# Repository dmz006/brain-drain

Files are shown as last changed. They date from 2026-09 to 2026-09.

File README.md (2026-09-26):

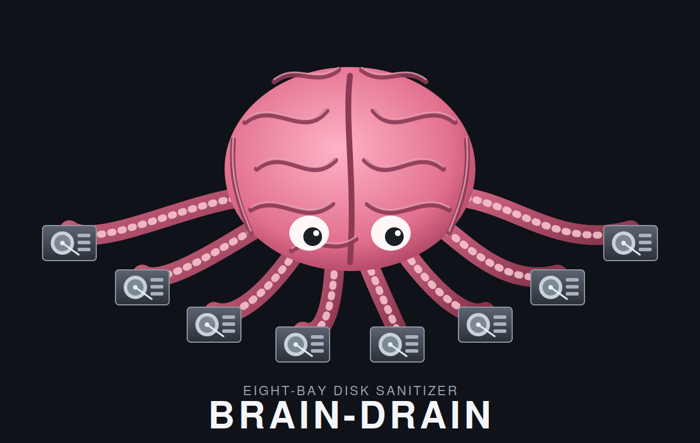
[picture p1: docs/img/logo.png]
brain-drain


# brain-drain

A standalone disk sanitizer: plug a drive in, it gets wiped to NIST SP 800-88 Rev. 2 and you get a certificate. No buttons, no
screen to poke at, no PC. A Raspberry Pi Compute Module 5 on a custom carrier board, plug-in bay cards (one per drive, up to eight, four
in version 1), an M.2 NVMe bay, a Python service and a 3D-printed enclosure that fits a backpack.

> **Status: design complete enough for layout review, nothing fabricated yet.** Both boards are routed with 0 DRC errors in KiCad, the
> software has 74 passing tests and the enclosure exports clean STLs. The boards have not been reviewed by a board designer and nothing has
> been simulated; the first bench test with a real drive is scheduled for 2026-09-26. See [docs/STATUS.md](docs/STATUS.md).
> **Handing this to an engineer? Start with [docs/LAYOUT-REVIEW.md](docs/LAYOUT-REVIEW.md).**

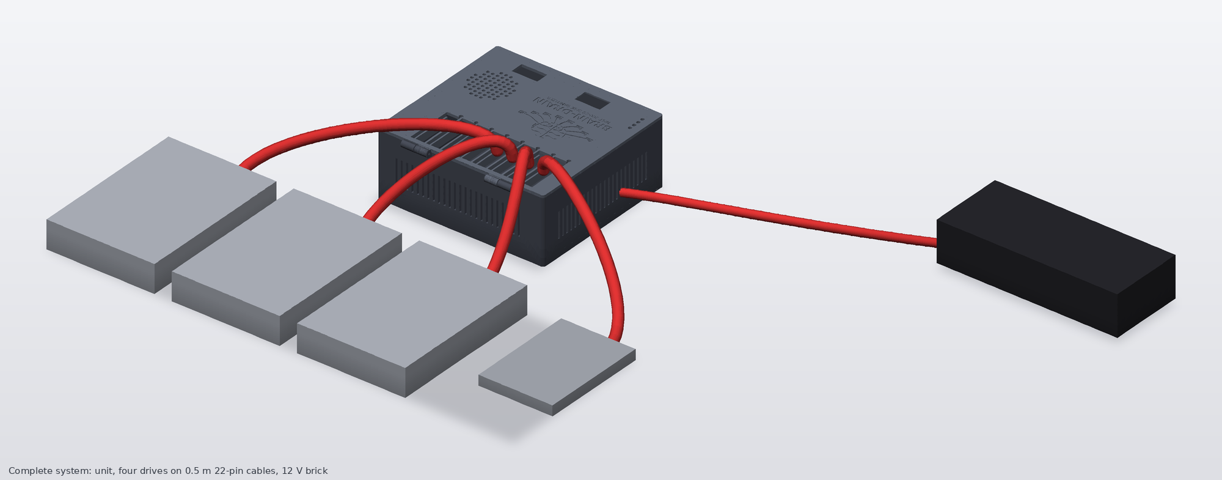
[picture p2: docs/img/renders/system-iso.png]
the complete system: the unit, four drives on 22-pin cables and the 12 V brick

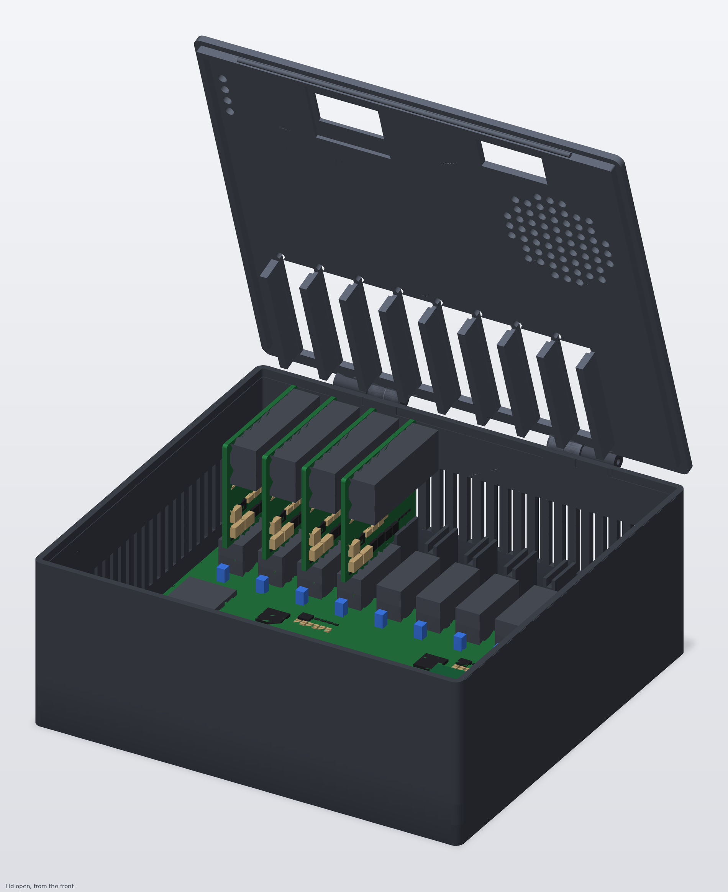
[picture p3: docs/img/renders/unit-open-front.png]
lid open: the brain board with four bay cards standing in their slots
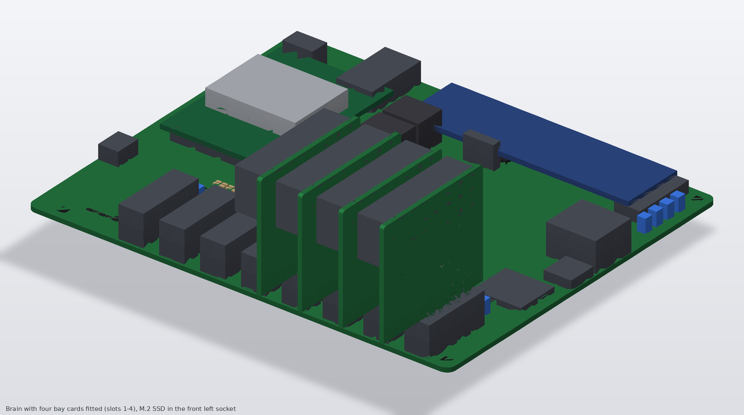
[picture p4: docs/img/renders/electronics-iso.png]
the assembled electronics


## What it does

* Up to eight SATA bays as plug-in cards (four fitted), each a USB 3 bridge
  with its own switched power. Drives are not docked: each bay is a 0.5 m
  22-pin SATA cable (data + power) that rises through the lid and plugs straight
  onto a bare 3.5" or 2.5" drive lying on the bench. Plus an M.2 NVMe bay under
  the lid (bay 9). Each bay is independent.
* Set the policy on an 8-way DIP switch. Plug a drive in: it is identified,
  wiped, verified and reported. Unplug it: the job aborts. That is the whole UI.
* Methods follow NIST 800-88 Rev. 2: single-pass overwrite with full
  verification for magnetic drives, firmware Sanitize (crypto or block erase)
  for SSDs and NVMe, legacy 3-pass and 7-pass available for those who insist.
* A JSON certificate per drive per job: what was attempted, what worked, how it
  was verified, and which tier (Clear / Purge) is honestly claimed.
* A 128×64 OLED shows per-bay progress and ETA. When idle it shows a QR code:
  scan it with a phone to join the unit's Wi-Fi, open the address, and you get
  the status page, the certificates to download, the log, and the option to
  join the unit to your own network. A key on the screen authorises changes.
  DIP mode 110 resets Wi-Fi (or everything, with DIP 8) without a network.

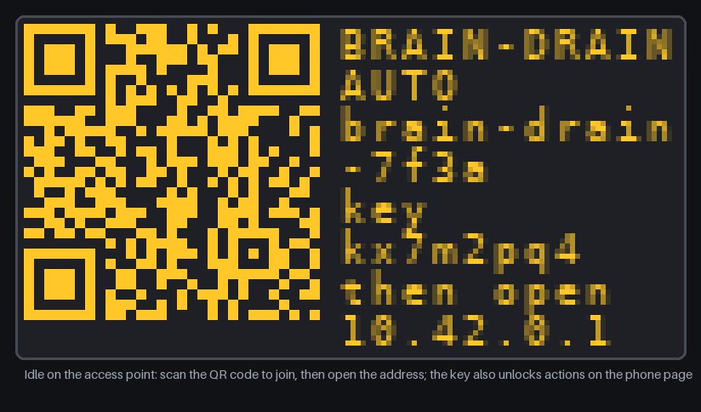
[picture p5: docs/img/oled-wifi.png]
OLED idle: Wi-Fi QR code
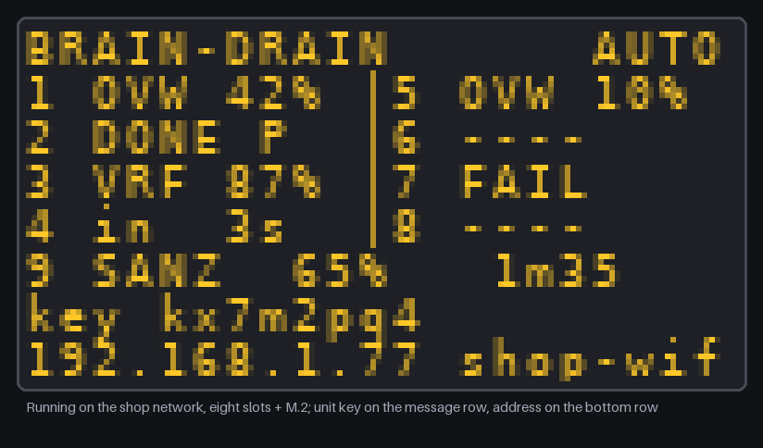
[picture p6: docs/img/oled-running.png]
OLED while running


## Use cases

* IT refresh: wiping a pile of decommissioned laptop and desktop drives
  unattended, four at a time, with paperwork for each.
* Reselling or donating hardware where a Purge-level record is wanted.
* Small MSPs and repair shops that need a repeatable wipe without dedicating a PC.

## The hardware

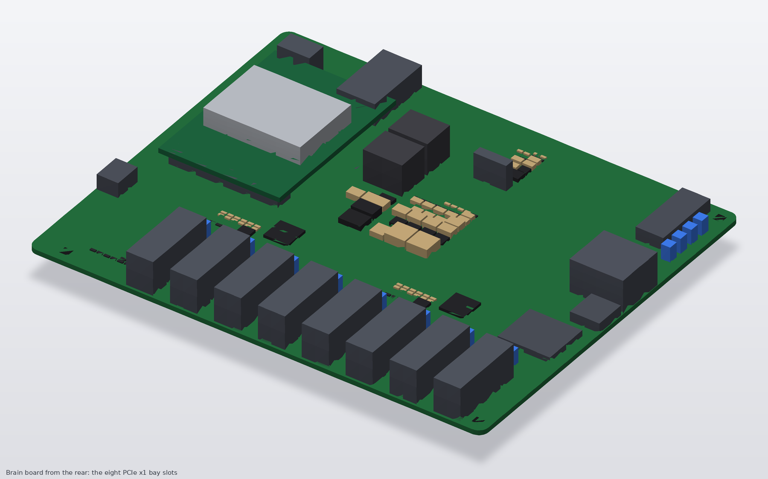
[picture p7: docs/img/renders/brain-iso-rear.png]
brain
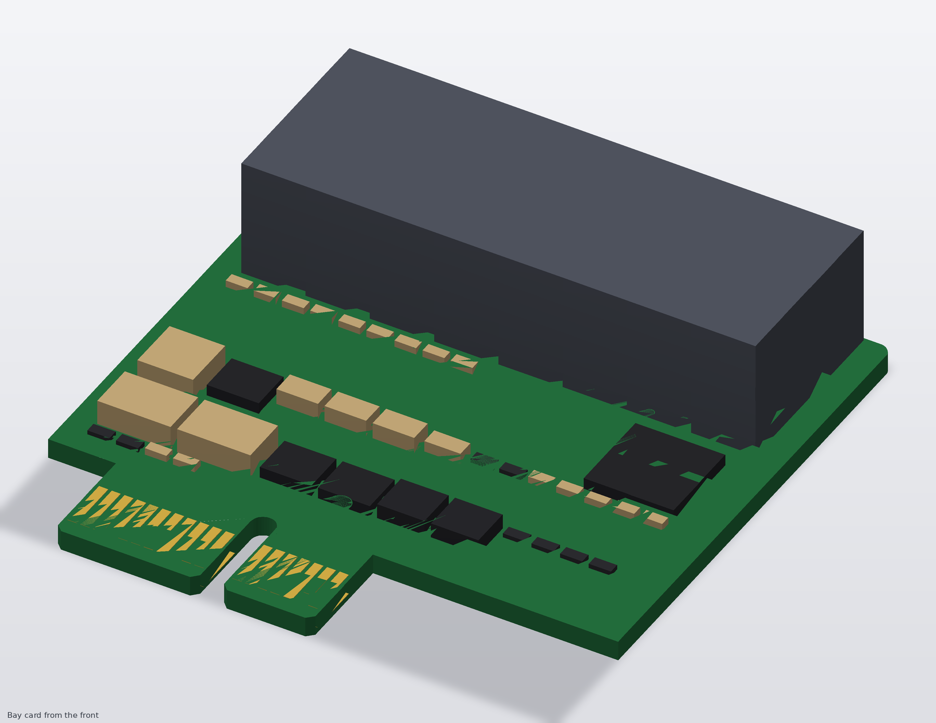
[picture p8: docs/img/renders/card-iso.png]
card
|  |  |
|---|---|
| **Brain board**, 150 x 122 mm, six layers: CM5 wireless, two USB5744 hubs, eight PCIe-x1-style bay slots, M.2 socket, 12 V input and bucks, OLED, DIP switch | **Bay card**, 45 x 46 mm, four layers: ASM1153E USB 3 to SATA bridge, per-bay 12 V / 5 V power switch, SATA receptacle, PCIe x1 fingers |

More views, the case, the assembled unit, an exploded view, a cut-away and the complete system: [docs/RENDERS.md](docs/RENDERS.md).

## Repository layout

| Directory | Workstream | State |
|---|---|---|
| [`hardware/`](hardware/README.md) | KiCad 9 projects for the brain board and the bay card, generated from one netlist source; review pack, per-layer images, BOM | schematic clean; both boards routed, 0 open connections, 0 DRC errors, all differential pairs matched; **unreviewed, unsimulated, not fabricated** |
| [`software/`](software/README.md) | `braindrain` Python service, simulator, bench tool, Wi-Fi access point + phone page, Pi deployment | 74 tests, ready for the first bench |
| [`enclosure/`](enclosure/README.md) | OpenSCAD case, about 157 x 145 x 62 mm: tray, hinged lid with eight cable windows and a snap latch, OLED bezel; render gallery script | STLs export, renders done, not printed |
| [`docs/`](docs/README.md) | architecture, review guide, BOM, decisions, status, usage, diagrams, renders | |

## Quick start

```
# simulate the appliance on any Linux box
cd software && python3 -m venv .venv && . .venv/bin/activate && pip install -e ".[dev]"
braindrain simulate --grace 2            # terminal 1
braindrain sim-plug 1 --size 1G --prefill # terminal 2: a drive appears in bay 1 and is wiped

# regenerate a board from its source and route it unattended (BD_PROJECT=brain or card; see docs/USAGE.md)
cd hardware && python3 tools/symgen.py && BD_PROJECT=card python3 tools/gen_sch.py && BD_PROJECT=card sh tools/route_full.sh

# export the enclosure and render every image
cd enclosure && make && make renders
```

More in [docs/USAGE.md](docs/USAGE.md).

## Documentation

* **For the layout engineer: [Layout and design review guide](docs/LAYOUT-REVIEW.md)** · generated review data in [`hardware/review/`](hardware/review/)
* [Architecture](docs/ARCHITECTURE.md) · [System block diagram](docs/img/system-block.png) · [Renders and drawings](docs/RENDERS.md)
* [Bill of materials](docs/BOM.md) · [Fabrication and assembly vendors, cost estimate](docs/FABRICATION.md) · [Decisions](docs/DECISIONS.md)
* [Status and remaining work](docs/STATUS.md) · [Testing tracker](docs/testing-tracker.md)
* [Usage and regeneration](docs/USAGE.md) · [Bench plan for 2026-09-26](docs/saturday-bench-plan.md)
* [BRAIN-DRAIN-CONTEXT.md](BRAIN-DRAIN-CONTEXT.md) project context · [AGENT.md](AGENT.md) rules for agents and contributors · [CONTRIBUTING](CONTRIBUTING.md) · [CHANGELOG](CHANGELOG.md)

## Safety

This device destroys data by design. The software's safety fence only ever
targets whole disks behind an allow-listed USB bridge on a configured bay port,
or the M.2 slot, and never anything mounted or holding the root filesystem.
Treat every drive that touches a bay as gone.

## Licence

[Polyform Noncommercial 1.0.0](LICENSE): you may use, modify and share this
project for noncommercial purposes. Commercial use needs permission from the
author. Applies to the hardware sources, the software and the enclosure alike.

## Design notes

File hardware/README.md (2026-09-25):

# hardware: the brain board and the bay card

Two KiCad 9 projects, both **generated** from `tools/design.py` (see [../docs/LAYOUT-REVIEW.md](../docs/LAYOUT-REVIEW.md) for how, and for what a
layout engineer must check). Design intent: [../docs/ARCHITECTURE.md](../docs/ARCHITECTURE.md) section 3. Parts: [../docs/BOM.md](../docs/BOM.md).
Regenerate and route commands: [../docs/USAGE.md](../docs/USAGE.md).

| | Brain board | Bay card |
|---|---|---|
| Project | `brain-drain.kicad_pro` | `bay-card/bay-card.kicad_pro` |
| Size, layers | 150 x 122 mm, 6 layers (F sig, In1 GND, In2 sig, In3 sig, In4 power, B sig), 1.6 mm, ENIG | 45 x 46 mm, 4 layers (F sig, In1 GND, In2 power, B sig), 1.6 mm, ENIG, finger tab |
| Contents | CM5 wireless, two USB5744 hubs, eight PCIe x1 bay slots, M.2 socket, 12 V input and bucks, OLED and DIP headers, LEDs, microSD, USB-C | ASM1153E bridge, two P-FET power switches with PTC fuses, SATA 22-pin receptacle, PCIe x1 fingers |
| Schematic sheets | `power-input`, `power-bucks`, `cm5`, `usb3-hub-A`, `usb3-hub-B`, `bay-slots`, `m2-nvme` | `bridge`, `bay-switch`, `edge` |
| Status | routed: 0 open connections, 0 DRC errors, 44 pairs matched | routed: 0 open connections, 0 DRC errors, 8 pairs matched |

brain
card

More views and the assembled unit: [../docs/RENDERS.md](../docs/RENDERS.md). KiCad's own 3D views are in `renders/`, one image per layer in
`renders/layers/` (F.Cu, In1 to In4, B.Cu, assembly-top, assembly-bottom, mask), schematic sheets in `renders/schematic/`.

## Layout of this directory

```
hardware/
  brain-drain.kicad_pro / .kicad_sch / .kicad_pcb   the brain (generated; the PCB also carries the routing)
  sheets/*.kicad_sch                                7 brain sheets (generated)
  bay-card/                                         the bay card project, same layout: .kicad_pro/.sch/.pcb, sheets/, routing/, renders/
  CONNECTIONS.md, bay-card/CONNECTIONS.md           net-by-net connection lists (generated)
  lib/brain-drain.kicad_sym, lib/brain-drain.pretty custom symbols and footprints (see lib/brain-drain.pretty/README.md for origins)
  review/                                           generated review pack: design rules, stack-up, planes, keep-outs, routing statistics,
                                                    DRC / ERC summaries, footprint provenance, netlists, placement CSV, schematic PDFs
  routing/, bay-card/routing/                       Specctra DSN/SES for freerouting, drc.json, open.md, pairs.md, chain.log
  renders/, bay-card/renders/                       KiCad 3D views, per-layer PNGs, schematic PNGs and PDFs
  bom/                                              brain-drain-bom.csv, bay-card-bom.csv (generated)
  ref/                                              pin tables (CSV), DOWNLOADS.md; ref/datasheets/ is gitignored
  tools/                                            the generators and the routing pipeline, listed in ../docs/LAYOUT-REVIEW.md section 6
  fab/                                              fab/<date>/ order packs (gitignored)
```

## Board rules

* Design rules follow the Raspberry Pi CM5IO reference: 0.13 mm tracks, 0.125 mm clearance, 0.45/0.2 mm vias, 0.3 mm copper to the board edge,
  0.2 mm hole clearance; power nets 0.3 mm tracks with 0.6/0.3 mm vias; 0.3/0.15 mm vias for the 0.4 mm-pitch QFN supply pins only (D8, confirm
  with the fab). They are written into each project file by `route.py prepare`; the table is in `review/design-rules.md`.
* Differential pairs: 90 ohm (USB 3, SATA, USB 2), 85 ohm (PCIe). The class `DiffPair90` is 0.147 mm / 0.253 mm gap, **carried over from a four-layer
  design and not yet recalculated for the six-layer stack-up**. Pairs are length-matched end to end (across the series capacitors) to 0.15 mm.
* CM5 antenna strip: no copper on any layer and no parts (rule area `keepout_CM5_antenna`); keep-outs around the CM5's four standoff holes.
* CM5 boot-order straps: eMMC/SD only. All bay power switches default **off** (10 k pull-down on `BAY_EN`, on the card).
* Input: 4-pin DIN (Kycon KPJX-4S-S); the pin assignment must match the chosen brick.

## Before fabrication

See [../docs/LAYOUT-REVIEW.md](../docs/LAYOUT-REVIEW.md) (priority items and the sign-off checklist) and [../docs/STATUS.md](../docs/STATUS.md) R2, R3, R10, R25 to R30:
the stack-up and pair geometry, the M.2 footprint against the TE drawing, the Molex face position, the DIN pinout from the chosen brick, test points, fiducials
and ESD, the card panel.

## Bench validation that does not need these boards

Any Linux box plus an ASM1153E-based USB dock answers the risky questions: does `hdparm --sanitize-*` pass through, does the bridge survive a long SECURITY ERASE,
does `--sanitize-status` report progress. A Pi 5 with two docks is the exact software test bed for this topology. Do this first
([../docs/saturday-bench-plan.md](../docs/saturday-bench-plan.md)).

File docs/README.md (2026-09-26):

# brain-drain documentation

| Document | What it is for |
|---|---|
| [../BRAIN-DRAIN-CONTEXT.md](../BRAIN-DRAIN-CONTEXT.md) | Project context: what it is, the design as built, repository map, generator commands, conventions. |
| [LAYOUT-REVIEW.md](LAYOUT-REVIEW.md) | **For the board layout engineer:** what was delivered, how it was made, what is verified, the risks in priority order, a sign-off checklist. |
| [ARCHITECTURE.md](ARCHITECTURE.md) | The design: hardware, software, enclosure, cross-cutting rules. Source of truth for intent. |
| [STATUS.md](STATUS.md) | What is done, what is placeholder, what is blocked, what comes next. |
| [USAGE.md](USAGE.md) | How to run the simulator, the bench tool, the Pi service, and how to regenerate hardware and enclosure files. |
| [BOM.md](BOM.md) | Generated parts list of both boards with vendor part numbers and prices; CSV copies in `hardware/bom/`. |
| [RENDERS.md](RENDERS.md) | Every render: boards one by one, the assembled electronics, the case, the unit open, exploded, cut-away, the complete system. |
| [FABRICATION.md](FABRICATION.md) | Who can fabricate and fully assemble a small run, what it costs, and the gates before ordering. |
| [DECISIONS.md](DECISIONS.md) | Every decision, open (`D<n>`) or closed (`C<n>`), with reasons. |
| [decisions/](decisions/) | The longer briefs behind the bigger decisions. |
| [testing-tracker.md](testing-tracker.md) | Tested vs validated, per interface and part. |
| [saturday-bench-plan.md](saturday-bench-plan.md) | Step-by-step plan for the first real-drive bench, 2026-09-26. |
| [plans/](plans/) | Multi-session work plans (none yet). |
| [HISTORY.md](HISTORY.md) | Session log: how the repository got here. |
| [img/](img/) | Diagrams and mockups; regenerate with `software/.venv/bin/python docs/tools/diagrams.py` and `software/tools/oled_mockup.py`. |

## Diagrams

| | |
|---|---|
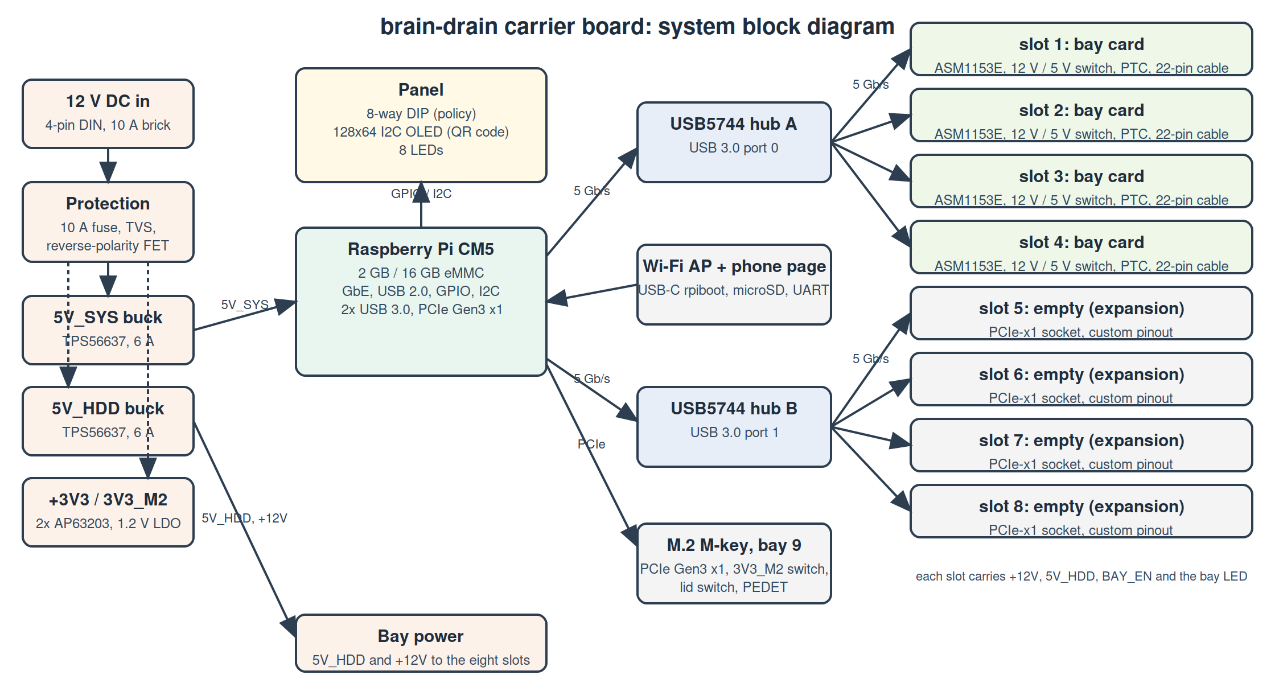
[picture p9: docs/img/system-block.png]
system
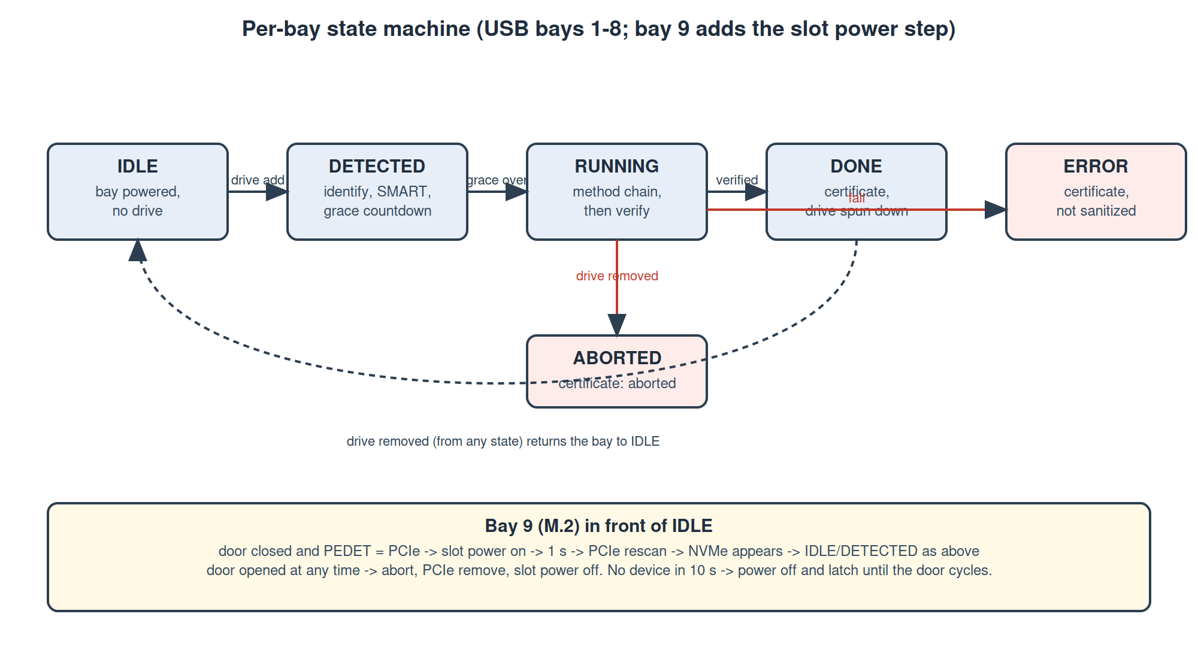
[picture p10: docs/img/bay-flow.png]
bay flow
|  |  |
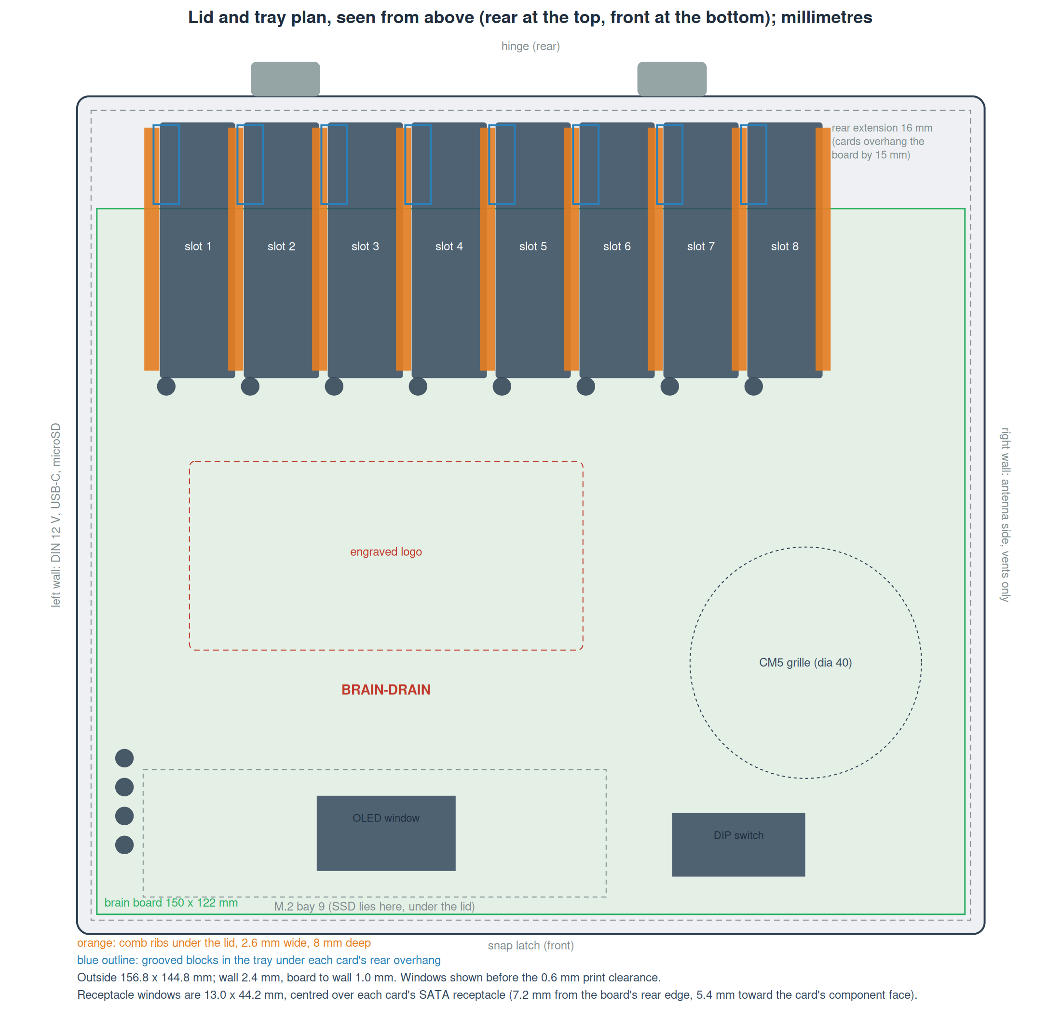
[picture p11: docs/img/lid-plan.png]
lid plan
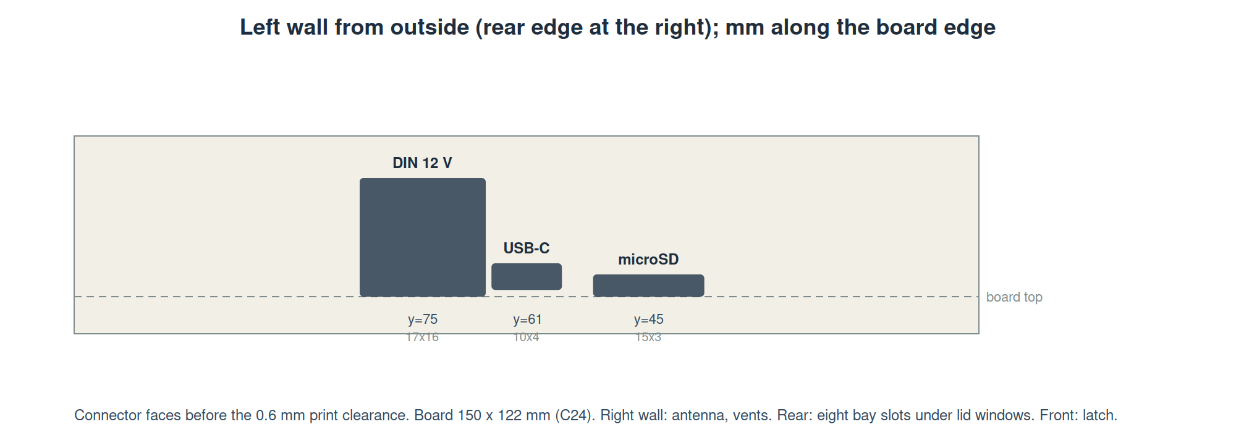
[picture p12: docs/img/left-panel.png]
left panel
|  |  |
| oled wifi | oled |

Renders of the boards, the assembly, the case and the complete system are in [RENDERS.md](RENDERS.md) (files in `img/renders/`); KiCad views and
per-layer images in `../hardware/renders/`; generated review data in `../hardware/review/`.

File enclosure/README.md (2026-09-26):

# enclosure: parametric OpenSCAD "brain box"

The unit is a printed box, about 157 x 145 x 62 mm outside, that goes in a backpack with its 12 V brick and the 22-pin cables; drives lie loose on
the bench while they are wiped (decisions C21 to C27). The 45 x 46 mm bay cards stand 49 mm above the board and overhang its rear edge by 15 mm, so the
tray is 16 mm deeper behind the board than the board itself. The lid is hinged along the rear edge and snaps shut at the front: open it to fit an M.2 SSD or
a card. The printed parts are sized from the real board.

| Lid open, from the front | Complete system |
|---|---|
| lid open | system |

More views (tray, lid, closed unit, exploded, cut-away): [../docs/RENDERS.md](../docs/RENDERS.md). Plan drawing with dimensions: [../docs/img/lid-plan.png](../docs/img/lid-plan.png).

| Face | What is on it |
|---|---|
| rear | vent slots; the lid hinge knuckles |
| left (seen from the front) | DIN 12 V jack, USB-C (rpiboot), microSD |
| right | the CM5 antenna edge: vent slots only, no metal |
| front | the lid latch |
| lid | eight 11.8 x 43 mm windows over the bay cards' SATA receptacles (the drive cables rise through them), OLED window over the SSD, DIP switch slot, 12 LED holes, convection grille over the passive CM5 cooler |
| floor | rubber-feet pockets |

* `board.scad` is **generated** from `hardware/brain-drain.kicad_pcb` by `tools/kicad_to_scad.py`: the board outline, the mounting holes and the centre of every
  connector, switch and LED the shell must cut. **Its x coordinates are mirrored** (measured from the board's right edge): KiCad's top view is left-handed and OpenSCAD is
  right-handed, so a board seen from the front with x to the right sits in the tray with x measured from the tray's x = max wall. The bay windows are placed over the
  cards' receptacles (5.4 mm toward the card's component face, 7.2 mm from the board's rear edge), not over the sockets. Re-run it whenever the board changes.
* `params.scad` holds the printed-part parameters: walls, clearances, heights, `rear_ext` (the 16 mm extension), insert sizes, OLED window position, hinge and latch sizes.
* Bay-card retention and artwork (C30): `comb()` and `card_supports()` in `shell.scad` (parameters `comb_*`, `support_*` in `params.scad`), `logo.scad` (generated by `tools/gen_logo.py` from `docs/img/logo.svg`), `tools/check_fit.py` (clearances against the placed cards).
* `refinements.scad`: OLED bezel, feet pockets. `scene.scad`: the closed unit, four loose drives and cables (the renderers compose the rest in Python).
* `shell.scad`: the tray (board on M2.5 heat-set standoffs, cutouts on the left and right walls, vents, hinge knuckles, latch groove) and the lid (front and side skirt,
  hinge knuckles, latch bump, the windows and holes).
* `tools/gallery.py` renders every image; `tools/render3d.py` is the headless renderer (numpy + Pillow); `hardware/tools/board_model.py` builds the 3D proxy of the boards.

```
make            # board.scad + stl/tray.stl, lid.stl, bezel.stl  (needs openscad)
make renders    # scene STLs, then docs/img/renders/*.png via tools/gallery.py (needs pcbnew, numpy, Pillow; no display)
```

Print PETG or ASA, 0.2 mm layers. The tray prints as modelled; the lid prints
upside down. The hinge pin is a 140 mm length of 1.75 mm filament.

Known simplifications: cutouts are rectangles sized from nominal connector
faces, so check the DIN jack round face and the SATA plug latch clearance on the
first print; the hinge knuckles and the latch bump are first guesses at fit
(0.3 mm pin clearance, 1.6 mm bump); the OLED lead from J41 to the window is
about 40 mm.

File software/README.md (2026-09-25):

# software — `braindrain` sanitizer service

Python 3.11+. Design in `../docs/ARCHITECTURE.md` §4. Status: engine, policy,
safety fence, host overwrite, verification, certificates, the bay 9 M.2 slot
controller and the simulated HAL are implemented and tested. The ATA/NVMe firmware wrappers, real GPIO and OLED
drivers are written but **untested on hardware**.

## Develop on a workstation (simulation)

```
cd software
python3 -m venv .venv && . .venv/bin/activate
pip install -e ".[dev]"
pytest

# terminal 1: the appliance, with a 2 s grace period and the OLED drawn in the terminal
braindrain simulate --grace 2

# terminal 2: plug drives in and out
braindrain sim-plug 1 --size 512M --media hdd --prefill          # host overwrite + full verify
braindrain sim-plug 3 --size 256M --media ssd --fw crypto,block  # simulated firmware sanitize + canaries
braindrain sim-plug 2 --size 2G --throttle 50M                   # slow enough to watch % and ETA
braindrain sim-unplug 2                                          # aborts bay 2
braindrain sim-plug 9 --size 256M --media nvme --fw crypto,block # NVMe in the M.2 slot (bay 9)
braindrain sim-door closed                                       # shut the M.2 door (bay 9): slot powers, rescans, wipe starts
braindrain sim-door open                                         # aborts bay 9 and cuts slot power
braindrain sim-pedet sata                                        # pretend a SATA M.2 module: refused
echo 01100000 > ~/.brain-drain-sim/dip                           # switch to legacy 3-pass (DIP 1-3 = 011)
braindrain dip 01100000                                          # decode a DIP setting
```

Certificates land in `~/.brain-drain-sim/reports/`. The last OLED frame is in
`~/.brain-drain-sim/display.txt`.

Simulated drives are sparse files under `~/.brain-drain-sim/bay<N>/`. The
engine never touches anything else: on a workstation it cannot see real disks
in simulation mode at all.

## Layout

```
braindrain/
  config.py          bay <-> USB port map, bridge allow-list, GPIO numbers, timings
  policy.py          DIP decoding, NIST tier, method chain per media type
  devices.py         Drive model, safety fence (classify), pyudev enumeration, identity
  blockio.py         O_DIRECT + aligned buffers, size/sector ioctls
  verify.py          full / sampled read-back, canaries for firmware wipes
  progress.py        EWMA rate, ETA, formatters
  report.py          certificate JSON, crash state
  engine.py          per-bay state machine and workers
  display.py         21x8 OLED frame renderer (pure)
  methods/           overwrite, ata (hdparm), nvme (nvme-cli), simfw, dryrun
  hal/               sim, gpio (libgpiod v2), oled (luma.oled)
  sim/               simulated bays + udev watcher for real hardware
  cli.py
tests/
```

## Real hardware or a bench dock

Needs `hdparm >= 9.65`, `nvme-cli`, `sg3-utils`, `smartmontools`, `util-linux`,
plus `pip install -e ".[hw]"` on the appliance (`gpiod`, `luma.oled`).

`sudo braindrain list` enumerates every disk and prints the fence verdict for
each, including the USB port path. To use a bench dock, put its port path into
`Config.bay_ports` and its bridge VID:PID into `Config.allowed_bridges`; nothing
outside those is ever a candidate. `sudo braindrain run` starts the service.

## Bench questions still open (need a dock + sacrificial drives)

* Does `hdparm --sanitize-*` pass through the dock's bridge, and does
  `--sanitize-status` report progress in the format `parse_sanitize_status` expects?
* Does the bridge survive a full `SECURITY ERASE UNIT` without resetting?
* What does the bridge do to a hot-plugged SATA drive: clean add event, or reset?

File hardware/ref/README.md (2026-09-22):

# Reference data

* `cm5-pinout.csv` — all 200 CM5 connector pins, extracted from Table 4 of the
  official Raspberry Pi Compute Module 5 datasheet
  (https://datasheets.raspberrypi.com/cm5/cm5-datasheet.pdf, September 2026 copy).
  The schematic symbol for the CM5 is generated from this file; do not hand-edit.
* `usb5744-pinout.csv` — Microchip USB5744 56-VQFN pin assignments, Table 3-1 of
  DS00001855M (public).
* `asm1153e-pinout.csv` — ASMedia ASM1153E QFN-48 pin list, section 6 of the
  Rev 0.4 datasheet. The PDF itself is vendor-confidential and is kept only in
  the gitignored `datasheets/` folder.
* `datasheets/` (gitignored) — local copies of the CM5, CM5IO, USB5744 and
  ASM1153E datasheets used for this design.
* `m2-mkey-pinout.csv` — M.2 Socket 3 / M-key host pin assignment (PCIe x4
  positions; only lane 0 is used). Signal names are from the host's point of
  view: PETp/n = host transmit, PERp/n = host receive. Pins 59–66 are the key
  notch. Source: pinoutguide.com M.2 table, cross-checked against the PCI-SIG
  M.2 naming; verify against the socket vendor's drawing before layout.

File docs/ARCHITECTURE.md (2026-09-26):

# brain-drain: architecture

Standalone, headless disk sanitizer built on a Raspberry Pi Compute Module 5. A brain board carries the compute, two USB 3
hubs, eight bay slots, an M.2 socket and the user interface; a small bay card plugs into a slot for each SATA drive (four cards
in version 1, up to eight). Set the wipe policy on a DIP switch, plug a drive into a bay and it is wiped as soon as it is
ready; the OLED shows per-bay progress; unplugging a drive aborts it; each finished drive gets a sanitization certificate.
A Wi-Fi access point with a QR code on the OLED gives a phone the status page, the certificates and the network setup.
No buttons, no menus. Wipe methods follow NIST SP 800-88 Rev. 2.

Status: **design complete enough for layout review, nothing fabricated.** Both boards are routed with 0 DRC errors in KiCad
(see [STATUS.md](STATUS.md) and [LAYOUT-REVIEW.md](LAYOUT-REVIEW.md) for the caveats). This document is the source of truth
for intent; change it before changing the hardware. The hardware sources are generated (`hardware/tools/`), never hand-edited.

system

---

## 1. Scope

| In scope | Out of scope (for v1) |
|---|---|
| Up to eight SATA HDD/SSD bays (3.5" and 2.5") on plug-in bay cards, four cards fitted | Physical destruction, degaussing |
| One M.2 NVMe bay (bay 9), PCIe Gen3 x1, under the lid | Wiping the CM5's own boot medium (explicitly forbidden) |
| NIST 800-88 Rev. 2 Clear and Purge for ATA and NVMe media | Signed / PKI certificates |
| Overwrite (host-side) and firmware Sanitize / Security Erase | Ethernet, buzzer, fan (header only), touchscreen |
| Per-drive progress and ETA on a 128 x 64 OLED | Hot-swap backplane, drive caddies, a rack |
| Wi-Fi access point, QR code, phone page with certificates and network setup | Cloud services |
| JSON certificate per drive, optional push | Drive power beyond 120 W with four cards (see 3.5) |
| Staggered spin-up, per-bay power control | |

## 2. System overview

```
   12 V brick ──DIN──► fuse, TVS, reverse-polarity FET ──┬─► U20 buck 5V_SYS ──► CM5, hubs, OLED, DIP
                                                           ├─► U21 buck 5V_HDD ──► slots (5 V per bay)
                                                           ├─► U22 buck 3V3    ──► hubs, IO, U3 (1.2 V LDO for the hubs)
                                                           ├─► U51 buck 3V3_M2 ─► U50 switch ─► M.2 socket
                                                           └─► +12V ────────────► slots (12 V per bay)

   Raspberry Pi CM5 (wireless, 2 GB / 16 GB eMMC)
      ├── USB 3.0 port 0 ──► U1 USB5744 hub A ── 4 downstream ports ──► slots 1-4 ┐
      ├── USB 3.0 port 1 ──► U2 USB5744 hub B ── 4 downstream ports ──► slots 5-8 ┤  per slot (PCIe x1-style socket,
      ├── PCIe Gen3 x1 ───► J50 M.2 M-key socket (bay 9, SSD lies under the lid)   │   custom pinout): USB 3 + USB 2 pairs,
      ├── GPIO BAY_EN 1-8 ─► slot pin B5 ─► bay-card power switch                  │   12 V, 5 V, GND, BAY_EN, LED_K
      ├── GPIO DIP x8, status LED, M2_DOOR, M2_PWR_EN                              ┘
      ├── I2C1 ──► OLED (SSD1306 / SH1106), Wi-Fi AP + phone page (nmcli, QR on the OLED)
      └── USB 2.0 ──► USB-C (rpiboot, spare host), microSD (CM5 Lite boot)

   Bay card (one per drive):  slot fingers ─► ASM1153E USB 3 to SATA bridge ─► SATA 22-pin receptacle ─► 0.5 m cable ─► drive
                              slot 12 V / 5 V ─► two P-FET switches + PTC fuses, enabled by BAY_EN ─► receptacle power pins
```

The brain board (six layers, 150 x 122 mm) and the bay cards (four layers, 45 x 46 mm) sit in a printed box about
157 x 145 x 62 mm. The box, its 12 V brick and the 22-pin cables travel in a backpack; the drives lie loose on the bench and
connect with off-the-shelf 0.5 m SATA extension cables that rise through windows in the lid. There is no rack, dock or chassis.

electronics

## 3. Workstream 1: the boards (KiCad)

### 3.1 Compute: Raspberry Pi Compute Module 5

* **Variant:** CM5 with wireless, 2 GB RAM, 16 GB eMMC (SKU CM5102016; the schematic's value field still reads CM5002016 and is
  corrected at the next regeneration, confirm the SKU when ordering). The service needs well under 1 GB.
* **Lite works on the same board.** A microSD socket is wired to the CM5's SD pins; Lite variants boot from it, eMMC variants
  ignore it. The boot order is pinned to eMMC / SD only, never USB or NVMe, so a drive in a bay can never become the boot medium.
* **Connectors:** 2 x Hirose DF40C-100DS-0.4V(51), 0.4 mm pitch, on the brain's right edge. The wireless module's PCB antenna is
  on the short edge that carries mounting hole MH1; that edge sits on the board's right edge with an 8 mm copper-free strip on
  every layer and no metal within 10 mm (CM5 datasheet 4.1.2). The rule area `keepout_CM5_antenna` enforces it.
* **Interfaces used:** two native USB 3.0 ports (from RP1) for the hubs, USB 2.0 to the USB-C port, PCIe Gen3 x1 to the M.2 socket,
  I2C1, UART0 (debug header), 20 GPIO, SD, the on-module RTC (CR2032 holder on the battery pin). Ethernet and HDMI are not used.
* **Thermal:** a passive CM5 cooler under a convection grille in the lid; a 4-pin fan header is kept for a summer bench (C23).
* **nRPIBOOT** jumper (J6) and a UART header (J7) sit on the bottom side under the CM5.

### 3.2 USB topology (decision D1, closed; C11, C24)

One Microchip **USB5744** hub per native USB 3.0 port. Each hub has four downstream ports and all four are used:
hub A (U1) feeds slots 1-4, hub B (U2) slots 5-8. Each USB5744 has its own 25 MHz crystal and needs 3.3 V plus an external 1.2 V
core rail (one AP2112K-1.2 LDO, U3, serves both). Port power enables and overcurrent pins are unused: bay power is switched on the
drive rails, on the card. Configuration is by strap pins, no SPI ROM.

| Link | Practical rate | Shared by |
|---|---|---|
| CM5 USB 3.0 port to hub | about 400 MB/s | up to four bays |
| Hub port to bridge (ASM1153E on the card) | about 400 MB/s | one bay |
| ASM1153E to drive (SATA III) | about 550 MB/s | one bay |
| A 3.5" HDD | 100-200 MB/s, about 150 average | |

Four drives on **one** hub share about 400 MB/s, roughly 100 MB/s each, below a modern HDD's speed. **Populate slots 1, 2, 5 and 6**
instead of 1-4 to give each pair of drives its own 5 Gb/s link; the software identifies a bay by its USB port path (`config.py`),
so nothing else changes. With eight bays busy every drive sees about 100 MB/s.

### 3.3 The bay card (C24, C27)

One 45 x 46 mm four-layer board per bay, one design for every slot:

* **ASM1153E** (ASMedia, QFN-48) USB 3.0 to SATA 6G bridge with SAT passthrough, which makes SANITIZE / SECURITY ERASE possible over USB.
  30 MHz crystal (default strap, no strap resistors), 4.7 uH core inductor, SATA AC-coupling caps. ASM1153E runs from 5 V alone.
* **Power switch:** two AON7403 P-MOSFETs (12 V and 5 V, -30 V, DFN 3x3) driven through 2N7002s from `BAY_EN`, with a gate RC for
  about 1 ms of soft start and 100 k pull-ups that keep the bay off; a 10 k pull-down on `BAY_EN` keeps an empty or half-inserted
  slot off. PTC fuses: 3 A hold on 12 V, 2 A hold on 5 V.
* **Receptacle:** Molex 47018-4001, SATA 22-pin (7 data + 15 power) host receptacle, top-mount PCB-edge type, centred on the
  card's top edge; the cable leaves upward. It is 40.46 mm wide, which sets the card width. P3 (PWDIS) and P11 (staggered spin-up)
  are not connected.
* **Fingers:** KiCad's stock `BUS_PCIexpress_x1` pattern with its own tab outline and key notch, ENIG. The contacts are not PCIe:
  the pinout below is our own.
* **Bay LED** stays on the brain (in front of the slot); the bridge's LED pin sinks it through finger B6 (`LED_K`).

| Finger | Signal | Finger | Signal |
|---|---|---|---|
| A1, A2 | +12V | B1, B2, B3 | +12V |
| A3, A4, A7, A10-A13, A16-A18 | GND | B4, B7, B11, B14, B17, B18 | GND |
| A5, A6 | not connected | B5 | BAY_EN (in, from the brain) |
| A8, A9 | 5V (5V_HDD) | B6 | LED_K (bridge LED output, sunk on the brain) |
| A14, A15 | USB3_TX_N, USB3_TX_P (hub to bridge) | B8, B9, B10 | 5V (5V_HDD) |
| | | B12, B13 | USB2_DM, USB2_DP |
| | | B15, B16 | USB3_RX_N, USB3_RX_P (bridge to hub) |

The pinout lives in `hardware/tools/symgen.py` (`SLOT_PINS`) and feeds both the card and the slot symbols. The connector is rated
1.1 A per contact (TE/Amphenol PCI Express specification); five contacts per rail carry 5.5 A per bay.

### 3.4 Slots, drive cables and the M.2 bay

* **Slots:** eight Amphenol FCI 10018783-10100TLF PCI Express x1 vertical through-hole sockets (36 contacts, 1.0 mm pitch, board
  locks/pegs) at 14.5 mm pitch along the brain's rear edge. The footprint follows the Amphenol customer drawing 10018784: four rows
  of 0.70 mm holes at 2.0 mm pitch, pegs at 11.65 and 20.80 mm. The cards stand vertically, plane front to back, with the receptacle
  facing the next slot; the 45 mm card overhangs the board's rear edge by 15 mm (C27), which keeps the bay LEDs in front of the slots visible.
* **Drive cables:** off-the-shelf 22-pin male-to-female SATA extensions, 0.5 m; the drive end plugs straight onto a bare drive.
  The cable rises through a window in the lid over each receptacle.
* **M.2 (bay 9, C15):** TE 2199230-4 M-key socket at the front left, PCIe Gen3 x1 from the CM5 (REFCLK pair, PERST#, CLKREQ#),
  3V3_M2 from a dedicated AP63203 buck (U51) through a TPS22965 load switch (U50) enabled by GPIO. The module lies under the lid
  along the front; the lid hinge with a microswitch (SW3) is the "door": closing it powers the slot and rescans the PCIe bus.
  M.2 SATA (B+M key) modules are refused. USB-NVMe bridges present as SCSI and fall back to SCSI SANITIZE or overwrite.

### 3.5 Power tree and budget

Input: **12 V DC**, one rail; everything else is derived on the brain. Input connector J21: Kycon KPJX-4S-S 4-pin DIN, 7.5 A per
pin with two pins per polarity (barrel jacks were dropped at 5 A). The brick is chosen before layout is frozen because DIN pin
assignments differ between vendors (STATUS R3).

| Rail | Source | Loads | Notes |
|---|---|---|---|
| +12V | input after F1 (15 A slow, C31), D20 (SMBJ15A), Q20 (AO4407A reverse-polarity FET), 2 x 680 uF bulk | the slots' 12 V pins | per-bay switch on the card |
| 5V_SYS | U20 TPS56637 (6 A) | CM5 (up to 3 A), 2 hubs, OLED, DIP, U22 | keeps drive spin-up ripple off the CM5 rail |
| 5V_HDD | U21 TPS56637 (6 A) | the slots' 5 V pins | per-bay switch on the card |
| 3V3 | U22 AP63203 (2 A) | hubs, IO, U3 | |
| 1V2 | U3 AP2112K-1.2 | both hubs' core | |
| 3V3_M2 | U51 AP63203, switched by U50 | M.2 socket | slot power is off while idle |

Budget, four drives: 12 V about 3.2 A typical, 4.4 A staggered peak; 5 V drives about 2.4 A typical, 2.8 A peak; the 12 V input
is about 5.3 A typical and 7.4 A staggered peak (11.5 A if all four spun up together, which the software never does). The 120 W brick,
the DIN rating covers four bays (the input fuse is 15 A since C31, sized for eight). **Eight simultaneous drives need about 9.5 A typical and 11.7 A at a staggered peak:
a 150-180 W brick, two parallel DIN pins for 12 V and heavier bulk capacitors, and 5V_HDD at 6 A is at its limit
for eight drives.** Do not fit eight cards before those are revisited (STATUS R23).

Staggered spin-up is mandatory: the software never enables two bays within 4 s of each other.

### 3.6 Per-bay power switching

On each card, `BAY_EN` (from a CM5 GPIO, active high) turns on both P-FETs through the 2N7002 gate drivers. The gate RC gives about 1 ms
of ramp so a drive's bulk capacitors do not trip the upstream fuse; the pull-down keeps everything off during boot. Per-bay
resettable fuses catch a shorted drive. Power control also lets the software un-freeze a drive (cycle its bay) or reset a hung
bridge without disturbing the others.

### 3.7 GPIO map (BCM numbering)

| GPIO | Function | Direction | Notes |
|---|---|---|---|
| 2, 3 | I2C1 SDA / SCL | | OLED (0x3C) |
| 4 | M2_DOOR | in, pull-up | lid microswitch, closed = low |
| 5, 6, 12, 13 | BAY_EN 1-4 | out | active high, 10 k pull-down on each card |
| 7, 8, 9, 10 | BAY_EN 5-8 | out | same |
| 14, 15 | UART0 TX / RX | | debug header J7 |
| 16, 17, 20, 21, 22, 23, 24, 25 | DIP 1-8 | in, pull-up | ON = low |
| 26 | STATUS_LED | out | red status LED |
| 27 | M2_PWR_EN | out | 3V3_M2 load switch enable, 10 k pull-down |
| 18 | free | | buzzer removed (C23) |
| 0, 1 | reserved | | ID EEPROM per Pi convention, not populated |

Bay activity LEDs are driven by each bridge's LED pin through the slot, not by GPIO.

### 3.8 User interface

* **OLED:** 128 x 64 I2C (SSD1306 0.96" or SH1106 1.3") on a 4-pin header (J41), in a recess in the lid. Idle it shows the Wi-Fi QR
  code, the key and the address; running, one row per bay in two columns when more than five bays are configured.
* **DIP switch:** 8-way, through-hole, reachable through a lid slot. Semantics in 4.5. The only control on the unit.
* **LEDs:** power (green), activity (green), status (red), eight bay LEDs (blue), M.2 (blue), all 3 mm through-hole standing in 3.2 mm lid holes.

### 3.9 Other on-board

* **RTC:** the CM5's on-module RTC with a CR2032 holder (BT1) on the CM5 battery pin, so certificates carry trustworthy times off-network.
* **Fan header** (J40): 4-pin 5 V PWM, optional.
* **microSD** (J3), **USB-C** (J5, USB 2.0 only: rpiboot and a spare host port).
* **Test points:** none placed yet; the layout engineer should add them on the rails and each `BAY_EN` (see LAYOUT-REVIEW.md).

### 3.10 PCBs

Both boards come from `hardware/tools/` (netlist in `design.py`, placement in `gen_pcb.py`, routing pipeline in `route.py`), one
KiCad project each: `hardware/brain-drain.*` and `hardware/bay-card/bay-card.*`.

* **Brain, 150 x 122 mm, six layers:** F.Cu signal, In1 GND plane, In2 and In3 signal, In4 power islands (5V_SYS, 5V_HDD, +12V, +3V3),
  B.Cu signal with a GND pour; 1.6 mm, ENIG. Eight slots along the rear edge with their bay LEDs in front; the two hubs behind their
  slots; the CM5 in landscape on the right edge with its antenna out; DIN, USB-C and microSD on the left wall; bucks and input block in
  the middle; the M.2 socket front left; DIP and fan header front right; CR2032 holder and service headers on the bottom under the CM5.
  Each hub's ten bypass capacitors sit on the **bottom** side around the chip so the top layer keeps its space for pin escapes;
  the coupling caps of each differential pair are placed side by side.
* **Bay card, 45 x 46 mm, four layers:** F.Cu / GND / power / B.Cu, 1.6 mm, ENIG, receptacle on the top edge, bridge below it, the
  switch block above the finger tab.
* **Rules:** the Raspberry Pi CM5IO reference's 0.13 mm tracks, 0.125 mm clearance, 0.45/0.2 mm vias, because nothing coarser escapes
  the 0.4 mm-pitch CM5 connector; 0.3/0.15 mm vias only for the 0.4 mm QFN supply pins (D8, confirm with the fab); power nets 0.3 mm tracks
  with 0.6/0.3 vias. 90 ohm differential pairs (0.147 mm track, 0.253 mm gap, set for the four-layer stack-up) for USB 3, SATA and USB 2;
  85 ohm for the PCIe pair to the M.2. **The pair geometry must be recalculated for the fab's six-layer stack-up before ordering.**
  Pairs are length-matched end to end (across the series capacitors) to 0.15 mm.
* **Fab:** JLCPCB or PCBWay with assembly; see [FABRICATION.md](FABRICATION.md). USB5744, ASM1153E and the DF40 connectors need the
  assembler's SMT line.

brain
card

## 4. Workstream 2 — Sanitizer service (Python)

### 4.1 Stack

* Raspberry Pi OS Lite 64-bit (Bookworm or newer), Python 3.11+.
* Package `braindrain`, run by a `systemd` unit as root (raw block access).
* Python deps: `pyudev` (device events and sysfs), `gpiod` (libgpiod v2),
  `luma.oled` (SSD1306/SH1106), `smbus2`.
* System tools driven via subprocess: `hdparm` ≥ 9.65 (ATA SANITIZE/SECURITY),
  `nvme-cli`, `sg3-utils` (`sg_sanitize`, `sg_inq`, `sg_readcap`),
  `smartmontools` (`smartctl` for identity, SMART pre-check, and post-check),
  `util-linux` (`lsblk -J`, `blockdev`).

### 4.2 Package layout

```
software/braindrain/
  __init__.py
  config.py        # paths, timings, DIP semantics table
  hal/
    gpio.py        # BAY_EN, DIP, LEDs (real + simulated)
  wifi.py          # access point / station via nmcli, ephemeral key, resets
  webui.py         # the phone page (stdlib HTTP)
  qr.py            # Wi-Fi QR matrix for the OLED
    display.py     # OLED rendering (real + terminal simulator)
    bays.py        # bay ↔ USB port-path table, power sequencing
  devices.py       # enumerate candidate drives, identity, safety filter
  policy.py        # DIP bits + media type → ordered list of methods to try
  methods/
    base.py        # Method interface: supported(), run(), progress()
    overwrite.py   # host-side passes (zeros / pattern / seeded random) + verify
    ata.py         # hdparm: SANITIZE {crypto,block,overwrite}, SECURITY ERASE
    nvme.py        # nvme-cli: sanitize, format --ses
    scsi.py        # sg_sanitize for USB-NVMe / SAS oddities
  verify.py        # full read-back, sampled read-back, canary check
  report.py        # certificate JSON, write to /var/lib/brain-drain and USB stick
  progress.py      # per-bay % and ETA (EWMA throughput)
  engine.py        # state machine: IDLE → ARMED → RUNNING → DONE/ERROR
  cli.py           # `braindrain run|status|list|simulate`
software/tests/
```

### 4.3 Device enumeration and the safety fence

The single most important property of this software: **it must never touch the
boot medium or any drive that is not in a bay.** Defence in depth:

1. A drive is a candidate only if its sysfs path passes through the USB port path
   assigned to a bay in `config.py` (e.g. `usb2/2-1/2-1.3` → bay 7) **and** the
   USB bridge VID:PID is on the allow-list (ASM1153E `174c:55aa` / `174c:1153`).
2. The device's `major:minor` must not be, or be a parent of, anything mounted or
   holding the root/boot filesystem (checked via `findmnt` and `/proc/swaps`).
3. Removable-media and zero-capacity devices are ignored.
4. Every method opens the target with `O_EXCL`.
5. A dry-run DIP setting (§4.5) exercises the whole pipeline without writes.

Bays are powered at boot, staggered 4 s apart, and stay powered. A drive plugged
into a live pigtail is detected by the bridge (SATA connectors are hot-plug by
design), a block device with capacity > 0 appears behind the bay's port path,
and udev delivers an add event. Removal delivers a remove event, which aborts
any running job in that bay. There is no confirmation step beyond a short
grace countdown (default 5 s, shown on the OLED) during which pulling the drive
back out cancels cleanly.

### 4.4 Wipe methods and NIST SP 800-88 Rev. 2 mapping

Rev. 2 keeps the Clear / Purge / Destroy tiers, drops the idea that multi-pass
overwrites add anything on modern media, and pushes toward drive-native sanitize
commands (Sanitize, Crypto Erase) for Purge. Verification, full or sampled, is
part of every Clear/Purge. The table below is the intended mapping; it must be
checked line by line against the published Rev. 2 text before the first release.

| Media | Clear | Purge |
|---|---|---|
| Magnetic HDD (ATA) | 1 pass host overwrite, fixed pattern, **full verify** | ATA `SANITIZE OVERWRITE EXT` → fallback `SECURITY ERASE UNIT` (enhanced) → fallback host overwrite |
| SATA SSD (ATA) | 1 pass host overwrite (may miss over-provisioned blocks; flagged in report) | ATA `SANITIZE CRYPTO SCRAMBLE` (if supported) then `SANITIZE BLOCK ERASE` → fallback `SECURITY ERASE UNIT` enhanced |
| NVMe (native only) | `nvme format --ses=1` | `nvme sanitize --sanact=crypto-erase` or `block-erase` |
| Unknown / USB-NVMe / SAS | host overwrite | SCSI `SANITIZE` via `sg_sanitize` → fallback overwrite |

Method implementations:

* **Overwrite:** `O_DIRECT`, 8 MiB blocks, aligned to physical sector size; pattern
  zeros by default, seeded ChaCha20 keystream for "random" so verification can
  regenerate the stream instead of storing it. Throughput and ETA from an EWMA of
  the last 30 s. Bad sectors are logged and the pass continues; any unwritable LBA
  fails the certificate.
* **Firmware (ATA):** `hdparm --sanitize-*` then poll `--sanitize-status` for
  percentage. Frozen state → power-cycle the bay via `BAY_EN` and retry once.
  Known risk: a USB bridge may drop the device mid-Security-Erase because the
  drive stays busy longer than the SCSI timeout; the drive keeps erasing, so the
  service waits, re-enumerates, and checks security status rather than failing.
  Sanitize is preferred over Security Erase precisely because it is asynchronous
  with a status query.
* **Verify:** full read-back compare for host overwrite (default) or sampled
  (first/last 1 GiB plus 64 random 16 MiB windows) when DIP 5 is on. For firmware
  methods the "canary" check applies: before the command, write a known marker at
  eight LBAs; after, read them back and confirm the marker is gone (crypto erase
  yields noise, block erase yields zeros/FFs; both pass).
* **Legacy multi-pass:** 3-pass (0x00, 0xFF, random + verify) and 7-pass
  (DoD 5220.22-M ECE-style) kept for customers who insist. The certificate labels
  these as *exceeding* Clear, not as Purge.

### 4.5 DIP switch semantics

| DIP | ON | OFF (default) |
|---|---|---|
| 1–3 | mode index, see below | 000 = `auto` |
| 4 | overwrite pattern = seeded random | zeros |
| 5 | sampled verify | full verify |
| 6 | reserved | |
| 7 | reserved | |
| 8 | **maintenance**: SSH + serial shell, never wipe | normal |

Mode index (DIP 1–3, ON = 1): `000 auto` (HDD → Clear+verify, SSD → Purge),
`001 purge`, `010 clear`, `011 legacy-3pass`, `100 legacy-7pass`,
`101 crypto-erase-only`, `110 service (never wipes; Wi-Fi reset at boot, factory reset with DIP 8)`, `111 dry-run`.

DIP is read at boot and again each time a drive is detected, and the decoded
mode is shown on the OLED footer.

### 4.6 State machine and UX

Per bay, independently:

```
IDLE ─(drive add)─► DETECTED (identity, SMART pre-check, grace countdown)
     ─► RUNNING (one worker thread: method chain, then verify)
     ─► DONE | ERROR (LED, certificate written; drive spun down)
     ─(drive remove, from any state)─► IDLE
```

Bay 9 (the M.2 slot) adds a slot state in front of this: the slot is unpowered
until its door switch reads closed and PEDET reads PCIe; the service then
powers the slot, waits one second, rescans the PCIe bus, and the NVMe device
that appears enters the same IDLE → DETECTED → RUNNING flow as a USB bay. If
nothing enumerates within ten seconds the slot is powered off and latched until
the door is opened again. Opening the door at any point aborts the job,
detaches the PCIe device, and cuts slot power. A SATA M.2 module (PEDET low) is
refused with a message on the OLED.

A remove event while RUNNING cancels the worker and writes an `aborted`
certificate. A drive that re-enumerates in a DONE bay with the same serial
within 30 s (a bridge glitch) stays DONE rather than being wiped again. Power
loss mid-wipe leaves a `state.json` so the next boot writes `interrupted`
certificates for the drives that were running.

### 4.7 Certificate

One JSON file per drive per run, e.g.
`/var/lib/brain-drain/reports/2026-09-21T14-02-11Z_WD-WCC4E1234567.json`:
unit ID, firmware version, bay, drive model/serial/firmware/capacity, media
type detection evidence, method chain attempted and the one that succeeded,
NIST tier claimed (Clear/Purge/none), verification type and result, start/end
timestamps (RTC), throughput, SMART pre/post summary, operator DIP settings.
Also copied to any FAT-formatted USB stick present at completion and, if
configured, POSTed to an HTTP endpoint.

### 4.8 Simulation and tests

`BRAIN_DRAIN_SIM=1` swaps the HAL for fakes: bays backed by loop devices or
sparse files, DIP from a file you edit, OLED rendered to the terminal. This is
how the engine gets developed and tested on a workstation before the board
exists. `pytest` covers policy selection, safety fence, progress math, report
schema, and each method against fake `hdparm`/`nvme` subprocess outputs.

## 5. Workstream 3: enclosure

* **Tool:** OpenSCAD, everything driven from `enclosure/params.scad`. Connector positions are generated from the KiCad PCB by
  `enclosure/tools/kicad_to_scad.py` so the shell tracks the board. **The generated `board.scad` is mirrored in x** (measured from the
  board's right edge): KiCad's top view is left-handed, OpenSCAD is right-handed, so a board that is seen from the front with x to the
  right sits in the tray with x measured from the tray's x = max wall. The renders and the lid-plan diagram undo the mirror.
* **Form (C21-C27):** a box about 157 x 145 x 62 mm: a tray and a lid hinged along the rear top edge (filament pin) with a snap latch at
  the front, so it pops open for the M.2 SSD; the lid microswitch is the M.2 "door". The brain sits on M2.5 heat-set standoffs. The tray is
  16 mm deeper behind the board than the board itself because the 45 mm bay cards overhang its rear edge (C27).
  Left wall (as seen from the front): DIN 12 V, USB-C, microSD. Right wall: the CM5 antenna side, vents only, no metal. Rear and right:
  vent slots. Lid: eight 11.8 x 43 mm windows over the cards' SATA receptacles (the drive cables rise through them), OLED window with a
  recess for the module (on a 4-wire lead, over the SSD), DIP slot, twelve LED holes, convection grille over the CM5 cooler.
  Floor: feet pockets. Nothing carries the drives; they lie on the bench.
* **Height:** the socket is 11.25 mm tall and the card body stands 37.6 mm above it, so the card top edge is 48.9 mm above the board;
  `above_board` is 50 mm and the plugs pass through the lid windows.
* **Print:** PETG or ASA, 0.2 mm layers, no supports by design (lid printed upside down).
* **Card retention (C30):** the lid carries a comb of nine 2.6 mm ribs, 8 mm deep, one in every gap between neighbouring receptacle
  housings (0.4 mm clearance to the card back face and to the next housing; the straight plug path stays free), and the tray has eight
  blocks under the cards' rear overhang, each with a 2.0 mm groove 0.5 mm below the card shoulder. `enclosure/tools/check_fit.py` checks
  the gaps against the placed card models. The lid holds the cards only when closed; with the lid open a card is held by its socket.
* **Artwork (C30):** the octopus logo, `BRAIN-DRAIN` and `NIST 800-88 DISK SANITIZER` are engraved 0.6 mm into the lid's outer face
  (impression, prints on the bed face). The brain board carries the same logo as top silkscreen with the name, a tagline and
  `github.com/dmz006/brain-drain` and the board revision (`REV` in `branding.py`, also written to the KiCad title block), placed in the largest free area left of the middle (`hardware/tools/branding.py`); the card carries its name.
* **Refinements** (`refinements.scad`): an OLED bezel that clamps the module under the lid window, rubber-feet pockets.
* **Images:** `docs/img/renders/` (see [RENDERS.md](RENDERS.md)), generated by `enclosure/tools/gallery.py`.

open

## 6. Cross-cutting

* **Safety fence** (§4.3) is reviewed on every change to `devices.py` or `bays.py`.
* **Thermal:** passive CM5 cooler (C23); the workload is I/O bound. The fan
  header stays for a 5 V PWM fan under the lid grille if a summer bench shows
  throttling. ASM1153E, hubs and bucks are fine.
* **Wireless and the phone page (C22):** the CM5 wireless variant runs an
  access point (`nmcli` hotspot, 10.42.0.1/24) with SSID `brain-drain-<4 hex>`
  and an 8-character key made fresh at every boot. Idle, the OLED shows a Wi-Fi
  QR code (`WIFI:T:WPA;S:…;P:…;;`) plus the key and address; running, the key
  and address take the bottom rows. The page (`webui.py`, standard library
  HTTP on port 80) serves status, certificates (single or zip), the log tail,
  and two actions that need the key: join a network (saved to
  `/var/lib/brain-drain/wifi.json`, joined at every boot, falls back to the
  access point if it fails) and reset (Wi-Fi: forget the network and rotate the
  key; factory: also delete certificates and state). Without a network, DIP
  mode 110 at boot does the Wi-Fi reset, and 110 with DIP 8 the factory reset;
  `braindrain wifi-reset [--factory]` does the same over SSH. The key is the
  only authorisation: reading the screen is the permission.
* **Compliance record:** the certificate schema is versioned; the report states
  which 800-88 tier was achieved, and says so honestly when only overwrite was
  possible on an SSD.
* **Boot order:** the CM5 EEPROM config pins boot to eMMC/SD only. USB and NVMe
  boot are disabled so a drive in a bay can never be booted from or mistaken for
  the root device.

## 7. Open decisions

See `docs/DECISIONS.md`. Closed: CM5, USB topology, hub, bridge, input connector, LEDs, M.2 bay, brain plus bay cards (C24),
six layers (C26), card width (C27). Still open: OLED size (D5), option B with bridges in the cables (D6, parked).

## 8. Throughput expectations and build order

With four bays at native drive speed (§3.2; cards in slots 1, 2, 5 and 6), a 4 TB HDD single-pass overwrite
takes ~7.5 h and a full read-back verify another ~7.5 h, and **four such drives
in parallel take the same ~15 h**, not longer. Firmware Sanitize runs inside the
drive at a similar rate with no bus load. SATA SSDs overwrite at ~400 MB/s per
bay (the USB port limit); crypto scramble takes seconds.

1. **Software in simulation** — the engine, policy, safety fence, and methods can
   be built and tested now on any Linux box with a USB-SATA dock, and are the
   riskiest part to get right. Hardware questions (bridge SAT behaviour under
   Sanitize, USB bridge timeouts) get answered on a bench dock before the board
   is committed. A Pi 5 plus two USB-SATA docks is a near-exact software
   test bed for this topology.
2. **Carrier board schematic** — while the software matures. Layout after the
   §7 decisions.
3. **Enclosure** — last, once the board outline and connector positions are frozen.

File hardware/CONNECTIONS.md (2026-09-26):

# brain-drain brain: CM5, two USB 3 hubs, eight bay slots, M.2 bay, power, UI — connection list

Generated from `hardware/tools/design.py`; do not edit by hand. One table per sheet: every
component with its symbol, value and footprint, then every net on that sheet with the pins
it joins. Nets marked **global** continue on other sheets. Pins listed under *No connect*
get an explicit no-connect flag.

Totals: 163 components, 192 nets.

## Sheet `power-input` — 12 V DIN input, fuse, TVS, reverse-polarity FET, bulk capacitance (sized for 8 bays)

### Components

| Ref | Symbol | Value | Footprint | Note |
|---|---|---|---|---|
| C20 | `Device:C_Polarized` | 680u 25V low-ESR | `Capacitor_SMD:CP_Elec_10x10.5` |  |
| C21 | `Device:C_Polarized` | 680u 25V low-ESR | `Capacitor_SMD:CP_Elec_10x10.5` |  |
| C22 | `Device:C` | 10u 25V | `Capacitor_SMD:C_1210_3225Metric` |  |
| D20 | `Device:D_TVS` | SMBJ15A | `Diode_SMD:D_SMB` |  |
| D21 | `Device:D_Zener` | 12V 0.5W | `Diode_SMD:D_SOD-123` | clamps Vgs of Q20 |
| F1 | `Device:Fuse` | 15A slow 0453015.MR | `Fuse:Fuse_Littelfuse-NANO2-451_453` |  |
| J21 | `brain-drain:DIN4_KPJX` | KPJX-4S-S | `brain-drain:Kycon_KPJX-4S-S` |  |
| Q20 | `brain-drain:PMOS_SSSGDDDD` | AO4407A | `Package_SO:SOIC-8_3.9x4.9mm_P1.27mm` | reverse-polarity protection, body diode toward load; SO-8 power pin-out S 1-3, G 4, D 5-8 |
| R20 | `Device:R` | 100k | `Resistor_SMD:R_0603_1608Metric` |  |

### Nets

| Net | Scope | Pins on this sheet | Also on |
|---|---|---|---|
| `GND` | **global** | J21.3, J21.4, J21.5 (SHIELD), D20.1 (A1), R20.2, C20.2, C21.2, C22.2 | bay-slots, cm5, m2-nvme, power-bucks, usb3-hub-A, usb3-hub-B |
| `Q20_GATE` | local | Q20.4 (G), R20.1, D21.2 (A) |  |
| `VIN_12V_FUSED` | local | F1.2, D20.2 (A2), Q20.5 (D), Q20.6 (D), Q20.7 (D), Q20.8 (D) |  |
| `VIN_12V_RAW` | **global** | J21.1, J21.2, F1.1 |  |
| `+12V` | **global** | Q20.1 (S), Q20.2 (S), Q20.3 (S), C20.1, C21.1, C22.1, D21.1 (K) | bay-slots, m2-nvme, power-bucks |

### Notes

* J21 pins 1/2 = +12 V and 3/4 = GND is a PLACEHOLDER: wire to match the chosen 12 V/10 A brick's DIN pinout (C13).
* Q20 is a P-MOSFET used as an ideal-diode-style reverse-polarity switch: drain to the fused input, source to +12V, gate pulled to GND through R20 and clamped by D21.

## Sheet `power-bucks` — 5V_SYS and 5V_HDD (TPS56637), +3V3 and 3V3_M2 (AP63203), +1V2 LDO

### Components

| Ref | Symbol | Value | Footprint | Note |
|---|---|---|---|---|
| C30 | `Device:C` | 1u 10V | `Capacitor_SMD:C_0402_1005Metric` |  |
| C31 | `Device:C` | 10u 10V | `Capacitor_SMD:C_0805_2012Metric` |  |
| C2000 | `Device:C` | 10u 25V | `Capacitor_SMD:C_1210_3225Metric` | VIN bypass |
| C2001 | `Device:C` | 10u 25V | `Capacitor_SMD:C_1210_3225Metric` |  |
| C2002 | `Device:C` | 100n 25V | `Capacitor_SMD:C_0402_1005Metric` | BOOT |
| C2003 | `Device:C` | 22u 10V | `Capacitor_SMD:C_0805_2012Metric` |  |
| C2004 | `Device:C` | 22u 10V | `Capacitor_SMD:C_0805_2012Metric` |  |
| C2005 | `Device:C` | 22u 10V | `Capacitor_SMD:C_0805_2012Metric` |  |
| C2100 | `Device:C` | 10u 25V | `Capacitor_SMD:C_1210_3225Metric` | VIN bypass |
| C2101 | `Device:C` | 10u 25V | `Capacitor_SMD:C_1210_3225Metric` |  |
| C2102 | `Device:C` | 100n 25V | `Capacitor_SMD:C_0402_1005Metric` | BOOT |
| C2103 | `Device:C` | 22u 10V | `Capacitor_SMD:C_0805_2012Metric` |  |
| C2104 | `Device:C` | 22u 10V | `Capacitor_SMD:C_0805_2012Metric` |  |
| C2105 | `Device:C` | 22u 10V | `Capacitor_SMD:C_0805_2012Metric` |  |
| C2200 | `Device:C` | 10u 25V | `Capacitor_SMD:C_1210_3225Metric` |  |
| C2201 | `Device:C` | 100n 10V | `Capacitor_SMD:C_0402_1005Metric` | BST |
| C2202 | `Device:C` | 22u 10V | `Capacitor_SMD:C_0805_2012Metric` |  |
| C2203 | `Device:C` | 22u 10V | `Capacitor_SMD:C_0805_2012Metric` |  |
| L20 | `Device:L` | 2.2u 8A | `Inductor_SMD:L_Taiyo-Yuden_NR-60xx` |  |
| L21 | `Device:L` | 2.2u 8A | `Inductor_SMD:L_Taiyo-Yuden_NR-60xx` |  |
| L22 | `Device:L` | 4.7u 3A | `Inductor_SMD:L_Taiyo-Yuden_NR-40xx` |  |
| R2000 | `Device:R` | 73.2k | `Resistor_SMD:R_0402_1005Metric` | FB top, 1% |
| R2001 | `Device:R` | 10k | `Resistor_SMD:R_0402_1005Metric` | FB bottom, 1% |
| R2002 | `Device:R` | 100k | `Resistor_SMD:R_0402_1005Metric` | EN pull-up |
| R2003 | `Device:R` | 10k | `Resistor_SMD:R_0402_1005Metric` | PG pull-up |
| R2100 | `Device:R` | 73.2k | `Resistor_SMD:R_0402_1005Metric` | FB top, 1% |
| R2101 | `Device:R` | 10k | `Resistor_SMD:R_0402_1005Metric` | FB bottom, 1% |
| R2102 | `Device:R` | 100k | `Resistor_SMD:R_0402_1005Metric` | EN pull-up |
| R2103 | `Device:R` | 10k | `Resistor_SMD:R_0402_1005Metric` | PG pull-up |
| U3 | `Regulator_Linear:AP2112K-1.2` | AP2112K-1.2 | `Package_TO_SOT_SMD:SOT-23-5` |  |
| U20 | `brain-drain:TPS56637` | TPS56637RPAR | `brain-drain:Texas_RPA0010A_VQFN-HR-10_3x3mm` |  |
| U21 | `brain-drain:TPS56637` | TPS56637RPAR | `brain-drain:Texas_RPA0010A_VQFN-HR-10_3x3mm` |  |
| U22 | `Regulator_Switching:AP63203WU` | AP63203WU-7 | `Package_TO_SOT_SMD:TSOT-23-6` |  |

### Nets

| Net | Scope | Pins on this sheet | Also on |
|---|---|---|---|
| `GND` | **global** | C2000.2, C2001.2, U20.3 (AGND), U20.9 (PGND), R2001.2, C2003.2, C2004.2, C2005.2, C2100.2, C2101.2, U21.3 (AGND), U21.9 (PGND), R2101.2, C2103.2, C2104.2, C2105.2, U22.4 (GND), C2200.2, C2202.2, C2203.2, U3.2 (GND), C30.2, C31.2 | bay-slots, cm5, m2-nvme, power-input, usb3-hub-A, usb3-hub-B |
| `PG_5V_HDD` | local | U21.4 (PG), R2103.2 |  |
| `PG_5V_SYS` | local | U20.4 (PG), R2003.2 |  |
| `U20_BOOT` | local | U20.7 (BOOT), C2002.1 |  |
| `U20_EN` | local | U20.1 (EN), R2002.2 |  |
| `U20_FB` | local | U20.2 (FB), R2000.2, R2001.1 |  |
| `U20_SW` | local | U20.6 (SW), L20.1, C2002.2 |  |
| `U21_BOOT` | local | U21.7 (BOOT), C2102.1 |  |
| `U21_EN` | local | U21.1 (EN), R2102.2 |  |
| `U21_FB` | local | U21.2 (FB), R2100.2, R2101.1 |  |
| `U21_SW` | local | U21.6 (SW), L21.1, C2102.2 |  |
| `U22_BST` | local | U22.6 (BST), C2201.1 |  |
| `U22_SW` | local | U22.5 (SW), L22.1, C2201.2 |  |
| `+12V` | **global** | U20.8 (VIN), C2000.1, C2001.1, R2002.1, U21.8 (VIN), C2100.1, C2101.1, R2102.1, U22.3 (IN), C2200.1, U22.2 (EN) | bay-slots, m2-nvme, power-input |
| `+1V2` | **global** | U3.5 (VOUT), C31.1 | usb3-hub-A, usb3-hub-B |
| `+3V3` | **global** | L22.2, C2202.1, C2203.1, U22.1 (FB), U3.1 (VIN), U3.3 (EN), C30.1 | bay-slots, cm5, usb3-hub-A, usb3-hub-B |
| `5V_HDD` | **global** | L21.2, C2103.1, C2104.1, C2105.1, R2100.1, R2103.1 | bay-slots |
| `5V_SYS` | **global** | L20.2, C2003.1, C2004.1, C2005.1, R2000.1, R2003.1 | cm5 |

### No connect

* U20: 10 (MODE), 5 (NC)
* U21: 10 (MODE), 5 (NC)
* U3: 4 (NC)

### Notes

* TPS56637 FB: Vref 0.6 V; 73.2k/10k gives 4.99 V. MODE floating = forced CCM (quietest for the CM5 rail).
* AP63203WU is the fixed 3.3 V variant: FB ties straight to the output. EN tied to VIN (always on).

## Sheet `cm5` — Compute Module 5 (wireless): power, control, GPIO, microSD, USB-C, UART, RTC cell, fan, DIP, LEDs, OLED

### Components

| Ref | Symbol | Value | Footprint | Note |
|---|---|---|---|---|
| BT1 | `Device:Battery_Cell` | CR2032 | `Battery:BatteryHolder_Keystone_1060_1x2032` |  |
| C1 | `Device:C` | 22u 10V | `Capacitor_SMD:C_0805_2012Metric` |  |
| C2 | `Device:C` | 22u 10V | `Capacitor_SMD:C_0805_2012Metric` |  |
| C3 | `Device:C` | 10u 10V | `Capacitor_SMD:C_0805_2012Metric` |  |
| C4 | `Device:C` | 1u 10V | `Capacitor_SMD:C_0402_1005Metric` |  |
| D1 | `Device:LED` | green PWR | `LED_THT:LED_D3.0mm` |  |
| D2 | `Device:LED` | green ACT | `LED_THT:LED_D3.0mm` |  |
| D3 | `Device:LED` | red STATUS | `LED_THT:LED_D3.0mm` |  |
| J3 | `Connector:Micro_SD_Card` | microSD | `Connector_Card:microSD_HC_Hirose_DM3AT-SF-PEJM5` |  |
| J5 | `Connector:USB_C_Receptacle_USB2.0_16P` | USB-C rpiboot | `Connector_USB:USB_C_Receptacle_GCT_USB4085` |  |
| J6 | `Connector_Generic:Conn_01x02` | nRPIBOOT | `Connector_PinHeader_2.54mm:PinHeader_1x02_P2.54mm_Vertical` |  |
| J7 | `Connector_Generic:Conn_01x03` | UART0 GND/TX/RX | `Connector_PinHeader_2.54mm:PinHeader_1x03_P2.54mm_Vertical` |  |
| J40 | `Connector_Generic:Conn_01x04` | Fan GND/5V/TACH/PWM | `Connector:FanPinHeader_1x04_P2.54mm_Vertical` |  |
| J41 | `Connector_Generic:Conn_01x04` | OLED GND/VCC/SCL/SDA | `Connector_PinHeader_2.54mm:PinHeader_1x04_P2.54mm_Vertical` |  |
| M1 (unit 1,2,3,5) | `brain-drain:CM5` | CM5002016 | `brain-drain:Raspberry-Pi-5-Compute-Module` |  |
| R1 | `Device:R` | 1k | `Resistor_SMD:R_0603_1608Metric` |  |
| R2 | `Device:R` | 1k | `Resistor_SMD:R_0603_1608Metric` |  |
| R3 | `Device:R` | 1k | `Resistor_SMD:R_0603_1608Metric` |  |
| R10 | `Device:R` | 10k | `Resistor_SMD:R_0402_1005Metric` | FAN_PWM pull-up (open-drain output), as on CM5IO |
| R11 | `Device:R` | 10k | `Resistor_SMD:R_0402_1005Metric` | SD_PWR_ON pull-up |
| SW1 | `Switch:SW_DIP_x08` | DIP x8 | `Button_Switch_THT:SW_DIP_SPSTx08_Piano_10.8x21.88mm_W7.62mm_P2.54mm` |  |
| U52 | `brain-drain:TPS22965` | TPS22965DSGR | `Package_SON:Texas_DSG0008A_WSON-8-1EP_2x2mm_P0.5mm_EP0.9x1.6mm` | microSD power switch, driven by SD_PWR_ON (as CM5IO does with an RT9742) |

### Nets

| Net | Scope | Pins on this sheet | Also on |
|---|---|---|---|
| `BAY_EN1` | **global** | M1.34 (GPIO5) | bay-slots |
| `BAY_EN2` | **global** | M1.30 (GPIO6) | bay-slots |
| `BAY_EN3` | **global** | M1.31 (GPIO12) | bay-slots |
| `BAY_EN4` | **global** | M1.28 (GPIO13) | bay-slots |
| `BAY_EN5` | **global** | M1.37 (GPIO7) | bay-slots |
| `BAY_EN6` | **global** | M1.39 (GPIO8) | bay-slots |
| `BAY_EN7` | **global** | M1.40 (GPIO9) | bay-slots |
| `BAY_EN8` | **global** | M1.44 (GPIO10) | bay-slots |
| `CM5_3V3` | local | M1.84 (CM5_3.3V), M1.86 (CM5_3.3V), M1.78 (GPIO_VREF) |  |
| `D1_A` | local | R1.2, D1.2 (A) |  |
| `D2_A` | local | R2.2, D2.2 (A) |  |
| `D3_A` | local | R3.2, D3.2 (A) |  |
| `DIP1` | local | M1.29 (GPIO16), SW1.1 |  |
| `DIP2` | local | M1.50 (GPIO17), SW1.2 |  |
| `DIP3` | local | M1.27 (GPIO20), SW1.3 |  |
| `DIP4` | local | M1.25 (GPIO21), SW1.4 |  |
| `DIP5` | local | M1.46 (GPIO22), SW1.5 |  |
| `DIP6` | local | M1.47 (GPIO23), SW1.6 |  |
| `DIP7` | local | M1.45 (GPIO24), SW1.7 |  |
| `DIP8` | local | M1.41 (GPIO25), SW1.8 |  |
| `FAN_PWM` | local | M1.19 (Fan_PWM), J40.4 (Pin_4), R10.2 |  |
| `FAN_TACHO` | local | M1.16 (Fan_Tacho), J40.3 (Pin_3) |  |
| `GND` | **global** | M1.1 (GND), M1.2 (GND), M1.7 (GND), M1.8 (GND), M1.13 (GND), M1.14 (GND), M1.22 (GND), M1.23 (GND), M1.32 (GND), M1.33 (GND), M1.42 (GND), M1.43 (GND), M1.52 (GND), M1.53 (GND), M1.59 (GND), M1.60 (GND), M1.65 (GND), M1.66 (GND), M1.71 (GND), M1.74 (GND), M1.98 (GND), M1.107 (GND), M1.108 (GND), M1.113 (GND), M1.114 (GND), M1.119 (GND), M1.120 (GND), M1.125 (GND), M1.126 (GND), M1.131 (GND), M1.132 (GND), M1.137 (GND), M1.138 (GND), M1.144 (GND), M1.150 (GND), M1.155 (GND), M1.156 (GND), M1.161 (GND), M1.162 (GND), M1.167 (GND), M1.168 (GND), M1.173 (GND), M1.174 (GND), M1.179 (GND), M1.180 (GND), M1.185 (GND), M1.186 (GND), M1.191 (GND), M1.192 (GND), M1.197 (GND), M1.198 (GND), C1.2, C2.2, BT1.2 (-), J6.2 (Pin_2), J7.1 (Pin_1), J40.1 (Pin_1), D1.1 (K), SW1.16, SW1.15, SW1.14, SW1.13, SW1.12, SW1.11, SW1.10, SW1.9, J41.1 (Pin_1), J3.6 (VSS), J3.9 (SHIELD), U52.5 (GND), U52.9 (EP), C3.2, C4.2, J5.A1 (GND), J5.A12 (GND), J5.B1 (GND), J5.B12 (GND), J5.S1 (SHIELD) | bay-slots, m2-nvme, power-bucks, power-input, usb3-hub-A, usb3-hub-B |
| `I2C1_SCL` | local | M1.56 (GPIO3), J41.3 (Pin_3) |  |
| `I2C1_SDA` | local | M1.58 (GPIO2), J41.4 (Pin_4) |  |
| `LED_nACT` | local | D2.1 (K), M1.21 (LED_nACT) |  |
| `M2_DOOR` | **global** | M1.54 (GPIO4) | m2-nvme |
| `M2_PEDET` | **global** | M1.26 (GPIO19) | m2-nvme |
| `M2_PWR_EN` | **global** | M1.48 (GPIO27) | m2-nvme |
| `SD_CLK` | local | M1.57 (SD_CLK), J3.5 (CLK) |  |
| `SD_CMD` | local | M1.62 (SD_CMD), J3.3 (CMD) |  |
| `SD_DAT0` | local | M1.63 (SD_DAT0), J3.7 (DAT0) |  |
| `SD_DAT1` | local | M1.67 (SD_DAT1), J3.8 (DAT1) |  |
| `SD_DAT2` | local | M1.69 (SD_DAT2), J3.1 (DAT2) |  |
| `SD_DAT3` | local | M1.61 (SD_DAT3), J3.2 (DAT3/CD) |  |
| `SD_PWR_ON` | local | M1.75 (SD_PWR_ON), U52.3 (ON), R11.2 |  |
| `SD_VDD` | **global** | U52.8 (VOUT), U52.7 (VOUT), J3.4 (VDD), C3.1 |  |
| `STATUS_LED` | local | D3.1 (K), M1.24 (GPIO26) |  |
| `UART0_RXD` | local | M1.51 (GPIO15), J7.3 (Pin_3) |  |
| `UART0_TXD` | local | M1.55 (GPIO14), J7.2 (Pin_2) |  |
| `USB2_DM` | **global** | J5.A7 (D-), J5.B7 (D-) | m2-nvme |
| `USB2_DP` | **global** | J5.A6 (D+), J5.B6 (D+) | m2-nvme |
| `USBC_CC1` | local | J5.A5 (CC1), M1.94 (CC1) |  |
| `USBC_CC2` | local | J5.B5 (CC2), M1.96 (CC2) |  |
| `VBAT` | local | M1.76 (VBAT), BT1.1 (+) |  |
| `+3V3` | **global** | R10.1, R1.1, R2.1, R3.1, J41.2 (Pin_2), U52.1 (VIN), U52.2 (VIN), U52.4 (VBIAS), C4.1, R11.1 | bay-slots, power-bucks, usb3-hub-A, usb3-hub-B |
| `5V_SYS` | **global** | M1.77 (5V), M1.79 (5V), M1.81 (5V), M1.83 (5V), M1.85 (5V), M1.87 (5V), C1.1, C2.1, J40.2 (Pin_2) | power-bucks |
| `nRPIBOOT` | local | M1.93 (nRPIBOOT), J6.1 (Pin_1) |  |

### No connect

* J5: A4 (VBUS), A8 (SBU1), A9 (VBUS), B4 (VBUS), B8 (SBU2), B9 (VBUS)
* M1: 10 (Ethernet_Pair0_N), 100 (CAM_GPIO1), 11 (Ethernet_Pair2_P), 115 (MIPI0_D0_N), 117 (MIPI0_D0_P), 12 (Ethernet_Pair0_P), 121 (MIPI0_D1_N), 123 (MIPI0_D1_P), 127 (MIPI0_C_N), 129 (MIPI0_C_P), 133 (MIPI0_D2_N), 135 (MIPI0_D2_P), 139 (MIPI0_D3_N), 141 (MIPI0_D3_P), 143 (HDMI1_HOTPLUG), 145 (HDMI1_SDA), 146 (HDMI1_TX2_P), 147 (HDMI1_SCL), 148 (HDMI1_TX2_N), 149 (HDMI1_CEC), 15 (Ethernet_nLED3), 151 (HDMI0_CEC), 152 (HDMI1_TX1_P), 153 (HDMI0_HOTPLUG), 154 (HDMI1_TX1_N), 158 (HDMI1_TX0_P), 160 (HDMI1_TX0_N), 164 (HDMI1_CLK_P), 166 (HDMI1_CLK_N), 17 (Ethernet_nLED2), 170 (HDMI0_TX2_P), 172 (HDMI0_TX2_N), 175 (MIPI1_D0_N), 176 (HDMI0_TX1_P), 177 (MIPI1_D0_P), 178 (HDMI0_TX1_N), 18 (Ethernet_SYNC_OUT), 181 (MIPI1_D1_N), 182 (HDMI0_TX0_P), 183 (MIPI1_D1_P), 184 (HDMI0_TX0_N), 187 (MIPI1_C_N), 188 (HDMI0_CLK_P), 189 (MIPI1_C_P), 190 (HDMI0_CLK_N), 193 (MIPI1_D2_N), 194 (MIPI1_D3_N), 195 (MIPI1_D2_P), 196 (MIPI1_D3_P), 199 (HDMI0_SDA), 20 (EEPROM_nWP), 200 (HDMI0_SCL), 3 (Ethernet_Pair3_P), 35 (ID_SC), 36 (ID_SD), 38 (GPIO11), 4 (Ethernet_Pair1_P), 49 (GPIO18), 5 (Ethernet_Pair3_N), 6 (Ethernet_Pair1_N), 64 (SD_DAT5), 68 (SD_DAT4), 70 (SD_DAT7), 72 (SD_DAT6), 73 (SD_VDD_OVERRIDE), 80 (SCL0), 82 (SDA0), 88 (CM5_1.8V), 89 (WL_nDisable), 9 (Ethernet_Pair2_N), 90 (CM5_1.8V), 91 (BT_nDisable), 92 (PWR_Button), 95 (LED_nPWR), 97 (CAM_GPIO0), 99 (PMIC_Enable)
* U52: 6 (CT)

### Notes

* GPIO_VREF is tied to the CM5's own 3.3 V output (pins 84/86) for 3.3 V GPIO signalling, per datasheet §4.2.
* PMIC_Enable and PWR_Button are left floating (internal pull-ups). nRPIBOOT goes to jumper J6.
* LED_nACT is an open-drain 20 mA output on the CM5: it sinks D2 directly. GPIO26 sinks D3 (software drives it low to light).
* microSD power goes through U52 so the CM5 can power-cycle the card on reboot via SD_PWR_ON, matching the CM5IO reference (which uses an RT9742).
* Ethernet dropped (C22). The CM5 wireless variant's PCB antenna is on the short module edge that carries MH1; that edge sits on the board's left edge with an 8 mm copper-free strip under it and no metal within 10 mm (CM5 datasheet 4.1.2).
* USB-C is a device port (rpiboot / gadget). As on the CM5IO, CC1/CC2 go straight to the CM5, which presents the sink pull-downs itself; VBUS is not connected (the board is powered from 12 V). USB_OTG_ID floats = device.

## Sheet `usb3-hub-A` — USB5744 hub A on CM5 USB3-0, bay slots 1-4

### Components

| Ref | Symbol | Value | Footprint | Note |
|---|---|---|---|---|
| C100 | `Device:C` | 33p | `Capacitor_SMD:C_0402_1005Metric` |  |
| C101 | `Device:C` | 33p | `Capacitor_SMD:C_0402_1005Metric` |  |
| C110 | `Device:C` | 100n | `Capacitor_SMD:C_0402_1005Metric` | VDD33 decoupling |
| C111 | `Device:C` | 100n | `Capacitor_SMD:C_0402_1005Metric` | VDD33 decoupling |
| C112 | `Device:C` | 100n | `Capacitor_SMD:C_0402_1005Metric` | VDD33 decoupling |
| C113 | `Device:C` | 100n | `Capacitor_SMD:C_0402_1005Metric` | VDD33 decoupling |
| C120 | `Device:C` | 100n | `Capacitor_SMD:C_0402_1005Metric` | VDD12 decoupling |
| C121 | `Device:C` | 100n | `Capacitor_SMD:C_0402_1005Metric` | VDD12 decoupling |
| C122 | `Device:C` | 100n | `Capacitor_SMD:C_0402_1005Metric` | VDD12 decoupling |
| C123 | `Device:C` | 100n | `Capacitor_SMD:C_0402_1005Metric` | VDD12 decoupling |
| C130 | `Device:C` | 4.7u 10V | `Capacitor_SMD:C_0603_1608Metric` |  |
| C131 | `Device:C` | 4.7u 10V | `Capacitor_SMD:C_0603_1608Metric` |  |
| C140 | `Device:C` | 100n | `Capacitor_SMD:C_0402_1005Metric` | USB3 upstream TX AC coupling |
| C141 | `Device:C` | 100n | `Capacitor_SMD:C_0402_1005Metric` | USB3 upstream TX AC coupling |
| C151 | `Device:C` | 100n | `Capacitor_SMD:C_0402_1005Metric` | USB3 DN1 TX AC coupling |
| C152 | `Device:C` | 100n | `Capacitor_SMD:C_0402_1005Metric` | USB3 DN2 TX AC coupling |
| C153 | `Device:C` | 100n | `Capacitor_SMD:C_0402_1005Metric` | USB3 DN3 TX AC coupling |
| C154 | `Device:C` | 100n | `Capacitor_SMD:C_0402_1005Metric` | USB3 DN4 TX AC coupling |
| C161 | `Device:C` | 100n | `Capacitor_SMD:C_0402_1005Metric` | USB3 DN1 TX AC coupling |
| C162 | `Device:C` | 100n | `Capacitor_SMD:C_0402_1005Metric` | USB3 DN2 TX AC coupling |
| C163 | `Device:C` | 100n | `Capacitor_SMD:C_0402_1005Metric` | USB3 DN3 TX AC coupling |
| C164 | `Device:C` | 100n | `Capacitor_SMD:C_0402_1005Metric` | USB3 DN4 TX AC coupling |
| R100 | `Device:R` | 12.0k 1% | `Resistor_SMD:R_0402_1005Metric` | RBIAS |
| R101 | `Device:R` | 10k | `Resistor_SMD:R_0402_1005Metric` | VBUS_DET to 3.3 V |
| R102 | `Device:R` | 10k | `Resistor_SMD:R_0402_1005Metric` | RESET_N pull-up |
| R103 | `Device:R` | 200k | `Resistor_SMD:R_0402_1005Metric` | CFG_NON_REM: all ports removable |
| U1 | `brain-drain:USB5744` | USB5744/2G | `Package_DFN_QFN:QFN-56-1EP_7x7mm_P0.4mm_EP3.2x3.2mm` |  |
| Y1 | `Device:Crystal_GND24` | 25MHz CL=20pF | `Crystal:Crystal_SMD_3225-4Pin_3.2x2.5mm` |  |

### Nets

| Net | Scope | Pins on this sheet | Also on |
|---|---|---|---|
| `BAY1_USB2_DM` | **global** | U1.2 (USB2DN_DM1/PRT_DIS_M1) | bay-slots |
| `BAY1_USB2_DP` | **global** | U1.1 (USB2DN_DP1/PRT_DIS_P1) | bay-slots |
| `BAY1_USB3_RX_N` | **global** | C161.2 | bay-slots |
| `BAY1_USB3_RX_P` | **global** | C151.2 | bay-slots |
| `BAY1_USB3_TX_N` | **global** | U1.7 (USB3DN_RXDM1) | bay-slots |
| `BAY1_USB3_TX_P` | **global** | U1.6 (USB3DN_RXDP1) | bay-slots |
| `BAY2_USB2_DM` | **global** | U1.9 (USB2DN_DM2/PRT_DIS_M2) | bay-slots |
| `BAY2_USB2_DP` | **global** | U1.8 (USB2DN_DP2/PRT_DIS_P2) | bay-slots |
| `BAY2_USB3_RX_N` | **global** | C162.2 | bay-slots |
| `BAY2_USB3_RX_P` | **global** | C152.2 | bay-slots |
| `BAY2_USB3_TX_N` | **global** | U1.14 (USB3DN_RXDM2) | bay-slots |
| `BAY2_USB3_TX_P` | **global** | U1.13 (USB3DN_RXDP2) | bay-slots |
| `BAY3_USB2_DM` | **global** | U1.18 (USB2DN_DM3/PRT_DIS_M3) | bay-slots |
| `BAY3_USB2_DP` | **global** | U1.17 (USB2DN_DP3/PRT_DIS_P3) | bay-slots |
| `BAY3_USB3_RX_N` | **global** | C163.2 | bay-slots |
| `BAY3_USB3_RX_P` | **global** | C153.2 | bay-slots |
| `BAY3_USB3_TX_N` | **global** | U1.23 (USB3DN_RXDM3) | bay-slots |
| `BAY3_USB3_TX_P` | **global** | U1.22 (USB3DN_RXDP3) | bay-slots |
| `BAY4_USB2_DM` | **global** | U1.25 (USB2DN_DM4/PRT_DIS_M4) | bay-slots |
| `BAY4_USB2_DP` | **global** | U1.24 (USB2DN_DP4/PRT_DIS_P4) | bay-slots |
| `BAY4_USB3_RX_N` | **global** | C164.2 | bay-slots |
| `BAY4_USB3_RX_P` | **global** | C154.2 | bay-slots |
| `BAY4_USB3_TX_N` | **global** | U1.30 (USB3DN_RXDM4) | bay-slots |
| `BAY4_USB3_TX_P` | **global** | U1.29 (USB3DN_RXDP4) | bay-slots |
| `GND` | **global** | U1.EP (VSS), U1.52 (ATEST), R100.2, R103.2, Y1.2 (G), Y1.4 (G), C110.2, C111.2, C112.2, C113.2, C120.2, C121.2, C122.2, C123.2, C130.2, C131.2, C100.2, C101.2 | bay-slots, cm5, m2-nvme, power-bucks, power-input, usb3-hub-B |
| `U1_CFG_NON_REM` | local | U1.41 (SPI_CE_N/CFG_NON_REM), R103.1 |  |
| `U1_DN1_TXDM` | local | U1.4 (USB3DN_TXDM1), C161.1 |  |
| `U1_DN1_TXDP` | local | U1.3 (USB3DN_TXDP1), C151.1 |  |
| `U1_DN2_TXDM` | local | U1.11 (USB3DN_TXDM2), C162.1 |  |
| `U1_DN2_TXDP` | local | U1.10 (USB3DN_TXDP2), C152.1 |  |
| `U1_DN3_TXDM` | local | U1.20 (USB3DN_TXDM3), C163.1 |  |
| `U1_DN3_TXDP` | local | U1.19 (USB3DN_TXDP3), C153.1 |  |
| `U1_DN4_TXDM` | local | U1.27 (USB3DN_TXDM4), C164.1 |  |
| `U1_DN4_TXDP` | local | U1.26 (USB3DN_TXDP4), C154.1 |  |
| `U1_RBIAS` | local | U1.56 (RBIAS), R100.1 |  |
| `U1_RESET_N` | local | U1.42 (RESET_N), R102.2 |  |
| `U1_UP_TXDM` | local | U1.48 (USB3UP_TXDM), C141.1 |  |
| `U1_UP_TXDP` | local | U1.47 (USB3UP_TXDP), C140.1 |  |
| `U1_VBUS_DET` | local | U1.37 (VBUS_DET), R101.2 |  |
| `U1_XTALI` | local | U1.54 (XTALI/CLK_IN), Y1.1, C100.1 |  |
| `U1_XTALO` | local | U1.53 (XTALO), Y1.3, C101.1 |  |
| `USB3_0_DM` | **global** | U1.46 (USB2UP_DM) | m2-nvme |
| `USB3_0_DP` | **global** | U1.45 (USB2UP_DP) | m2-nvme |
| `USB3_0_RX_N` | **global** | C141.2 | m2-nvme |
| `USB3_0_RX_P` | **global** | C140.2 | m2-nvme |
| `USB3_0_TX_N` | **global** | U1.51 (USB3UP_RXDM) | m2-nvme |
| `USB3_0_TX_P` | **global** | U1.50 (USB3UP_RXDP) | m2-nvme |
| `+1V2` | **global** | U1.5 (VDD12), U1.12 (VDD12), U1.15 (VDD12), U1.21 (VDD12), U1.28 (VDD12), U1.33 (VDD12), U1.43 (VDD12), U1.49 (VDD12), C120.1, C121.1, C122.1, C123.1, C131.1 | power-bucks, usb3-hub-B |
| `+3V3` | **global** | U1.16 (VDD33), U1.31 (VDD33), U1.44 (VDD33), U1.55 (VDD33), C110.1, C111.1, C112.1, C113.1, C130.1, R101.1, R102.1 | bay-slots, cm5, power-bucks, usb3-hub-B |

### No connect

* U1: 32 (PRT_CTL4/GANG_PWR), 34 (PRT_CTL3), 35 (PRT_CTL2), 36 (PRT_CTL1), 38 (SPI_CLK/SMCLK), 39 (SPI_DO/SMDAT), 40 (SPI_DI/CFG_BC_EN)

### Notes

* Hub A: upstream on CM5 USB3-0. Downstream ports 1-4 -> bay slots 1-4 (C24: eight slots, four cards populated in v1).
* No SPI ROM and no SMBus pull-ups: the hub runs its internal ROM defaults. RESET_N has a pull-up only; add an RC if strap timing (1 ms hold) is a concern.
* Crystal: 25 MHz, CL 20 pF per datasheet table 10-10; 33 pF load caps assume ~3 pF stray, adjust to the chosen crystal.

## Sheet `usb3-hub-B` — USB5744 hub B on CM5 USB3-1, bay slots 5-8

### Components

| Ref | Symbol | Value | Footprint | Note |
|---|---|---|---|---|
| C200 | `Device:C` | 33p | `Capacitor_SMD:C_0402_1005Metric` |  |
| C201 | `Device:C` | 33p | `Capacitor_SMD:C_0402_1005Metric` |  |
| C210 | `Device:C` | 100n | `Capacitor_SMD:C_0402_1005Metric` | VDD33 decoupling |
| C211 | `Device:C` | 100n | `Capacitor_SMD:C_0402_1005Metric` | VDD33 decoupling |
| C212 | `Device:C` | 100n | `Capacitor_SMD:C_0402_1005Metric` | VDD33 decoupling |
| C213 | `Device:C` | 100n | `Capacitor_SMD:C_0402_1005Metric` | VDD33 decoupling |
| C220 | `Device:C` | 100n | `Capacitor_SMD:C_0402_1005Metric` | VDD12 decoupling |
| C221 | `Device:C` | 100n | `Capacitor_SMD:C_0402_1005Metric` | VDD12 decoupling |
| C222 | `Device:C` | 100n | `Capacitor_SMD:C_0402_1005Metric` | VDD12 decoupling |
| C223 | `Device:C` | 100n | `Capacitor_SMD:C_0402_1005Metric` | VDD12 decoupling |
| C230 | `Device:C` | 4.7u 10V | `Capacitor_SMD:C_0603_1608Metric` |  |
| C231 | `Device:C` | 4.7u 10V | `Capacitor_SMD:C_0603_1608Metric` |  |
| C240 | `Device:C` | 100n | `Capacitor_SMD:C_0402_1005Metric` | USB3 upstream TX AC coupling |
| C241 | `Device:C` | 100n | `Capacitor_SMD:C_0402_1005Metric` | USB3 upstream TX AC coupling |
| C251 | `Device:C` | 100n | `Capacitor_SMD:C_0402_1005Metric` | USB3 DN1 TX AC coupling |
| C252 | `Device:C` | 100n | `Capacitor_SMD:C_0402_1005Metric` | USB3 DN2 TX AC coupling |
| C253 | `Device:C` | 100n | `Capacitor_SMD:C_0402_1005Metric` | USB3 DN3 TX AC coupling |
| C254 | `Device:C` | 100n | `Capacitor_SMD:C_0402_1005Metric` | USB3 DN4 TX AC coupling |
| C261 | `Device:C` | 100n | `Capacitor_SMD:C_0402_1005Metric` | USB3 DN1 TX AC coupling |
| C262 | `Device:C` | 100n | `Capacitor_SMD:C_0402_1005Metric` | USB3 DN2 TX AC coupling |
| C263 | `Device:C` | 100n | `Capacitor_SMD:C_0402_1005Metric` | USB3 DN3 TX AC coupling |
| C264 | `Device:C` | 100n | `Capacitor_SMD:C_0402_1005Metric` | USB3 DN4 TX AC coupling |
| R200 | `Device:R` | 12.0k 1% | `Resistor_SMD:R_0402_1005Metric` | RBIAS |
| R201 | `Device:R` | 10k | `Resistor_SMD:R_0402_1005Metric` | VBUS_DET to 3.3 V |
| R202 | `Device:R` | 10k | `Resistor_SMD:R_0402_1005Metric` | RESET_N pull-up |
| R203 | `Device:R` | 200k | `Resistor_SMD:R_0402_1005Metric` | CFG_NON_REM: all ports removable |
| U2 | `brain-drain:USB5744` | USB5744/2G | `Package_DFN_QFN:QFN-56-1EP_7x7mm_P0.4mm_EP3.2x3.2mm` |  |
| Y2 | `Device:Crystal_GND24` | 25MHz CL=20pF | `Crystal:Crystal_SMD_3225-4Pin_3.2x2.5mm` |  |

### Nets

| Net | Scope | Pins on this sheet | Also on |
|---|---|---|---|
| `BAY5_USB2_DM` | **global** | U2.2 (USB2DN_DM1/PRT_DIS_M1) | bay-slots |
| `BAY5_USB2_DP` | **global** | U2.1 (USB2DN_DP1/PRT_DIS_P1) | bay-slots |
| `BAY5_USB3_RX_N` | **global** | C261.2 | bay-slots |
| `BAY5_USB3_RX_P` | **global** | C251.2 | bay-slots |
| `BAY5_USB3_TX_N` | **global** | U2.7 (USB3DN_RXDM1) | bay-slots |
| `BAY5_USB3_TX_P` | **global** | U2.6 (USB3DN_RXDP1) | bay-slots |
| `BAY6_USB2_DM` | **global** | U2.9 (USB2DN_DM2/PRT_DIS_M2) | bay-slots |
| `BAY6_USB2_DP` | **global** | U2.8 (USB2DN_DP2/PRT_DIS_P2) | bay-slots |
| `BAY6_USB3_RX_N` | **global** | C262.2 | bay-slots |
| `BAY6_USB3_RX_P` | **global** | C252.2 | bay-slots |
| `BAY6_USB3_TX_N` | **global** | U2.14 (USB3DN_RXDM2) | bay-slots |
| `BAY6_USB3_TX_P` | **global** | U2.13 (USB3DN_RXDP2) | bay-slots |
| `BAY7_USB2_DM` | **global** | U2.18 (USB2DN_DM3/PRT_DIS_M3) | bay-slots |
| `BAY7_USB2_DP` | **global** | U2.17 (USB2DN_DP3/PRT_DIS_P3) | bay-slots |
| `BAY7_USB3_RX_N` | **global** | C263.2 | bay-slots |
| `BAY7_USB3_RX_P` | **global** | C253.2 | bay-slots |
| `BAY7_USB3_TX_N` | **global** | U2.23 (USB3DN_RXDM3) | bay-slots |
| `BAY7_USB3_TX_P` | **global** | U2.22 (USB3DN_RXDP3) | bay-slots |
| `BAY8_USB2_DM` | **global** | U2.25 (USB2DN_DM4/PRT_DIS_M4) | bay-slots |
| `BAY8_USB2_DP` | **global** | U2.24 (USB2DN_DP4/PRT_DIS_P4) | bay-slots |
| `BAY8_USB3_RX_N` | **global** | C264.2 | bay-slots |
| `BAY8_USB3_RX_P` | **global** | C254.2 | bay-slots |
| `BAY8_USB3_TX_N` | **global** | U2.30 (USB3DN_RXDM4) | bay-slots |
| `BAY8_USB3_TX_P` | **global** | U2.29 (USB3DN_RXDP4) | bay-slots |
| `GND` | **global** | U2.EP (VSS), U2.52 (ATEST), R200.2, R203.2, Y2.2 (G), Y2.4 (G), C210.2, C211.2, C212.2, C213.2, C220.2, C221.2, C222.2, C223.2, C230.2, C231.2, C200.2, C201.2 | bay-slots, cm5, m2-nvme, power-bucks, power-input, usb3-hub-A |
| `U2_CFG_NON_REM` | local | U2.41 (SPI_CE_N/CFG_NON_REM), R203.1 |  |
| `U2_DN1_TXDM` | local | U2.4 (USB3DN_TXDM1), C261.1 |  |
| `U2_DN1_TXDP` | local | U2.3 (USB3DN_TXDP1), C251.1 |  |
| `U2_DN2_TXDM` | local | U2.11 (USB3DN_TXDM2), C262.1 |  |
| `U2_DN2_TXDP` | local | U2.10 (USB3DN_TXDP2), C252.1 |  |
| `U2_DN3_TXDM` | local | U2.20 (USB3DN_TXDM3), C263.1 |  |
| `U2_DN3_TXDP` | local | U2.19 (USB3DN_TXDP3), C253.1 |  |
| `U2_DN4_TXDM` | local | U2.27 (USB3DN_TXDM4), C264.1 |  |
| `U2_DN4_TXDP` | local | U2.26 (USB3DN_TXDP4), C254.1 |  |
| `U2_RBIAS` | local | U2.56 (RBIAS), R200.1 |  |
| `U2_RESET_N` | local | U2.42 (RESET_N), R202.2 |  |
| `U2_UP_TXDM` | local | U2.48 (USB3UP_TXDM), C241.1 |  |
| `U2_UP_TXDP` | local | U2.47 (USB3UP_TXDP), C240.1 |  |
| `U2_VBUS_DET` | local | U2.37 (VBUS_DET), R201.2 |  |
| `U2_XTALI` | local | U2.54 (XTALI/CLK_IN), Y2.1, C200.1 |  |
| `U2_XTALO` | local | U2.53 (XTALO), Y2.3, C201.1 |  |
| `USB3_1_DM` | **global** | U2.46 (USB2UP_DM) | m2-nvme |
| `USB3_1_DP` | **global** | U2.45 (USB2UP_DP) | m2-nvme |
| `USB3_1_RX_N` | **global** | C241.2 | m2-nvme |
| `USB3_1_RX_P` | **global** | C240.2 | m2-nvme |
| `USB3_1_TX_N` | **global** | U2.51 (USB3UP_RXDM) | m2-nvme |
| `USB3_1_TX_P` | **global** | U2.50 (USB3UP_RXDP) | m2-nvme |
| `+1V2` | **global** | U2.5 (VDD12), U2.12 (VDD12), U2.15 (VDD12), U2.21 (VDD12), U2.28 (VDD12), U2.33 (VDD12), U2.43 (VDD12), U2.49 (VDD12), C220.1, C221.1, C222.1, C223.1, C231.1 | power-bucks, usb3-hub-A |
| `+3V3` | **global** | U2.16 (VDD33), U2.31 (VDD33), U2.44 (VDD33), U2.55 (VDD33), C210.1, C211.1, C212.1, C213.1, C230.1, R201.1, R202.1 | bay-slots, cm5, power-bucks, usb3-hub-A |

### No connect

* U2: 32 (PRT_CTL4/GANG_PWR), 34 (PRT_CTL3), 35 (PRT_CTL2), 36 (PRT_CTL1), 38 (SPI_CLK/SMCLK), 39 (SPI_DO/SMDAT), 40 (SPI_DI/CFG_BC_EN)

### Notes

* Hub B: upstream on CM5 USB3-1. Downstream ports 1-4 -> bay slots 5-8 (C24: eight slots, four cards populated in v1).
* No SPI ROM and no SMBus pull-ups: the hub runs its internal ROM defaults. RESET_N has a pull-up only; add an RC if strap timing (1 ms hold) is a concern.
* Crystal: 25 MHz, CL 20 pF per datasheet table 10-10; 33 pF load caps assume ~3 pF stray, adjust to the chosen crystal.

## Sheet `bay-slots` — Eight bay slots (PCIe x1 sockets, bay-card pinout): USB 3, USB 2, 12 V, 5 V, BAY_EN, bay LEDs

### Components

| Ref | Symbol | Value | Footprint | Note |
|---|---|---|---|---|
| D10 | `Device:LED` | blue bay 1 activity | `LED_THT:LED_D3.0mm` |  |
| D11 | `Device:LED` | blue bay 2 activity | `LED_THT:LED_D3.0mm` |  |
| D12 | `Device:LED` | blue bay 3 activity | `LED_THT:LED_D3.0mm` |  |
| D13 | `Device:LED` | blue bay 4 activity | `LED_THT:LED_D3.0mm` |  |
| D14 | `Device:LED` | blue bay 5 activity | `LED_THT:LED_D3.0mm` |  |
| D15 | `Device:LED` | blue bay 6 activity | `LED_THT:LED_D3.0mm` |  |
| D16 | `Device:LED` | blue bay 7 activity | `LED_THT:LED_D3.0mm` |  |
| D17 | `Device:LED` | blue bay 8 activity | `LED_THT:LED_D3.0mm` |  |
| J10 | `brain-drain:BAY_SLOT` | bay slot 1 | `brain-drain:PCIe_x1_Socket_THT` |  |
| J11 | `brain-drain:BAY_SLOT` | bay slot 2 | `brain-drain:PCIe_x1_Socket_THT` |  |
| J12 | `brain-drain:BAY_SLOT` | bay slot 3 | `brain-drain:PCIe_x1_Socket_THT` |  |
| J13 | `brain-drain:BAY_SLOT` | bay slot 4 | `brain-drain:PCIe_x1_Socket_THT` |  |
| J14 | `brain-drain:BAY_SLOT` | bay slot 5 | `brain-drain:PCIe_x1_Socket_THT` |  |
| J15 | `brain-drain:BAY_SLOT` | bay slot 6 | `brain-drain:PCIe_x1_Socket_THT` |  |
| J16 | `brain-drain:BAY_SLOT` | bay slot 7 | `brain-drain:PCIe_x1_Socket_THT` |  |
| J17 | `brain-drain:BAY_SLOT` | bay slot 8 | `brain-drain:PCIe_x1_Socket_THT` |  |
| R60 | `Device:R` | 470 | `Resistor_SMD:R_0402_1005Metric` |  |
| R61 | `Device:R` | 470 | `Resistor_SMD:R_0402_1005Metric` |  |
| R62 | `Device:R` | 470 | `Resistor_SMD:R_0402_1005Metric` |  |
| R63 | `Device:R` | 470 | `Resistor_SMD:R_0402_1005Metric` |  |
| R64 | `Device:R` | 470 | `Resistor_SMD:R_0402_1005Metric` |  |
| R65 | `Device:R` | 470 | `Resistor_SMD:R_0402_1005Metric` |  |
| R66 | `Device:R` | 470 | `Resistor_SMD:R_0402_1005Metric` |  |
| R67 | `Device:R` | 470 | `Resistor_SMD:R_0402_1005Metric` |  |

### Nets

| Net | Scope | Pins on this sheet | Also on |
|---|---|---|---|
| `BAY1_LED_A` | local | R60.2, D10.2 (A) |  |
| `BAY1_LED_K` | local | J10.B6 (LED_K), D10.1 (K) |  |
| `BAY1_USB2_DM` | **global** | J10.B12 (USB2_DM) | usb3-hub-A |
| `BAY1_USB2_DP` | **global** | J10.B13 (USB2_DP) | usb3-hub-A |
| `BAY1_USB3_RX_N` | **global** | J10.B15 (USB3_RX_N) | usb3-hub-A |
| `BAY1_USB3_RX_P` | **global** | J10.B16 (USB3_RX_P) | usb3-hub-A |
| `BAY1_USB3_TX_N` | **global** | J10.A14 (USB3_TX_N) | usb3-hub-A |
| `BAY1_USB3_TX_P` | **global** | J10.A15 (USB3_TX_P) | usb3-hub-A |
| `BAY2_LED_A` | local | R61.2, D11.2 (A) |  |
| `BAY2_LED_K` | local | J11.B6 (LED_K), D11.1 (K) |  |
| `BAY2_USB2_DM` | **global** | J11.B12 (USB2_DM) | usb3-hub-A |
| `BAY2_USB2_DP` | **global** | J11.B13 (USB2_DP) | usb3-hub-A |
| `BAY2_USB3_RX_N` | **global** | J11.B15 (USB3_RX_N) | usb3-hub-A |
| `BAY2_USB3_RX_P` | **global** | J11.B16 (USB3_RX_P) | usb3-hub-A |
| `BAY2_USB3_TX_N` | **global** | J11.A14 (USB3_TX_N) | usb3-hub-A |
| `BAY2_USB3_TX_P` | **global** | J11.A15 (USB3_TX_P) | usb3-hub-A |
| `BAY3_LED_A` | local | R62.2, D12.2 (A) |  |
| `BAY3_LED_K` | local | J12.B6 (LED_K), D12.1 (K) |  |
| `BAY3_USB2_DM` | **global** | J12.B12 (USB2_DM) | usb3-hub-A |
| `BAY3_USB2_DP` | **global** | J12.B13 (USB2_DP) | usb3-hub-A |
| `BAY3_USB3_RX_N` | **global** | J12.B15 (USB3_RX_N) | usb3-hub-A |
| `BAY3_USB3_RX_P` | **global** | J12.B16 (USB3_RX_P) | usb3-hub-A |
| `BAY3_USB3_TX_N` | **global** | J12.A14 (USB3_TX_N) | usb3-hub-A |
| `BAY3_USB3_TX_P` | **global** | J12.A15 (USB3_TX_P) | usb3-hub-A |
| `BAY4_LED_A` | local | R63.2, D13.2 (A) |  |
| `BAY4_LED_K` | local | J13.B6 (LED_K), D13.1 (K) |  |
| `BAY4_USB2_DM` | **global** | J13.B12 (USB2_DM) | usb3-hub-A |
| `BAY4_USB2_DP` | **global** | J13.B13 (USB2_DP) | usb3-hub-A |
| `BAY4_USB3_RX_N` | **global** | J13.B15 (USB3_RX_N) | usb3-hub-A |
| `BAY4_USB3_RX_P` | **global** | J13.B16 (USB3_RX_P) | usb3-hub-A |
| `BAY4_USB3_TX_N` | **global** | J13.A14 (USB3_TX_N) | usb3-hub-A |
| `BAY4_USB3_TX_P` | **global** | J13.A15 (USB3_TX_P) | usb3-hub-A |
| `BAY5_LED_A` | local | R64.2, D14.2 (A) |  |
| `BAY5_LED_K` | local | J14.B6 (LED_K), D14.1 (K) |  |
| `BAY5_USB2_DM` | **global** | J14.B12 (USB2_DM) | usb3-hub-B |
| `BAY5_USB2_DP` | **global** | J14.B13 (USB2_DP) | usb3-hub-B |
| `BAY5_USB3_RX_N` | **global** | J14.B15 (USB3_RX_N) | usb3-hub-B |
| `BAY5_USB3_RX_P` | **global** | J14.B16 (USB3_RX_P) | usb3-hub-B |
| `BAY5_USB3_TX_N` | **global** | J14.A14 (USB3_TX_N) | usb3-hub-B |
| `BAY5_USB3_TX_P` | **global** | J14.A15 (USB3_TX_P) | usb3-hub-B |
| `BAY6_LED_A` | local | R65.2, D15.2 (A) |  |
| `BAY6_LED_K` | local | J15.B6 (LED_K), D15.1 (K) |  |
| `BAY6_USB2_DM` | **global** | J15.B12 (USB2_DM) | usb3-hub-B |
| `BAY6_USB2_DP` | **global** | J15.B13 (USB2_DP) | usb3-hub-B |
| `BAY6_USB3_RX_N` | **global** | J15.B15 (USB3_RX_N) | usb3-hub-B |
| `BAY6_USB3_RX_P` | **global** | J15.B16 (USB3_RX_P) | usb3-hub-B |
| `BAY6_USB3_TX_N` | **global** | J15.A14 (USB3_TX_N) | usb3-hub-B |
| `BAY6_USB3_TX_P` | **global** | J15.A15 (USB3_TX_P) | usb3-hub-B |
| `BAY7_LED_A` | local | R66.2, D16.2 (A) |  |
| `BAY7_LED_K` | local | J16.B6 (LED_K), D16.1 (K) |  |
| `BAY7_USB2_DM` | **global** | J16.B12 (USB2_DM) | usb3-hub-B |
| `BAY7_USB2_DP` | **global** | J16.B13 (USB2_DP) | usb3-hub-B |
| `BAY7_USB3_RX_N` | **global** | J16.B15 (USB3_RX_N) | usb3-hub-B |
| `BAY7_USB3_RX_P` | **global** | J16.B16 (USB3_RX_P) | usb3-hub-B |
| `BAY7_USB3_TX_N` | **global** | J16.A14 (USB3_TX_N) | usb3-hub-B |
| `BAY7_USB3_TX_P` | **global** | J16.A15 (USB3_TX_P) | usb3-hub-B |
| `BAY8_LED_A` | local | R67.2, D17.2 (A) |  |
| `BAY8_LED_K` | local | J17.B6 (LED_K), D17.1 (K) |  |
| `BAY8_USB2_DM` | **global** | J17.B12 (USB2_DM) | usb3-hub-B |
| `BAY8_USB2_DP` | **global** | J17.B13 (USB2_DP) | usb3-hub-B |
| `BAY8_USB3_RX_N` | **global** | J17.B15 (USB3_RX_N) | usb3-hub-B |
| `BAY8_USB3_RX_P` | **global** | J17.B16 (USB3_RX_P) | usb3-hub-B |
| `BAY8_USB3_TX_N` | **global** | J17.A14 (USB3_TX_N) | usb3-hub-B |
| `BAY8_USB3_TX_P` | **global** | J17.A15 (USB3_TX_P) | usb3-hub-B |
| `BAY_EN1` | **global** | J10.B5 (BAY_EN) | cm5 |
| `BAY_EN2` | **global** | J11.B5 (BAY_EN) | cm5 |
| `BAY_EN3` | **global** | J12.B5 (BAY_EN) | cm5 |
| `BAY_EN4` | **global** | J13.B5 (BAY_EN) | cm5 |
| `BAY_EN5` | **global** | J14.B5 (BAY_EN) | cm5 |
| `BAY_EN6` | **global** | J15.B5 (BAY_EN) | cm5 |
| `BAY_EN7` | **global** | J16.B5 (BAY_EN) | cm5 |
| `BAY_EN8` | **global** | J17.B5 (BAY_EN) | cm5 |
| `GND` | **global** | J10.A3 (GND), J10.A4 (GND), J10.A7 (GND), J10.A10 (GND), J10.A11 (GND), J10.A12 (GND), J10.A13 (GND), J10.A16 (GND), J10.A17 (GND), J10.A18 (GND), J10.B4 (GND), J10.B7 (GND), J10.B11 (GND), J10.B14 (GND), J10.B17 (GND), J10.B18 (GND), J11.A3 (GND), J11.A4 (GND), J11.A7 (GND), J11.A10 (GND), J11.A11 (GND), J11.A12 (GND), J11.A13 (GND), J11.A16 (GND), J11.A17 (GND), J11.A18 (GND), J11.B4 (GND), J11.B7 (GND), J11.B11 (GND), J11.B14 (GND), J11.B17 (GND), J11.B18 (GND), J12.A3 (GND), J12.A4 (GND), J12.A7 (GND), J12.A10 (GND), J12.A11 (GND), J12.A12 (GND), J12.A13 (GND), J12.A16 (GND), J12.A17 (GND), J12.A18 (GND), J12.B4 (GND), J12.B7 (GND), J12.B11 (GND), J12.B14 (GND), J12.B17 (GND), J12.B18 (GND), J13.A3 (GND), J13.A4 (GND), J13.A7 (GND), J13.A10 (GND), J13.A11 (GND), J13.A12 (GND), J13.A13 (GND), J13.A16 (GND), J13.A17 (GND), J13.A18 (GND), J13.B4 (GND), J13.B7 (GND), J13.B11 (GND), J13.B14 (GND), J13.B17 (GND), J13.B18 (GND), J14.A3 (GND), J14.A4 (GND), J14.A7 (GND), J14.A10 (GND), J14.A11 (GND), J14.A12 (GND), J14.A13 (GND), J14.A16 (GND), J14.A17 (GND), J14.A18 (GND), J14.B4 (GND), J14.B7 (GND), J14.B11 (GND), J14.B14 (GND), J14.B17 (GND), J14.B18 (GND), J15.A3 (GND), J15.A4 (GND), J15.A7 (GND), J15.A10 (GND), J15.A11 (GND), J15.A12 (GND), J15.A13 (GND), J15.A16 (GND), J15.A17 (GND), J15.A18 (GND), J15.B4 (GND), J15.B7 (GND), J15.B11 (GND), J15.B14 (GND), J15.B17 (GND), J15.B18 (GND), J16.A3 (GND), J16.A4 (GND), J16.A7 (GND), J16.A10 (GND), J16.A11 (GND), J16.A12 (GND), J16.A13 (GND), J16.A16 (GND), J16.A17 (GND), J16.A18 (GND), J16.B4 (GND), J16.B7 (GND), J16.B11 (GND), J16.B14 (GND), J16.B17 (GND), J16.B18 (GND), J17.A3 (GND), J17.A4 (GND), J17.A7 (GND), J17.A10 (GND), J17.A11 (GND), J17.A12 (GND), J17.A13 (GND), J17.A16 (GND), J17.A17 (GND), J17.A18 (GND), J17.B4 (GND), J17.B7 (GND), J17.B11 (GND), J17.B14 (GND), J17.B17 (GND), J17.B18 (GND) | cm5, m2-nvme, power-bucks, power-input, usb3-hub-A, usb3-hub-B |
| `+12V` | **global** | J10.A1 (12V), J10.A2 (12V), J10.B1 (12V), J10.B2 (12V), J10.B3 (12V), J11.A1 (12V), J11.A2 (12V), J11.B1 (12V), J11.B2 (12V), J11.B3 (12V), J12.A1 (12V), J12.A2 (12V), J12.B1 (12V), J12.B2 (12V), J12.B3 (12V), J13.A1 (12V), J13.A2 (12V), J13.B1 (12V), J13.B2 (12V), J13.B3 (12V), J14.A1 (12V), J14.A2 (12V), J14.B1 (12V), J14.B2 (12V), J14.B3 (12V), J15.A1 (12V), J15.A2 (12V), J15.B1 (12V), J15.B2 (12V), J15.B3 (12V), J16.A1 (12V), J16.A2 (12V), J16.B1 (12V), J16.B2 (12V), J16.B3 (12V), J17.A1 (12V), J17.A2 (12V), J17.B1 (12V), J17.B2 (12V), J17.B3 (12V) | m2-nvme, power-bucks, power-input |
| `+3V3` | **global** | R60.1, R61.1, R62.1, R63.1, R64.1, R65.1, R66.1, R67.1 | cm5, power-bucks, usb3-hub-A, usb3-hub-B |
| `5V_HDD` | **global** | J10.A8 (5V), J10.A9 (5V), J10.B8 (5V), J10.B9 (5V), J10.B10 (5V), J11.A8 (5V), J11.A9 (5V), J11.B8 (5V), J11.B9 (5V), J11.B10 (5V), J12.A8 (5V), J12.A9 (5V), J12.B8 (5V), J12.B9 (5V), J12.B10 (5V), J13.A8 (5V), J13.A9 (5V), J13.B8 (5V), J13.B9 (5V), J13.B10 (5V), J14.A8 (5V), J14.A9 (5V), J14.B8 (5V), J14.B9 (5V), J14.B10 (5V), J15.A8 (5V), J15.A9 (5V), J15.B8 (5V), J15.B9 (5V), J15.B10 (5V), J16.A8 (5V), J16.A9 (5V), J16.B8 (5V), J16.B9 (5V), J16.B10 (5V), J17.A8 (5V), J17.A9 (5V), J17.B8 (5V), J17.B9 (5V), J17.B10 (5V) | power-bucks |

### No connect

* J10: A5 (NC), A6 (NC)
* J11: A5 (NC), A6 (NC)
* J12: A5 (NC), A6 (NC)
* J13: A5 (NC), A6 (NC)
* J14: A5 (NC), A6 (NC)
* J15: A5 (NC), A6 (NC)
* J16: A5 (NC), A6 (NC)
* J17: A5 (NC), A6 (NC)

### Notes

* Bay slots are PCI Express x1 sockets used with the bay-card pinout (symgen SLOT_PINS), not PCIe signalling. Five contacts each for 12 V and 5 V (about 1 A per contact), grounds beside every pair. v1 populates cards in slots 1-4; slots 5-8 take cards later (bigger brick, D9).
* The bay LED sits on the brain (lid) and is sunk by the card's bridge LED pin through B6.

## Sheet `m2-nvme` — Bay 9: M.2 M-key on PCIe Gen3 x1, 3V3_M2 buck + load switch, lid switch

### Components

| Ref | Symbol | Value | Footprint | Note |
|---|---|---|---|---|
| C500 | `Device:C` | 10u 10V | `Capacitor_SMD:C_0805_2012Metric` |  |
| C501 | `Device:C` | 22u 10V | `Capacitor_SMD:C_0805_2012Metric` |  |
| C502 | `Device:C` | 1n | `Capacitor_SMD:C_0402_1005Metric` | CT slew |
| C5100 | `Device:C` | 10u 25V | `Capacitor_SMD:C_1210_3225Metric` |  |
| C5101 | `Device:C` | 100n 10V | `Capacitor_SMD:C_0402_1005Metric` | BST |
| C5102 | `Device:C` | 22u 10V | `Capacitor_SMD:C_0805_2012Metric` |  |
| C5103 | `Device:C` | 22u 10V | `Capacitor_SMD:C_0805_2012Metric` |  |
| D50 | `Device:LED` | blue M.2 activity | `LED_THT:LED_D3.0mm` |  |
| J50 | `brain-drain:M2_MKEY` | M.2 M-key | `brain-drain:M2_Socket3_MKey_CM5IO` |  |
| L51 | `Device:L` | 4.7u 3A | `Inductor_SMD:L_Taiyo-Yuden_NR-40xx` |  |
| M1 (unit 4) | `brain-drain:CM5` | CM5002016 | `brain-drain:Raspberry-Pi-5-Compute-Module` |  |
| R500 | `Device:R` | 10k | `Resistor_SMD:R_0402_1005Metric` | M2_PWR_EN pull-down |
| R501 | `Device:R` | 10k | `Resistor_SMD:R_0402_1005Metric` | PEDET pull-up |
| R502 | `Device:R` | 0R (cap DNP alt) | `Capacitor_SMD:C_0402_1005Metric` | PERp0 series: 0R populated, 100n alternative |
| R503 | `Device:R` | 0R (cap DNP alt) | `Capacitor_SMD:C_0402_1005Metric` | PERn0 series: 0R populated, 100n alternative |
| R504 | `Device:R` | 10k | `Resistor_SMD:R_0402_1005Metric` | CLKREQ# pull-up |
| R505 | `Device:R` | 470 | `Resistor_SMD:R_0402_1005Metric` |  |
| SW3 | `Switch:SW_Push` | lid microswitch | `Button_Switch_THT:SW_PUSH_6mm` |  |
| U50 | `brain-drain:TPS22965` | TPS22965DSGR | `Package_SON:Texas_DSG0008A_WSON-8-1EP_2x2mm_P0.5mm_EP0.9x1.6mm` |  |
| U51 | `Regulator_Switching:AP63203WU` | AP63203WU-7 | `Package_TO_SOT_SMD:TSOT-23-6` |  |

### Nets

| Net | Scope | Pins on this sheet | Also on |
|---|---|---|---|
| `GND` | **global** | U51.4 (GND), C5100.2, C5102.2, C5103.2, U50.5 (GND), U50.9 (EP), C500.2, C501.2, C502.2, R500.2, J50.3 (GND), J50.9 (GND), J50.15 (GND), J50.27 (GND), J50.33 (GND), J50.39 (GND), J50.45 (GND), J50.51 (GND), J50.57 (GND), J50.71 (GND), J50.73 (GND), SW3.2, J50.S1 (SHIELD1), J50.S2 (SHIELD2), J50.M3 (GND2260), J50.M4 (GND2280) | bay-slots, cm5, power-bucks, power-input, usb3-hub-A, usb3-hub-B |
| `M2_DAS` | local | D50.1 (K), J50.10 (DAS/DSS#) |  |
| `M2_DOOR` | **global** | SW3.1 | cm5 |
| `M2_LED_A` | local | R505.2, D50.2 (A) |  |
| `M2_PEDET` | **global** | J50.69 (CONFIG_1/PEDET), R501.2 | cm5 |
| `M2_PERn0` | local | J50.41 (PERn0), R503.1 |  |
| `M2_PERp0` | local | J50.43 (PERp0), R502.1 |  |
| `M2_PWR_EN` | **global** | U50.3 (ON), R500.1 | cm5 |
| `PCIE_CLKREQ` | local | M1.102 (PCIe_CLK_nREQ), J50.52 (CLKREQ#), R504.2 |  |
| `PCIE_CLK_N` | local | M1.112 (PCIe_CLK_N), J50.53 (REFCLKn) |  |
| `PCIE_CLK_P` | local | M1.110 (PCIe_CLK_P), J50.55 (REFCLKp) |  |
| `PCIE_RX_N` | local | R503.2, M1.118 (PCIe_RX_N) |  |
| `PCIE_RX_P` | local | R502.2, M1.116 (PCIe_RX_P) |  |
| `PCIE_TX_N` | local | M1.124 (PCIe_TX_N), J50.47 (PETn0) |  |
| `PCIE_TX_P` | local | M1.122 (PCIe_TX_P), J50.49 (PETp0) |  |
| `PCIE_nRST` | local | M1.109 (PCIe_nRST), J50.50 (PERST#) |  |
| `PCIE_nWAKE` | local | M1.104 (PCIE_nWAKE), J50.54 (PEWAKE#) |  |
| `U50_CT` | local | U50.6 (CT), C502.1 |  |
| `U51_BST` | local | U51.6 (BST), C5101.1 |  |
| `U51_SW` | local | U51.5 (SW), L51.1, C5101.2 |  |
| `USB2_DM` | **global** | M1.103 (USB_N) | cm5 |
| `USB2_DP` | **global** | M1.105 (USB_P) | cm5 |
| `USB3_0_DM` | **global** | M1.136 (USB3-0-DM) | usb3-hub-A |
| `USB3_0_DP` | **global** | M1.134 (USB3-0-DP) | usb3-hub-A |
| `USB3_0_RX_N` | **global** | M1.128 (USB3-0-RX_N) | usb3-hub-A |
| `USB3_0_RX_P` | **global** | M1.130 (USB3-0-RX_P) | usb3-hub-A |
| `USB3_0_TX_N` | **global** | M1.140 (USB3-0-TX_N) | usb3-hub-A |
| `USB3_0_TX_P` | **global** | M1.142 (USB3-0-TX_P) | usb3-hub-A |
| `USB3_1_DM` | **global** | M1.165 (USB3-1-DM) | usb3-hub-B |
| `USB3_1_DP` | **global** | M1.163 (USB3-1-DP) | usb3-hub-B |
| `USB3_1_RX_N` | **global** | M1.157 (USB3-1-RX_N) | usb3-hub-B |
| `USB3_1_RX_P` | **global** | M1.159 (USB3-1-RX_P) | usb3-hub-B |
| `USB3_1_TX_N` | **global** | M1.169 (USB3-1-TX_N) | usb3-hub-B |
| `USB3_1_TX_P` | **global** | M1.171 (USB3-1-TX_P) | usb3-hub-B |
| `+12V` | **global** | U51.3 (IN), C5100.1, U51.2 (EN) | bay-slots, power-bucks, power-input |
| `3V3_M2` | **global** | L51.2, C5102.1, C5103.1, U51.1 (FB), U50.1 (VIN), U50.2 (VIN), U50.4 (VBIAS), C500.1 |  |
| `3V3_M2_SW` | **global** | U50.8 (VOUT), U50.7 (VOUT), C501.1, J50.2 (3V3), J50.4 (3V3), J50.12 (3V3), J50.14 (3V3), J50.16 (3V3), J50.18 (3V3), J50.70 (3V3), J50.72 (3V3), J50.74 (3V3), R501.1, R504.1, R505.1 |  |

### No connect

* J50: 1 (CONFIG_3), 11 (PETn3), 13 (PETp3), 17 (PERn2), 19 (PERp2), 20 (NC), 21 (CONFIG_0), 22 (NC), 23 (PETn2), 24 (NC), 25 (PETp2), 26 (NC), 28 (NC), 29 (PERn1), 30 (NC), 31 (PERp1), 32 (NC), 34 (NC), 35 (PETn1), 36 (NC), 37 (PETp1), 38 (DEVSLP), 40 (NC), 42 (NC), 44 (NC), 46 (NC), 48 (NC), 5 (PERn3), 50 (PERST#), 56 (MFG1), 58 (MFG2), 6 (NC), 67 (NC), 68 (SUSCLK), 7 (PERp3), 75 (CONFIG_2), 8 (NC)
* M1: 101 (USB_OTG_ID), 106 (PCIE_PWR_EN), 111 (VBUS_EN)

### Notes

* Polarity: CM5 TX_P -> PETp0 (49), TX_N -> PETn0 (47), PERp0 (43) -> RX_P, PERn0 (41) -> RX_N. The CM5IO reference wires both pairs inverted (TX_P to 47, RX_P to 41), which PCIe link training tolerates; either works.
* Only PCIe lane 0 is wired (x1). PET = host transmit (CM5 TX, AC caps on the module). PER = host receive: per the M.2 spec the SSD carries its own TX caps, so R502/R503 are 0R; the same 0402 pads take 100n if a module without caps turns up.
* PEDET (pin 69) is pulled up and read by GPIO19: an M.2 SATA module grounds it, and the software refuses the bay instead of trying PCIe.
* Door switch SW3 to GPIO4 (software pull-up): closed = low = door shut. Software powers the slot (M2_PWR_EN, GPIO27 -> U50) and rescans PCIe.

## Power flags

Add a PWR_FLAG to each of these nets (they are driven by connectors or passive parts): `+12V`, `+1V2`, `+3V3`, `3V3_M2`, `3V3_M2_SW`, `5V_HDD`, `5V_SYS`, `GND`, `SD_VDD`, `VIN_12V_RAW`

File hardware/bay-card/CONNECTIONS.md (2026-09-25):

# brain-drain bay card: ASM1153E USB-SATA bridge, switched 12 V / 5 V, 22-pin SATA receptacle — connection list

Generated from `hardware/tools/design.py`; do not edit by hand. One table per sheet: every
component with its symbol, value and footprint, then every net on that sheet with the pins
it joins. Nets marked **global** continue on other sheets. Pins listed under *No connect*
get an explicit no-connect flag.

Totals: 39 components, 37 nets.

## Sheet `bridge` — ASM1153E USB 3 to SATA bridge, 30 MHz crystal, core switcher, AC coupling

### Components

| Ref | Symbol | Value | Footprint | Note |
|---|---|---|---|---|
| C1 | `Device:C` | 22p | `Capacitor_SMD:C_0402_1005Metric` |  |
| C2 | `Device:C` | 22p | `Capacitor_SMD:C_0402_1005Metric` |  |
| C3 | `Device:C` | 2.2u | `Capacitor_SMD:C_0603_1608Metric` | RST# delay |
| C4 | `Device:C` | 10u 10V | `Capacitor_SMD:C_0805_2012Metric` | core rail |
| C5 | `Device:C` | 10u 10V | `Capacitor_SMD:C_0805_2012Metric` | VCCIN bypass |
| C6 | `Device:C` | 10u 10V | `Capacitor_SMD:C_0805_2012Metric` | VCCO 3.3 V out |
| C7 | `Device:C` | 100n | `Capacitor_SMD:C_0402_1005Metric` |  |
| C8 | `Device:C` | 100n | `Capacitor_SMD:C_0402_1005Metric` |  |
| C9 | `Device:C` | 100n | `Capacitor_SMD:C_0402_1005Metric` |  |
| C10 | `Device:C` | 100n | `Capacitor_SMD:C_0402_1005Metric` |  |
| C11 | `Device:C` | 100n | `Capacitor_SMD:C_0402_1005Metric` |  |
| C12 | `Device:C` | 100n | `Capacitor_SMD:C_0402_1005Metric` |  |
| C13 | `Device:C` | 100n | `Capacitor_SMD:C_0402_1005Metric` | USB3 TX AC coupling |
| C14 | `Device:C` | 100n | `Capacitor_SMD:C_0402_1005Metric` | USB3 TX AC coupling |
| C15 | `Device:C` | 10n | `Capacitor_SMD:C_0402_1005Metric` | SATA TX+ AC coupling |
| C16 | `Device:C` | 10n | `Capacitor_SMD:C_0402_1005Metric` | SATA TX- AC coupling |
| C17 | `Device:C` | 10n | `Capacitor_SMD:C_0402_1005Metric` | SATA RX+ AC coupling |
| C18 | `Device:C` | 10n | `Capacitor_SMD:C_0402_1005Metric` | SATA RX- AC coupling |
| L1 | `Device:L` | 4.7u 1A | `Inductor_SMD:L_Taiyo-Yuden_NR-40xx` | core switcher inductor (value per ASMedia reference design, verify) |
| R1 | `Device:R` | 12.1k 1% | `Resistor_SMD:R_0402_1005Metric` | REXT |
| R2 | `Device:R` | 10k | `Resistor_SMD:R_0402_1005Metric` | RST# pull-up |
| U1 | `brain-drain:ASM1153E` | ASM1153E | `Package_DFN_QFN:QFN-48-1EP_6x6mm_P0.4mm_EP4.6x4.6mm` |  |
| Y1 | `Device:Crystal_GND24` | 30MHz CL=16pF | `Crystal:Crystal_SMD_3225-4Pin_3.2x2.5mm` |  |

### Nets

| Net | Scope | Pins on this sheet | Also on |
|---|---|---|---|
| `GND` | **global** | U1.47 (PGND), U1.21 (GNDA), U1.31 (GNDA), U1.49 (GND), U1.42 (TEST_EN), R1.2, C3.2, Y1.2 (G), Y1.4 (G), C1.2, C2.2, C4.2, C5.2, C6.2, C7.2, C8.2, C9.2, C10.2, C11.2, C12.2 | bay-switch, edge |
| `LED_K` | **global** | U1.43 (GPIO0) | edge |
| `SATA_A_N` | **global** | C16.2 | edge |
| `SATA_A_P` | **global** | C15.2 | edge |
| `SATA_B_N` | **global** | C18.1 | edge |
| `SATA_B_P` | **global** | C17.1 | edge |
| `U1_LXI` | local | U1.48 (LXI), L1.1 |  |
| `U1_REXT` | local | U1.17 (REXT), R1.1 |  |
| `U1_RST` | local | U1.38 (RST#), R2.2, C3.1 |  |
| `U1_SRXN` | local | C18.2, U1.30 (SRXN) |  |
| `U1_SRXP` | local | C17.2, U1.29 (SRXP) |  |
| `U1_STXN` | local | U1.32 (STXN), C16.1 |  |
| `U1_STXP` | local | U1.33 (STXP), C15.1 |  |
| `U1_UTXN` | local | U1.19 (UTXN), C14.1 |  |
| `U1_UTXP` | local | U1.20 (UTXP), C13.1 |  |
| `U1_VCCO` | local | U1.12 (VCCO), C6.1, U1.4 (VCC), U1.39 (VCC), U1.14 (VCCU), U1.18 (VCCU), U1.34 (VCCS), U1.27 (VCCTXL), C9.1, C10.1, C11.1, C12.1, R2.1 |  |
| `U1_VDD_CORE` | **global** | L1.2, C4.1, U1.7 (VDD), U1.36 (VDD), U1.46 (VDD), U1.13 (VDDU), U1.24 (VDDU), U1.28 (VDDS), C7.1, C8.1 |  |
| `U1_XI` | local | U1.25 (XI), Y1.1, C1.1 |  |
| `U1_XO` | local | U1.26 (XO), Y1.3, C2.1 |  |
| `USB2_DM` | **global** | U1.16 (UDM) | edge |
| `USB2_DP` | **global** | U1.15 (UDP) | edge |
| `USB3_RX_N` | **global** | U1.22 (URXN) | edge |
| `USB3_RX_P` | **global** | U1.23 (URXP) | edge |
| `USB3_TX_N` | **global** | C14.2 | edge |
| `USB3_TX_P` | **global** | C13.2 | edge |
| `5V_HDD` | **global** | U1.10 (VBUS), U1.11 (VBUS_LDO), U1.1 (VCCIN), C5.1 | bay-switch, edge |

### No connect

* U1: 2 (I2C_DATA), 3 (I2C_CLK), 35 (GPIO7), 37 (GPIO6), 40 (UART_RX), 41 (UART_TX), 44 (GPIO1), 45 (HDDPC), 5 (GPIO5), 6 (GPIO4), 8 (GPIO3), 9 (GPIO2)

### Notes

* ASM1153E runs from 5 V only (the brain's always-on 5V_HDD rail through the edge): VBUS_LDO -> VCCO (3.3 V) and VCCIN -> LXI switcher -> 1.05 V core.
* Clock straps GPIO3/GPIO7 at their internal pull-up default (11) = 30 MHz crystal. GPIO6 default = I2C mode, no SPI ROM. Bay activity LED assumed on GPIO0 (verify on the bench); it sinks the brain's LED through the edge.

## Sheet `bay-switch` — Switched 12 V and 5 V for the drive: P-FET high-side switches with soft-start, PTC fuses

### Components

| Ref | Symbol | Value | Footprint | Note |
|---|---|---|---|---|
| C19 | `Device:C` | 100n | `Capacitor_SMD:C_0402_1005Metric` | soft-start G-S |
| C20 | `Device:C` | 100n | `Capacitor_SMD:C_0402_1005Metric` | soft-start G-S |
| F1 | `Device:Polyfuse` | 3A hold 1812 | `Fuse:Fuse_1812_4532Metric` |  |
| F2 | `Device:Polyfuse` | 2A hold 1812 | `Fuse:Fuse_1812_4532Metric` |  |
| Q1 | `brain-drain:PMOS_SSSGDDDD_EP` | AON7403 | `Package_DFN_QFN:DFN-8-1EP_3x3mm_P0.65mm_EP1.5x2.25mm` | 12 V switch (AOS AON7403, -30 V, DFN 3x3-8); DFN 3x3-8 power pin-out S 1-3, G 4, D 5-8 + EP |
| Q2 | `brain-drain:PMOS_SSSGDDDD_EP` | AON7403 | `Package_DFN_QFN:DFN-8-1EP_3x3mm_P0.65mm_EP1.5x2.25mm` | 5 V switch (AOS AON7403); same pin-out |
| Q3 | `Transistor_FET:2N7002` | 2N7002 | `Package_TO_SOT_SMD:SOT-23` | 12 V gate driver |
| Q4 | `Transistor_FET:2N7002` | 2N7002 | `Package_TO_SOT_SMD:SOT-23` | 5 V gate driver |
| R3 | `Device:R` | 100k | `Resistor_SMD:R_0402_1005Metric` | Q1 gate pull-up (off) |
| R4 | `Device:R` | 10k | `Resistor_SMD:R_0402_1005Metric` | soft-start series |
| R5 | `Device:R` | 100k | `Resistor_SMD:R_0402_1005Metric` | Q2 gate pull-up (off) |
| R6 | `Device:R` | 10k | `Resistor_SMD:R_0402_1005Metric` | soft-start series |
| R7 | `Device:R` | 10k | `Resistor_SMD:R_0402_1005Metric` | BAY_EN pull-down: off at boot and with the slot empty |
| R8 | `Device:R` | 1k | `Resistor_SMD:R_0402_1005Metric` |  |

### Nets

| Net | Scope | Pins on this sheet | Also on |
|---|---|---|---|
| `BAY_EN` | **global** | R8.1, R7.1 | edge |
| `EN_G` | local | R8.2, Q3.1 (G), Q4.1 (G) |  |
| `GND` | **global** | R7.2, Q3.2 (S), Q4.2 (S) | bridge, edge |
| `Q1_G` | local | Q1.4 (G), R3.2, C19.2, R4.1 |  |
| `Q2_G` | local | Q2.4 (G), R5.2, C20.2, R6.1 |  |
| `Q3_D` | local | R4.2, Q3.3 (D) |  |
| `Q4_D` | local | R6.2, Q4.3 (D) |  |
| `+12V` | **global** | Q1.1 (S), Q1.2 (S), Q1.3 (S), R3.1, C19.1 | edge |
| `12V_BAY` | **global** | F1.2 | edge |
| `12V_BAY_SW` | local | Q1.5 (D), Q1.6 (D), Q1.7 (D), Q1.8 (D), Q1.9 (D), F1.1 |  |
| `5V_BAY` | **global** | F2.2 | edge |
| `5V_BAY_SW` | local | Q2.5 (D), Q2.6 (D), Q2.7 (D), Q2.8 (D), Q2.9 (D), F2.1 |  |
| `5V_HDD` | **global** | Q2.1 (S), Q2.2 (S), Q2.3 (S), R5.1, C20.1 | bridge, edge |

### Notes

* P-FET high-side switch: 100k gate pull-up holds it off; the 2N7002 pulls the gate down through 10k with 100n gate-source, ~1 ms ramp so the drive's bulk caps do not trip the fuse. BAY_EN pull-down keeps the bay off through boot.

## Sheet `edge` — Card edge to the brain (PCIe x1 fingers, bay-card pinout) and the SATA 22-pin receptacle

### Components

| Ref | Symbol | Value | Footprint | Note |
|---|---|---|---|---|
| J1 | `brain-drain:BAY_EDGE` | bay card edge | `Connector_PCBEdge:BUS_PCIexpress_x1` |  |
| J2 | `brain-drain:SATA22` | SATA 22-pin | `brain-drain:SATA_22pin_Receptacle_RA` |  |
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

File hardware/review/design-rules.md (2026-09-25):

# Design rules, stack-up, planes and keep-outs

Generated by `hardware/tools/make_review_pack.py` from the boards as they are now.

## brain: net classes

| class | track mm | clearance mm | via / drill mm | diff pair width / gap mm |
|---|---|---|---|---|
| Default | 0.13 | 0.125 | 0.45 / 0.2 |  /  |
| Bay | 0.2 | 0.125 | 0.45 / 0.2 |  /  |
| DiffPair90 | 0.147 | 0.125 | 0.45 / 0.2 | 0.147 / 0.253 |
| Power | 0.3 | 0.125 | 0.6 / 0.3 |  /  |

Board limits (`.kicad_pro`, written by `route.py prepare`):

* `min_clearance` = 0.125
* `min_copper_edge_clearance` = 0.3
* `min_hole_clearance` = 0.2
* `min_hole_to_hole` = 0.25
* `min_microvia_diameter` = 0.2
* `min_microvia_drill` = 0.1
* `min_resolved_spokes` = 2
* `min_text_height` = 0.8
* `min_text_thickness` = 0.08
* `min_through_hole_diameter` = 0.15
* `min_track_width` = 0.1
* `min_via_annular_width` = 0.075
* `min_via_diameter` = 0.3
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

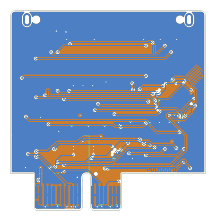
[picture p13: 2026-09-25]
hardware/bay-card/renders/board-inner.png

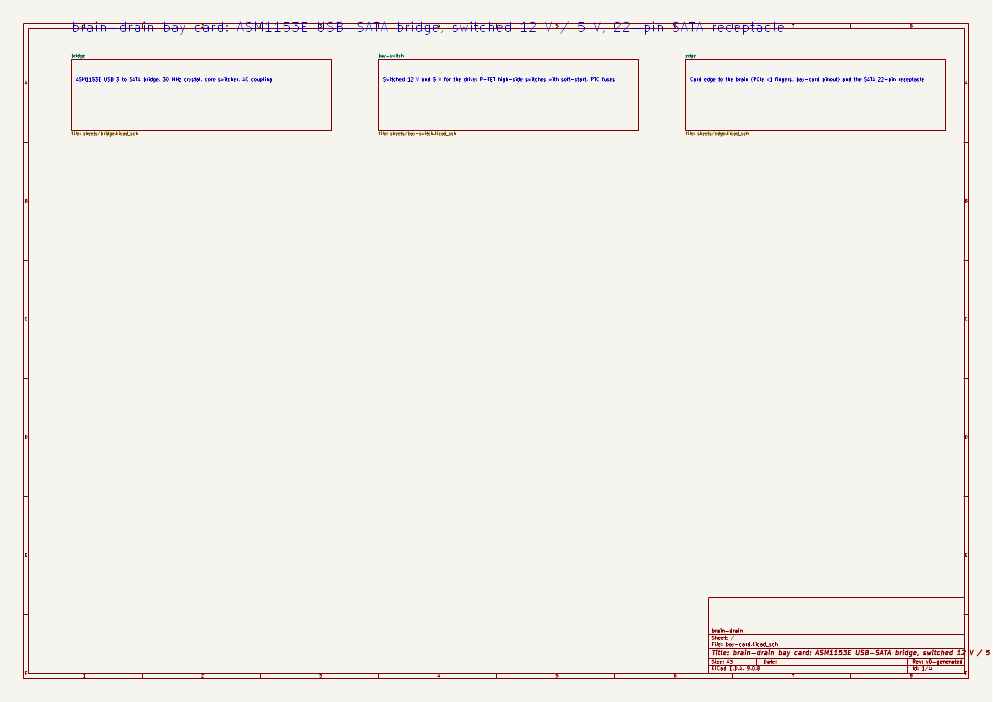
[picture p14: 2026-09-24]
hardware/bay-card/renders/schematic/sheet-1.png

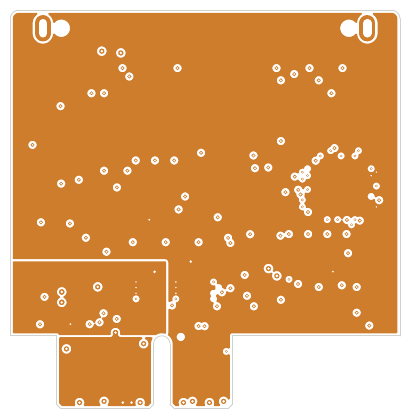
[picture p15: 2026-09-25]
hardware/bay-card/renders/layers/In2.Cu.png

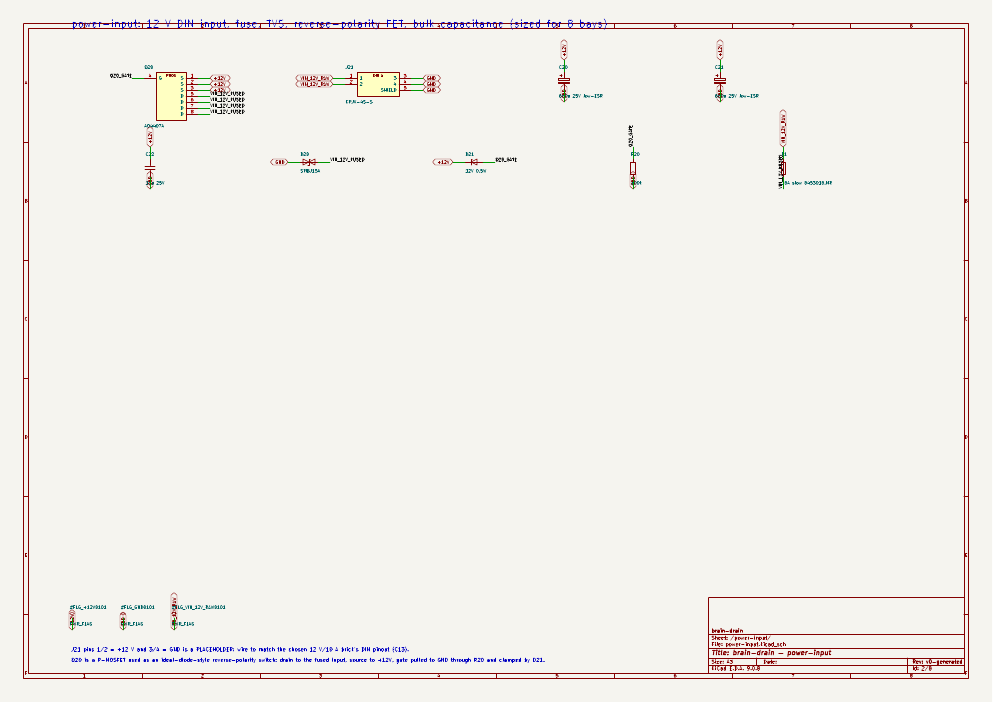
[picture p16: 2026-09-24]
hardware/renders/schematic/sheet-2.png

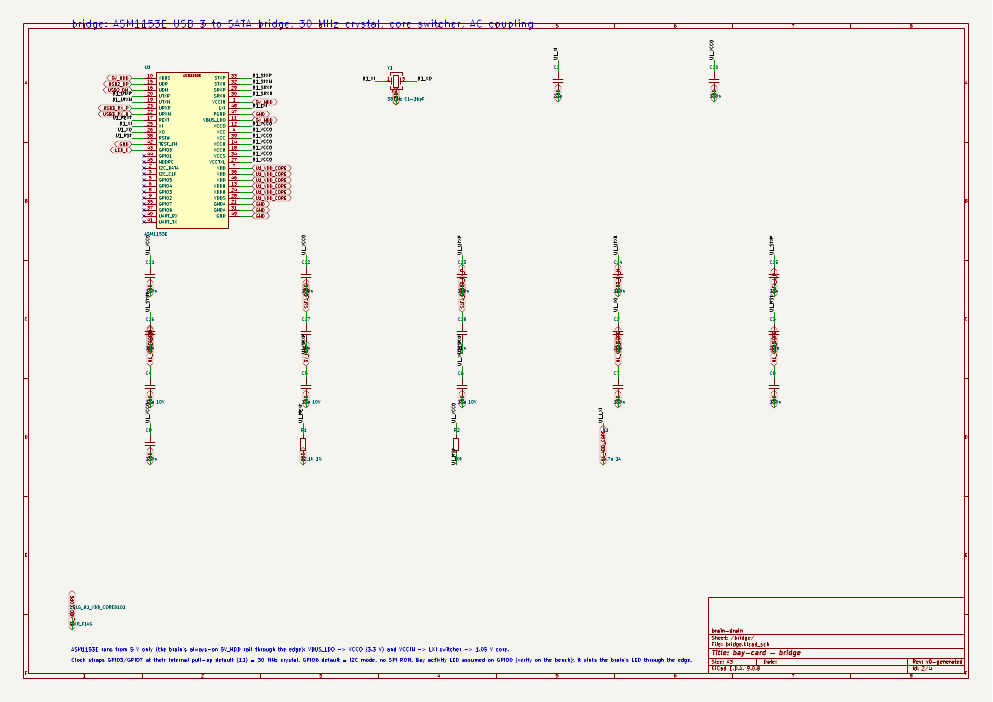
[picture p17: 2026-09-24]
hardware/bay-card/renders/schematic/sheet-2.png

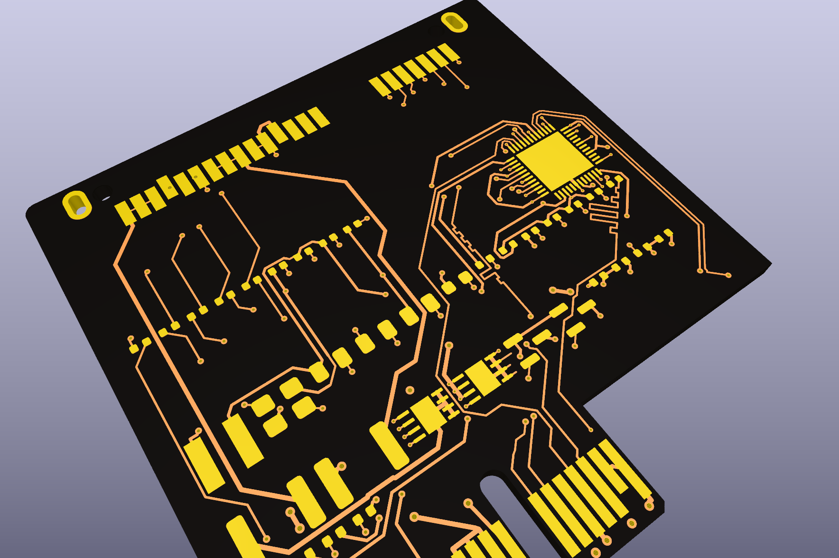
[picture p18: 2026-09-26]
hardware/bay-card/renders/board-3d-iso.png

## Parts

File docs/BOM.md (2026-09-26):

# brain-drain: bill of materials

Quantities are per board; the unit has one brain board and four to eight bay cards. Machine-readable copies: `hardware/bom/brain-drain-bom.csv` and `hardware/bom/bay-card-bom.csv` (both regenerated by `python3 hardware/tools/gen_bom.py`).
Vendors and prices are budgeting figures from 2026 (LCSC, Digi-Key, Mouser), not quotes.

<!-- GENERATED by hardware/tools/gen_bom.py from hardware/tools/design.py: do not edit between the markers -->

## Brain board (163 parts, about $134 of parts without the board itself)

| Refs | Qty | Value | Footprint | Part | Description | ~USD | Check |
|---|---|---|---|---|---|---|---|
| BT1 | 1 | CR2032 | BatteryHolder_Keystone_1060_1x2032 | Keystone 1060 | CR2032 SMD holder (cell bought separately, about 0.5) | 0.90 | verify |
| C1,C2,C501,C2003,C2004,C2005,C2103,C2104,C2105,C2202,C220... | 13 | 22u 10V | C_0805_2012Metric | generic | 22 uF X5R 10 V 0805 | 1.04 |  |
| C3,C31,C500 | 3 | 10u 10V | C_0805_2012Metric | generic | 10 uF X5R 10 V 0805 | 0.15 |  |
| C4,C30 | 2 | 1u 10V | C_0402_1005Metric | generic | 1 uF X5R 10 V 0402 | 0.04 |  |
| C20,C21 | 2 | 680u 25V low-ESR | CP_Elec_10x10.5 | generic | 680 uF 25 V low-ESR aluminium polymer or electrolytic, 10 x 10.5 mm SMD (spin-up bulk) | 1.80 | verify |
| C22,C2000,C2001,C2100,C2101,C2200,C5100 | 7 | 10u 25V | C_1210_3225Metric | generic | 10 uF X5R 25 V 1210 (input and 5 V bulk) | 0.84 |  |
| C100,C101,C200,C201 | 4 | 33p | C_0402_1005Metric | generic | 33 pF C0G 50 V 0402 (crystal load) | 0.04 |  |
| C110,C111,C112,C113,C120,C121,C122,C123,C140,C141,C151,C1... | 36 | 100n | C_0402_1005Metric | generic | 100 nF X7R 16 V or better, 0402 | 0.36 |  |
| C130,C131,C230,C231 | 4 | 4.7u 10V | C_0603_1608Metric | generic | 4.7 uF X5R 10 V 0603 | 0.16 |  |
| C502 | 1 | 1n | C_0402_1005Metric | generic | 1 nF C0G 50 V 0402 | 0.01 |  |
| C2002,C2102 | 2 | 100n 25V | C_0402_1005Metric | generic | 100 nF X7R 16 V or better, 0402 | 0.02 |  |
| C2201,C5101 | 2 | 100n 10V | C_0402_1005Metric | generic | 100 nF X7R 16 V or better, 0402 | 0.02 |  |
| D1 | 1 | green PWR | LED_D3.0mm | generic | 3 mm through-hole LED, colour as listed, 2 V forward, about 5 mA | 0.10 |  |
| D2 | 1 | green ACT | LED_D3.0mm | generic | 3 mm through-hole LED, colour as listed, 2 V forward, about 5 mA | 0.10 |  |
| D3 | 1 | red STATUS | LED_D3.0mm | generic | 3 mm through-hole LED, colour as listed, 2 V forward, about 5 mA | 0.10 |  |
| D10 | 1 | blue bay 1 activity | LED_D3.0mm | generic | 3 mm through-hole LED, colour as listed, 2 V forward, about 5 mA | 0.10 |  |
| D11 | 1 | blue bay 2 activity | LED_D3.0mm | generic | 3 mm through-hole LED, colour as listed, 2 V forward, about 5 mA | 0.10 |  |
| D12 | 1 | blue bay 3 activity | LED_D3.0mm | generic | 3 mm through-hole LED, colour as listed, 2 V forward, about 5 mA | 0.10 |  |
| D13 | 1 | blue bay 4 activity | LED_D3.0mm | generic | 3 mm through-hole LED, colour as listed, 2 V forward, about 5 mA | 0.10 |  |
| D14 | 1 | blue bay 5 activity | LED_D3.0mm | generic | 3 mm through-hole LED, colour as listed, 2 V forward, about 5 mA | 0.10 |  |
| D15 | 1 | blue bay 6 activity | LED_D3.0mm | generic | 3 mm through-hole LED, colour as listed, 2 V forward, about 5 mA | 0.10 |  |
| D16 | 1 | blue bay 7 activity | LED_D3.0mm | generic | 3 mm through-hole LED, colour as listed, 2 V forward, about 5 mA | 0.10 |  |
| D17 | 1 | blue bay 8 activity | LED_D3.0mm | generic | 3 mm through-hole LED, colour as listed, 2 V forward, about 5 mA | 0.10 |  |
| D20 | 1 | SMBJ15A | D_SMB | Littelfuse SMBJ15A | TVS diode 15 V standoff, SMB | 0.35 |  |
| D21 | 1 | 12V 0.5W | D_SOD-123 | generic | 12 V 0.5 W zener, SOD-123 (BZT52C12 class) | 0.05 |  |
| D50 | 1 | blue M.2 activity | LED_D3.0mm | generic | 3 mm through-hole LED, colour as listed, 2 V forward, about 5 mA | 0.10 |  |
| F1 | 1 | 15A slow 0453015.MR | Fuse_Littelfuse-NANO2-451_453 | Littelfuse 0453015.MR | NANO2 15 A slow-blow fuse (C31; check the 15 A rating in stock) | 0.80 | verify |
| J3 | 1 | microSD | microSD_HC_Hirose_DM3AT-SF-PEJM5 | Hirose DM3AT-SF-PEJM5 | microSD push-push socket | 1.00 | verify |
| J5 | 1 | USB-C rpiboot | USB_C_Receptacle_GCT_USB4085 | GCT USB4085-GF-A | USB-C 16-pin receptacle, USB 2.0 only | 1.00 |  |
| J6 | 1 | nRPIBOOT | PinHeader_1x02_P2.54mm_Vertical | generic | 2.54 mm pin header, vertical, count as listed | 0.10 |  |
| J7 | 1 | UART0 GND/TX/RX | PinHeader_1x03_P2.54mm_Vertical | generic | 2.54 mm pin header, vertical, count as listed | 0.10 |  |
| J10 | 1 | bay slot 1 | PCIe_x1_Socket_THT | Amphenol FCI 10018783-10100TLF | PCI Express x1 vertical through-hole socket, 36 contacts (custom bay pinout, no PCIe signalling) | 1.00 | verify |
| J11 | 1 | bay slot 2 | PCIe_x1_Socket_THT | Amphenol FCI 10018783-10100TLF | PCI Express x1 vertical through-hole socket, 36 contacts (custom bay pinout, no PCIe signalling) | 1.00 | verify |
| J12 | 1 | bay slot 3 | PCIe_x1_Socket_THT | Amphenol FCI 10018783-10100TLF | PCI Express x1 vertical through-hole socket, 36 contacts (custom bay pinout, no PCIe signalling) | 1.00 | verify |
| J13 | 1 | bay slot 4 | PCIe_x1_Socket_THT | Amphenol FCI 10018783-10100TLF | PCI Express x1 vertical through-hole socket, 36 contacts (custom bay pinout, no PCIe signalling) | 1.00 | verify |
| J14 | 1 | bay slot 5 | PCIe_x1_Socket_THT | Amphenol FCI 10018783-10100TLF | PCI Express x1 vertical through-hole socket, 36 contacts (custom bay pinout, no PCIe signalling) | 1.00 | verify |
| J15 | 1 | bay slot 6 | PCIe_x1_Socket_THT | Amphenol FCI 10018783-10100TLF | PCI Express x1 vertical through-hole socket, 36 contacts (custom bay pinout, no PCIe signalling) | 1.00 | verify |
| J16 | 1 | bay slot 7 | PCIe_x1_Socket_THT | Amphenol FCI 10018783-10100TLF | PCI Express x1 vertical through-hole socket, 36 contacts (custom bay pinout, no PCIe signalling) | 1.00 | verify |
| J17 | 1 | bay slot 8 | PCIe_x1_Socket_THT | Amphenol FCI 10018783-10100TLF | PCI Express x1 vertical through-hole socket, 36 contacts (custom bay pinout, no PCIe signalling) | 1.00 | verify |
| J21 | 1 | KPJX-4S-S | Kycon_KPJX-4S-S | Kycon KPJX-4S-S | 4-pin mini-DIN power jack, shielded, 7.5 A per pin | 1.50 |  |
| J40 | 1 | Fan GND/5V/TACH/PWM | FanPinHeader_1x04_P2.54mm_Vertical | generic | 2.54 mm pin header, vertical, count as listed | 0.10 |  |
| J41 | 1 | OLED GND/VCC/SCL/SDA | PinHeader_1x04_P2.54mm_Vertical | generic | 2.54 mm pin header, vertical, count as listed | 0.10 |  |
| J50 | 1 | M.2 M-key | M2_Socket3_MKey_CM5IO | TE Connectivity 2199230-4 | M.2 M-key socket, 4.2 mm, for a 2280 module | 1.20 |  |
| L20,L21 | 2 | 2.2u 8A | L_Taiyo-Yuden_NR-60xx | generic | 2.2 uH, 8 A saturation, shielded, 6 x 6 mm (TPS56637 reference design class) | 1.20 | verify |
| L22,L51 | 2 | 4.7u 3A | L_Taiyo-Yuden_NR-40xx | generic | 4.7 uH, 3 A, shielded, 4 x 4 mm (AP63203 class) | 0.70 | verify |
| M1 | 1 | CM5002016 | Raspberry-Pi-5-Compute-Module | Raspberry Pi CM5102016 | Compute Module 5, wireless, 2 GB RAM, 16 GB eMMC (the schematic value field still reads CM5002016) | 97.00 | verify |
| Q20 | 1 | AO4407A | SOIC-8_3.9x4.9mm_P1.27mm | Alpha & Omega AO4407A | P-MOSFET -30 V, SO-8: S 1-3, G 4, D 5-8 (reverse-polarity protection) | 0.80 |  |
| R1,R2,R3 | 3 | 1k | R_0603_1608Metric | generic | resistor 1 %, thick film (value as listed) | 0.01 |  |
| R10,R11,R101,R102,R201,R202,R500,R501,R504,R2001,R2003,R2... | 13 | 10k | R_0402_1005Metric | generic | resistor 1 %, thick film (value as listed) | 0.07 |  |
| R20 | 1 | 100k | R_0603_1608Metric | generic | resistor 1 %, thick film (value as listed) | 0.01 |  |
| R60,R61,R62,R63,R64,R65,R66,R67,R505 | 9 | 470 | R_0402_1005Metric | generic | resistor 1 %, thick film (value as listed) | 0.04 |  |
| R100,R200 | 2 | 12.0k 1% | R_0402_1005Metric | generic | resistor 1 %, thick film (value as listed) | 0.01 |  |
| R103,R203 | 2 | 200k | R_0402_1005Metric | generic | resistor 1 %, thick film (value as listed) | 0.01 |  |
| R502,R503 | 2 | 0R (cap DNP alt) | C_0402_1005Metric | generic | 0 ohm 0402 (option link, cap DNP alternative) | 0.01 |  |
| R2000,R2100 | 2 | 73.2k | R_0402_1005Metric | generic | resistor 1 %, thick film (value as listed) | 0.01 |  |
| R2002,R2102 | 2 | 100k | R_0402_1005Metric | generic | resistor 1 %, thick film (value as listed) | 0.01 |  |
| SW1 | 1 | DIP x8 | SW_DIP_SPSTx08_Piano_10.8x21.88mm_W7.62mm_P2.54mm | generic | 8-position piano DIP switch, 2.54 mm pitch, 7.62 mm row | 1.00 | verify |
| SW3 | 1 | lid microswitch | SW_PUSH_6mm | generic | 6 mm tactile switch used as the lid switch | 0.20 |  |
| U1,U2 | 2 | USB5744/2G | QFN-56-1EP_7x7mm_P0.4mm_EP3.2x3.2mm | Microchip USB5744/2G | USB 3.2 Gen 1 four-port hub, VQFN-56 7 x 7 | 4.88 |  |
| U3 | 1 | AP2112K-1.2 | SOT-23-5 | Diodes Inc. AP2112K-1.2TRG1 | 600 mA LDO, 1.2 V, SOT-25 (hub core) | 0.30 |  |
| U20,U21 | 2 | TPS56637RPAR | Texas_RPA0010A_VQFN-HR-10_3x3mm | Texas Instruments TPS56637RPAR | 6 A step-down converter, VQFN-HR 3 x 3 | 3.80 |  |
| U22,U51 | 2 | AP63203WU-7 | TSOT-23-6 | Diodes Inc. AP63203WU-7 | 2 A step-down converter, TSOT-26, 3.3 V | 1.00 |  |
| U50,U52 | 2 | TPS22965DSGR | Texas_DSG0008A_WSON-8-1EP_2x2mm_P0.5mm_EP0.9x1.6mm | Texas Instruments TPS22965DSGR | load switch, 4 A, WSON-8 2 x 2 | 1.00 |  |
| Y1,Y2 | 2 | 25MHz CL=20pF | Crystal_SMD_3225-4Pin_3.2x2.5mm | generic | 25 MHz crystal, 3.2 x 2.5 mm, CL 20 pF (hub clock) | 0.60 |  |

## Bay card (39 parts, about $7.78 of parts per card without the board)

| Refs | Qty | Value | Footprint | Part | Description | ~USD | Check |
|---|---|---|---|---|---|---|---|
| C1,C2 | 2 | 22p | C_0402_1005Metric | generic | 22 pF C0G 50 V 0402 (crystal load) | 0.02 |  |
| C3 | 1 | 2.2u | C_0603_1608Metric | generic | 2.2 uF X5R 10 V 0603 | 0.03 |  |
| C4,C5,C6 | 3 | 10u 10V | C_0805_2012Metric | generic | 10 uF X5R 10 V 0805 | 0.15 |  |
| C7,C8,C9,C10,C11,C12,C13,C14,C19,C20 | 10 | 100n | C_0402_1005Metric | generic | 100 nF X7R 16 V or better, 0402 | 0.10 |  |
| C15,C16,C17,C18 | 4 | 10n | C_0402_1005Metric | generic | 10 nF X7R 25 V 0402 (SATA AC coupling) | 0.04 |  |
| F1 | 1 | 3A hold 1812 | Fuse_1812_4532Metric | generic | PTC resettable fuse 1812, 3 A hold (bay 12 V), 15 V or better | 0.30 | verify |
| F2 | 1 | 2A hold 1812 | Fuse_1812_4532Metric | generic | PTC resettable fuse 1812, 2 A hold (bay 5 V), 6 V or better | 0.30 | verify |
| J1 | 1 | bay card edge | BUS_PCIexpress_x1 | (board) | PCI Express x1 card-edge fingers on the card itself, ENIG, chamfered tab | 0.00 |  |
| J2 | 1 | SATA 22-pin | SATA_22pin_Receptacle_RA | Molex 47018-4001 | SATA 22-pin (7+15) host receptacle, top mount, PCB-edge type, tape and reel with cap | 1.50 | verify |
| L1 | 1 | 4.7u 1A | L_Taiyo-Yuden_NR-40xx | generic | 4.7 uH, 1 A, 4 x 4 mm (ASM1153E internal core switcher) | 0.30 | verify |
| Q1,Q2 | 2 | AON7403 | DFN-8-1EP_3x3mm_P0.65mm_EP1.5x2.25mm | Alpha & Omega AON7403 | P-MOSFET -30 V, DFN 3x3-8: S 1-3, G 4, D 5-8 + EP (bay 12 V and 5 V switches) | 1.60 |  |
| Q3,Q4 | 2 | 2N7002 | SOT-23 | generic | N-MOSFET 60 V 2N7002, SOT-23 (gate driver) | 0.10 |  |
| R1 | 1 | 12.1k 1% | R_0402_1005Metric | generic | resistor 1 %, thick film (value as listed) | 0.01 |  |
| R2,R4,R6,R7 | 4 | 10k | R_0402_1005Metric | generic | resistor 1 %, thick film (value as listed) | 0.02 |  |
| R3,R5 | 2 | 100k | R_0402_1005Metric | generic | resistor 1 %, thick film (value as listed) | 0.01 |  |
| R8 | 1 | 1k | R_0402_1005Metric | generic | resistor 1 %, thick film (value as listed) | 0.01 |  |
| U1 | 1 | ASM1153E | QFN-48-1EP_6x6mm_P0.4mm_EP4.6x4.6mm | ASMedia ASM1153E | USB 3.0 to SATA 6G bridge, QFN-48 6 x 6, SAT passthrough | 3.00 | verify |
| Y1 | 1 | 30MHz CL=16pF | Crystal_SMD_3225-4Pin_3.2x2.5mm | generic | 30 MHz crystal, 3.2 x 2.5 mm, CL 16 pF (bridge default clock strap) | 0.30 |  |

## Off-board items per unit

| Item | Qty | ~USD each | Note |
|---|---|---|---|
| Raspberry Pi CM5 cooler (passive) | 1 | 6.00 | presses on the CM5; lid grille above it |
| OLED module 0.96 in 128x64 I2C (SSD1306) | 1 | 3.00 | 4-wire lead to J41, clamped by the printed bezel |
| SATA 22-pin male-to-female extension cable, 0.5 m | 4 | 3.50 | one per populated bay; eight if all slots are used |
| 12 V brick with matching 4-pin DIN, 120 W (four bays) | 1 | 30.00 | 150-180 W with eight bays; DIN pin table decides the J21 wiring (STATUS R3) |
| Heat-set inserts M2.5, feet, screws, hinge pin | 1 | 4.00 | enclosure hardware |
| Enclosure print, PETG or ASA, about 350 g | 1 | 9.00 | home printer; 35-60 from a print service |
| M.2 NVMe SSD 2280 (user's own, not part of the unit) | 0 | 0.00 | the M.2 bay is optional |

## Roll-up per unit (four bay cards fitted)

| | ~USD |
|---|---|
| Brain board parts (without PCB) | 134 |
| Four bay cards, parts (without PCB) | 31 |
| Off-board items | 66 |
| **Parts and accessories** | **231** |

Boards and assembly are priced in [FABRICATION.md](FABRICATION.md). `Check = verify` marks a part whose family is chosen but whose
orderable number, footprint or rating must be confirmed against the datasheet and stock before the order.
<!-- END GENERATED -->

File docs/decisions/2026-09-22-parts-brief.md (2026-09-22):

# Decision brief — hub, bridge, input connector, LEDs, M.2 bay

Prepared 2026-09-22 for dmz. Every fact marked *(ds)* was read from the part's
datasheet this session; prices are LCSC/JLCPCB list from the same day.
Standing rule for this project: dmz makes the decisions; this brief gives the
options, the facts, and a recommendation with its reasoning.

Rule applied throughout, per dmz: **if the spec is the same, prefer the part with
a fully public datasheet.**

---

## 1. USB 3.0 hub (two needed, one per CM5 native USB 3.0 port)

All three candidates are 4-port USB 3.x Gen 1 (5 Gbit/s) hubs with a USB 2.0
hub inside, so the electrical spec that matters to us is the same. Each hub
serves two bays; the other two downstream ports go unused.

| | VIA VL817-Q7 | **Microchip USB5744** | TI TUSB8041 | TI TUSB8044A |
|---|---|---|---|---|
| Datasheet | On request from VIA; LCSC "datasheet" link returns a web page | **Public** (DS00001855M, 51 pp) *(ds)* | **Public** (49 pp) *(ds)* | **Public** (69 pp) *(ds)* |
| Package | QFN-76, 9×9 mm | **56-VQFN, 7×7 mm** *(ds)* | 64-VQFN, 9×9 mm *(ds)* | 64-VQFN, 9×9 mm *(ds)* |
| Supplies | 5 V or 3.3 V in, regulators integrated | 3.3 V + **1.2 V core, external** *(ds Fig. 4-1)* | 3.3 V + 1.1 V core, external *(ds)* | 3.3 V + 1.1 V core, external *(ds)* |
| Config | strap pins | strap pins; optional SPI ROM or OTP; SMBus *(ds)* | strap pins; OTP/EEPROM/SMBus *(ds)* | same |
| KiCad stock symbol | no | no (I generate from the public pinout table) | **yes** | no |
| LCSC price / assembly | ~$2–4, C209756 | **$2.44 (/2G), $3.64 (-I/2G industrial), JLCPCB SMT** | $3.26, C486066 | ~$12 at JLCPCB |
| Track record | ubiquitous in cheap hubs, fine on Linux | common on SBC carriers and industrial boards, fine on Linux | older TI part, fine | newer TI part |

**Recommendation: USB5744.** It meets the public-datasheet rule, is the smallest
and cheapest of the documented parts, and is stocked for JLCPCB assembly. The
cost of choosing it over the VL817 is one extra regulator: a 1.2 V rail at a few
hundred mA, which one AP2112K-1.2 LDO (or a shared 1.2 V LDO for both hubs)
covers for about $0.30. TUSB8041 would be my second choice; it needs the same
kind of extra rail (1.1 V), is a larger package, and its only advantage is the
stock KiCad symbol, which is not worth much when I am generating symbols from
pin tables anyway. TUSB8044A is the same as TUSB8041 for our purposes at four
times the price.

*What changes in the design if you agree:* BOM section B becomes 2× USB5744 +
2× 25 MHz crystal + 1.2 V LDO. Nothing else moves.

## 2. USB→SATA bridge (four needed)

No USB-SATA bridge vendor publishes a datasheet openly; every one of them
(ASMedia, JMicron, VIA, Realtek) treats it as confidential. The difference is
in what is *available*:

| | ASMedia ASM1153E | JMicron JMS578 |
|---|---|---|
| Datasheet | Rev 0.4 copies marked "ASMedia Confidential" on mirror sites (y-ic.com, aliyun). Not fetchable by script, downloadable in a browser | **Rev 1.01, 23 pp, hosted on files.pine64.org**, complete: pin-out, application example, crystal, regulators *(ds)* |
| Package | QFN-48 6×6 | QFN-48 6×6 *(ds)* |
| Supplies | 3.3 V + 1.2 V (per reference designs; unverified) | **single 5 V**: embedded 5 V→1.2 V switcher (needs a 4.7 µH inductor) and 5 V→3.3 V LDO *(ds §2.7)* |
| Crystal | 25 MHz | 30 MHz *(ds)* |
| USB IDs | 174c:55aa / 174c:1153 | 152d:0578 |
| LCSC / JLCPCB | ~$3, C2762919, SMT available | C17700079, SMT available (price listing unclear, expect $2–3) |
| Linux reputation | preferred: UASP + TRIM work with no kernel quirks; many Pi-forum threads recommend it | mixed: early firmware had UASP/TRIM conflicts and spin-down "power cut" issues; fixed in later firmware (173.x) but chips from distributors ship with whatever firmware they have, and JMicron's updater is a Windows tool |
| Sanitize / Security Erase passthrough | unknown for both until measured. Both do ATA PASS-THROUGH (SAT); whether the bridge tolerates a long-running erase is the open question. |

**Recommendation: decide this on Saturday's bench, not on paper.** The two
chips are the same on the spec sheet; the difference is firmware behaviour, and
the one thing that matters for this product, whether `hdparm --sanitize-*`
and `SECURITY ERASE` pass through and survive, is not in either datasheet.
Concretely:

1. Buy two cheap docks or adapter cables, one with each chip. `lsusb` tells you
   which is which (`174c:55aa` ASMedia, `152d:0578` JMicron). Typical: UGREEN
   and StarTech adapters are ASMedia; many "JMicron" ones say so in the listing.
2. I extend `braindrain` with a `bench` command that runs the passthrough tests
   against a sacrificial drive and prints a pass/fail table per chip.
3. The chip that passes is the chip on the board. If both pass, the public
   datasheet rule says JMS578; if only ASMedia passes, we use a mirror copy of
   its datasheet and accept that.

If you would rather decide now: JMS578 satisfies your rule and has the nicer
power story (single 5 V rail), and I would pick it only if you are comfortable
that the firmware on distributor-supplied chips is recent, which we cannot check
until we have one. That is why I prefer the measurement.

## 3. D2 — 12 V input connector

Verified ratings *(ds / distributor pages)*:

| Connector | Rating | Fits our 7.4 A staggered peak? | Notes |
|---|---|---|---|
| Kycon KLDX-0202 barrel, 5.5×2.1/2.5 | 3.5–5 A | **no** | The standard barrel jack. Earlier I guessed the "high-current" KLDHCX was ~11 A; the catalog says **5 A**. Barrels top out around 5 A whatever the listing claims. |
| Kycon KLDHCX-0202-A locking barrel | 5 A | **no** | Same limit, adds a locking collar. |
| **Kycon KPJX-4S-S 4-pin DIN** | **7.5 A per pin, 48 V DC**; two pins each for +12 and GND gives large margin | **yes** | The connector on most 12 V/8–10 A desktop bricks (NAS boxes, LCD monitors). **Pinout differs between brick vendors**, so the brick is chosen first and the footprint wired to match it. |
| Molex Mini-Fit Jr 2×2 (5566/5569) | 9–13 A per pin | yes | Less common on bricks; usually needs a pigtail. |
| XT60 | 30 A | yes | Hobby-grade; no brick ships with it; would need a pigtail. |

**Recommendation: 4-pin DIN only; drop the barrel footprint.** Reasons: the
barrel cannot carry the current the power budget needs, and keeping an
under-rated footprint on the board invites someone to populate it. The DIN is
what 12 V/10 A bricks come with, is rated with margin, and locks. The one job it
creates is choosing the brick before layout so the +12/GND pin assignment
matches; I will put that as a checklist item in the hardware README.

*If you want the barrel anyway* (for example a 12 V/5 A brick and a 2-bay
build), the design would need a hard current limit: either populate only two
bays or add an eFuse on the input set to 5 A. I do not recommend this.

## 4. D7 — front-panel LEDs (power, status, 4× bay activity)

| Option | Parts | Assembly | Enclosure coupling | Look |
|---|---|---|---|---|
| **A. 3 mm through-hole LEDs on the board, through 3.2 mm holes in the lid** | 6× 3 mm LED (~$0.05), optional 3 mm LED clips ($0.05) | hand-soldered after the lid height is known, or JLC THT | loose: hole positions only; lead length sets height | classic, bright, slightly "maker" |
| B. 0603 SMD LEDs + vertical light pipes | 6× 0603 LED + 6× light pipe (Bivar/Dialight, $0.30–0.60 each) | LEDs by SMT line; pipes are press-fit through-hole | tight: pipe length is fixed, so board-to-lid distance must match the pipe | clean flush dots |
| C. Right-angle SMD LEDs at the rear edge, shining through side holes | 6× right-angle 0805 | SMT line, no hand work | medium: board edge must sit at the wall | side-visible only |
| D. No bay LEDs; OLED only, one power LED | 1 LED | — | minimal | sparse |

**Recommendation: A, 3 mm through-hole.** It costs nothing, tolerates a
millimetre or two of enclosure error, and the bay LEDs are driven directly by
the bridge chips' LED pins so they blink with real disk activity, which the
1 Hz OLED cannot show. Option D is tempting for simplicity but loses that
signal. Option B looks best but ties the enclosure and board together more
tightly than a first-run 3D print deserves; it is the right upgrade for a later
revision once the mechanicals are proven.

## 5. D10 — optional M.2 NVMe bay on the free PCIe Gen3 x1 lane

Facts: the CM5's PCIe lane is otherwise unused. An M.2 M-key socket (~$1),
2280/2260/2242 standoff positions, a switched 3.3 V at 3 A (TPS22965 load
switch, ~$0.80), PERST#, CLKREQ# and the REFCLK pair from the CM5. PCIe is not
hot-plug, so the software power-cycles the slot and rescans the bus per job.
Native NVMe is the **only** way to Purge an NVMe drive (`nvme sanitize`);
USB-NVMe adapters cannot pass those commands.

| Option | BOM cost | Layout cost | What it buys |
|---|---|---|---|
| **A. Footprint on the board, unpopulated (DNP)** | $0 | ~22×80 mm of board area, one short 85 Ω pair from the DF40, a handful of traces | populate later with a soldering iron and a firmware flag; no board respin |
| B. Populate in v1 | ~$2 | same, plus an enclosure access door and a slot cutout | NVMe wipes from day one |
| C. Omit | $0 | none; board can shrink ~15 % | nothing |

**Recommendation: A, footprint only.** It is nearly free to keep the option
open, and NVMe is the media type most likely to show up in a wipe pile in
2026. Populating in v1 (B) I would hold until the SATA bays are proven, because
the M.2 door complicates the enclosure and the PCIe rescan path is untested
software. Omitting (C) closes the door on the one feature that needs the CM5's
strongest interface. Two things to accept with A: the board stays around
160 × 100 mm, and the enclosure gets a blanked-off door position now so a
later door does not need a reprint.

## Summary of recommendations

| # | Decision | Recommendation |
|---|---|---|
| 1 | Hub | USB5744 (public datasheet, cheapest, JLC-assembled; +1 LDO) |
| 2 | Bridge (D3) | Measure on Saturday with one dock of each chip; the one that passes wins; tie → JMS578 |
| 3 | Input (D2) | 4-pin DIN only; choose the brick before layout |
| 4 | LEDs (D7) | 3 mm through-hole |
| 5 | M.2 (D10) | footprint, unpopulated |

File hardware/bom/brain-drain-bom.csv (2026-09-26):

refs | qty | value | footprint | manufacturer | mpn | description | usd_each | usd_total | status
BT1 | 1 | CR2032 | BatteryHolder_Keystone_1060_1x2032 | Keystone | 1060 | CR2032 SMD holder (cell bought separately, about 0.5) | 0.9 | 0.9 | verify
C1,C2,C501,C2003,C2004,C2005,C2103,C2104,C2105,C2202,C2203,C5102,C5103 | 13 | 22u 10V | C_0805_2012Metric | generic |  | 22 uF X5R 10 V 0805 | 0.08 | 1.04
C3,C31,C500 | 3 | 10u 10V | C_0805_2012Metric | generic |  | 10 uF X5R 10 V 0805 | 0.05 | 0.15
C4,C30 | 2 | 1u 10V | C_0402_1005Metric | generic |  | 1 uF X5R 10 V 0402 | 0.02 | 0.04
C20,C21 | 2 | 680u 25V low-ESR | CP_Elec_10x10.5 | generic |  | 680 uF 25 V low-ESR aluminium polymer or electrolytic, 10 x 10.5 mm SMD (spin-up bulk) | 0.9 | 1.8 | verify
C22,C2000,C2001,C2100,C2101,C2200,C5100 | 7 | 10u 25V | C_1210_3225Metric | generic |  | 10 uF X5R 25 V 1210 (input and 5 V bulk) | 0.12 | 0.84
C100,C101,C200,C201 | 4 | 33p | C_0402_1005Metric | generic |  | 33 pF C0G 50 V 0402 (crystal load) | 0.01 | 0.04
C110,C111,C112,C113,C120,C121,C122,C123,C140,C141,C151,C152,C153,C154,C161,C162,C163,C164,C210,C211,C212,C213,C220,C221,C222,C223,C240,C241,C251,C252,C253,C254,C261,C262,C263,C264 | 36 | 100n | C_0402_1005Metric | generic |  | 100 nF X7R 16 V or better, 0402 | 0.01 | 0.36
C130,C131,C230,C231 | 4 | 4.7u 10V | C_0603_1608Metric | generic |  | 4.7 uF X5R 10 V 0603 | 0.04 | 0.16
C502 | 1 | 1n | C_0402_1005Metric | generic |  | 1 nF C0G 50 V 0402 | 0.01 | 0.01
C2002,C2102 | 2 | 100n 25V | C_0402_1005Metric | generic |  | 100 nF X7R 16 V or better, 0402 | 0.01 | 0.02
C2201,C5101 | 2 | 100n 10V | C_0402_1005Metric | generic |  | 100 nF X7R 16 V or better, 0402 | 0.01 | 0.02
D1 | 1 | green PWR | LED_D3.0mm | generic |  | 3 mm through-hole LED, colour as listed, 2 V forward, about 5 mA | 0.1 | 0.1
D2 | 1 | green ACT | LED_D3.0mm | generic |  | 3 mm through-hole LED, colour as listed, 2 V forward, about 5 mA | 0.1 | 0.1
D3 | 1 | red STATUS | LED_D3.0mm | generic |  | 3 mm through-hole LED, colour as listed, 2 V forward, about 5 mA | 0.1 | 0.1
D10 | 1 | blue bay 1 activity | LED_D3.0mm | generic |  | 3 mm through-hole LED, colour as listed, 2 V forward, about 5 mA | 0.1 | 0.1
D11 | 1 | blue bay 2 activity | LED_D3.0mm | generic |  | 3 mm through-hole LED, colour as listed, 2 V forward, about 5 mA | 0.1 | 0.1
D12 | 1 | blue bay 3 activity | LED_D3.0mm | generic |  | 3 mm through-hole LED, colour as listed, 2 V forward, about 5 mA | 0.1 | 0.1
D13 | 1 | blue bay 4 activity | LED_D3.0mm | generic |  | 3 mm through-hole LED, colour as listed, 2 V forward, about 5 mA | 0.1 | 0.1
D14 | 1 | blue bay 5 activity | LED_D3.0mm | generic |  | 3 mm through-hole LED, colour as listed, 2 V forward, about 5 mA | 0.1 | 0.1
D15 | 1 | blue bay 6 activity | LED_D3.0mm | generic |  | 3 mm through-hole LED, colour as listed, 2 V forward, about 5 mA | 0.1 | 0.1
D16 | 1 | blue bay 7 activity | LED_D3.0mm | generic |  | 3 mm through-hole LED, colour as listed, 2 V forward, about 5 mA | 0.1 | 0.1
D17 | 1 | blue bay 8 activity | LED_D3.0mm | generic |  | 3 mm through-hole LED, colour as listed, 2 V forward, about 5 mA | 0.1 | 0.1
D20 | 1 | SMBJ15A | D_SMB | Littelfuse | SMBJ15A | TVS diode 15 V standoff, SMB | 0.35 | 0.35
D21 | 1 | 12V 0.5W | D_SOD-123 | generic |  | 12 V 0.5 W zener, SOD-123 (BZT52C12 class) | 0.05 | 0.05
D50 | 1 | blue M.2 activity | LED_D3.0mm | generic |  | 3 mm through-hole LED, colour as listed, 2 V forward, about 5 mA | 0.1 | 0.1
F1 | 1 | 15A slow 0453015.MR | Fuse_Littelfuse-NANO2-451_453 | Littelfuse | 0453015.MR | NANO2 15 A slow-blow fuse (C31; check the 15 A rating in stock) | 0.8 | 0.8 | verify
J3 | 1 | microSD | microSD_HC_Hirose_DM3AT-SF-PEJM5 | Hirose | DM3AT-SF-PEJM5 | microSD push-push socket | 1.0 | 1.0 | verify
J5 | 1 | USB-C rpiboot | USB_C_Receptacle_GCT_USB4085 | GCT | USB4085-GF-A | USB-C 16-pin receptacle, USB 2.0 only | 1.0 | 1.0
J6 | 1 | nRPIBOOT | PinHeader_1x02_P2.54mm_Vertical | generic |  | 2.54 mm pin header, vertical, count as listed | 0.1 | 0.1
J7 | 1 | UART0 GND/TX/RX | PinHeader_1x03_P2.54mm_Vertical | generic |  | 2.54 mm pin header, vertical, count as listed | 0.1 | 0.1
J10 | 1 | bay slot 1 | PCIe_x1_Socket_THT | Amphenol FCI | 10018783-10100TLF | PCI Express x1 vertical through-hole socket, 36 contacts (custom bay pinout, no PCIe signalling) | 1.0 | 1.0 | verify
J11 | 1 | bay slot 2 | PCIe_x1_Socket_THT | Amphenol FCI | 10018783-10100TLF | PCI Express x1 vertical through-hole socket, 36 contacts (custom bay pinout, no PCIe signalling) | 1.0 | 1.0 | verify
J12 | 1 | bay slot 3 | PCIe_x1_Socket_THT | Amphenol FCI | 10018783-10100TLF | PCI Express x1 vertical through-hole socket, 36 contacts (custom bay pinout, no PCIe signalling) | 1.0 | 1.0 | verify
J13 | 1 | bay slot 4 | PCIe_x1_Socket_THT | Amphenol FCI | 10018783-10100TLF | PCI Express x1 vertical through-hole socket, 36 contacts (custom bay pinout, no PCIe signalling) | 1.0 | 1.0 | verify
J14 | 1 | bay slot 5 | PCIe_x1_Socket_THT | Amphenol FCI | 10018783-10100TLF | PCI Express x1 vertical through-hole socket, 36 contacts (custom bay pinout, no PCIe signalling) | 1.0 | 1.0 | verify
J15 | 1 | bay slot 6 | PCIe_x1_Socket_THT | Amphenol FCI | 10018783-10100TLF | PCI Express x1 vertical through-hole socket, 36 contacts (custom bay pinout, no PCIe signalling) | 1.0 | 1.0 | verify
J16 | 1 | bay slot 7 | PCIe_x1_Socket_THT | Amphenol FCI | 10018783-10100TLF | PCI Express x1 vertical through-hole socket, 36 contacts (custom bay pinout, no PCIe signalling) | 1.0 | 1.0 | verify
J17 | 1 | bay slot 8 | PCIe_x1_Socket_THT | Amphenol FCI | 10018783-10100TLF | PCI Express x1 vertical through-hole socket, 36 contacts (custom bay pinout, no PCIe signalling) | 1.0 | 1.0 | verify
J21 | 1 | KPJX-4S-S | Kycon_KPJX-4S-S | Kycon | KPJX-4S-S | 4-pin mini-DIN power jack, shielded, 7.5 A per pin | 1.5 | 1.5
J40 | 1 | Fan GND/5V/TACH/PWM | FanPinHeader_1x04_P2.54mm_Vertical | generic |  | 2.54 mm pin header, vertical, count as listed | 0.1 | 0.1
J41 | 1 | OLED GND/VCC/SCL/SDA | PinHeader_1x04_P2.54mm_Vertical | generic |  | 2.54 mm pin header, vertical, count as listed | 0.1 | 0.1
J50 | 1 | M.2 M-key | M2_Socket3_MKey_CM5IO | TE Connectivity | 2199230-4 | M.2 M-key socket, 4.2 mm, for a 2280 module | 1.2 | 1.2
L20,L21 | 2 | 2.2u 8A | L_Taiyo-Yuden_NR-60xx | generic |  | 2.2 uH, 8 A saturation, shielded, 6 x 6 mm (TPS56637 reference design class) | 0.6 | 1.2 | verify
L22,L51 | 2 | 4.7u 3A | L_Taiyo-Yuden_NR-40xx | generic |  | 4.7 uH, 3 A, shielded, 4 x 4 mm (AP63203 class) | 0.35 | 0.7 | verify
M1 | 1 | CM5002016 | Raspberry-Pi-5-Compute-Module | Raspberry Pi | CM5102016 | Compute Module 5, wireless, 2 GB RAM, 16 GB eMMC (the schematic value field still reads CM5002016) | 97.0 | 97.0 | verify
Q20 | 1 | AO4407A | SOIC-8_3.9x4.9mm_P1.27mm | Alpha & Omega | AO4407A | P-MOSFET -30 V, SO-8: S 1-3, G 4, D 5-8 (reverse-polarity protection) | 0.8 | 0.8
R1,R2,R3 | 3 | 1k | R_0603_1608Metric | generic |  | resistor 1 %, thick film (value as listed) | 0.005 | 0.015
R10,R11,R101,R102,R201,R202,R500,R501,R504,R2001,R2003,R2101,R2103 | 13 | 10k | R_0402_1005Metric | generic |  | resistor 1 %, thick film (value as listed) | 0.005 | 0.065
R20 | 1 | 100k | R_0603_1608Metric | generic |  | resistor 1 %, thick film (value as listed) | 0.005 | 0.005
R60,R61,R62,R63,R64,R65,R66,R67,R505 | 9 | 470 | R_0402_1005Metric | generic |  | resistor 1 %, thick film (value as listed) | 0.005 | 0.045
R100,R200 | 2 | 12.0k 1% | R_0402_1005Metric | generic |  | resistor 1 %, thick film (value as listed) | 0.005 | 0.01
R103,R203 | 2 | 200k | R_0402_1005Metric | generic |  | resistor 1 %, thick film (value as listed) | 0.005 | 0.01
R502,R503 | 2 | 0R (cap DNP alt) | C_0402_1005Metric | generic |  | 0 ohm 0402 (option link, cap DNP alternative) | 0.005 | 0.01
R2000,R2100 | 2 | 73.2k | R_0402_1005Metric | generic |  | resistor 1 %, thick film (value as listed) | 0.005 | 0.01
R2002,R2102 | 2 | 100k | R_0402_1005Metric | generic |  | resistor 1 %, thick film (value as listed) | 0.005 | 0.01
SW1 | 1 | DIP x8 | SW_DIP_SPSTx08_Piano_10.8x21.88mm_W7.62mm_P2.54mm | generic |  | 8-position piano DIP switch, 2.54 mm pitch, 7.62 mm row | 1.0 | 1.0 | verify
SW3 | 1 | lid microswitch | SW_PUSH_6mm | generic |  | 6 mm tactile switch used as the lid switch | 0.2 | 0.2
U1,U2 | 2 | USB5744/2G | QFN-56-1EP_7x7mm_P0.4mm_EP3.2x3.2mm | Microchip | USB5744/2G | USB 3.2 Gen 1 four-port hub, VQFN-56 7 x 7 | 2.44 | 4.88
U3 | 1 | AP2112K-1.2 | SOT-23-5 | Diodes Inc. | AP2112K-1.2TRG1 | 600 mA LDO, 1.2 V, SOT-25 (hub core) | 0.3 | 0.3
U20,U21 | 2 | TPS56637RPAR | Texas_RPA0010A_VQFN-HR-10_3x3mm | Texas Instruments | TPS56637RPAR | 6 A step-down converter, VQFN-HR 3 x 3 | 1.9 | 3.8
U22,U51 | 2 | AP63203WU-7 | TSOT-23-6 | Diodes Inc. | AP63203WU-7 | 2 A step-down converter, TSOT-26, 3.3 V | 0.5 | 1.0
U50,U52 | 2 | TPS22965DSGR | Texas_DSG0008A_WSON-8-1EP_2x2mm_P0.5mm_EP0.9x1.6mm | Texas Instruments | TPS22965DSGR | load switch, 4 A, WSON-8 2 x 2 | 0.5 | 1.0
Y1,Y2 | 2 | 25MHz CL=20pF | Crystal_SMD_3225-4Pin_3.2x2.5mm | generic |  | 25 MHz crystal, 3.2 x 2.5 mm, CL 20 pF (hub clock) | 0.3 | 0.6

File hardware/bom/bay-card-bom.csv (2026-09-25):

refs | qty | value | footprint | manufacturer | mpn | description | usd_each | usd_total | status
C1,C2 | 2 | 22p | C_0402_1005Metric | generic |  | 22 pF C0G 50 V 0402 (crystal load) | 0.01 | 0.02
C3 | 1 | 2.2u | C_0603_1608Metric | generic |  | 2.2 uF X5R 10 V 0603 | 0.03 | 0.03
C4,C5,C6 | 3 | 10u 10V | C_0805_2012Metric | generic |  | 10 uF X5R 10 V 0805 | 0.05 | 0.15
C7,C8,C9,C10,C11,C12,C13,C14,C19,C20 | 10 | 100n | C_0402_1005Metric | generic |  | 100 nF X7R 16 V or better, 0402 | 0.01 | 0.1
C15,C16,C17,C18 | 4 | 10n | C_0402_1005Metric | generic |  | 10 nF X7R 25 V 0402 (SATA AC coupling) | 0.01 | 0.04
F1 | 1 | 3A hold 1812 | Fuse_1812_4532Metric | generic |  | PTC resettable fuse 1812, 3 A hold (bay 12 V), 15 V or better | 0.3 | 0.3 | verify
F2 | 1 | 2A hold 1812 | Fuse_1812_4532Metric | generic |  | PTC resettable fuse 1812, 2 A hold (bay 5 V), 6 V or better | 0.3 | 0.3 | verify
J1 | 1 | bay card edge | BUS_PCIexpress_x1 | (board) |  | PCI Express x1 card-edge fingers on the card itself, ENIG, chamfered tab | 0.0 | 0.0
J2 | 1 | SATA 22-pin | SATA_22pin_Receptacle_RA | Molex | 47018-4001 | SATA 22-pin (7+15) host receptacle, top mount, PCB-edge type, tape and reel with cap | 1.5 | 1.5 | verify
L1 | 1 | 4.7u 1A | L_Taiyo-Yuden_NR-40xx | generic |  | 4.7 uH, 1 A, 4 x 4 mm (ASM1153E internal core switcher) | 0.3 | 0.3 | verify
Q1,Q2 | 2 | AON7403 | DFN-8-1EP_3x3mm_P0.65mm_EP1.5x2.25mm | Alpha & Omega | AON7403 | P-MOSFET -30 V, DFN 3x3-8: S 1-3, G 4, D 5-8 + EP (bay 12 V and 5 V switches) | 0.8 | 1.6
Q3,Q4 | 2 | 2N7002 | SOT-23 | generic |  | N-MOSFET 60 V 2N7002, SOT-23 (gate driver) | 0.05 | 0.1
R1 | 1 | 12.1k 1% | R_0402_1005Metric | generic |  | resistor 1 %, thick film (value as listed) | 0.005 | 0.005
R2,R4,R6,R7 | 4 | 10k | R_0402_1005Metric | generic |  | resistor 1 %, thick film (value as listed) | 0.005 | 0.02
R3,R5 | 2 | 100k | R_0402_1005Metric | generic |  | resistor 1 %, thick film (value as listed) | 0.005 | 0.01
R8 | 1 | 1k | R_0402_1005Metric | generic |  | resistor 1 %, thick film (value as listed) | 0.005 | 0.005
U1 | 1 | ASM1153E | QFN-48-1EP_6x6mm_P0.4mm_EP4.6x4.6mm | ASMedia | ASM1153E | USB 3.0 to SATA 6G bridge, QFN-48 6 x 6, SAT passthrough | 3.0 | 3.0 | verify
Y1 | 1 | 30MHz CL=16pF | Crystal_SMD_3225-4Pin_3.2x2.5mm | generic |  | 30 MHz crystal, 3.2 x 2.5 mm, CL 16 pF (bridge default clock strap) | 0.3 | 0.3

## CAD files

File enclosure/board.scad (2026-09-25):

// GENERATED by enclosure/tools/kicad_to_scad.py from hardware/brain-drain.kicad_pcb — do not edit
board_w = 150.00;
board_h = 122.00;
// mounting holes [x, y]
board_holes = [[10.00, 118.00], [10.00, 4.00], [146.00, 4.00], [146.00, 118.00]];
// x is MIRRORED (measured from the board's right edge as seen from the front): the tray is right-handed with the rear wall at y = 0
// features: [ref, kind, x, y, rot, w, h, z]  (x, y = part centre; kinds: left slot top led cm5 m2 lid; left/right walls are as seen from the tray frame)
board_features = [
  ["D2", "led", 145.23, 105.00, 0, 3.20, 0.00, 0.00],  // activity LED
  ["D3", "led", 145.23, 110.00, 0, 3.20, 0.00, 0.00],  // status LED
  ["J41", "top", 86.19, 96.50, 90, 30.00, 30.00, 0.00],  // OLED header (module is lid-mounted on a 4-wire lead; window position in params.scad)
  ["J40", "top", 14.20, 108.30, 0, 10.00, 5.00, 0.00],  // fan header (optional fan)
  ["D13", "led", 94.50, 30.73, 90, 3.20, 0.00, 0.00],  // bay 4 LED
  ["J5", "right", 144.82, 60.98, -90, 9.50, 3.60, 0.90],  // USB-C receptacle
  ["D1", "led", 145.23, 100.00, 0, 3.20, 0.00, 0.00],  // power LED
  ["J16", "slot", 45.60, 7.20, 90, 11.80, 43.00, 0.00],  // bay slot 7: lid window for the card's 22-pin receptacle and plug
  ["J11", "slot", 118.10, 7.20, 90, 11.80, 43.00, 0.00],  // bay slot 2: lid window for the card's 22-pin receptacle and plug
  ["SW1", "top", 39.09, 109.98, 0, 23.00, 11.00, 0.00],  // 8-way DIP switch slot
  ["D50", "led", 145.23, 95.00, 0, 3.20, 0.00, 0.00],  // M.2 LED
  ["J10", "slot", 132.60, 7.20, 90, 11.80, 43.00, 0.00],  // bay slot 1: lid window for the card's 22-pin receptacle and plug
  ["D12", "led", 109.00, 30.73, 90, 3.20, 0.00, 0.00],  // bay 3 LED
  ["D16", "led", 51.00, 30.73, 90, 3.20, 0.00, 0.00],  // bay 7 LED
  ["J3", "right", 140.45, 44.53, -90, 15.00, 3.00, 0.00],  // microSD card slot
  ["D17", "led", 36.50, 30.73, 90, 3.20, 0.00, 0.00],  // bay 8 LED
  ["D15", "led", 65.50, 30.73, 90, 3.20, 0.00, 0.00],  // bay 6 LED
  ["J13", "slot", 89.10, 7.20, 90, 11.80, 43.00, 0.00],  // bay slot 4: lid window for the card's 22-pin receptacle and plug
  ["J50", "m2", 98.57, 108.00, 90, 22.00, 80.00, 0.00],  // M.2 socket; the SSD lies along the front under the lid, no wall slot
  ["M1", "cm5", 27.50, 78.50, 90, 55.00, 40.00, 0.00],  // CM5 module centre (landscape, antenna edge at x = board_w)
  ["J14", "slot", 74.60, 7.20, 90, 11.80, 43.00, 0.00],  // bay slot 5: lid window for the card's 22-pin receptacle and plug
  ["J21", "right", 141.00, 75.00, 90, 17.00, 16.00, 0.00],  // DIN power jack face (Kycon: 16 wide, ~15 tall)
  ["SW3", "lid", 3.85, 36.75, 90, 0.00, 0.00, 0.00],  // lid microswitch (pressed by the closed lid)
  ["D10", "led", 138.00, 30.73, 90, 3.20, 0.00, 0.00],  // bay 1 LED
  ["J15", "slot", 60.10, 7.20, 90, 11.80, 43.00, 0.00],  // bay slot 6: lid window for the card's 22-pin receptacle and plug
  ["J12", "slot", 103.60, 7.20, 90, 11.80, 43.00, 0.00],  // bay slot 3: lid window for the card's 22-pin receptacle and plug
  ["D11", "led", 123.50, 30.73, 90, 3.20, 0.00, 0.00],  // bay 2 LED
  ["J17", "slot", 31.10, 7.20, 90, 11.80, 43.00, 0.00],  // bay slot 8: lid window for the card's 22-pin receptacle and plug
  ["D14", "led", 80.00, 30.73, 90, 3.20, 0.00, 0.00],  // bay 5 LED
];

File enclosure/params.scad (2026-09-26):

// brain-drain enclosure parameters. All mm. Board geometry comes from board.scad
// (generated from the KiCad file); everything here is the printed part.
include <board.scad>

// walls and clearances
wall       = 2.4;     // outer wall thickness
floor_t    = 2.4;     // tray floor
lid_t      = 2.4;     // lid plate
clear      = 1.0;     // board edge to inner wall
rear_ext   = 16.0;    // extra depth behind the board: the 45 mm bay cards overhang its rear edge by 15.3 mm (option A, 2026-09-24)
cut_clear  = 0.6;     // added around each connector cutout
fit        = 0.25;    // lid-to-tray sliding fit per side

// heights (z = 0 at the board top surface)
below_board = 6.0;    // standoff height: THT leads, the CR2032 holder and buzzer on the bottom side
board_t     = 1.6;
above_board = 50.0;   // bay cards (C24): socket 11.25 + card body 37.6 = 48.9 above the board; the plugs pass through the lid windows
lid_lip     = 3.0;    // skirt on the front and side edges only (the rear edge is the hinge)

// mounting
insert_d    = 3.5;    // M2.5 heat-set insert hole in the standoffs
insert_h    = 5.0;
standoff_d  = 7.0;
screw_d     = 2.8;    // clearance in the lid corners
corner_r    = 3.0;

// features on the lid
oled_win    = [24.0, 13.0];   // visible area of a 0.96" 128x64 module
oled_pcb    = [27.5, 27.5];   // module PCB, sits in a recess under the window
oled_hole_pitch = [23.0, 23.5];
oled_pos    = [board_w - 50, 108];      // window centre in board coordinates: over the M.2 module (6 mm tall) at the
                              // front, on a 4-wire lead to J41; [] = above J41
fan_grille_d = 40;
vent_w      = 2.0;
vent_pitch  = 5.0;

// hinged lid (C22): knuckles along the rear top edge, snap latch at the front
hinge_pin_d = 2.0;    // filament pin
hinge_knuckle_d = 6.0;
hinge_knuckle_l = 12.0;
latch_bump_d = 1.6;

// bay-card retention (C30): a comb of ribs under the lid between the cards' receptacles, and blocks with a groove under each
// card's rear overhang in the tray. Card geometry from the placed 3D model: the card slab is centred 5.4 mm behind the window
// centre (window x from board.scad), the receptacle housing runs 9.5 mm from the slab toward the next slot.
card_off     = 5.4;    // window centre to card centre, along x (mirrored frame: toward +x)
card_t       = 1.6;
comb_depth   = 8.0;    // rib height below the lid plate (card top edge is 1.1 mm below the plate)
comb_gap     = 0.4;    // clearance to the card back face and to the next receptacle housing
comb_y       = [-14.0, 28.0];   // rib extent along the board y (window is -14.9 .. 29.3; LEDs start at y 29.1)
card_over    = 15.3;   // how far the 45 mm cards overhang the board's rear edge
card_shoulder_z = 11.25;   // card shoulder (bottom edge outside the 20.3 mm tab) above the board top surface
support_w    = 4.4;    // overhang support block width along x
support_groove = 2.0;  // groove for the card edge
support_groove_d = 3.0;
support_gap  = 0.5;    // card shoulder to groove floor

// lid artwork, engraved into the outer face (impression, prints on the bed face)
engrave_d    = 0.6;
logo_pos     = [100, 60];   // board x (mirrored frame) and y of the artwork centre
logo_mm      = 68;          // width of the octopus
name_text    = "BRAIN-DRAIN";
name_size    = 7;
name_dy      = 24;          // name centre below the logo centre
sub_text     = "NIST 800-88 DISK SANITIZER";
sub_size     = 3;
sub_dy       = 31;

// derived
inner_w = board_w + 2 * clear;
inner_h = board_h + 2 * clear + rear_ext;
outer_w = inner_w + 2 * wall;
outer_h = inner_h + 2 * wall;
tray_height = floor_t + below_board + board_t + above_board;   // to the top of the tray wall

// --- refinements (v0.2)
feet_d      = 8.5;    // rubber bumper pocket diameter (3M SJ5012 style, 8 mm)
feet_depth  = 1.0;
feet_inset  = 8.0;
bezel_t     = 1.6;    // OLED bezel plate thickness
bezel_post_d = 4.5;   // posts for the module's four M2 holes
bezel_post_h = 4.0;

// (the v0 drive rack is gone: drives lie loose on the bench and connect with 22-pin cables, C21)

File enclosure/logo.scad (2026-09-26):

// GENERATED by enclosure/tools/gen_logo.py from docs/img/logo.svg -- do not edit
logo_w = 1054.0;   // artwork size in logo units
logo_h = 506.0;
module stroke(p, w) { for (i = [0 : len(p) - 2]) hull() { translate(p[i]) circle(d = w, $fn = 14); translate(p[i + 1]) circle(d = w, $fn = 14); } }
tentacles = [[[-127.0,27.0],[-136.9,29.5],[-147.6,31.0],[-159.1,31.4],[-171.4,31.0],[-184.2,29.7],[-197.7,27.7],[-211.6,25.0],[-225.9,21.8],[-240.5,18.1],[-255.4,14.0],[-270.5,9.6],[-285.6,5.0],[-300.8,0.3],[-316.0,-4.5],[-331.0,-9.2],[-345.9,-13.8],[-360.4,-18.2],[-374.6,-22.3],[-388.4,-26.0],[-401.7,-29.2],[-414.4,-31.8],[-426.5,-33.8],[-437.8,-35.0],[-448.4,-35.4],[-458.0,-34.9],[-466.7,-33.4],[-474.4,-30.8],[-481.0,-27.0]],
  [[-103.0,-0.0],[-105.1,1.6],[-108.4,1.9],[-112.9,1.1],[-118.5,-0.8],[-125.2,-3.7],[-132.7,-7.4],[-141.1,-11.9],[-150.3,-17.0],[-160.1,-22.7],[-170.5,-28.8],[-181.3,-35.4],[-192.6,-42.1],[-204.2,-49.0],[-216.0,-56.0],[-227.9,-62.9],[-239.9,-69.7],[-251.9,-76.2],[-263.7,-82.4],[-275.4,-88.2],[-286.7,-93.3],[-297.6,-97.9],[-308.1,-101.7],[-318.0,-104.6],[-327.2,-106.6],[-335.8,-107.5],[-343.4,-107.3],[-350.2,-105.8],[-356.0,-103.0]],
  [[-68.0,-20.0],[-67.0,-19.2],[-66.8,-19.7],[-67.5,-21.7],[-69.0,-24.8],[-71.3,-29.0],[-74.2,-34.2],[-77.9,-40.3],[-82.2,-47.1],[-87.0,-54.6],[-92.4,-62.6],[-98.3,-71.0],[-104.7,-79.7],[-111.5,-88.6],[-118.6,-97.6],[-126.1,-106.6],[-133.8,-115.3],[-141.8,-123.8],[-150.0,-132.0],[-158.3,-139.6],[-166.8,-146.6],[-175.3,-152.9],[-183.8,-158.3],[-192.3,-162.8],[-200.8,-166.3],[-209.1,-168.5],[-217.3,-169.4],[-225.3,-169.0],[-233.0,-167.0]],
  [[-23.0,-31.0],[-23.6,-30.5],[-24.0,-31.6],[-24.3,-34.1],[-24.6,-37.8],[-24.8,-42.8],[-25.0,-48.8],[-25.2,-55.7],[-25.4,-63.5],[-25.7,-71.9],[-26.1,-80.9],[-26.6,-90.3],[-27.3,-100.1],[-28.1,-110.1],[-29.1,-120.1],[-30.4,-130.1],[-31.9,-140.0],[-33.8,-149.5],[-35.9,-158.7],[-38.4,-167.3],[-41.3,-175.3],[-44.5,-182.5],[-48.2,-188.8],[-52.4,-194.0],[-57.0,-198.2],[-62.2,-201.1],[-67.9,-202.6],[-74.1,-202.6],[-81.0,-201.0]],
  [[23.0,-31.0],[20.2,-30.5],[18.3,-31.6],[17.4,-34.1],[17.2,-37.8],[17.9,-42.8],[19.2,-48.8],[21.1,-55.7],[23.6,-63.5],[26.5,-71.9],[29.9,-80.9],[33.6,-90.3],[37.5,-100.1],[41.7,-110.1],[46.0,-120.1],[50.4,-130.1],[54.7,-140.0],[59.0,-149.5],[63.1,-158.7],[67.0,-167.3],[70.6,-175.3],[73.9,-182.5],[76.7,-188.8],[79.1,-194.0],[80.9,-198.2],[82.0,-201.1],[82.5,-202.6],[82.2,-202.6],[81.0,-201.0]],
  [[68.0,-20.0],[66.7,-19.2],[66.4,-19.7],[67.0,-21.7],[68.4,-24.8],[70.7,-29.0],[73.8,-34.2],[77.6,-40.3],[82.1,-47.1],[87.1,-54.6],[92.8,-62.6],[99.0,-71.0],[105.6,-79.7],[112.6,-88.6],[120.0,-97.6],[127.7,-106.6],[135.7,-115.3],[143.8,-123.8],[152.1,-132.0],[160.5,-139.6],[169.0,-146.6],[177.4,-152.9],[185.8,-158.3],[194.1,-162.8],[202.2,-166.3],[210.1,-168.5],[217.7,-169.4],[225.0,-169.0],[232.0,-167.0]],
  [[103.0,-0.0],[108.2,1.6],[113.6,1.9],[119.3,1.1],[125.3,-0.8],[131.6,-3.7],[138.1,-7.4],[144.9,-11.9],[152.0,-17.0],[159.4,-22.7],[167.1,-28.8],[175.0,-35.4],[183.3,-42.1],[191.8,-49.0],[200.6,-56.0],[209.7,-62.9],[219.2,-69.7],[228.9,-76.2],[238.9,-82.4],[249.2,-88.2],[259.8,-93.3],[270.8,-97.9],[282.0,-101.7],[293.5,-104.6],[305.4,-106.6],[317.6,-107.5],[330.1,-107.3],[342.9,-105.8],[356.0,-103.0]],
  [[127.0,27.0],[140.5,29.5],[153.8,31.0],[166.7,31.4],[179.4,31.0],[191.8,29.7],[204.0,27.7],[216.1,25.0],[228.0,21.8],[239.8,18.1],[251.5,14.0],[263.1,9.6],[274.7,5.0],[286.3,0.3],[298.0,-4.5],[309.7,-9.2],[321.5,-13.8],[333.4,-18.2],[345.5,-22.3],[357.8,-26.0],[370.2,-29.2],[382.9,-31.8],[395.9,-33.8],[409.2,-35.0],[422.8,-35.4],[436.7,-34.9],[451.1,-33.4],[465.8,-30.8],[481.0,-27.0]]];
folds = [[[0.0,238.0],[-1.0,229.4],[-1.7,220.5],[-2.3,211.6],[-2.6,202.4],[-2.8,193.1],[-2.9,183.6],[-2.8,173.9],[-2.6,164.1],[-2.3,154.0],[-2.0,143.7],[-1.5,133.2],[-1.0,122.5],[-0.5,111.6],[0.0,100.5],[0.5,89.1],[1.0,77.5],[1.5,65.7],[2.0,53.6],[2.3,41.3],[2.6,28.7],[2.8,15.8],[2.9,2.7],[2.8,-10.7],[2.6,-24.4],[2.3,-38.4],[1.7,-52.6],[1.0,-67.2],[0.0,-82.0]],
  [[-180.0,158.0],[-174.6,161.9],[-169.3,165.0],[-163.9,167.4],[-158.6,169.1],[-153.3,170.2],[-148.0,170.8],[-142.7,171.0],[-137.4,170.7],[-132.1,170.1],[-126.9,169.2],[-121.7,168.2],[-116.5,166.9],[-111.4,165.6],[-106.2,164.2],[-101.2,162.9],[-96.2,161.7],[-91.2,160.7],[-86.2,159.9],[-81.3,159.3],[-76.5,159.2],[-71.7,159.4],[-67.0,160.1],[-62.3,161.4],[-57.7,163.2],[-53.2,165.8],[-48.7,169.0],[-44.3,173.1],[-40.0,178.0]],
  [[-160.0,78.0],[-154.7,81.9],[-149.4,85.0],[-144.3,87.3],[-139.1,89.1],[-134.1,90.2],[-129.1,90.8],[-124.1,90.9],[-119.2,90.6],[-114.4,89.9],[-109.6,89.0],[-104.8,87.9],[-100.0,86.5],[-95.3,85.1],[-90.6,83.6],[-85.9,82.2],[-81.3,80.8],[-76.6,79.6],[-72.0,78.5],[-67.3,77.8],[-62.7,77.3],[-58.0,77.3],[-53.4,77.7],[-48.7,78.6],[-44.0,80.1],[-39.3,82.2],[-34.6,85.0],[-29.8,88.6],[-25.0,93.0]],
  [[-170.0,8.0],[-164.7,10.9],[-159.4,13.1],[-154.2,14.8],[-149.1,15.9],[-144.1,16.5],[-139.0,16.8],[-134.1,16.6],[-129.1,16.1],[-124.2,15.3],[-119.3,14.4],[-114.5,13.2],[-109.7,11.9],[-104.8,10.6],[-100.0,9.2],[-95.2,7.9],[-90.3,6.7],[-85.5,5.6],[-80.7,4.8],[-75.8,4.1],[-70.9,3.8],[-65.9,3.8],[-61.0,4.2],[-55.9,5.1],[-50.9,6.4],[-45.8,8.4],[-40.6,10.9],[-35.3,14.1],[-30.0,18.0]],
  [[40.0,178.0],[44.3,173.1],[48.7,169.0],[53.2,165.8],[57.7,163.2],[62.3,161.4],[67.0,160.1],[71.7,159.4],[76.5,159.2],[81.3,159.3],[86.2,159.9],[91.2,160.7],[96.2,161.7],[101.2,162.9],[106.2,164.2],[111.4,165.6],[116.5,166.9],[121.7,168.2],[126.9,169.2],[132.1,170.1],[137.4,170.7],[142.7,171.0],[148.0,170.8],[153.3,170.2],[158.6,169.1],[163.9,167.4],[169.3,165.0],[174.6,161.9],[180.0,158.0]],
  [[25.0,93.0],[29.8,88.6],[34.6,85.0],[39.3,82.2],[44.0,80.1],[48.7,78.6],[53.4,77.7],[58.0,77.3],[62.7,77.3],[67.3,77.8],[72.0,78.5],[76.6,79.6],[81.3,80.8],[85.9,82.2],[90.6,83.6],[95.3,85.1],[100.0,86.5],[104.8,87.9],[109.6,89.0],[114.4,89.9],[119.2,90.6],[124.1,90.9],[129.1,90.8],[134.1,90.2],[139.1,89.1],[144.3,87.3],[149.4,85.0],[154.7,81.9],[160.0,78.0]],
  [[30.0,18.0],[35.3,14.1],[40.6,10.9],[45.8,8.4],[50.9,6.4],[55.9,5.1],[61.0,4.2],[65.9,3.8],[70.9,3.8],[75.8,4.1],[80.7,4.8],[85.5,5.6],[90.3,6.7],[95.2,7.9],[100.0,9.2],[104.8,10.6],[109.7,11.9],[114.5,13.2],[119.3,14.4],[124.2,15.3],[129.1,16.1],[134.1,16.6],[139.0,16.8],[144.1,16.5],[149.1,15.9],[154.2,14.8],[159.4,13.1],[164.7,10.9],[170.0,8.0]],
  [[-130.0,228.0],[-125.8,231.0],[-121.6,233.4],[-117.5,235.4],[-113.4,237.0],[-109.4,238.2],[-105.5,239.0],[-101.6,239.6],[-97.7,239.8],[-93.9,239.9],[-90.1,239.7],[-86.3,239.4],[-82.5,239.0],[-78.8,238.5],[-75.0,238.0],[-71.2,237.5],[-67.5,237.0],[-63.7,236.6],[-59.9,236.3],[-56.1,236.1],[-52.3,236.2],[-48.4,236.4],[-44.5,237.0],[-40.6,237.8],[-36.6,239.0],[-32.5,240.6],[-28.4,242.6],[-24.2,245.0],[-20.0,248.0]],
  [[20.0,248.0],[24.2,245.0],[28.4,242.6],[32.5,240.6],[36.6,239.0],[40.6,237.8],[44.5,237.0],[48.4,236.4],[52.3,236.2],[56.1,236.1],[59.9,236.3],[63.7,236.6],[67.5,237.0],[71.2,237.5],[75.0,238.0],[78.8,238.5],[82.5,239.0],[86.3,239.4],[90.1,239.7],[93.9,239.9],[97.7,239.8],[101.6,239.6],[105.5,239.0],[109.4,238.2],[113.4,237.0],[117.5,235.4],[121.6,233.4],[125.8,231.0],[130.0,228.0]],
  [[-100.0,-62.0],[-95.8,-59.0],[-91.6,-56.6],[-87.5,-54.6],[-83.4,-53.0],[-79.4,-51.8],[-75.5,-51.0],[-71.6,-50.4],[-67.7,-50.2],[-63.9,-50.1],[-60.1,-50.3],[-56.3,-50.6],[-52.5,-51.0],[-48.8,-51.5],[-45.0,-52.0],[-41.2,-52.5],[-37.5,-53.0],[-33.7,-53.4],[-29.9,-53.7],[-26.1,-53.9],[-22.3,-53.8],[-18.4,-53.6],[-14.5,-53.0],[-10.6,-52.2],[-6.6,-51.0],[-2.5,-49.4],[1.6,-47.4],[5.8,-45.0],[10.0,-42.0]],
  [[-200.0,128.0],[-200.5,121.6],[-200.8,115.4],[-201.1,109.4],[-201.2,103.4],[-201.2,97.5],[-201.1,91.8],[-200.9,86.1],[-200.6,80.5],[-200.2,75.0],[-199.6,69.5],[-198.9,64.1],[-198.2,58.7],[-197.3,53.4],[-196.2,48.0],[-195.1,42.6],[-193.9,37.3],[-192.5,31.9],[-191.0,26.5],[-189.5,21.0],[-187.8,15.5],[-185.9,9.9],[-184.0,4.2],[-182.0,-1.5],[-179.8,-7.4],[-177.5,-13.4],[-175.1,-19.4],[-172.6,-25.6],[-170.0,-32.0]],
  [[200.0,128.0],[200.5,121.6],[200.8,115.4],[201.1,109.4],[201.2,103.4],[201.2,97.5],[201.1,91.8],[200.9,86.1],[200.6,80.5],[200.2,75.0],[199.6,69.5],[198.9,64.1],[198.2,58.7],[197.3,53.4],[196.2,48.0],[195.1,42.6],[193.9,37.3],[192.5,31.9],[191.0,26.5],[189.5,21.0],[187.8,15.5],[185.9,9.9],[184.0,4.2],[182.0,-1.5],[179.8,-7.4],[177.5,-13.4],[175.1,-19.4],[172.6,-25.6],[170.0,-32.0]]];
brain = [0.0, 78.0, 215, 175];
eyes = [[-70.0,-32.0,34.0,30.0,-64.0,-38.0,16.0], [70.0,-32.0,34.0,30.0,76.0,-38.0,16.0]];
drives = [[-527.0,-79.0], [-402.0,-155.0], [-279.0,-219.0], [-127.0,-253.0], [35.0,-253.0], [186.0,-219.0], [310.0,-155.0], [435.0,-79.0]];   // lower-left corner of each 92 x 60 icon
module drive_icon() {
    difference() {
        translate([0, 0]) offset(r = 6) offset(delta = -6) square([92, 60]);
        // raised: the platter ring, the three bars and the spindle arm
        translate([34, 30]) difference() { circle(r = 20, $fn = 32); circle(r = 14, $fn = 32); }
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

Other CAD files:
enclosure/refinements.scad
enclosure/scene.scad
enclosure/shell.scad

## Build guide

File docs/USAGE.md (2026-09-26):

# Usage

## Software: simulate on a workstation

```
cd software
python3 -m venv .venv && . .venv/bin/activate
pip install -e ".[dev]"
pytest                                    # 61 tests
braindrain simulate --grace 2             # terminal 1: the appliance, OLED drawn in the terminal
```

In a second terminal:

```
braindrain sim-plug 1 --size 1G --media hdd --prefill --throttle 50M   # host overwrite + full verify, slow enough to watch
braindrain sim-plug 3 --size 256M --media ssd --fw crypto,block         # simulated firmware sanitize + canary check
braindrain sim-plug 5 --size 256M --media nvme --fw crypto,block        # NVMe in the M.2 slot
braindrain sim-door closed                                              # slot powers, rescans, wipe starts
braindrain sim-unplug 1                                                 # aborts bay 1
echo 01100000 > ~/.brain-drain-sim/dip                                  # legacy 3-pass (DIP 1-3 = 011)
braindrain dip 01100000                                                 # decode a setting
```

Certificates: `~/.brain-drain-sim/reports/`. Last OLED frame: `~/.brain-drain-sim/display.txt`.

DIP switch (ON = 1): 1–3 mode (000 auto, 001 purge, 010 clear, 011 3-pass,
100 7-pass, 101 crypto-only, 111 dry-run), 4 random pattern, 5 sampled verify,
8 maintenance (never wipe).

## Software: bench a USB-SATA dock

```
sudo .venv/bin/braindrain bench /dev/sdX                       # non-destructive: bridge id, IDENTIFY, SMART, sanitize-status, read speed
sudo .venv/bin/braindrain bench /dev/sdX --destructive         # + write test and SECURITY ERASE, asks for the serial
sudo .venv/bin/braindrain bench /dev/sdX --destructive --sanitize   # + full SANITIZE (hours on an HDD)
```

## Software: deploy on a Raspberry Pi

```
sudo software/deploy/install.sh --headless   # Pi + docks, no carrier board
sudo /opt/brain-drain/venv/bin/braindrain list
sudo /opt/brain-drain/venv/bin/braindrain setup-bay 1 /dev/sdX
sudo systemctl start brain-drain && journalctl -fu brain-drain
```

Without `--headless` the real HAL is used (DIP, OLED, bay power, M.2 slot);
that needs the carrier board. Config lives in `/etc/brain-drain/config.json`.

## Hardware: regenerate everything from the netlist

Needs KiCad 9 (`kicad-cli` and the `pcbnew` Python module of the system Python 3), Python packages `numpy` and `Pillow`, poppler-utils (`pdftoppm`),
and, for routing only, Java 21 and Java 25 plus the two freerouting jars downloaded from https://github.com/freerouting/freerouting/releases
(v2.1.0 and v2.4.1) into `hardware/tools/freerouting/` (they are not in the repository). Two boards share one pipeline:
`BD_PROJECT=brain` (default, files in `hardware/`) and `BD_PROJECT=card` (the bay card, files in `hardware/bay-card/`).

**Everything from the netlist to a routed board, unattended** (card about 10 minutes, brain about 1.5 hours):

```
cd hardware
python3 tools/symgen.py                               # lib/brain-drain.kicad_sym (symbols, incl. the bay slot and the P-FETs)
python3 tools/fpgen.py                                # lib/brain-drain.pretty (PCIe slot, SATA receptacle, DIN, TPS56637)
BD_PROJECT=brain python3 tools/gen_sch.py             # schematic files + ERC     (repeat with BD_PROJECT=card)
BD_PROJECT=brain sh tools/route_full.sh               # gen_pcb, rules and planes, fanout, pairs first (stage 0), signals, planes,
                                                      # gap router, tuner, pair fixer, via clean-up, reports, renders
tail -f routing/chain.log                             # progress (bay-card/routing/chain.log for the card)
```

The log ends with the open-connection and pair counts; the results are in `routing/open.md`, `routing/pairs.md` and `routing/drc.json`.
**Regenerating overwrites the board.** Once a designer edits a board in KiCad, keep that copy and do not run `route_full.sh` on it.

**The individual steps** (each is one `python3 tools/route.py <command>` in `hardware/`):

| Command | Does |
|---|---|
| `python3 tools/gen_pcb.py`, `check_place.py` | placement, courtyard and outline check (`-v` lists positions) |
| `route.py prepare` | net classes into the `.kicad_pro`, pair rules, zones (fresh board only), CM5 hole and antenna keep-outs |
| `route.py fanout`, `fanout-big`, `fanout-conn`, `fanout-qfn`, `fanout-qfn-rip` | plane and supply vias for small parts, exposed pads, connector rows, 0.4 mm QFN pins |
| `route.py stage0` (pairs alone, first), `stage1` (signals), `stage2` (planes, rails, bays) | freerouting stages; each locks what exists (`BD_PAIRS_FIRST=1`, `BD_ROUTER=2.4.1 BD_PASSES=12` for the bounded router) |
| `route.py drc-clean` | removes copper the router left in violation, widens slivers |
| `route.py close-gaps`, `close-gaps-pairs` | our grid router for what is left; `BD_RES=0.05 BD_MARGIN=0.2 BD_ONLY=net,net` for a tight pin |
| `route.py tune` | meanders the shorter side of every pair, end to end across the series caps; `sh tools/fix_pairs.sh` retries stubborn pairs |
| `route.py via-clean` | removes overlapping and dangling vias when connectivity is unchanged |
| `python3 tools/open_report.py`, `route.py pairs` | `routing/open.md`, `routing/pairs.md` |
| `sh tools/render_board.sh` | KiCad 3D views, per-layer PNGs in `renders/layers/`, schematic PDF and PNGs |
| `python3 tools/gen_bom.py` | BOM of both boards: `bom/*.csv` and `docs/BOM.md` |
| `python3 tools/branding.py [brain\|card] [--dry]` | top-silkscreen logo, name and repository URL in the largest free area (idempotent, does not touch copper; `route_full.sh` runs it) |
| `python3 tools/make_review_pack.py` | `hardware/review/`: rules, stack-up, planes, keep-outs, routing statistics, DRC / ERC, footprint provenance, netlists, placement CSV |
| `sh tools/export_fab.sh` | `fab/<date>/`: gerbers and drill zip, placement CSV, BOM, assembly PDFs (order pack, gitignored) |
| `kicad-cli pcb drc --format json --severity-all -o routing/drc.json brain-drain.kicad_pcb` | the DRC report used everywhere |

Open `hardware/brain-drain.kicad_pro` (or `hardware/bay-card/bay-card.kicad_pro`) in KiCad 9 to inspect or edit. Before any routing run, check the
DSN: its `(rule` block must say `clearance 150` and the `(class` list must have the project's classes; a DSN exported without the project's net
classes carries KiCad's 0.2 mm default, which makes every 0.4 mm-pitch pad a violation and the router routes nothing. Freerouting 2.1.0 ignores its
pass limit and stops only when its board history is exhausted; the scripts allow for that. After heavy edits pcbnew's Python proxies break, so the
tools run each edit step in a fresh process. Details of the tool set: [LAYOUT-REVIEW.md](LAYOUT-REVIEW.md) section 6.

## The phone page and Wi-Fi

The unit boots into its own access point. On the OLED, idle, you see a QR code
and the key. Scan the code (or join `brain-drain-xxxx` by hand with the key as
the password) and open `http://10.42.0.1/`. The page shows the bays, the
certificates (download one or all as a zip), the log, and two forms that need
the key from the screen:

* **Join a network**: the unit joins it now and at every boot; the new address
  shows on the OLED. If the join fails it falls back to the access point.
* **Reset**: *Wi-Fi reset* forgets the network and starts the access point
  with a fresh key; *factory reset* also deletes every certificate and the
  crash-recovery state.

Without a network: set the DIP to mode `110` and power-cycle for a Wi-Fi reset,
`110` with DIP 8 ON for a factory reset (the unit never wipes in that mode; set
the policy back afterwards). Over SSH: `braindrain wifi-reset [--factory]`.

In the simulator the page is on `http://127.0.0.1:8080/` (`--web PORT`) and
the wireless backend is a file in the sim directory.

## Enclosure

```
cd enclosure
make            # board.scad from the board file (x mirrored, see ARCHITECTURE 5), then stl/{tray,lid,bezel}.stl
make renders    # scene STLs, then every image of the case, the electronics inside it and the complete system into docs/img/renders/
```

Edit `params.scad` for print parameters; never edit `board.scad`. `python3 enclosure/tools/gallery.py [boards|electronics|case|unit|all]` renders one set;
it needs pcbnew, numpy and Pillow (no display). The 3D proxy model of the boards is `hardware/tools/board_model.py`.

## Documentation images

```
software/.venv/bin/python docs/tools/diagrams.py        # system block, lid plan, wall panel, bay flow (SVG + PNG)
software/.venv/bin/python software/tools/oled_mockup.py docs/img
python3 enclosure/tools/gallery.py all                   # docs/img/renders/*.png
python3 hardware/tools/make_review_pack.py               # hardware/review/
```

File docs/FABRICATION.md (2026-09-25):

# Fabrication: getting boards made and assembled

The owner wants the board fabricated **and fully assembled** (every SMD part and
every connector) by a small-run service, with at most minimal soldering at home
(the OLED lead, heat-set inserts, the CM5 itself which just presses on). This
page lists who can do that for the two boards of C24, a 4-layer 150 × 122 mm
brain and a 45 × 46 mm bay card (four per unit, panelised), in quantities of
2–10, what it costs, and what the design needs before the order can be placed.

Prices are estimates from the vendors' public calculators and 2025–2026 price
lists; they move with copper, exchange rates and the day's promotion, so get a
live quote from the design files before deciding.

## What the board needs from the fab

| Item | Requirement | Why |
|---|---|---|
| Layers, size | brain: 6 layers, 150 × 122 mm, 1.6 mm, ENIG; bay card: 4 layers, 45 × 46 mm, 1.6 mm, ENIG, panel of 8–16 with the finger tab and key notch routed | USB 3 / SATA / PCIe pairs on outer layers over solid ground; ENIG for the 0.4 mm connectors |
| Stack-up | brain: vendor's standard 6-layer with controlled impedance (JLC06161H-series or equal; recalculate the pair widths with their calculator, the design's 0.147 / 0.253 mm were set for four layers); card: standard 4-layer (JLC04161H-7628) | 90 Ω differential pairs without a custom stack-up fee |
| Minimum features | 0.13 mm track / 0.125 mm space, 0.2 mm drill in a 0.45 mm via (the Raspberry Pi CM5IO rules); power vias 0.6/0.3 | set by the CM5's 0.4 mm connectors and the 0.5 mm M.2 socket; every vendor above quotes these as standard 4-layer capability |
| Fine pitch | 0.4 mm pitch (Hirose DF40 for the CM5, QFN-48 / QFN-56 at 0.4–0.5 mm) | needs stencil + reflow, not hand soldering; every vendor below handles it |
| Through-hole | brain: eight PCIe x1 sockets, DIN jack, DIP switch, LEDs, headers, M.2 standoff; card: the SATA receptacle (SMT with pegs) | ask for **through-hole assembly** too, or these come loose in a bag |
| Bottom side | CR2032 holder and two headers | double-sided assembly adds a setup fee; or move them to the top before ordering |
| Parts sourcing | vendor-stocked passives; the CM5, USB5744, ASM1153E, TPS56637, connectors as consigned or "global sourcing" parts | ASM1153E is not in most in-house catalogues; JLCPCB has it (LCSC C2762919) |

The CM5 module and its cooler are bought separately and pressed on at home.

## Vendors that assemble small runs

| Vendor | Where | Small-run assembly | Notes | Link |
|---|---|---|---|---|
| **JLCPCB** | China | yes, from 2 pcs, SMT + through-hole, single or double side | cheapest by far; huge in-house parts catalogue (LCSC) including the ASM1153E and USB5744; 4-layer impedance stack-ups are standard; "Economic" vs "Standard" assembly tiers | https://jlcpcb.com/capabilities/pcb-assembly-capabilities |
| **PCBWay** | China | yes, from 1 pc, full turnkey or consigned parts | more flexible on odd parts and on special requests; quotes by e-mail for anything the calculator does not cover | https://www.pcbway.com/pcb-assembly.html |
| **Seeed Fusion** | China | yes, from 1 pc, turnkey | Open Parts Library for common parts; good documentation for first-time assembly orders | https://www.seeedstudio.com/fusion_pcb.html |
| **Eurocircuits** | Belgium / Germany | yes, "PCB + assembly" from 1 pc | EU pricing (roughly 3–5× China) but EU lead times, no customs, strong DFM checks | https://www.eurocircuits.com/pcb-assembly/ |
| **Aisler** | Germany | yes, small batches | simple upload-and-go, EU; assembly catalogue is narrower, consigned parts possible | https://aisler.net/ |
| **MacroFab** | USA | yes, prototypes from 1 pc | US production, good for a US owner who wants no import paperwork; pricier than Asia | https://macrofab.com/ |
| **Screaming Circuits** | USA | yes, quick-turn prototypes | assembly only (they source boards too); strong on fine pitch and odd connectors | https://www.screamingcircuits.com/ |
| OSH Park | USA | **no assembly** | listed only because it is the usual prototype fab; bare boards only, so not a fit for this project | https://oshpark.com/ |

Recommendation for the first run: **JLCPCB** (5 boards, 2 assembled), because the
ASM1153E and USB5744 are in their catalogue, 4-layer impedance control is
standard, and a 2-piece assembly order is routine. Keep PCBWay as the fallback
for consigned parts if a JLCPCB part goes out of stock.

## Estimated cost for the first run

Two assembled units (each one brain and four bay cards) plus three bare brain boards and spare cards, at JLCPCB-class pricing. Part costs
come from the generated [BOM.md](BOM.md); board and assembly prices are the vendors' public calculators, not quotes.

| Item | Estimate (USD) | Basis |
|---|---|---|
| 5 x bare brain, 6-layer 150 x 122 mm, ENIG, impedance stack-up | 150-230 | calculator: 6-layer, 122 x 150 mm, ENIG, 5 pcs (four layers would be 70-100) |
| Bay-card panel, 4-layer 45 x 46 mm, 16 cards (8 for the two units, 8 spare or expansion) | 40-70 | panel of 16, tab routed, ENIG |
| Assembly setup and stencil, brain, both sides | 50-80 | SMT and through-hole setup, extended-parts fees |
| Assembly setup and stencil, card (a second job) | 40-70 | |
| Assembly labour: 2 brains (about 330 placements each) and 8 cards (about 40 each) | 60-110 | per-joint pricing, 0402 heavy |
| Board-mounted parts: 2 brains without the CM5 (about $37 each) and 8 cards (about $8 each) | 140 | BOM.md |
| Shipping and import (DHL to the US) | 40-70 | 2 assembled brains, 8 cards, 3 bare brains, 1-2 kg |
| **Subtotal, boards, assembly and board parts** | **~520-770** | |
| CM5 wireless, 2 GB / 16 GB eMMC, per unit | 97 | Raspberry Pi list price (also counted in the BOM roll-up) |
| CM5 cooler, OLED module, heat-set inserts, feet, per unit | 13 | |
| 4 x SATA 22-pin extension cables 0.5 m | 14 | off-the-shelf |
| 12 V / 10 A brick with matching 4-pin DIN | 25-35 | choose before the DIN pinout is fixed (B3); 150-180 W for eight bays |
| Enclosure print (PETG/ASA, about 350 g) | 9 | home printer; 35-60 from a print service |
| **Per finished unit, on top of the board run** | **~160-170** | |

So the first two working units land at roughly **$850-1100 all in**, or about **$425-550 each**, with three spare bare brains and eight spare cards.
A second run of five assembled units would be about $450-650 for the boards plus $160-170 per unit on top. Eight fitted bays add four cards
(about $16 each with parts and board) and four cables, plus the 150-180 W brick and heavier input parts (STATUS R23).

## Before the order can go in

| # | Gate | Status |
|---|---|---|
| 1 | Routing finished and DRC-clean | done 2026-09-25: 0 open connections, 0 DRC errors on both boards, pairs matched; **not yet reviewed by a board engineer** (STATUS R25 to R29) |
| 2 | Stack-up chosen with the fab and the pair geometry recalculated for it | open, R26: the pair class was set for a four-layer stack-up |
| 3 | SATA receptacle and PCIe slot footprints from the vendor drawings | done 2026-09-25; the Molex mating face and the socket housing ends to check against the 3D models (R28) |
| 4 | M.2 socket peg check against the TE drawing | open, R2 (drawing received) |
| 5 | DIN pinout matched to the chosen brick | open, R3, B3 |
| 6 | Vendor part numbers on every BOM line, checked against stock the day of ordering | BOM generated; lines marked `verify` remain |
| 7 | Gerbers, drill, pick-and-place and BOM exports from `kicad-cli`, plus the assembly drawings | `BD_PROJECT=brain\|card sh hardware/tools/export_fab.sh` writes `hardware/fab/<date>/<board>/` (gitignored); run it after the engineer's changes |
| 8 | Fab DFM check on the gerbers (0.3/0.15 mm vias, 0.4 mm QFN dog-bones, hole-to-hole, edge clearance) | open |
| 9 | Test points, fiducials, panel drawing for the card, silkscreen cleaned | open, R29 |
| 10 | Bench evidence that the ASM1153E passes Sanitize through | 2026-09-26 |

## Ordering checklist (JLCPCB flow)

1. `BD_PROJECT=brain sh hardware/tools/export_fab.sh` and again with `BD_PROJECT=card`: gerber + drill zip, placement CSV, BOM CSV, assembly PDFs, an errors-only DRC report. Add LCSC numbers to the BOM lines first (gate 6).
2. Upload the zip, pick 6 layers (brain) or 4 layers (card), 1.6 mm, ENIG, the impedance stack-up, 5 pcs.
3. Tick "PCB assembly", 2 pcs, both sides, standard tier; upload BOM + placement.
4. In the parts matcher, confirm every line; for anything out of stock choose an
   equivalent or mark DNP and note it in `docs/BOM.md`.
5. Review the placement preview (rotations of polarised parts and the QFNs).
6. Order; expect 2–3 weeks to the door.

What still gets soldered at home: nothing on the board. Press the CM5 on, screw
the cooler, fit the OLED lead to J41, heat-set the inserts, close the lid.

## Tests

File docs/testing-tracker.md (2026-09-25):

# Testing tracker

Two levels, per AGENT.md: **Tested** = automated checks pass; **Validated** =
confirmed on real hardware or a real drive, with details. Simulation never sets
Validated.

## Software (`software/braindrain`)

| Interface / module | Tested | Validated | Test conditions | Notes |
|---|---|---|---|---|
| Policy / DIP decoding (`policy.py`) | yes, `tests/test_policy.py` | no | pytest | all 8 modes and flags |
| Safety fence (`devices.classify`) | yes, `tests/test_fence.py` | partial | `braindrain list` on the dev workstation refused the root NVMe and loop devices (2026-09-23) | needs a dock on Saturday |
| Host overwrite + verify (`methods/overwrite.py`, `verify.py`) | yes | no | sparse files, O_DIRECT with buffered fallback | random-pattern phase bug fixed 2026-09-22 |
| Canary verify for firmware wipes | yes | no | simulated firmware | |
| ATA firmware wrappers (`methods/ata.py`) | parser only, `tests/test_parsers.py` | **no** | fixtures written from hdparm 9.65 docs | status-output format must be confirmed on the bench |
| NVMe wrappers (`methods/nvme.py`) | parser only | no | nvme-cli JSON | no native NVMe until the board exists |
| Engine state machine, abort on unplug | yes, `tests/test_engine_sim.py` | no | simulated bays | |
| Bay 9 M.2 slot controller (bay 5 before C24) | yes, `tests/test_m2_bay.py` | no | simulated lid switch/PEDET | GPIO paths untested |
| Eight bays, two-column OLED layout, bay-card ports | yes, `tests/test_display.py`, `tests/test_config.py` | no | | slots 5–8 unpopulated in v1 |
| Certificates + crash recovery | yes | no | | schema v1 |
| Bench tool (`bench.py`) | yes, `tests/test_bench.py` | **planned 2026-09-26** | fake hdparm/smartctl | |
| Config file, headless HAL, setup-bay | yes, `tests/test_config.py` | no | | |
| Wi-Fi manager (`wifi.py`): AP, join, fallback, resets, key | yes, `tests/test_wifi.py` | no | simulated backend | nmcli backend written from the NetworkManager docs, untested |
| Phone page (`webui.py`): status, certificates, zip, join, reset, key check | yes, `tests/test_webui.py` | no | real HTTP on a local port | one intermittent failure seen once in a timing-based join test; passed 5/5 afterwards |
| Service mode (DIP 110): no wipe, Wi-Fi reset at boot, factory with DIP 8 | yes, `tests/test_service_mode.py` | no | | |
| Wi-Fi QR frame on the OLED | yes (matrix size, layout) | no | `docs/img/oled-wifi.png` from the real renderer | luma drawing untested |
| Real GPIO HAL (`hal/gpio.py`) | no | no | needs the carrier board | libgpiod v2 API from docs |
| OLED driver (`hal/oled.py`) | no | no | needs the panel | |
| systemd unit + install script | no | **planned 2026-09-26** | Raspberry Pi OS Lite on a Pi 5 | |

## Hardware (`hardware/`)

| Item | Tested | Validated | Conditions | Notes |
|---|---|---|---|---|
| Netlist (`design.py`) pin coverage | yes, `design.py` check | no | every pin assigned or NC | |
| Schematic ERC | yes: brain 0 findings, card 2 harmless library-copy warnings | no | kicad-cli 9.0.8 | `hardware/review/erc-summary.md` |
| Board DRC, brain (six layers) | yes: 0 errors, 0 unconnected, silkscreen and dangling-stub warnings | no | kicad-cli 9.0.8, `check_place.py` 0 problems | `hardware/review/drc-summary.md`; no independent review |
| Board DRC, bay card | yes: 0 errors, 0 unconnected | no | same | |
| Differential-pair matching | yes: 44 + 8 pairs under 0.15 mm end to end | no | `route.py pairs` | no impedance calculation, no simulation; segment-level mismatch up to 6 mm |
| Symbols from datasheet tables | yes | no | CM5 datasheet, USB5744 DS00001855M, ASM1153E Rev 0.4 | |
| FET pin tables (AON7403, AO4407A) | yes, read against the datasheets | no | AOS datasheets | S 1-3, G 4, D 5-8 (+ EP) |
| Footprints: PCIe x1 socket, SATA receptacle, KPJX-4S-S, RPA0010A | generated from vendor drawings | no | Amphenol 10018784, Molex SD-47018-001, Kycon, TI | Molex face position and socket housing ends assumed |
| Footprints: CM5 module, M.2 socket | copied from CM5IO rev 2 | no | Raspberry Pi design files | M.2 pegs vs TE drawing pending (R2) |
| Generated BOM | yes, every part mapped | no | `gen_bom.py` | `verify` lines need a stock and rating check |
| USB-SATA bridge Sanitize passthrough | | **planned 2026-09-26** | ASM1153E dock | closes C12 with evidence |
| Signal integrity, power integrity, thermal | no | no | | nothing simulated |

## Enclosure (`enclosure/`)

| Item | Tested | Validated | Conditions | Notes |
|---|---|---|---|---|
| Tray / hinged lid / bezel STL export (v2 box) | yes, OpenSCAD 2021.01 | no | no warnings | no print yet |
| Hinge, latch, lid-open scene | yes | no | renders in `docs/img/renders/` | hinge pin fit and latch force need a print |
| Cutout fit against real connectors | no | no | | first print |

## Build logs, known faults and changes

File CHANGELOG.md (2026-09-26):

# Changelog

All notable changes to brain-drain. Format follows Keep a Changelog; versions
are software versions (`software/pyproject.toml`), hardware and enclosure
revisions are noted in the entries.

## [Unreleased]

### Added
- Bay-card retention (C30): comb of ribs under the lid between the cards' receptacles and grooved blocks in the tray under each
  card's rear overhang (`shell.scad`, `enclosure/tools/check_fit.py` checks the clearances).
- Branding (C30): the octopus logo and name engraved 0.6 mm into the lid (`enclosure/tools/gen_logo.py`); logo, name, tagline and the
  repository URL as top silkscreen on the brain board and the name on the bay card (`hardware/tools/branding.py`, run by
  `route_full.sh`, adds no DRC warnings).
### Changed
- Input fuse F1 15 A slow-blow (0453015.MR) instead of 10 A (C31); netlist, schematic, BOM and docs updated; the reverse-polarity FET rating is flagged for review.
- `BRAIN-DRAIN-CONTEXT.md` (project context), `AGENT.md` (rules only, updated for the final design: generated-file list, both-board checks, `check_fit.py`, revision in `branding.py`, BOM and render regeneration) and `CLAUDE.md` (local Claude Code details: RTK, environments, commit style).
- Silkscreen logo simplified for fab printing (no drive icons, bold single-line tentacles, 0.2-0.3 mm strokes, 32 mm wide instead of 24) and the tagline now says eight-bay; the product description in the logo, package metadata and docstring says eight-bay too.
### Fixed
- Lid features (receptacle windows, OLED, DIP slot, LED holes, CM5 grille) were mirrored front to back in the lid model; they now sit
  over the parts. All renders regenerated.
- Architecture, BOM, decisions log (C1–C19) and decision briefs.
- `braindrain` sanitizer service: engine, NIST 800-88 Rev. 2 policy, safety
  fence, host overwrite and firmware wrappers, verification, certificates,
  simulation mode, bay 5 M.2 slot controller, bench tool, headless Pi
  deployment (61 tests).
- Generated KiCad 9 schematic (14 sheets, 0 ERC errors) and board (180 × 110 mm,
  307 footprints, net classes, copper zones) from `hardware/tools/design.py`;
  symbol and footprint generators; routing pipeline via freerouting.
- Parametric OpenSCAD enclosure: tray, lid, hinged door, OLED bezel, drive rack.
- Documentation set, diagrams, renders, logo.

### Added
- **Wireless (C22):** Wi-Fi access point with an ephemeral key and a QR code on the OLED, the
  phone page (`webui.py`: status, certificates, log, join a network, Wi-Fi / factory reset with the
  key), `wifi.py` (nmcli backend, simulated backend), DIP service mode 110, `braindrain wifi-reset`.
  13 new tests (74 total). Dependency: `qrcode`.
- `docs/FABRICATION.md`: small-run assembly vendors, cost estimate, order gates and checklist.

### Added
- **Engineer hand-off and full renders (2026-09-25):** `docs/LAYOUT-REVIEW.md` (deliverables, how the boards were made, priority review items with data, assumptions table, tool inventory, sign-off checklist), `hardware/review/` (generated design rules, stack-up, planes, keep-outs, routing statistics, DRC/ERC, footprint provenance, netlists, placement CSVs, schematic PDFs; `make_review_pack.py`), per-layer PCB images, a BOM generated from both designs (`gen_bom.py`, `docs/BOM.md`, CSVs), `docs/RENDERS.md` and 29 new renders (boards one at a time, the assembled electronics, case, unit open, exploded, cut-away, complete system; `enclosure/tools/gallery.py`, `render3d.py`, `hardware/tools/board_model.py`). ARCHITECTURE, STATUS, README, hardware and enclosure READMEs, USAGE, FABRICATION and the testing tracker rewritten for the current design. `via-clean` removes overlapping and dangling vias; `export_fab.sh` handles both boards; `gen_sch.py` removes stale sheet files.
- **Enclosure mirror fix:** `board.scad` stored KiCad coordinates unmirrored, which put every left/right feature (DIN, USB-C, microSD, the antenna side, the slot order) on the wrong side of the tray; x is now mirrored in `kicad_to_scad.py`, the scene and the diagrams undo it.
- **End-to-end pair matching and the plane fix (2026-09-25):** length matching now counts the whole path across the series coupling caps (`cap_links`, `chain_offset`); the pair report has an end-to-end skew column; `tools/fix_pairs.sh` retries stubborn pairs with several strategies and keeps the best. The +12V corner polygon on In4 (which left slot 1's two 5 V contacts on tiny islands) is replaced by a strip across the slot row plus a channel to the power island (distinct priorities). Final: brain 0 open, 0 DRC errors, 44/44 pairs; card 0 open, 0 DRC errors, 8/8 pairs.
- **Rail gaps, pairs, gap-router precision (2026-09-25):** the three rail gaps and all pair mismatches on the brain are closed (0 open signal connections, 44/44 pairs matched, DRC 0 errors). Gap router: grid margins, plain holes count as board edges, fallback 0.3/0.15 via, `BD_RES` (0.05 mm grid) and `BD_MARGIN` for pins with almost no room. Pair coupling caps are placed side by side (`gen_pcb.pair_key`).
- **Real connector footprints (2026-09-25):** the PCIe x1 slot from the Amphenol FCI customer drawing (four rows of 0.70 mm holes at 2.0 mm pitch, pegs at 11.65 / 20.80, housing 25 × 8.8) and the SATA receptacle from the Molex drawing SD-47018-001 (22 pads at 1.27 mm, 40.46 mm wide). The card grew to 45 × 46 mm (C27) with its fingers 6 mm from the front edge, overhanging the board's rear edge by 15 mm; enclosure: 16 mm rear extension, lid windows 11.8 × 43 mm over the receptacles. TE 1-1734774-1 is a 98-position x8 part and was removed as an alternative. Results: card 0 open, 0 DRC errors, 8/8 pairs matched; brain 5 open (three tiny rail gaps, two zone notes), 0 DRC errors, 42/44 pairs matched.
- **Six-layer brain (C26, 2026-09-24):** F sig / In1 GND / In2 sig / In3 sig / In4 power / B sig. Full unattended flow: 2 connections open (was 10 on four layers), 0 DRC errors, all 44 pairs routed, 43 matched; flow time 85 minutes (was 3.5 hours). The gap router routes on every signal layer.
- **Bottom-side bypass caps (2026-09-24):** the ten supply bypass capacitors of each USB hub are generated on the bottom in two rows around the chip. Open supply pins went from 25 to none; the brain now has 10 open (8 pair ends, the fan tach, one inner-plane island), 43 of 44 pairs matched, DRC 0 copper errors. `gapclose.py` also has an experimental rip-up mode (`BD_RIPUP=1`) that crosses other nets at a price and removes what it crosses; it did not converge (open count went 10, 21, 29, 25 over three rounds) and is off by default.
- **Pairs-first routing and gap closer (2026-09-24):** `tools/route_full.sh` regenerates the board and routes the differential pairs first on the empty board (`stage0`, `BD_PAIRS_FIRST=1`) so their escapes from the 0.4 mm-pitch pins are free; single-ended stages route around them. `route.py close-gaps` and `close-gaps-pairs` (`tools/gapclose.py`) is a small grid A* router (0.1 mm cells, both outer layers, vias, adaptive search window, pair sides hug their partner) that closes what the autorouter leaves; every route is DRC-checked and removed whole if flagged. `route.py rip-pairs` and `tools/reroute_pairs.sh` handle pairs the tuner cannot fix. Results: card 1 open, 0 DRC errors, 8/8 pairs matched; brain 9 open (was 43), 0 copper errors, 41/44 pairs matched.
- `tools/pcbfix.py`: generated boards carried duplicate pad UUIDs (363 on the brain), so DRC reported the wrong slot pad; they are now made unique at generation.
- **Length tuner (`route.py tune`, 2026-09-24):** meanders the shorter side of every routed differential pair (rectangular bumps 0.5 mm wide, up to 4 mm tall, layer-aware collision checks, keep-outs respected, last bump cut to the exact remainder). Skew now counts 0.6 mm per via. Bay card: 5 of 8 pairs matched to under 0.01 mm; brain: 26 pairs tuned, 10 left (sides unrouted or more than 40 mm apart). No new DRC errors on either board. Part of `route_chain.sh`.

### Fixed
- **P-FET pin-out (2026-09-23):** Q20 (AO4407A, SO-8) and the bay cards' Q1 / Q2 (DFN 3x3) used the
  generic three-pin `Q_PMOS_GSD` symbol, which put gate, source and drain on pads 1, 2 and 3; on these
  8-pin power packages pads 1–3 are all source, 4 is the gate and 5–8 (plus the exposed pad) the drain.
  New library symbols `PMOS_SSSGDDDD` / `PMOS_SSSGDDDD_EP` carry the real numbering; `route.py
  update-nets` re-syncs the pad nets on the routed boards and the router finishes the moved pins.
- `gen_sch.py` wiped the board design rules (0.3 mm via, 0.15 mm hole) from the project file on every
  run; it now keeps them, and both projects have them again.

### Changed
- **Brain + bay cards (C24, D9 option A, 2026-09-23):** the design is split into a brain board
  (150 × 122 mm: CM5 on the right edge, two hubs with all four downstream ports, eight PCIe-x1
  bay slots along the rear with the bay LEDs, M.2 bay 9, DIN / USB-C / microSD on the left wall)
  and one bay-card design (40 × 46 mm: ASM1153E, switched 12 V / 5 V with PTC fuses, SATA 22-pin
  receptacle on top, PCIe-x1 fingers). Four cards fitted in v1, slots 5–8 for expansion. Second
  KiCad project `hardware/bay-card/` from the same generators (`BD_PROJECT=brain|card`, `project.py`);
  slot pinout in `symgen.SLOT_PINS`; placeholder socket footprint. Software: eight bays (bay ports
  1-1.1..1-1.4 and 2-1.1..2-1.4, BAY_EN GPIOs 5,6,12,13,7,8,9,10), M.2 is bay 9, two-column OLED
  layout above five bays. Enclosure: 50 mm above the board, eight lid windows for the card
  receptacles, left-wall cutouts, vents on the right and rear; about 157 × 129 × 62 mm. Docs, BOM
  (card table), fabrication (two boards, panelised cards) and cost table updated.
- D8 applied: 0.3 / 0.15 mm dog-bone vias on the QFN supply pins (`fanout_qfn`); unattended routing
  chain `tools/route_chain.sh` (stage 2 → stage 3 → DRC clean → fanouts → reports → renders).
- Board v3 (D7 option B): 150 × 112 mm, 2.5 mm around every QFN, hubs under the CM5 USB 3 pins, M.2
  front-right; pipeline rerun: 733 / 884 connections (83 %), 3300 segments, 738 vias, DRC copper-clean,
  21 of 48 pairs routed (unmatched). The connector fanout no longer touches QFNs (its via ring blocked
  the neighbouring pins); D8 proposes 0.3/0.15 mm vias for the QFN supply pins as the next lever.
- Staged autorouting completed as far as the tools go (2026-09-23): 719 / 884 connections (81 %), 3175
  segments, 658 vias, DRC copper-clean. Tooling: staged runs with locked routes (`stage1/2/3`), `-inc`
  class ignoring, `BD_ROUTER=2.4.1` / `BD_PASSES` for the newer bounded router, `drc-clean`, geometry-aware
  fanout collision checks (`Occupancy`), row-fitted connector fanout with orientation-correct pad sizes,
  exposed-pad ties, DRC-driven open-pad detection, `pair_report`, `open_report`. What remains is listed in
  `hardware/routing/open.md` and `pairs.md` and decision D7.
- Routing rerun on the v2 outline: all 75 single-ended signal nets routed (930 segments, 214 vias); the
  fanout now checks the plane polygon, not its bounding box; `route.py prepare` writes the net classes
  into the project file (their only home) and `gen_sch.py` preserves them; session import strips
  anything crossing a keep-out; board renders cropped to the outline; schematic renders regenerated by
  the same script.
- **v2 outline (C22–C23):** 136 × 100 mm, no Ethernet (magjack and CM5 PHY pins dropped), no
  buzzer, passive CM5 cooler (fan header kept), CM5 wireless with its antenna edge on the left
  board edge and a copper-free strip under it; DIN / USB-C / microSD on the right wall; the M.2
  lies along the front under a lid hinged along the rear with a snap latch (lid microswitch is the
  bay-5 door). Enclosure about 143 × 107 × 32 mm; scene render of the lid open. Wall panel
  diagrams now rear and right.
- **Portable "brain box" (C21, 2026-09-23):** the board is re-laid out at 150 × 98 mm with the four
  SATA receptacles on the rear edge, DIN / RJ45 / USB-C on the left wall, microSD and the M.2 SSD
  slot on the front wall, the CM5 in landscape, CR2032 holder and buzzer on the bottom side. The
  enclosure is a closed box of about 157 × 105 × 39 mm with an M.2 slot door on the front; the drive
  rack is removed, drives lie loose on 22-pin cables. Placement is checked by `check_place.py`;
  board renders come from `render_board.sh`. The v0 autoroute was discarded with the outline (R16).
- Enclosure preview renderer: camera matrices fixed (world up is up, viewer above the cable side),
  large triangles subdivided so the painter's sort no longer draws walls over the lid.
- Option B (bridges in the cables, ~90 × 70 mm board) recorded as D6 for a later study.

### Fixed
- Board generator: pad angles now follow footprint rotation (KiCad stores them absolute), which
  removed the overlapping pads on every rotated fine-pitch part; region packer with capacity checks
  and a spill area; DIN jack pads shorter than their pitch; M.2 footprint mask margins removed;
  USB-C moved to the left wall; DRC now reports 0 errors before routing.
- Routing: freerouting 2.1.0 (Java 21) on the single-ended non-bay nets: 71 nets, 630 segments, 68 vias imported; tracks that crossed the CM5 standoff clearance were removed and circular keep-outs added for future runs.

### Dependencies
- Python: pyudev; dev: pytest, ruff, pillow, numpy, cairosvg; hw: gpiod, luma.oled, smbus2.
- Tools (not vendored): KiCad 9.0.8, OpenSCAD 2021.01, freerouting 2.1.0 jar (downloaded into `hardware/tools/freerouting/`, gitignored), Java 21.

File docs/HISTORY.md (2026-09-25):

# Project history

Short session log so a reader (or an agent) knows how the repository got here.
Details are in `DECISIONS.md`, `CHANGELOG.md` and the git log.

| Date | What happened |
|---|---|
| 2026-09-21 | Repo scaffolded: architecture, BOM, decisions. Found that the CM4 has no native USB 3; proposed a PCIe xHCI, then moved the design to the CM5 (C7) after pricing showed a $10 gap. |
| 2026-09-22 | Software first: engine, policy, fence, overwrite/verify, certificates, simulator (45 tests). UX simplified to "plug in = wipe, unplug = abort", no button (C10). Decision brief on hub, bridge, input connector, LEDs, M.2; owner chose USB5744, ASM1153E, 4-pin DIN, 3 mm LEDs, populated M.2 (C11–C15). |
| 2026-09-23 | Schematic generated from a single netlist (0 ERC errors), footprints from vendor drawings, board outline A (C19), placement generator. Bay 5 software, bench tool, Pi deployment for the 2026-09-26 bench. Enclosure v1 and refinements. CM5IO reference design files used to fix the CM5 footprint, M.2 footprint and several control-pin details. Docs, diagrams, renders, logo, AGENT.md; autoroute pass on non-bay nets. Later the same day the owner redirected the product to a portable box with drives on cables (no rack): options A/B/C briefed, A chosen, B parked (C21, D6); board re-laid out at 150 × 98 mm, enclosure v1 box, renders redone. Then, same session: passive cooler, keep the M.2 but open the lid for it, drop Ethernet, drop the buzzer, Wi-Fi access point with a QR code on the OLED and a phone page with join/reset (C22–C23); board v2 at 136 × 100 mm with the antenna edge, hinged-lid enclosure, fabrication vendor page. |

| 2026-09-23 (evening) | Portable "brain box" (C21–C23): cabled drives, no Ethernet, no buzzer, Wi-Fi AP with a QR code and a phone page, hinged lid. Staged autorouting reached 83 % on the monolithic v3 board; D8 small vias applied. Then the split into a brain and plug-in bay cards (C24, eight slots, four fitted) with a second KiCad project, eight-bay software and a taller enclosure; routing chains launched on both boards. |
| 2026-09-24 to 25 | Routing brought to completion: pairs routed first, a grid gap router, a length tuner, bottom-side hub bypass caps, six layers for the brain (C26), real footprints from the Amphenol and Molex drawings and the 45 mm card with a 15 mm rear overhang (C27), end-to-end pair matching. Both boards 0 open connections and 0 DRC errors. Enclosure x-mirror bug found and fixed. Full render gallery, generated BOM and review pack, and the engineer hand-off guide written. |

Rules of engagement that shaped the work: the owner makes every decision
(interview style, one question at a time); every pin comes from a datasheet
table saved in the repo; generated files are never hand-edited.

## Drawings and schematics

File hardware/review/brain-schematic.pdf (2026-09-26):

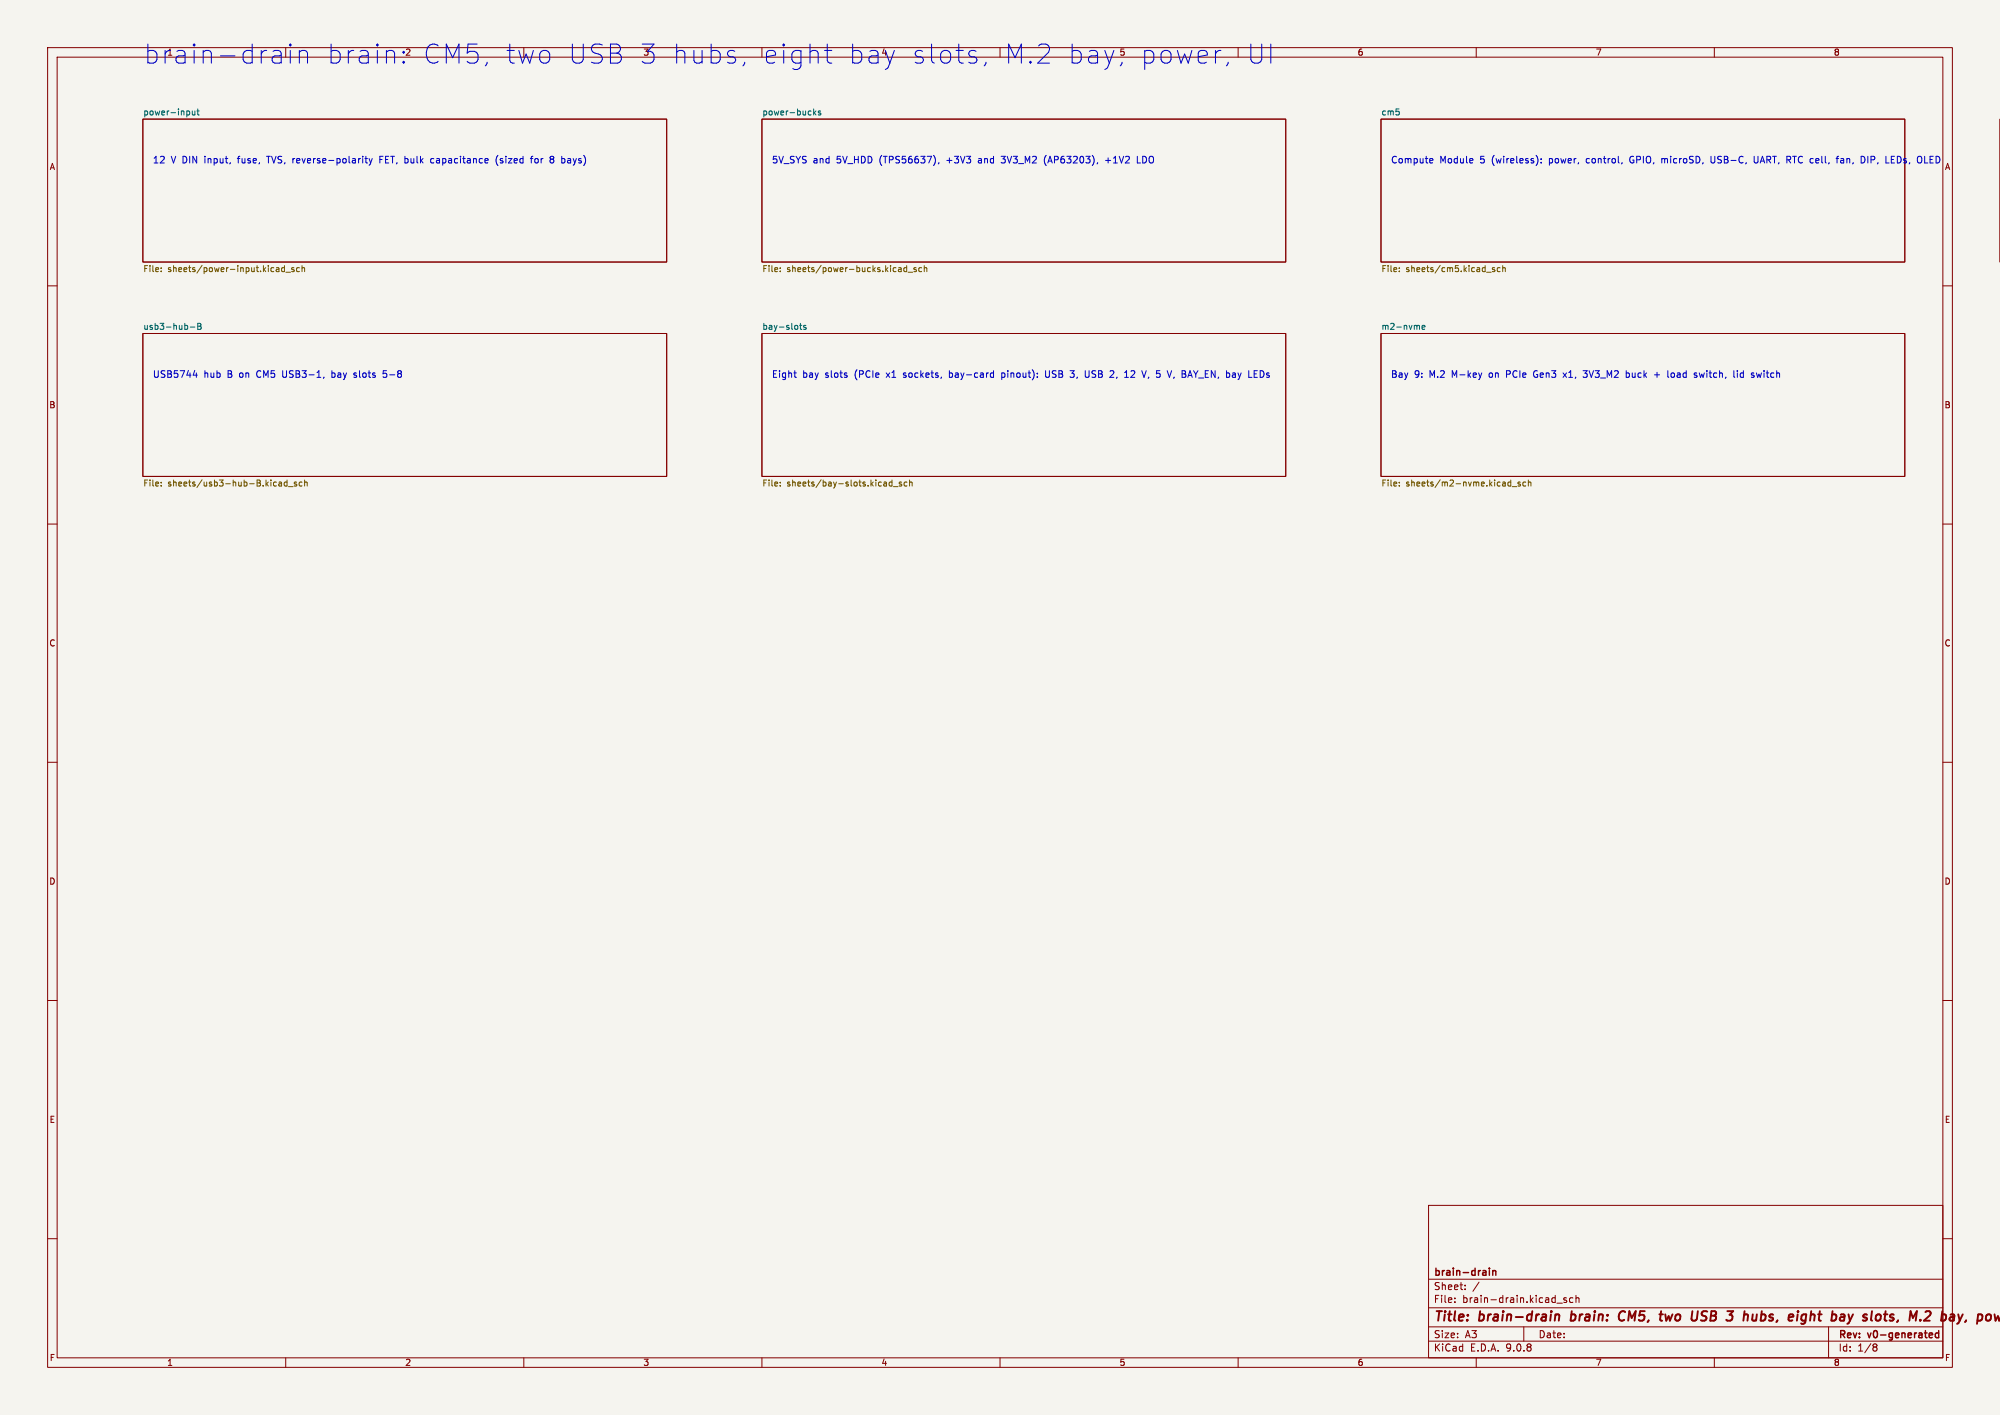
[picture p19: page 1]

power-input File: sheets/power-input.kicad_sch

power-bucks File: sheets/power-bucks.kicad_sch

File: sheets/usb3-hub-A.kicad_sch m2-nvme File: sheets/m2-nvme.kicad_sch

bay-slots File: sheets/bay-slots.kicad_sch

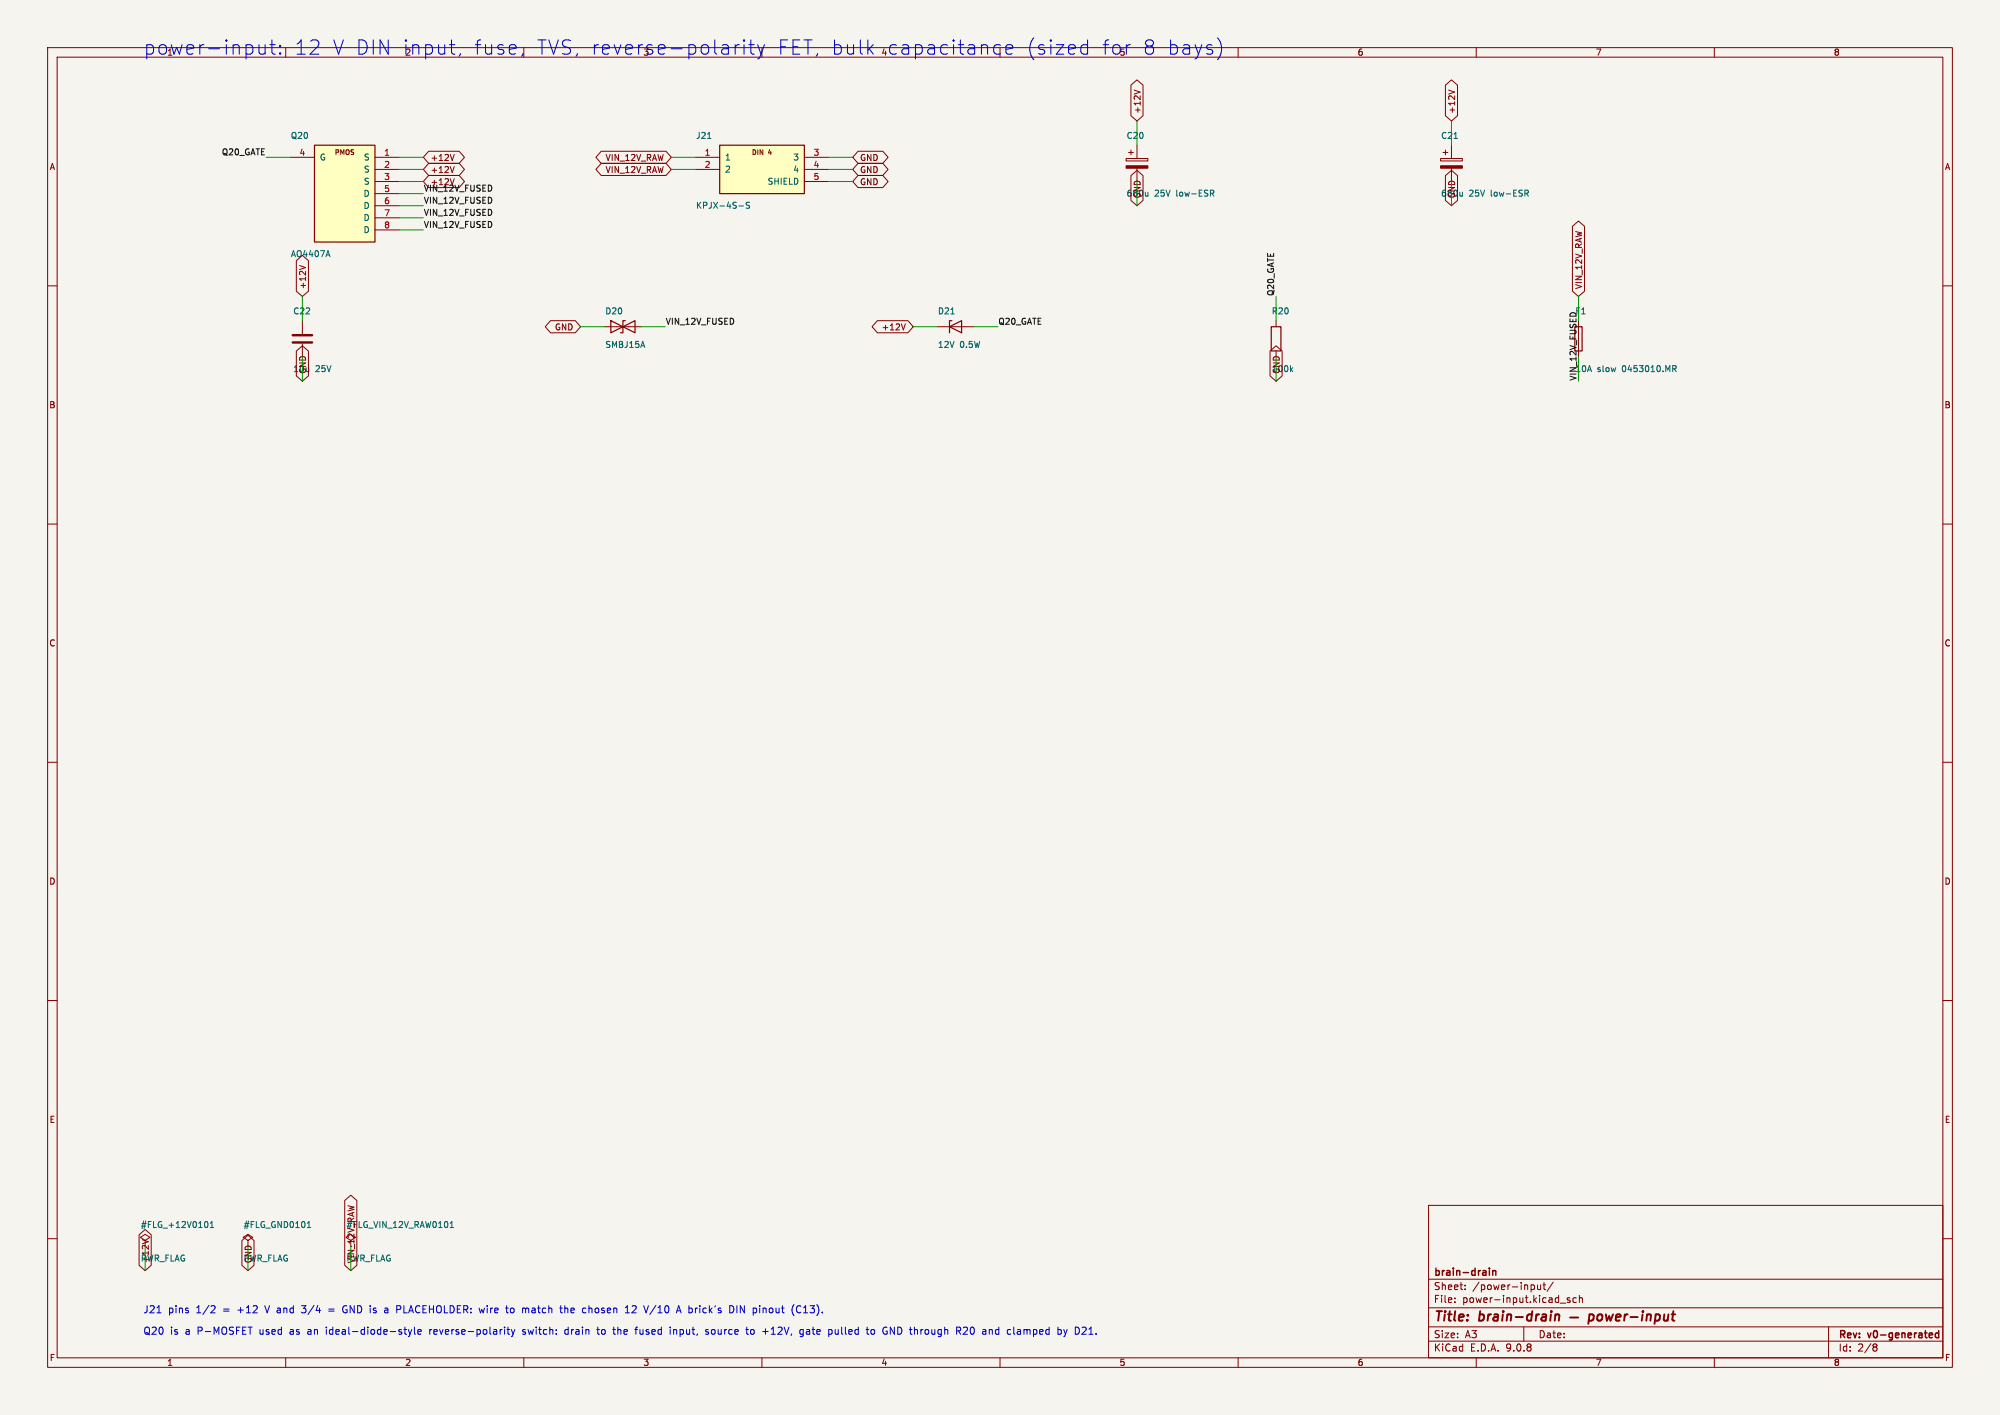
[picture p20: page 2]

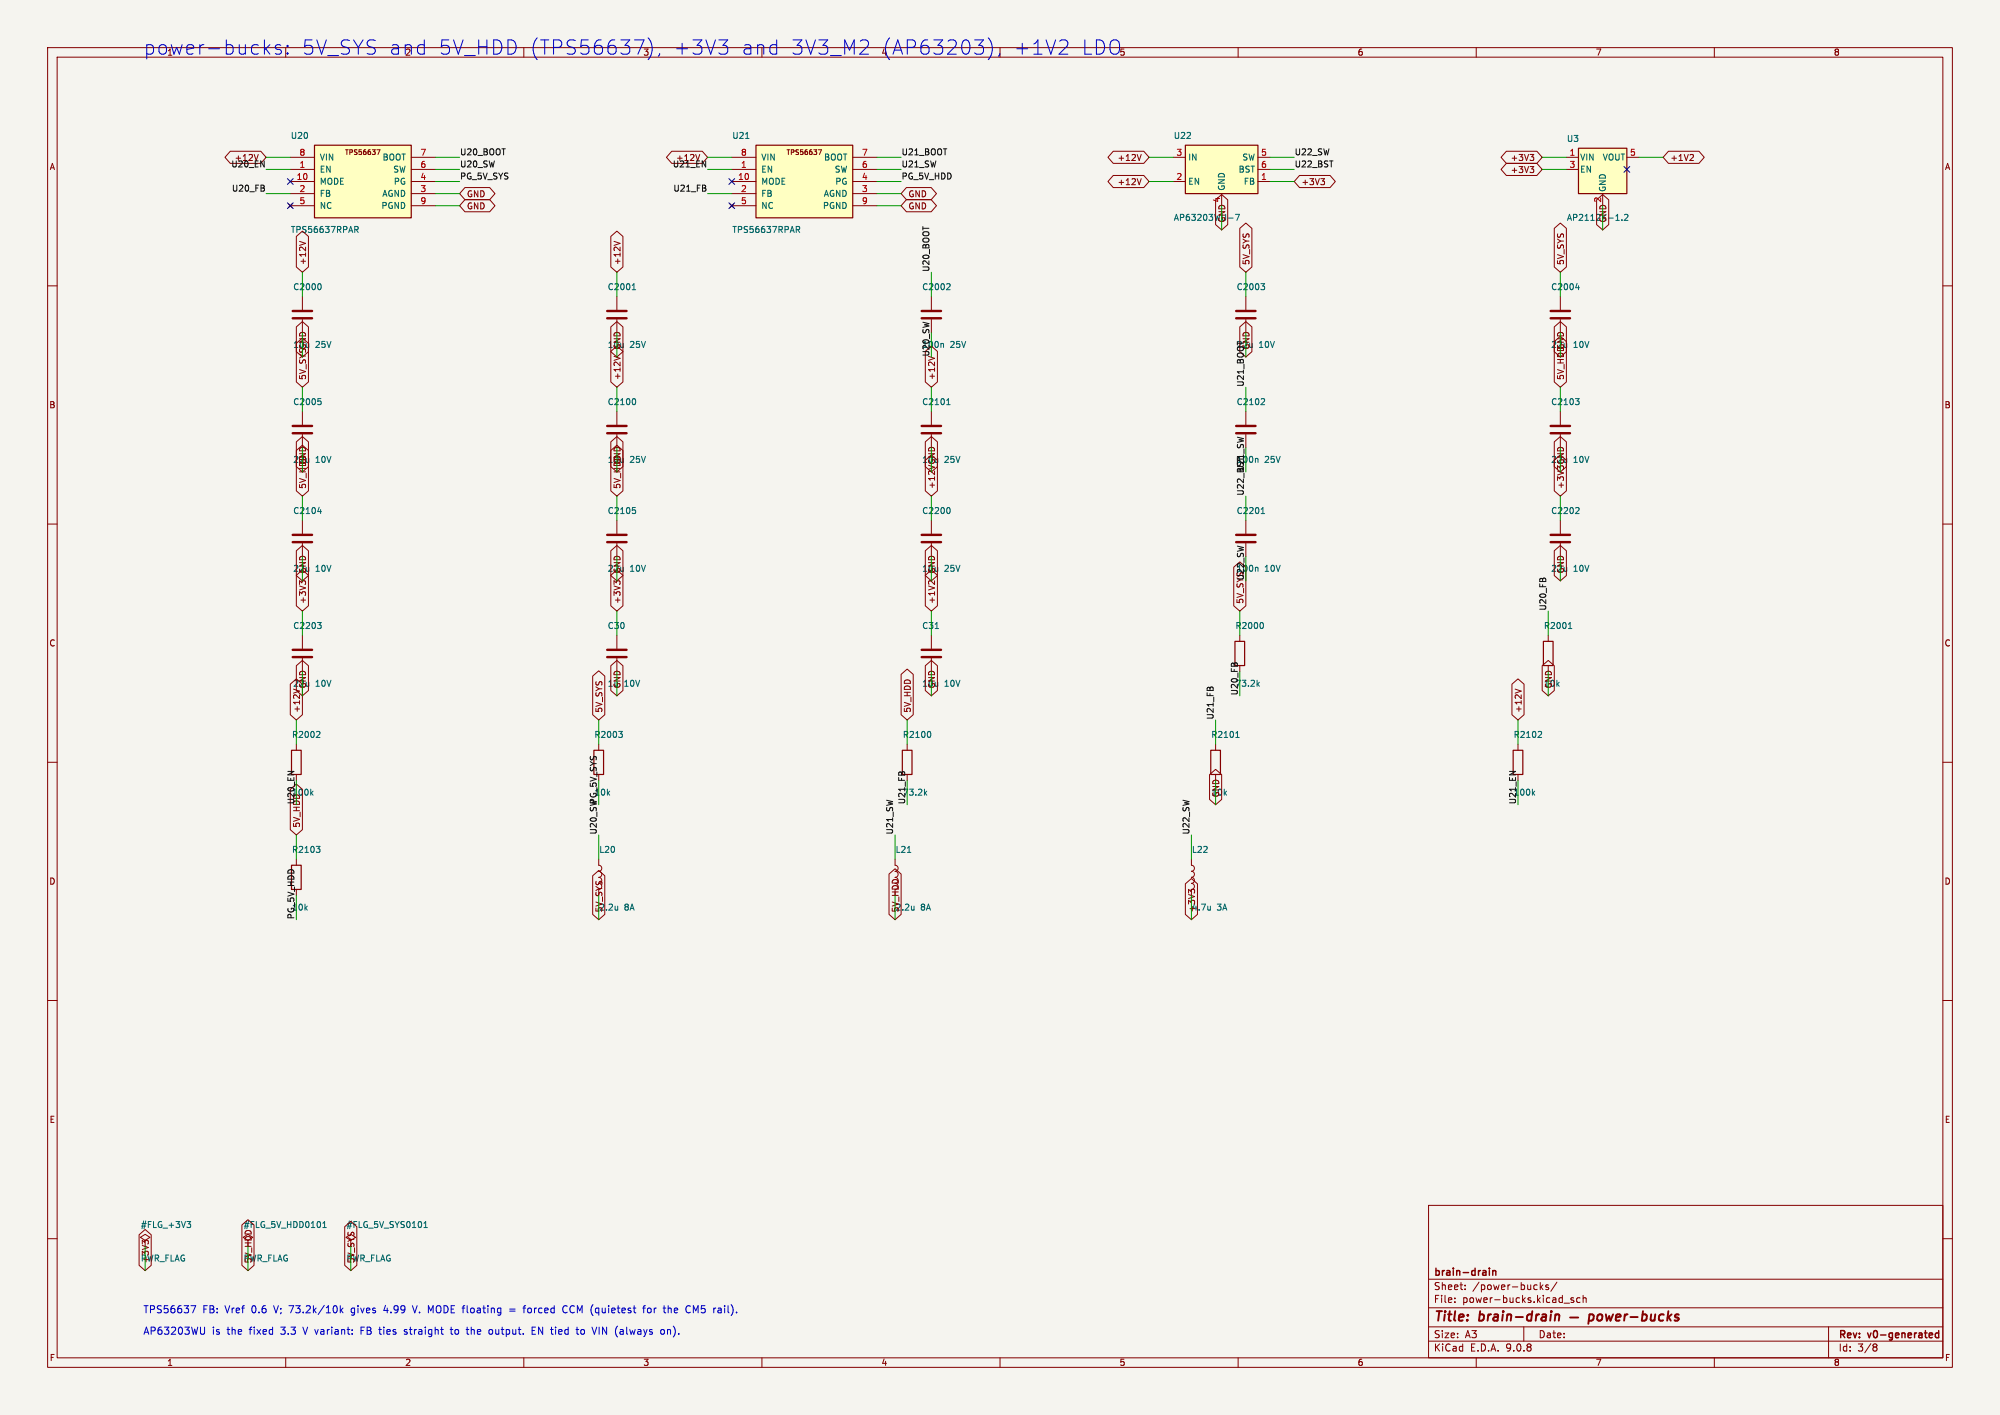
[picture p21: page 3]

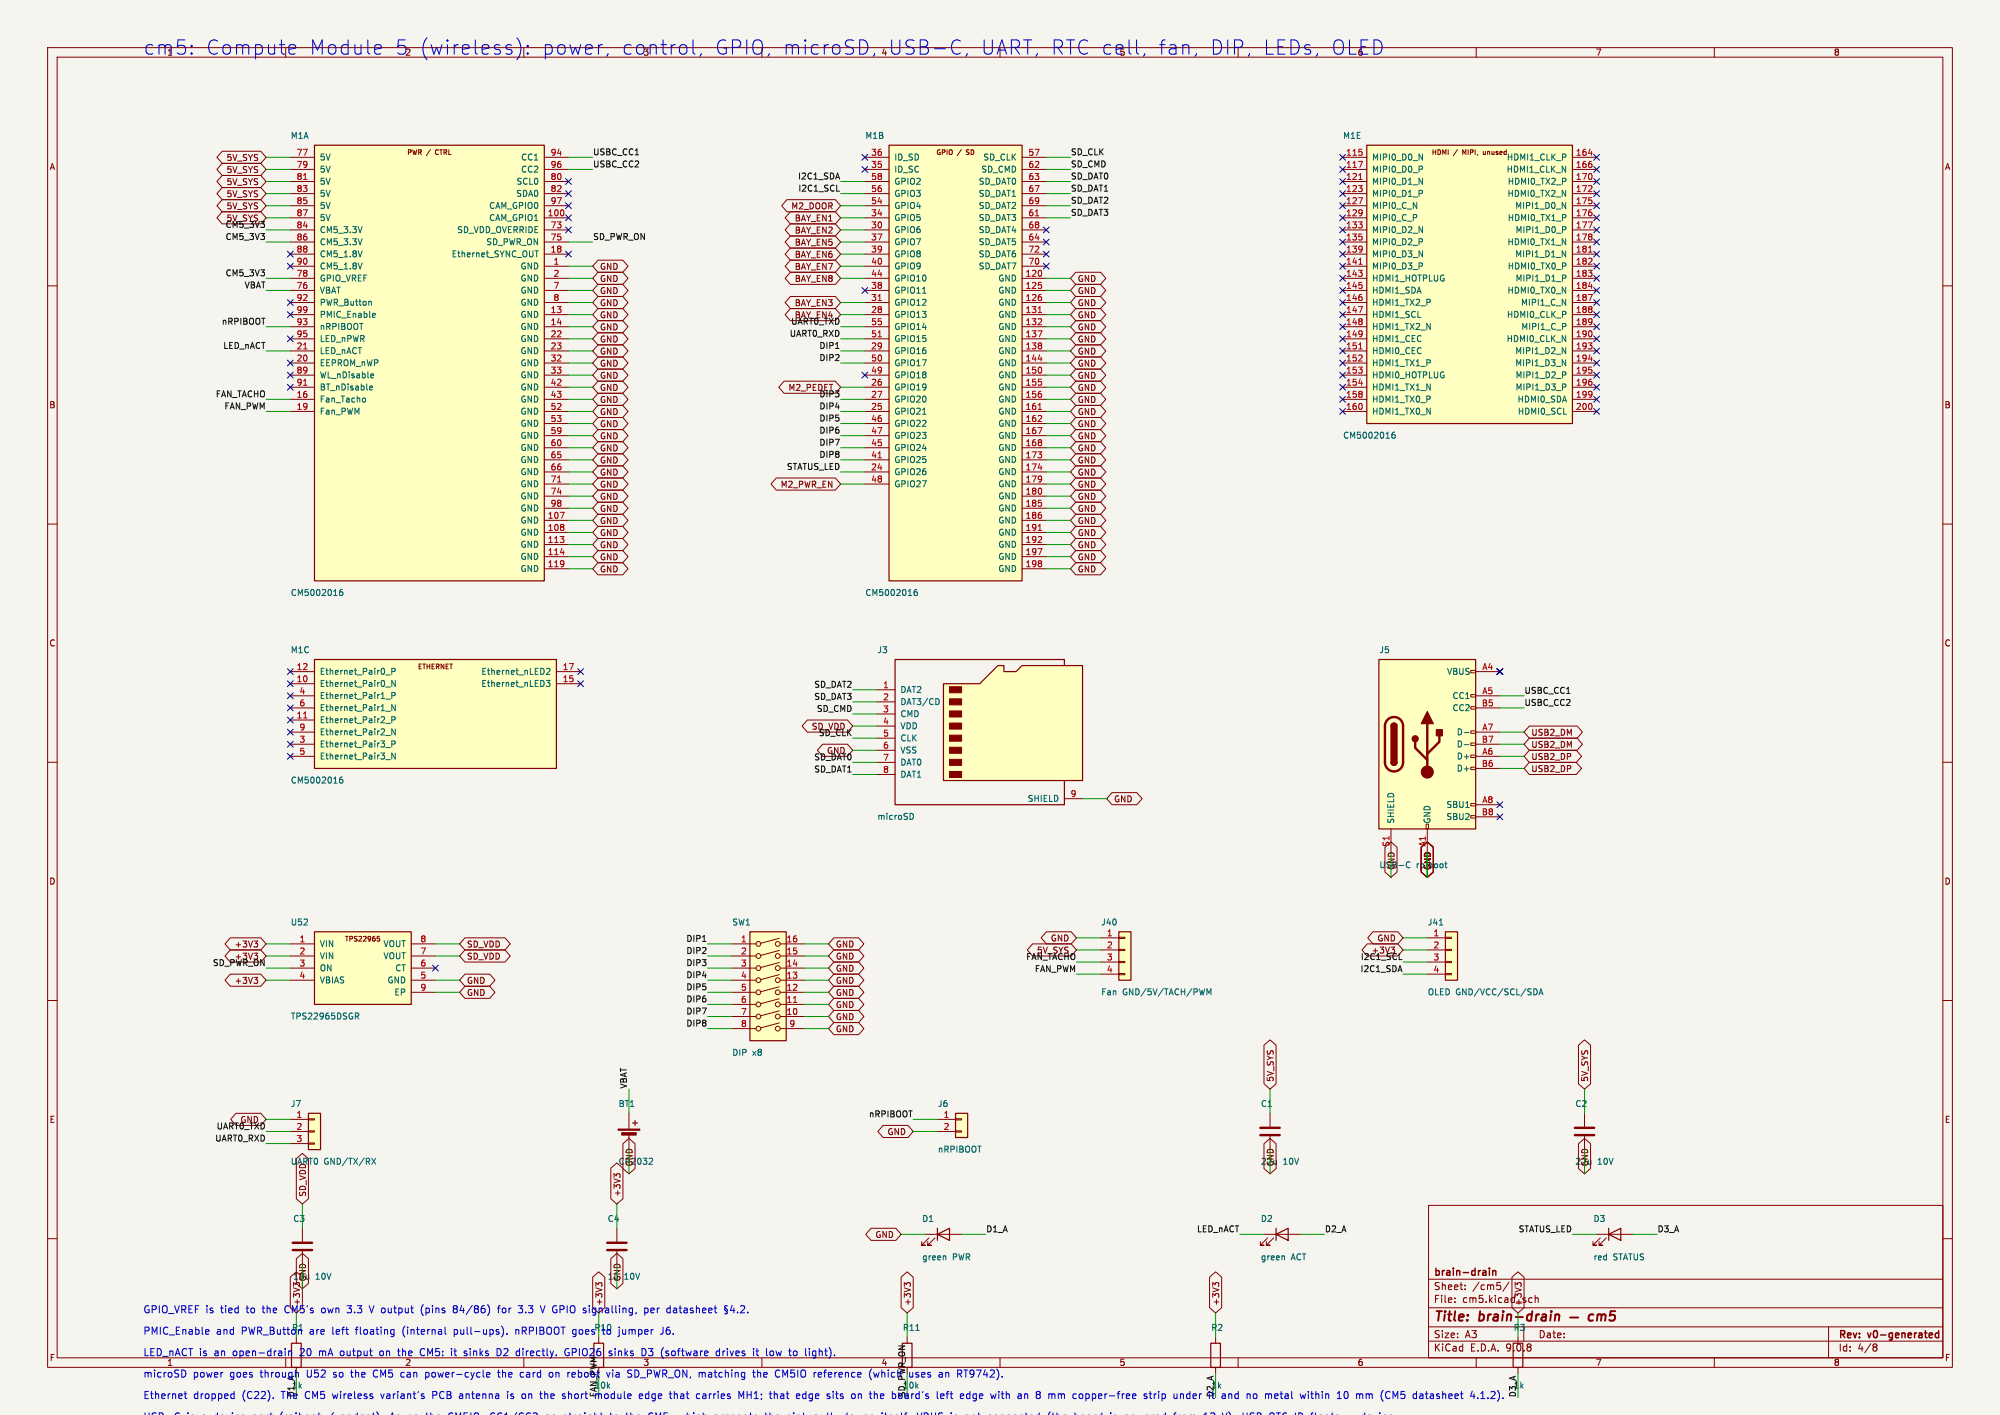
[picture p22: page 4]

J41 OLED GND/VCC/SCL/SDA R1

File: cm5.kicad_sch Sheet: /cm5/ brain-drain

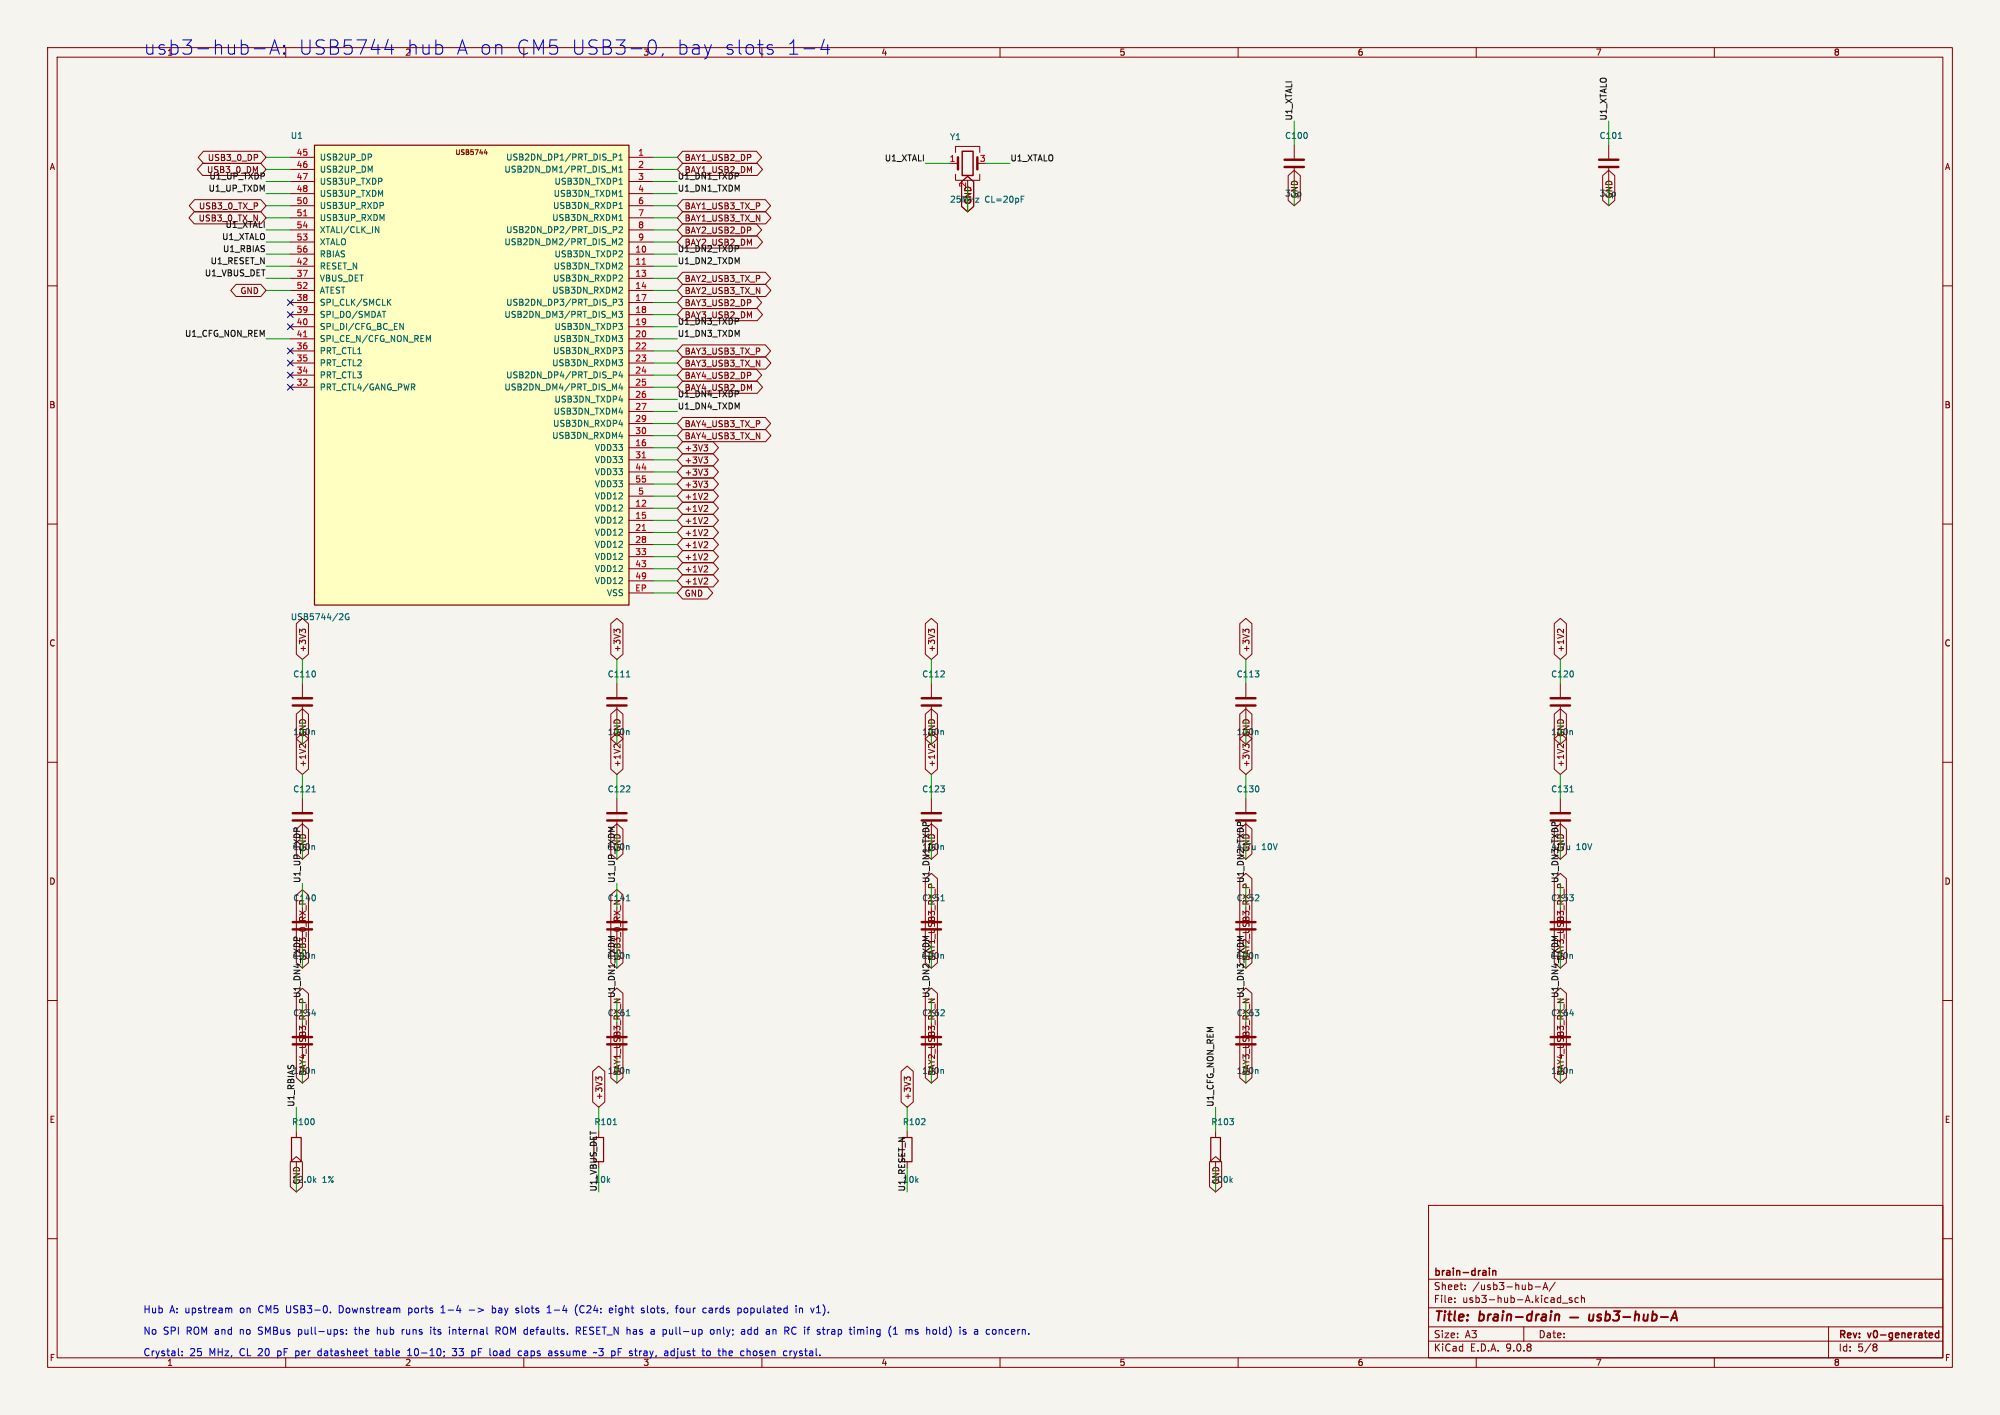
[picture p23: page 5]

File: usb3-hub-A.kicad_sch Sheet: /usb3-hub-A/ brain-drain

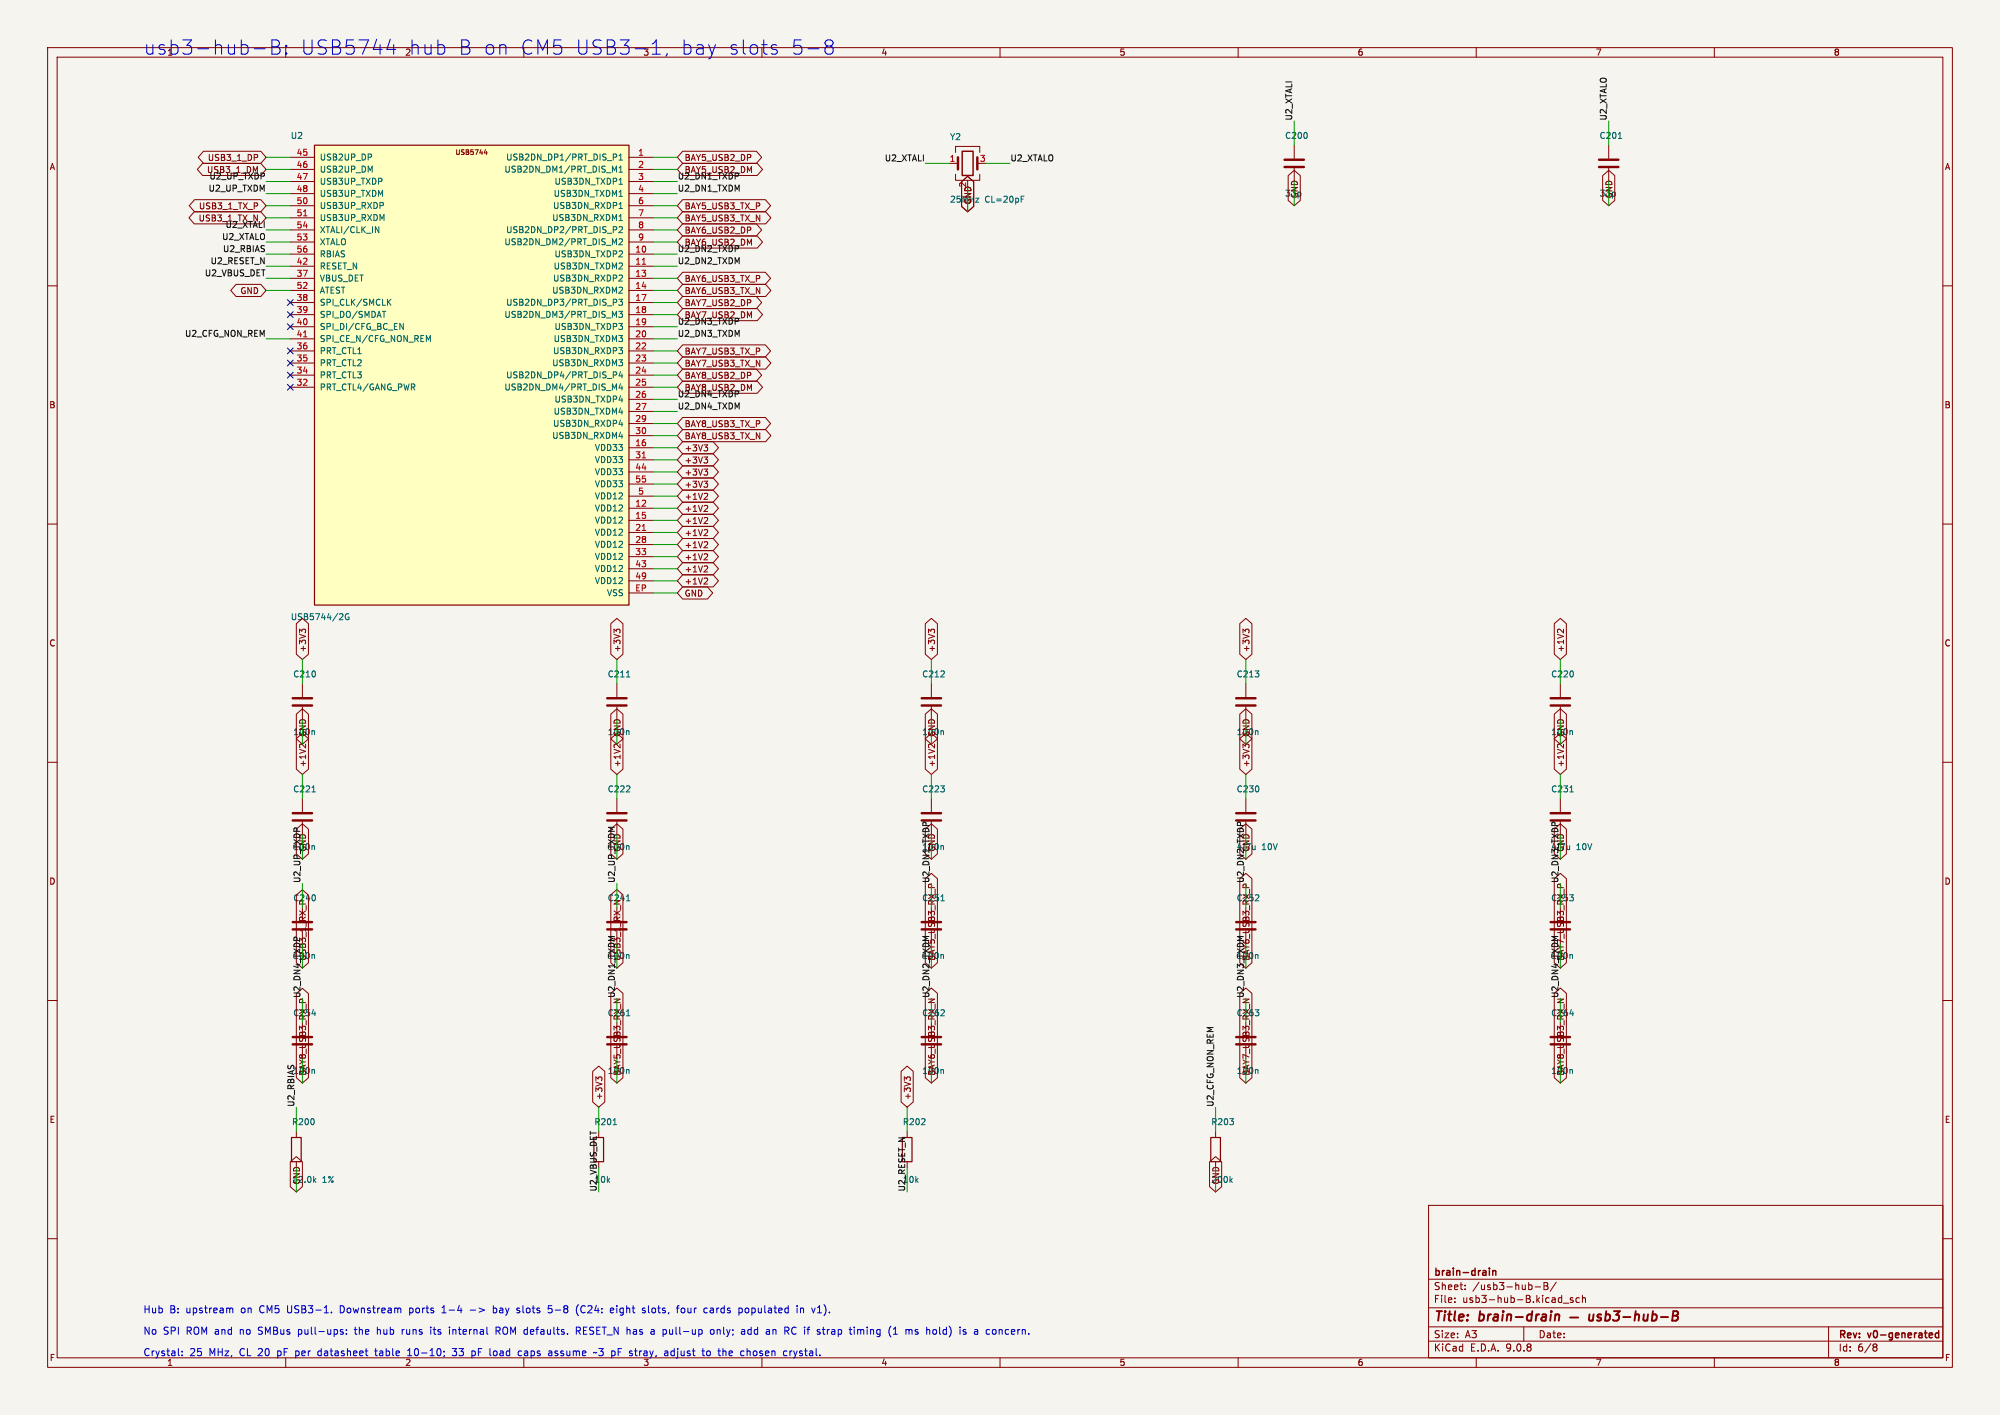
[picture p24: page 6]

File: usb3-hub-B.kicad_sch Sheet: /usb3-hub-B/ brain-drain

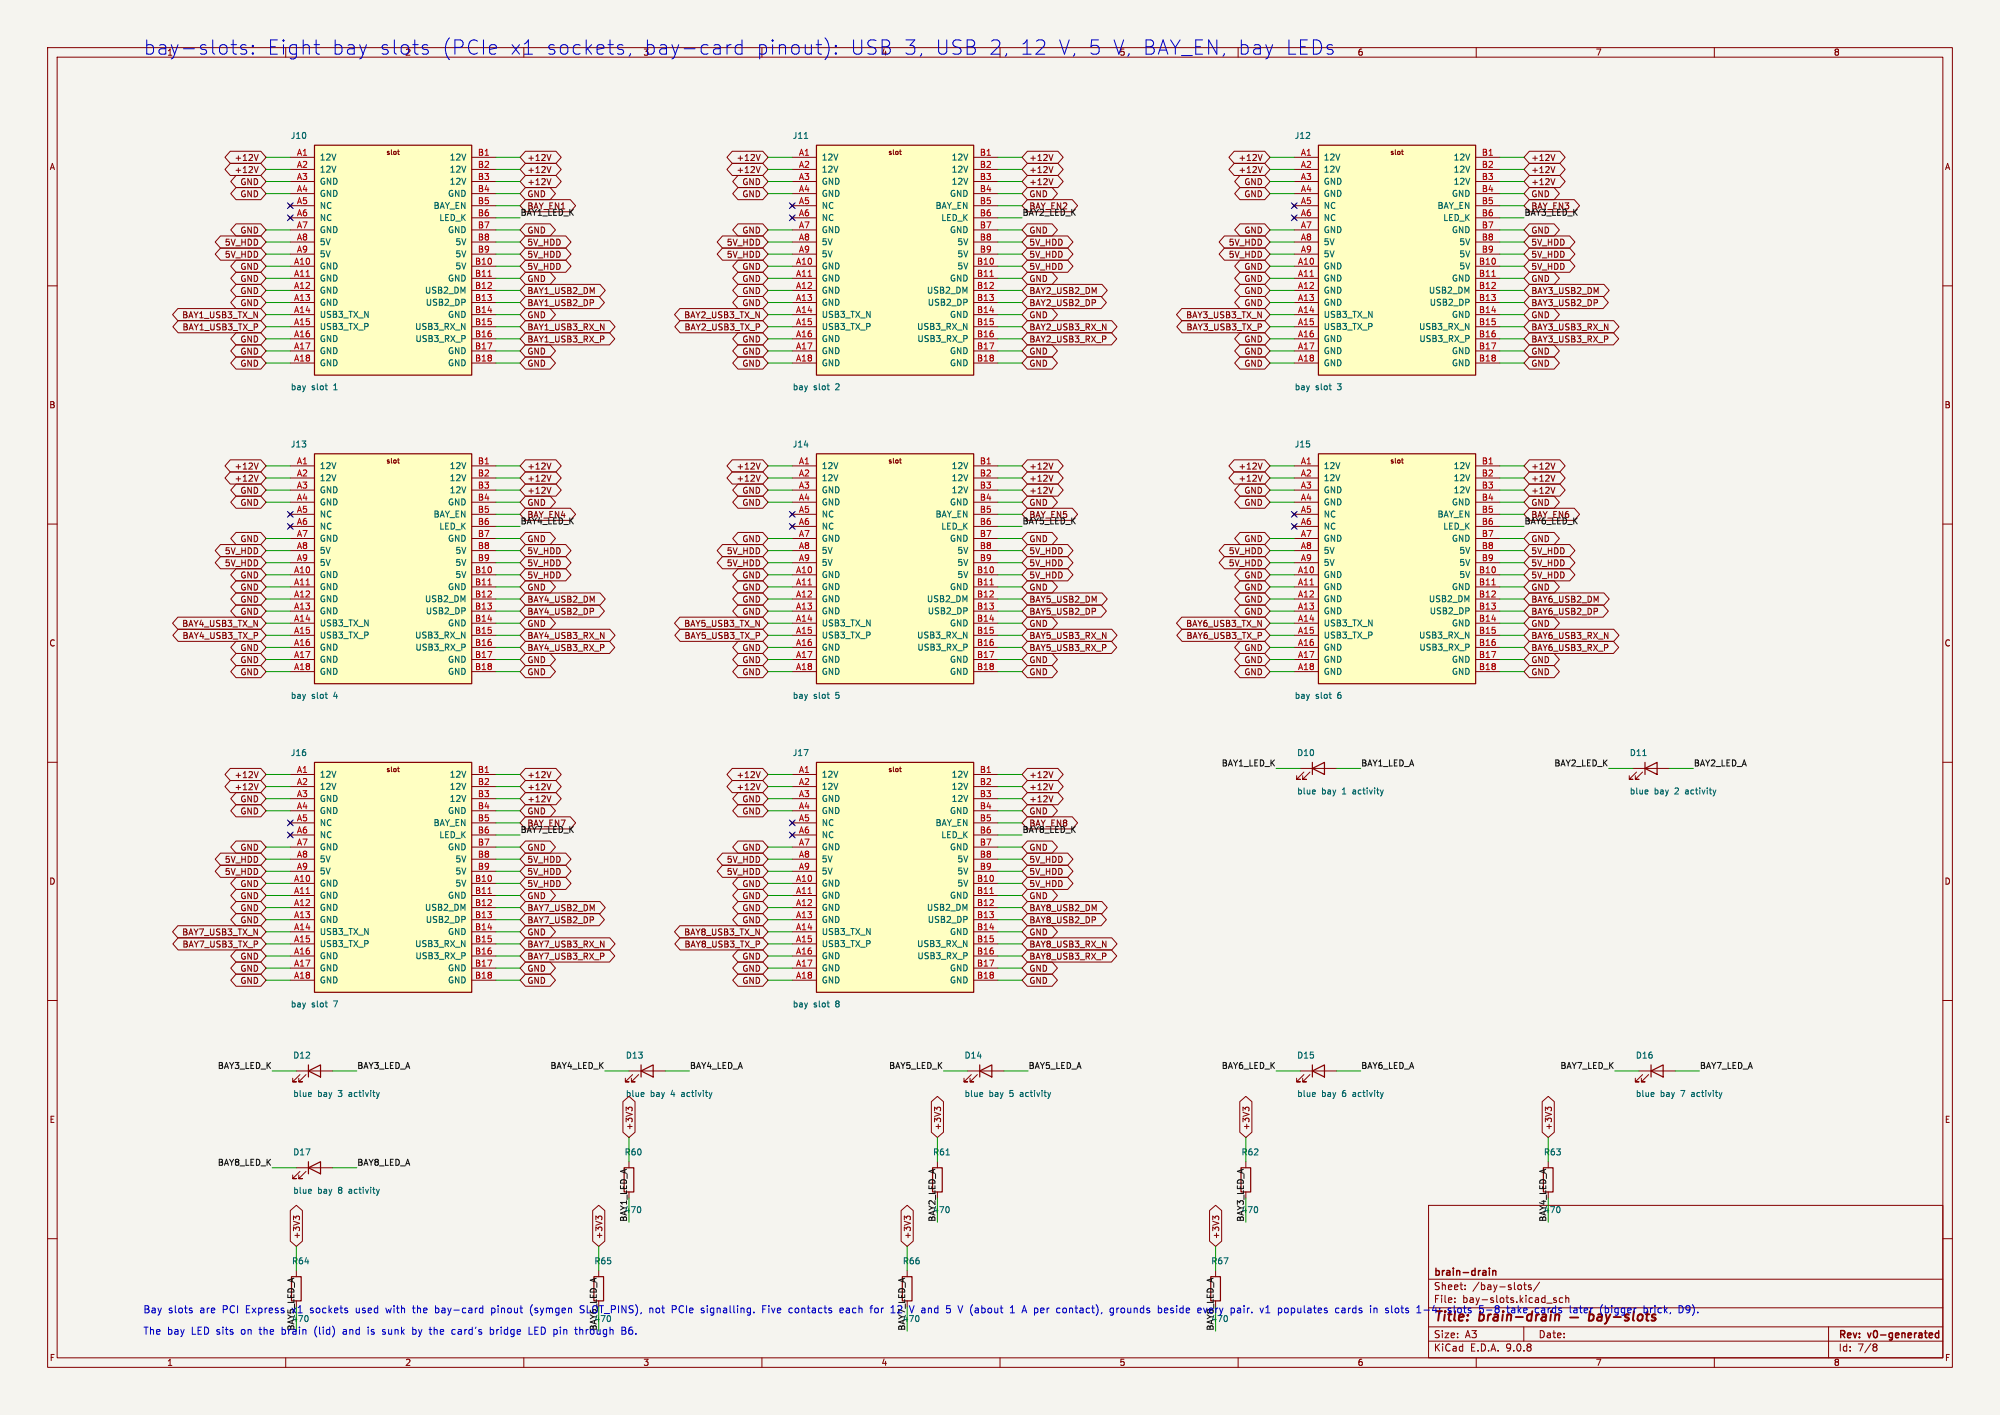
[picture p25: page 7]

BAY5_USB3_RX_P GND GND GND GND GND

5V_HDD
BAY3_USB3_TX_N GND GND GND GND GND

5V B10 GND B11 USB2_DM B12 USB2_DP B13 GND B14 USB3_RX_N B15 USB3_RX_P B16 GND B17 GND B18

BAY1_USB3_TX_N GND GND GND GND

BAY2_USB3_TX_N GND GND GND GND
BAY6_LED_K BAY8_LED_A

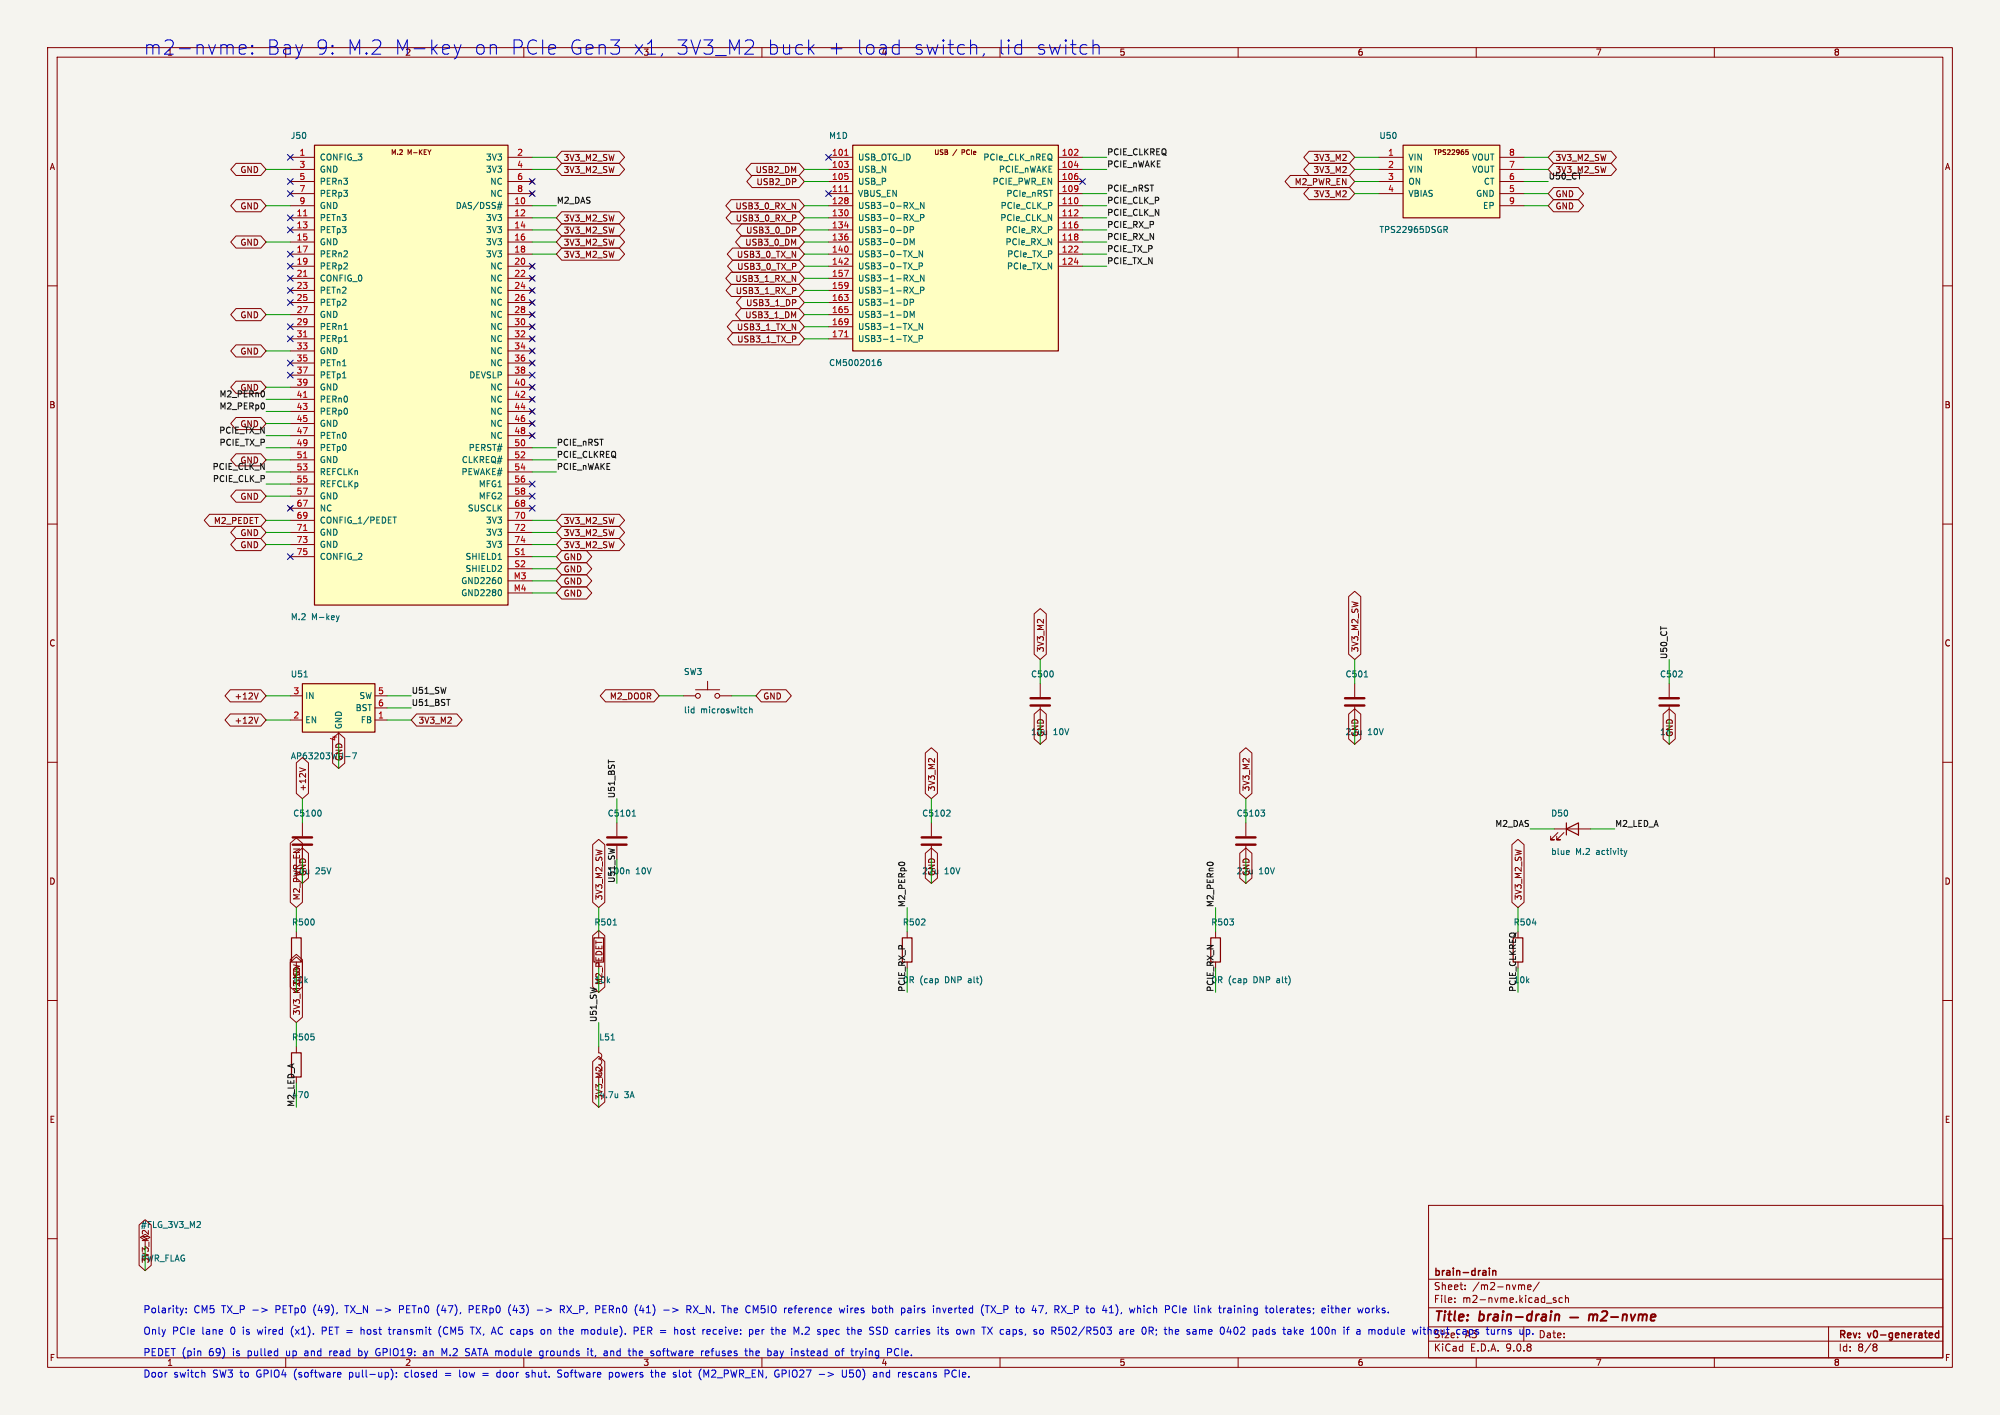
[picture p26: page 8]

File: m2-nvme.kicad_sch Sheet: /m2-nvme/ brain-drain

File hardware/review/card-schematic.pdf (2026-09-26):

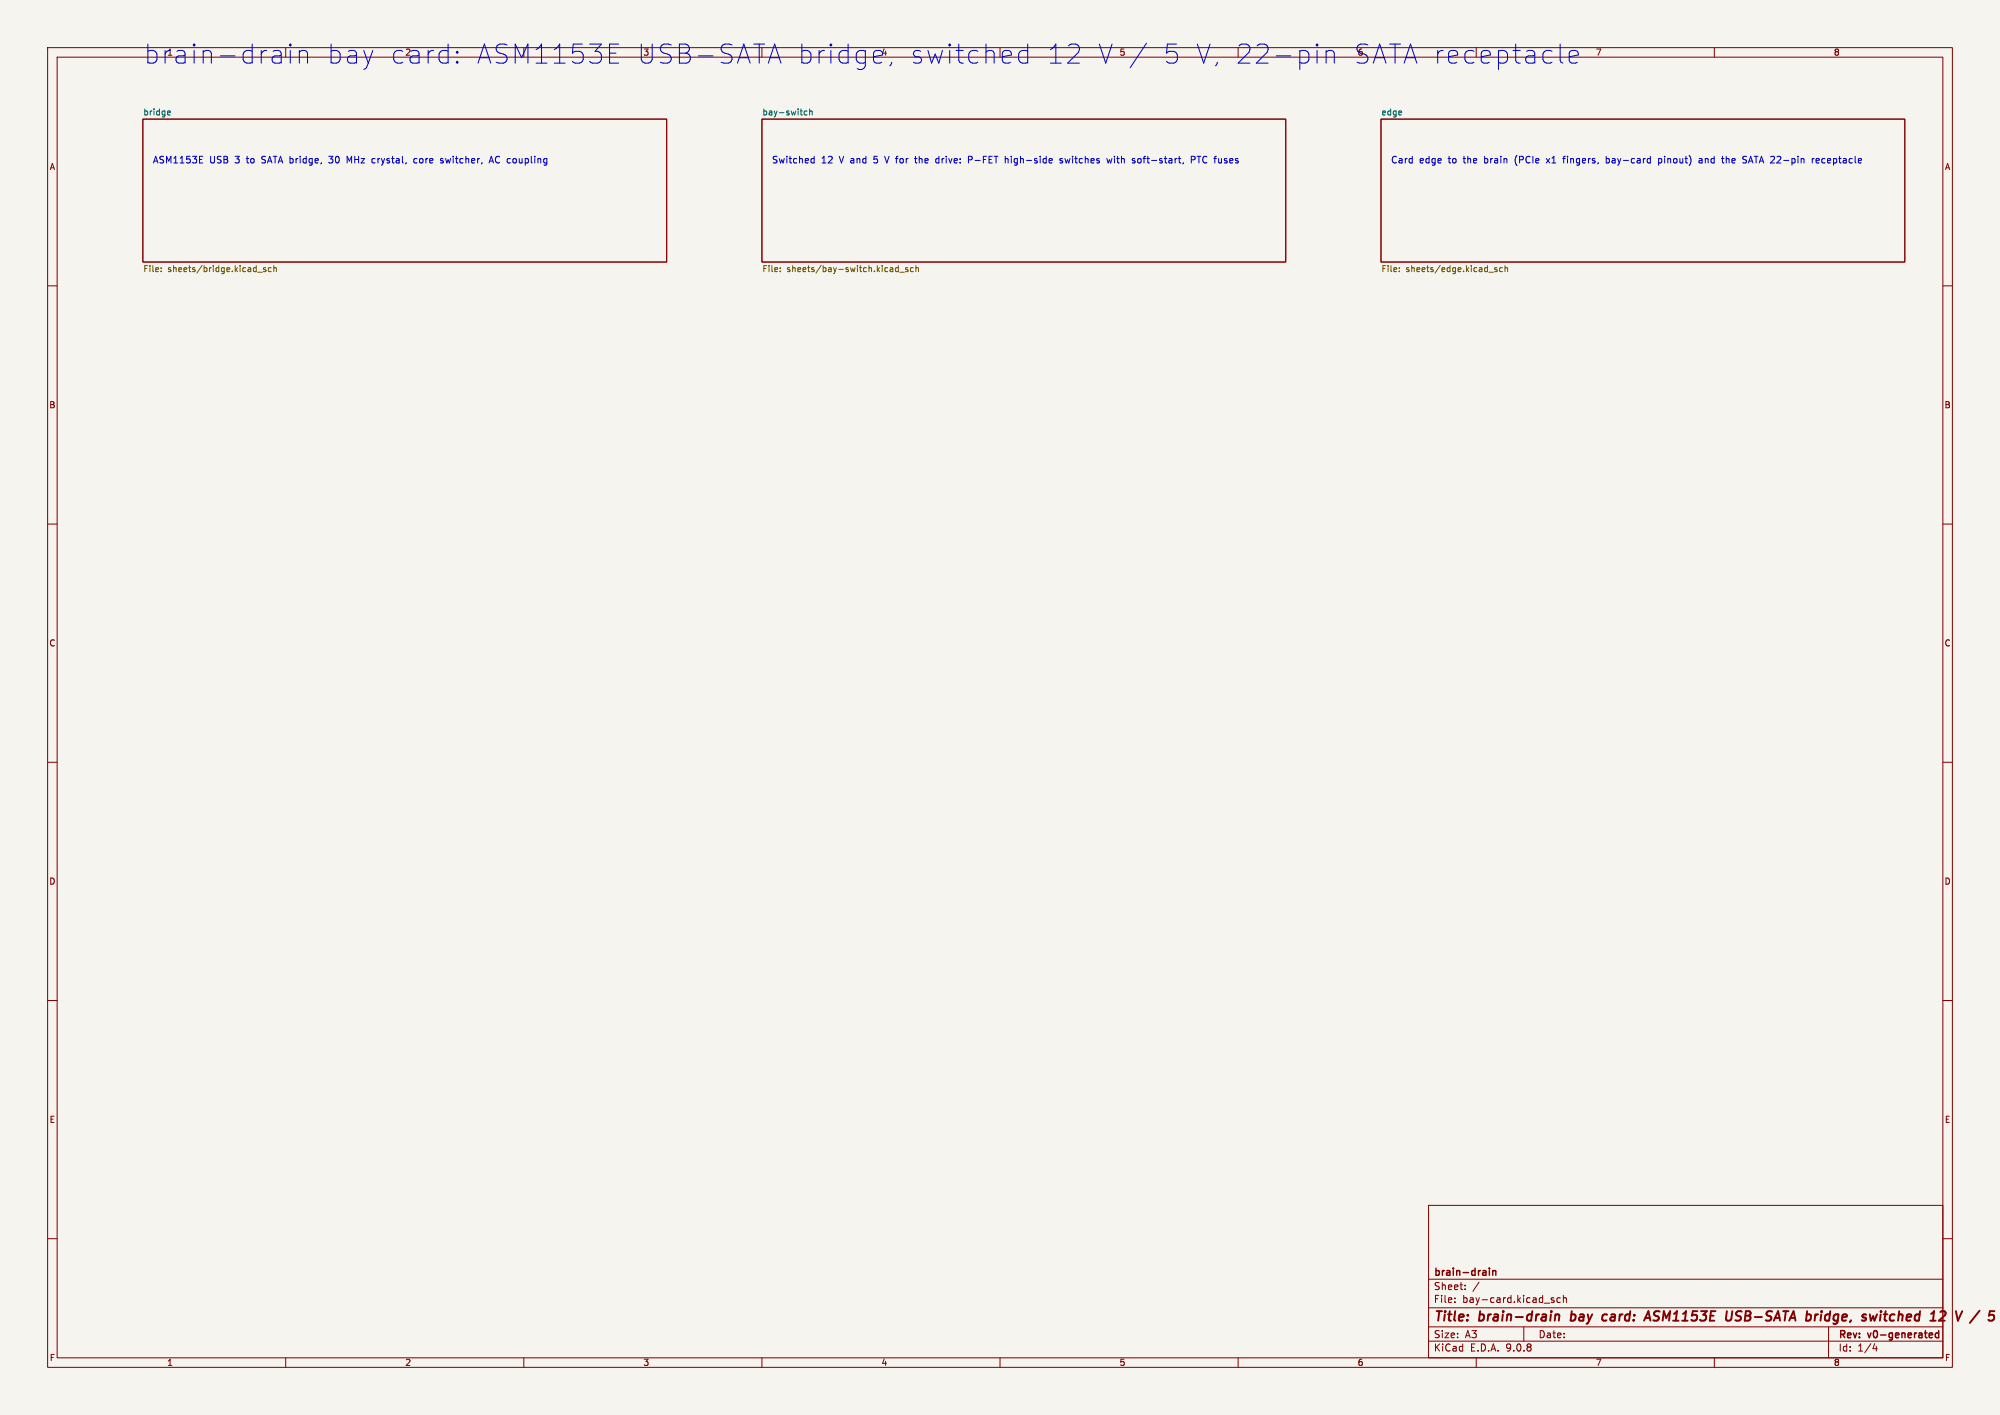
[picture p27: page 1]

bridge File: sheets/bridge.kicad_sch

bay-switch File: sheets/bay-switch.kicad_sch

edge File: sheets/edge.kicad_sch

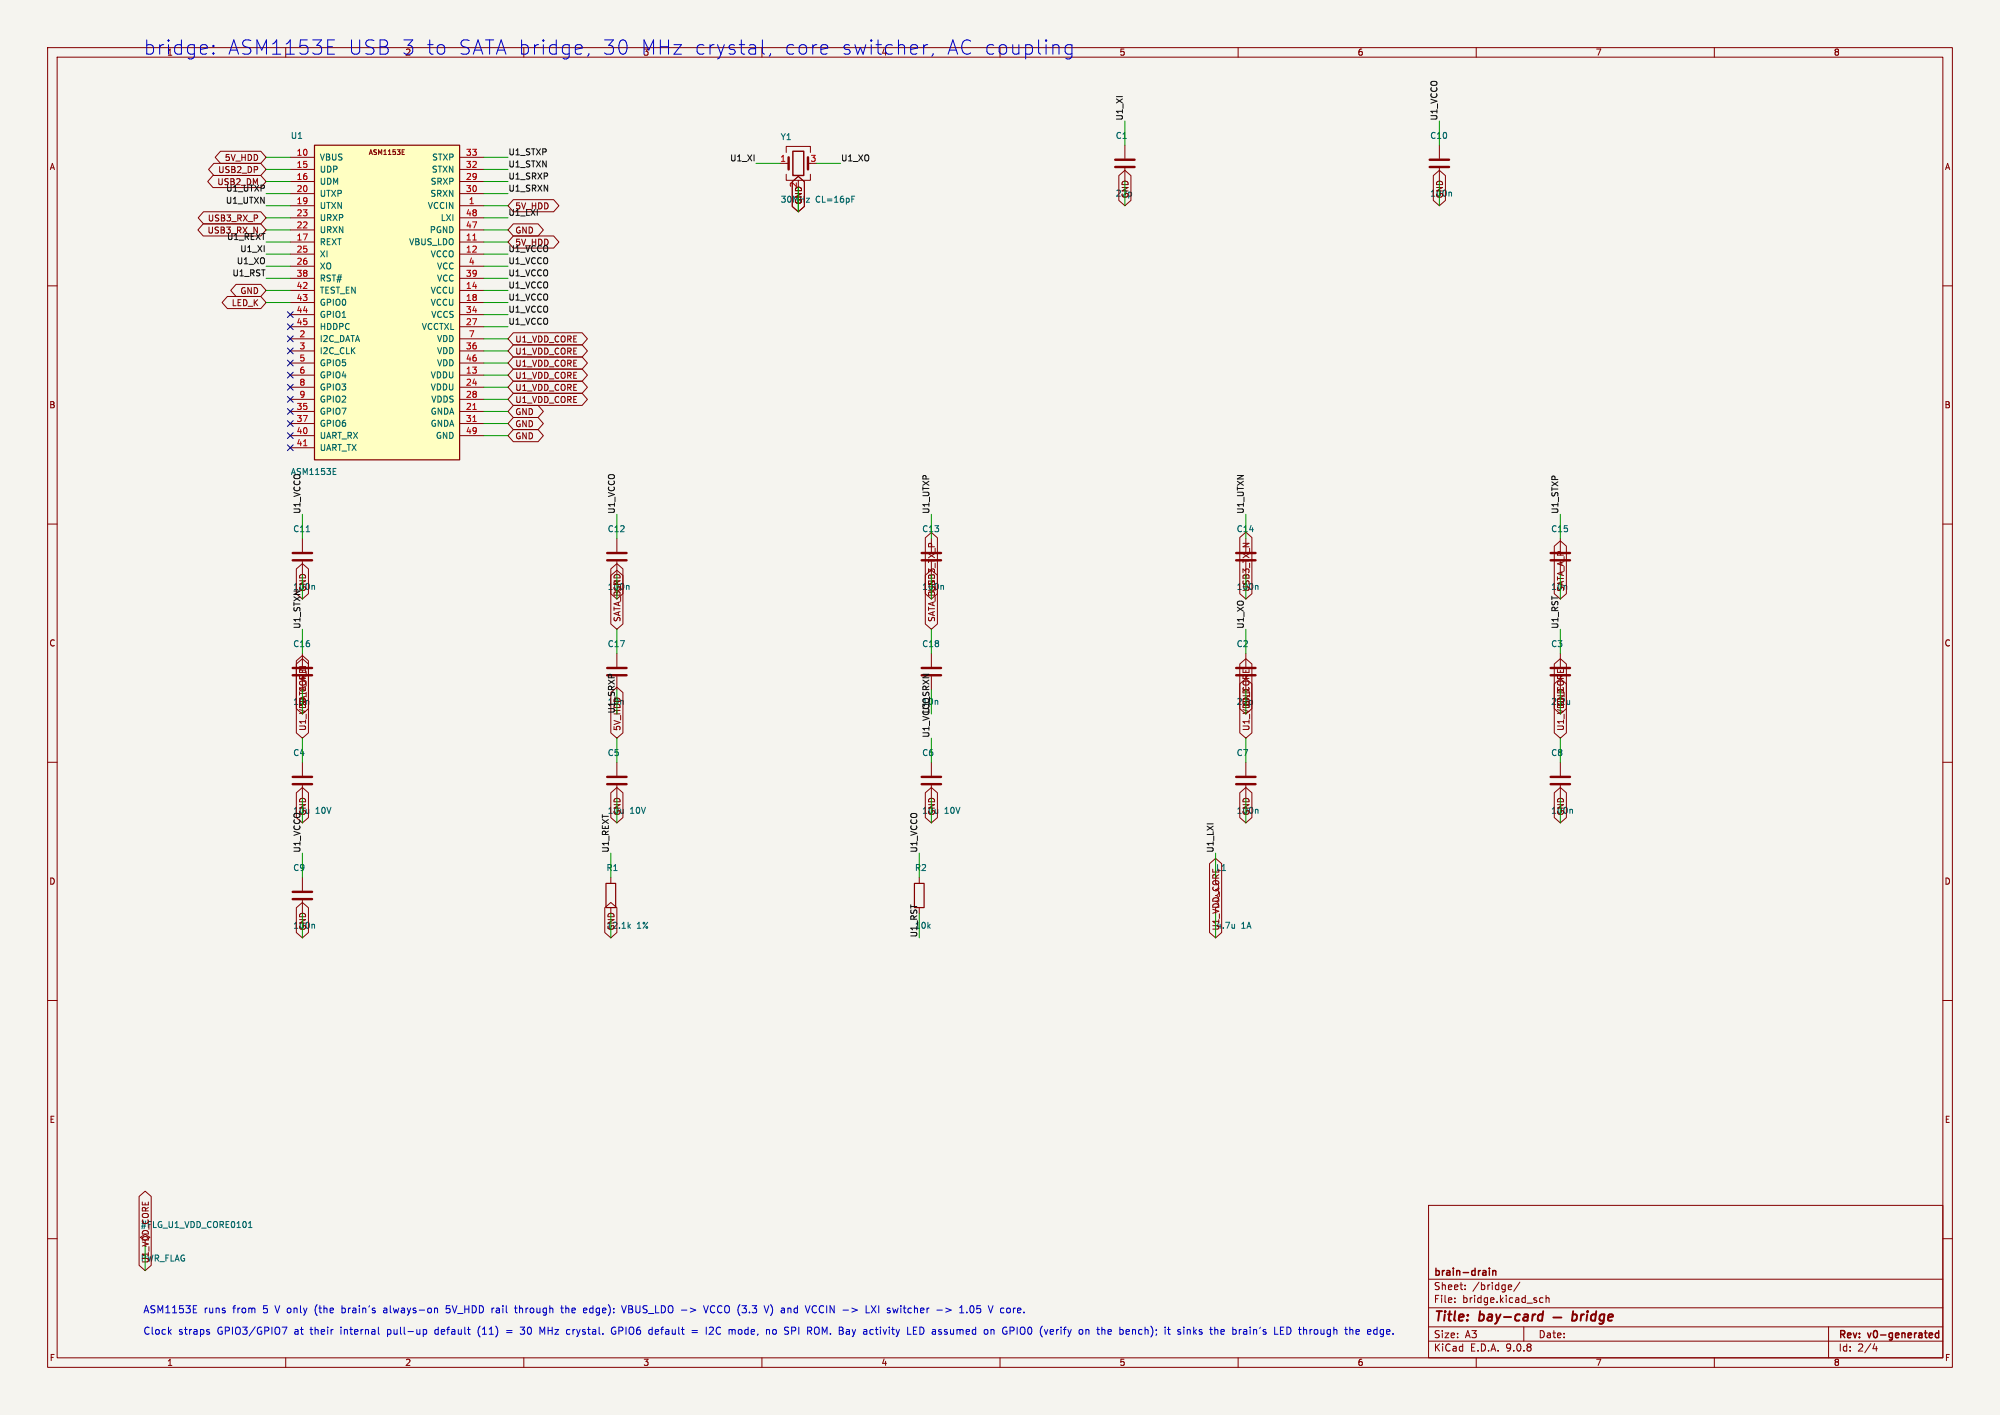
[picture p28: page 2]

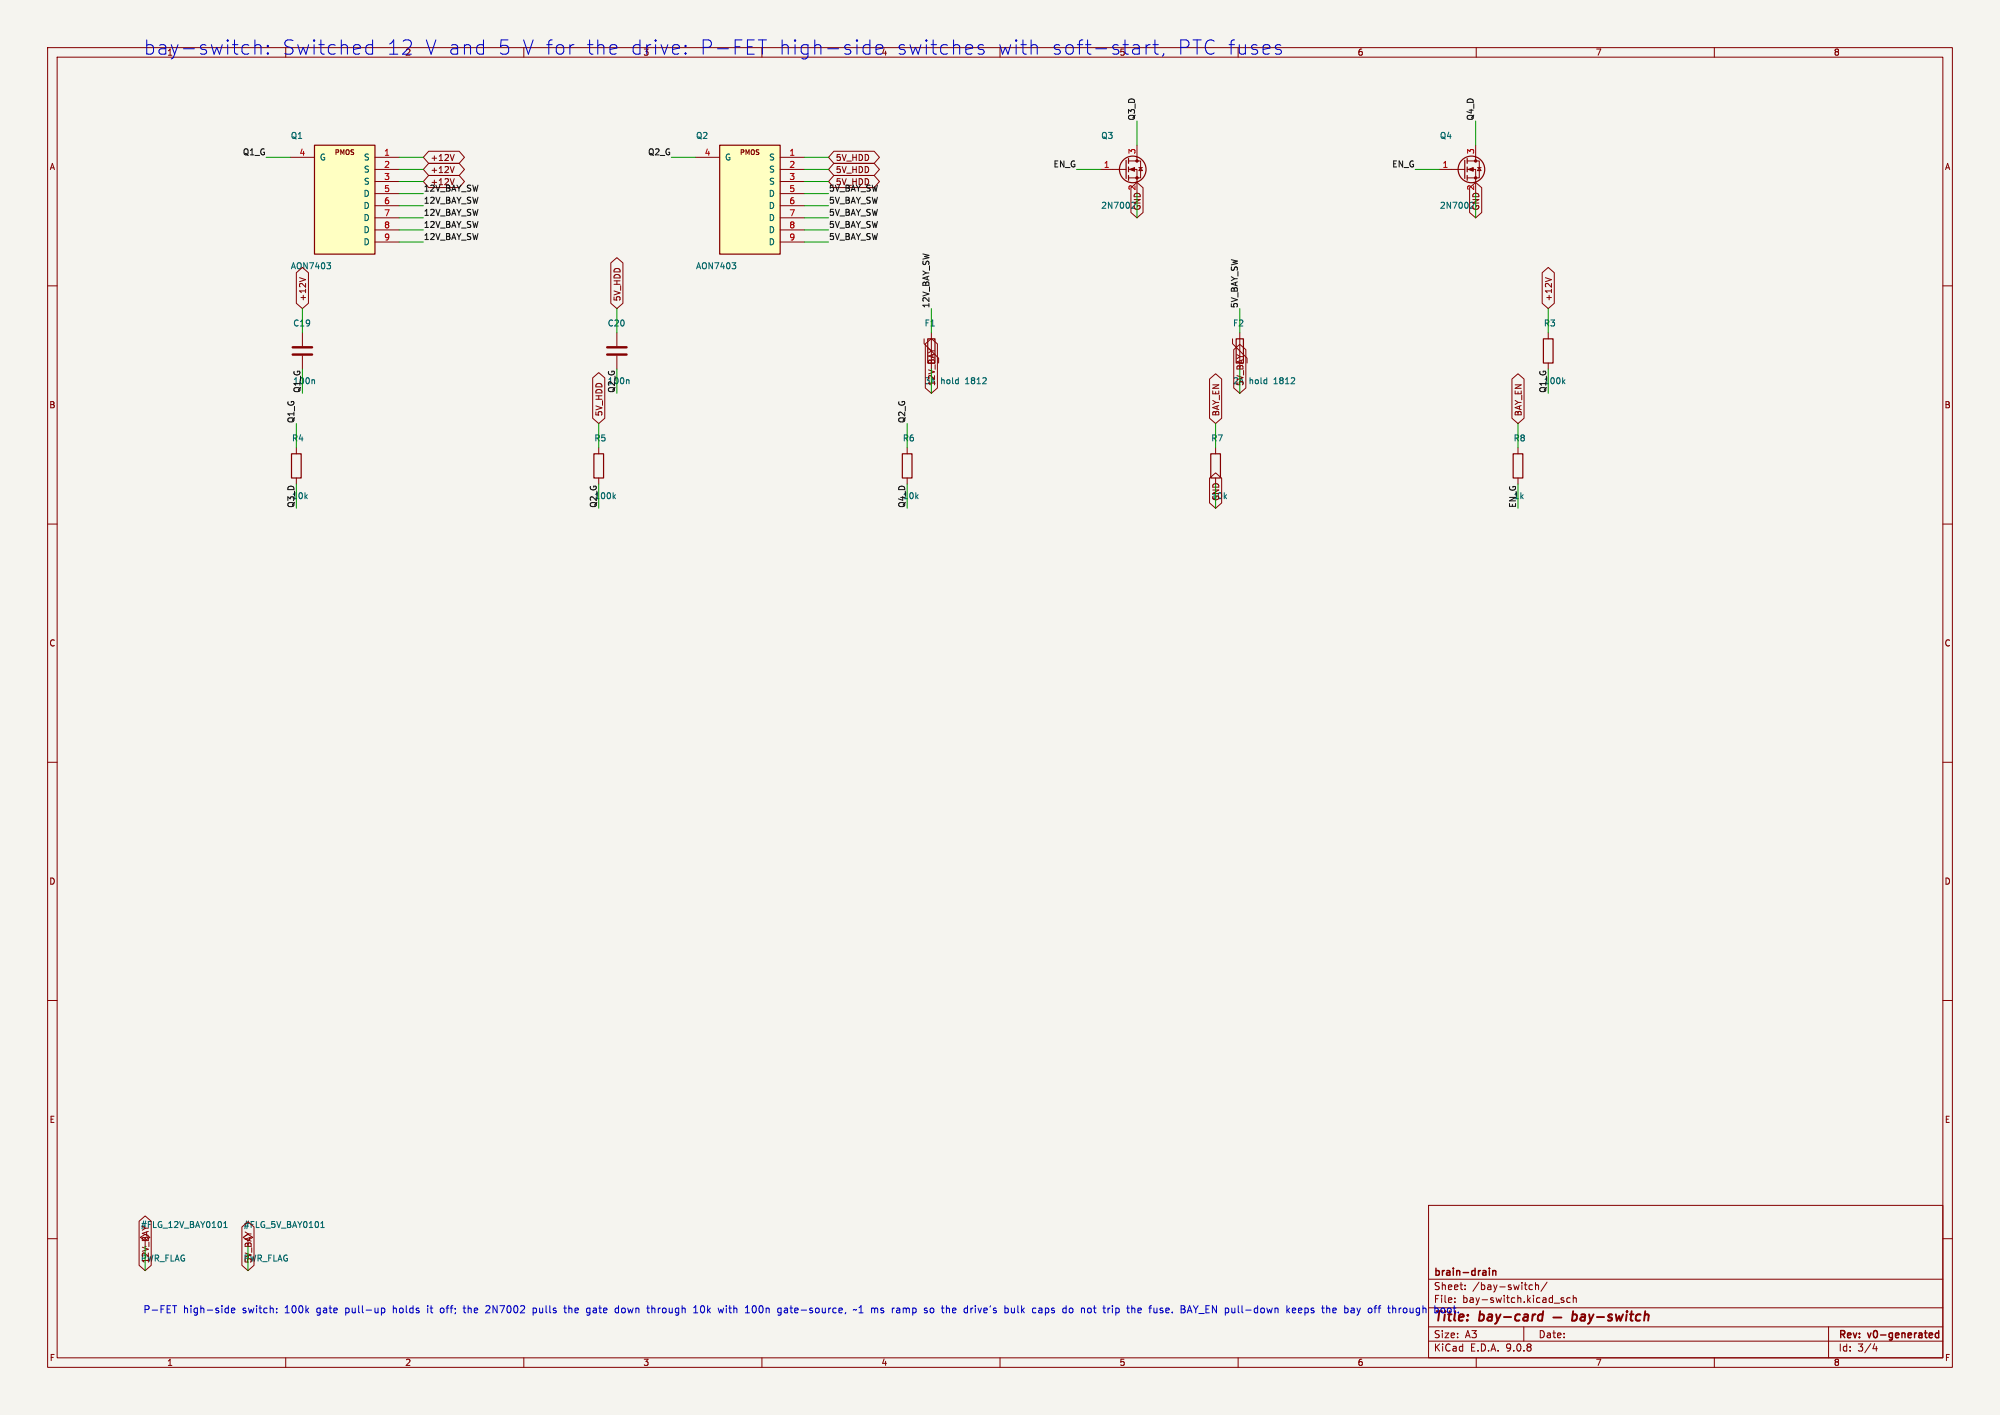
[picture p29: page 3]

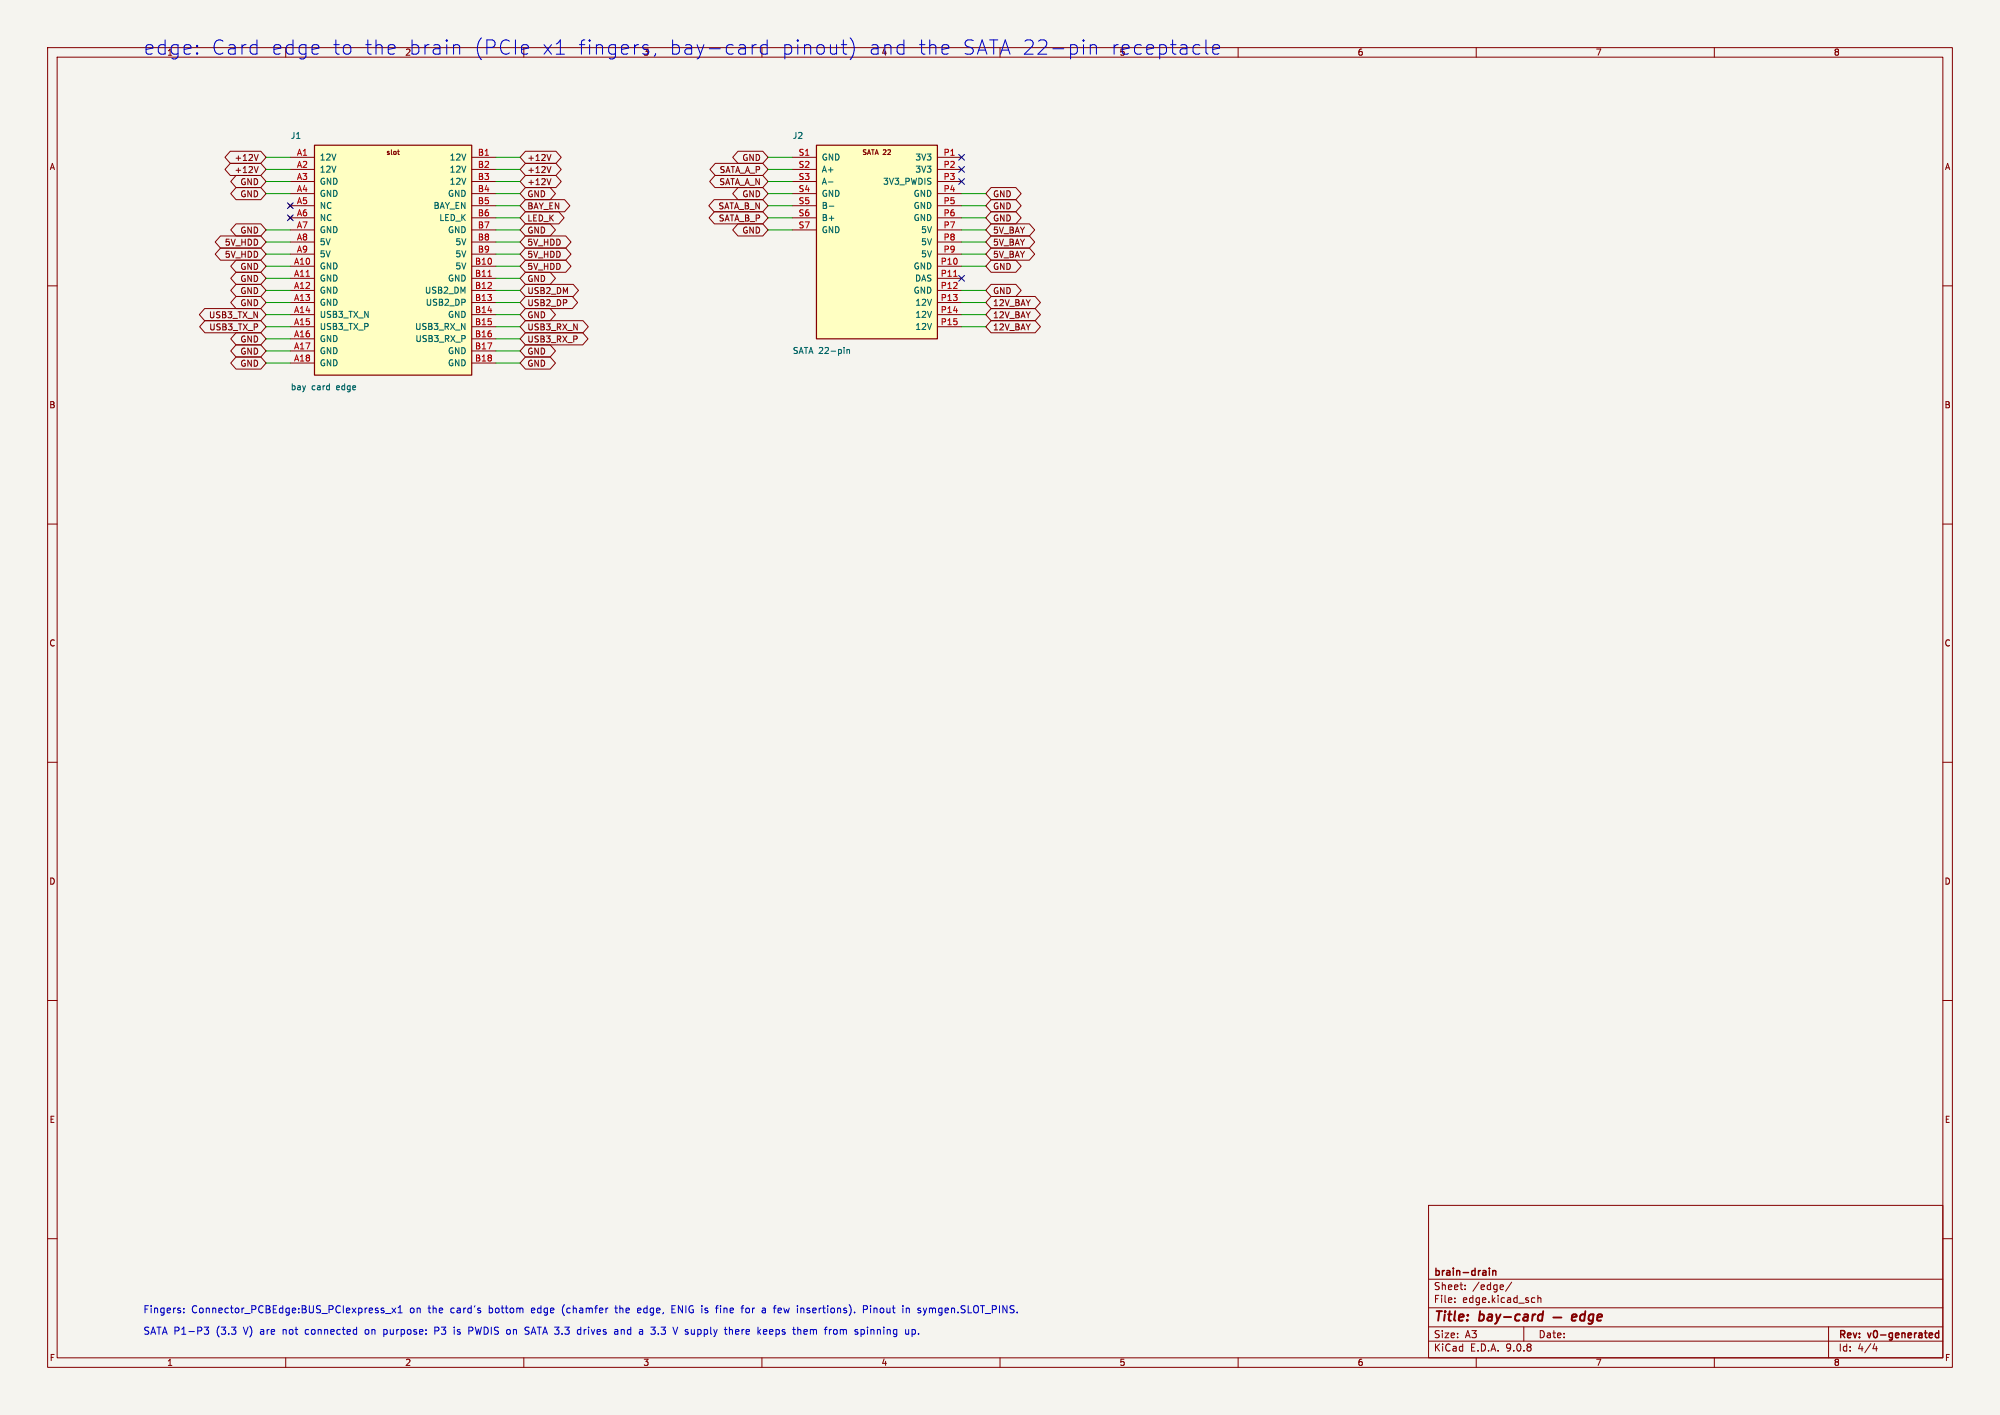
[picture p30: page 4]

+12V GND GND GND GND
+12V USB3_TX_N

File: edge.kicad_sch Sheet: /edge/ brain-drain

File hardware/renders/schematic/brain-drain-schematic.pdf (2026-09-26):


power-input File: sheets/power-input.kicad_sch

power-bucks File: sheets/power-bucks.kicad_sch

File: sheets/usb3-hub-A.kicad_sch m2-nvme File: sheets/m2-nvme.kicad_sch

bay-slots File: sheets/bay-slots.kicad_sch




J41 OLED GND/VCC/SCL/SDA R1

File: cm5.kicad_sch Sheet: /cm5/ brain-drain


File: usb3-hub-A.kicad_sch Sheet: /usb3-hub-A/ brain-drain


File: usb3-hub-B.kicad_sch Sheet: /usb3-hub-B/ brain-drain


BAY5_USB3_RX_P GND GND GND GND GND

5V_HDD
BAY3_USB3_TX_N GND GND GND GND GND

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

BAY1_USB3_TX_N GND GND GND GND

BAY2_USB3_TX_N GND GND GND GND
BAY6_LED_K BAY8_LED_A


File: m2-nvme.kicad_sch Sheet: /m2-nvme/ brain-drain




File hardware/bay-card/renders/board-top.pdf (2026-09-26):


bay card rev 1.0 BRAIN-DRAIN

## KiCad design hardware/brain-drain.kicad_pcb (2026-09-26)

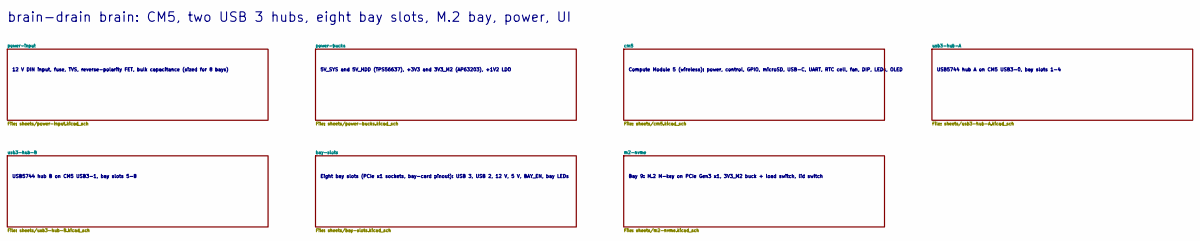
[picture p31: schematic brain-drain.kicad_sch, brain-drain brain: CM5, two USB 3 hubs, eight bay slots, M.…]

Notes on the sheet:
brain-drain brain: CM5, two USB 3 hubs, eight bay slots, M.2 bay, power, UI
12 V DIN input, fuse, TVS, reverse-polarity FET, bulk capacitance (sized for 8 bays)
5V_SYS and 5V_HDD (TPS56637), +3V3 and 3V3_M2 (AP63203), +1V2 LDO
Compute Module 5 (wireless): power, control, GPIO, microSD, USB-C, UART, RTC cell, fan, DIP, LEDs, OLED
USB5744 hub A on CM5 USB3-0, bay slots 1-4
USB5744 hub B on CM5 USB3-1, bay slots 5-8
Eight bay slots (PCIe x1 sockets, bay-card pinout): USB 3, USB 2, 12 V, 5 V, BAY_EN, bay LEDs
Bay 9: M.2 M-key on PCIe Gen3 x1, 3V3_M2 buck + load switch, lid switch

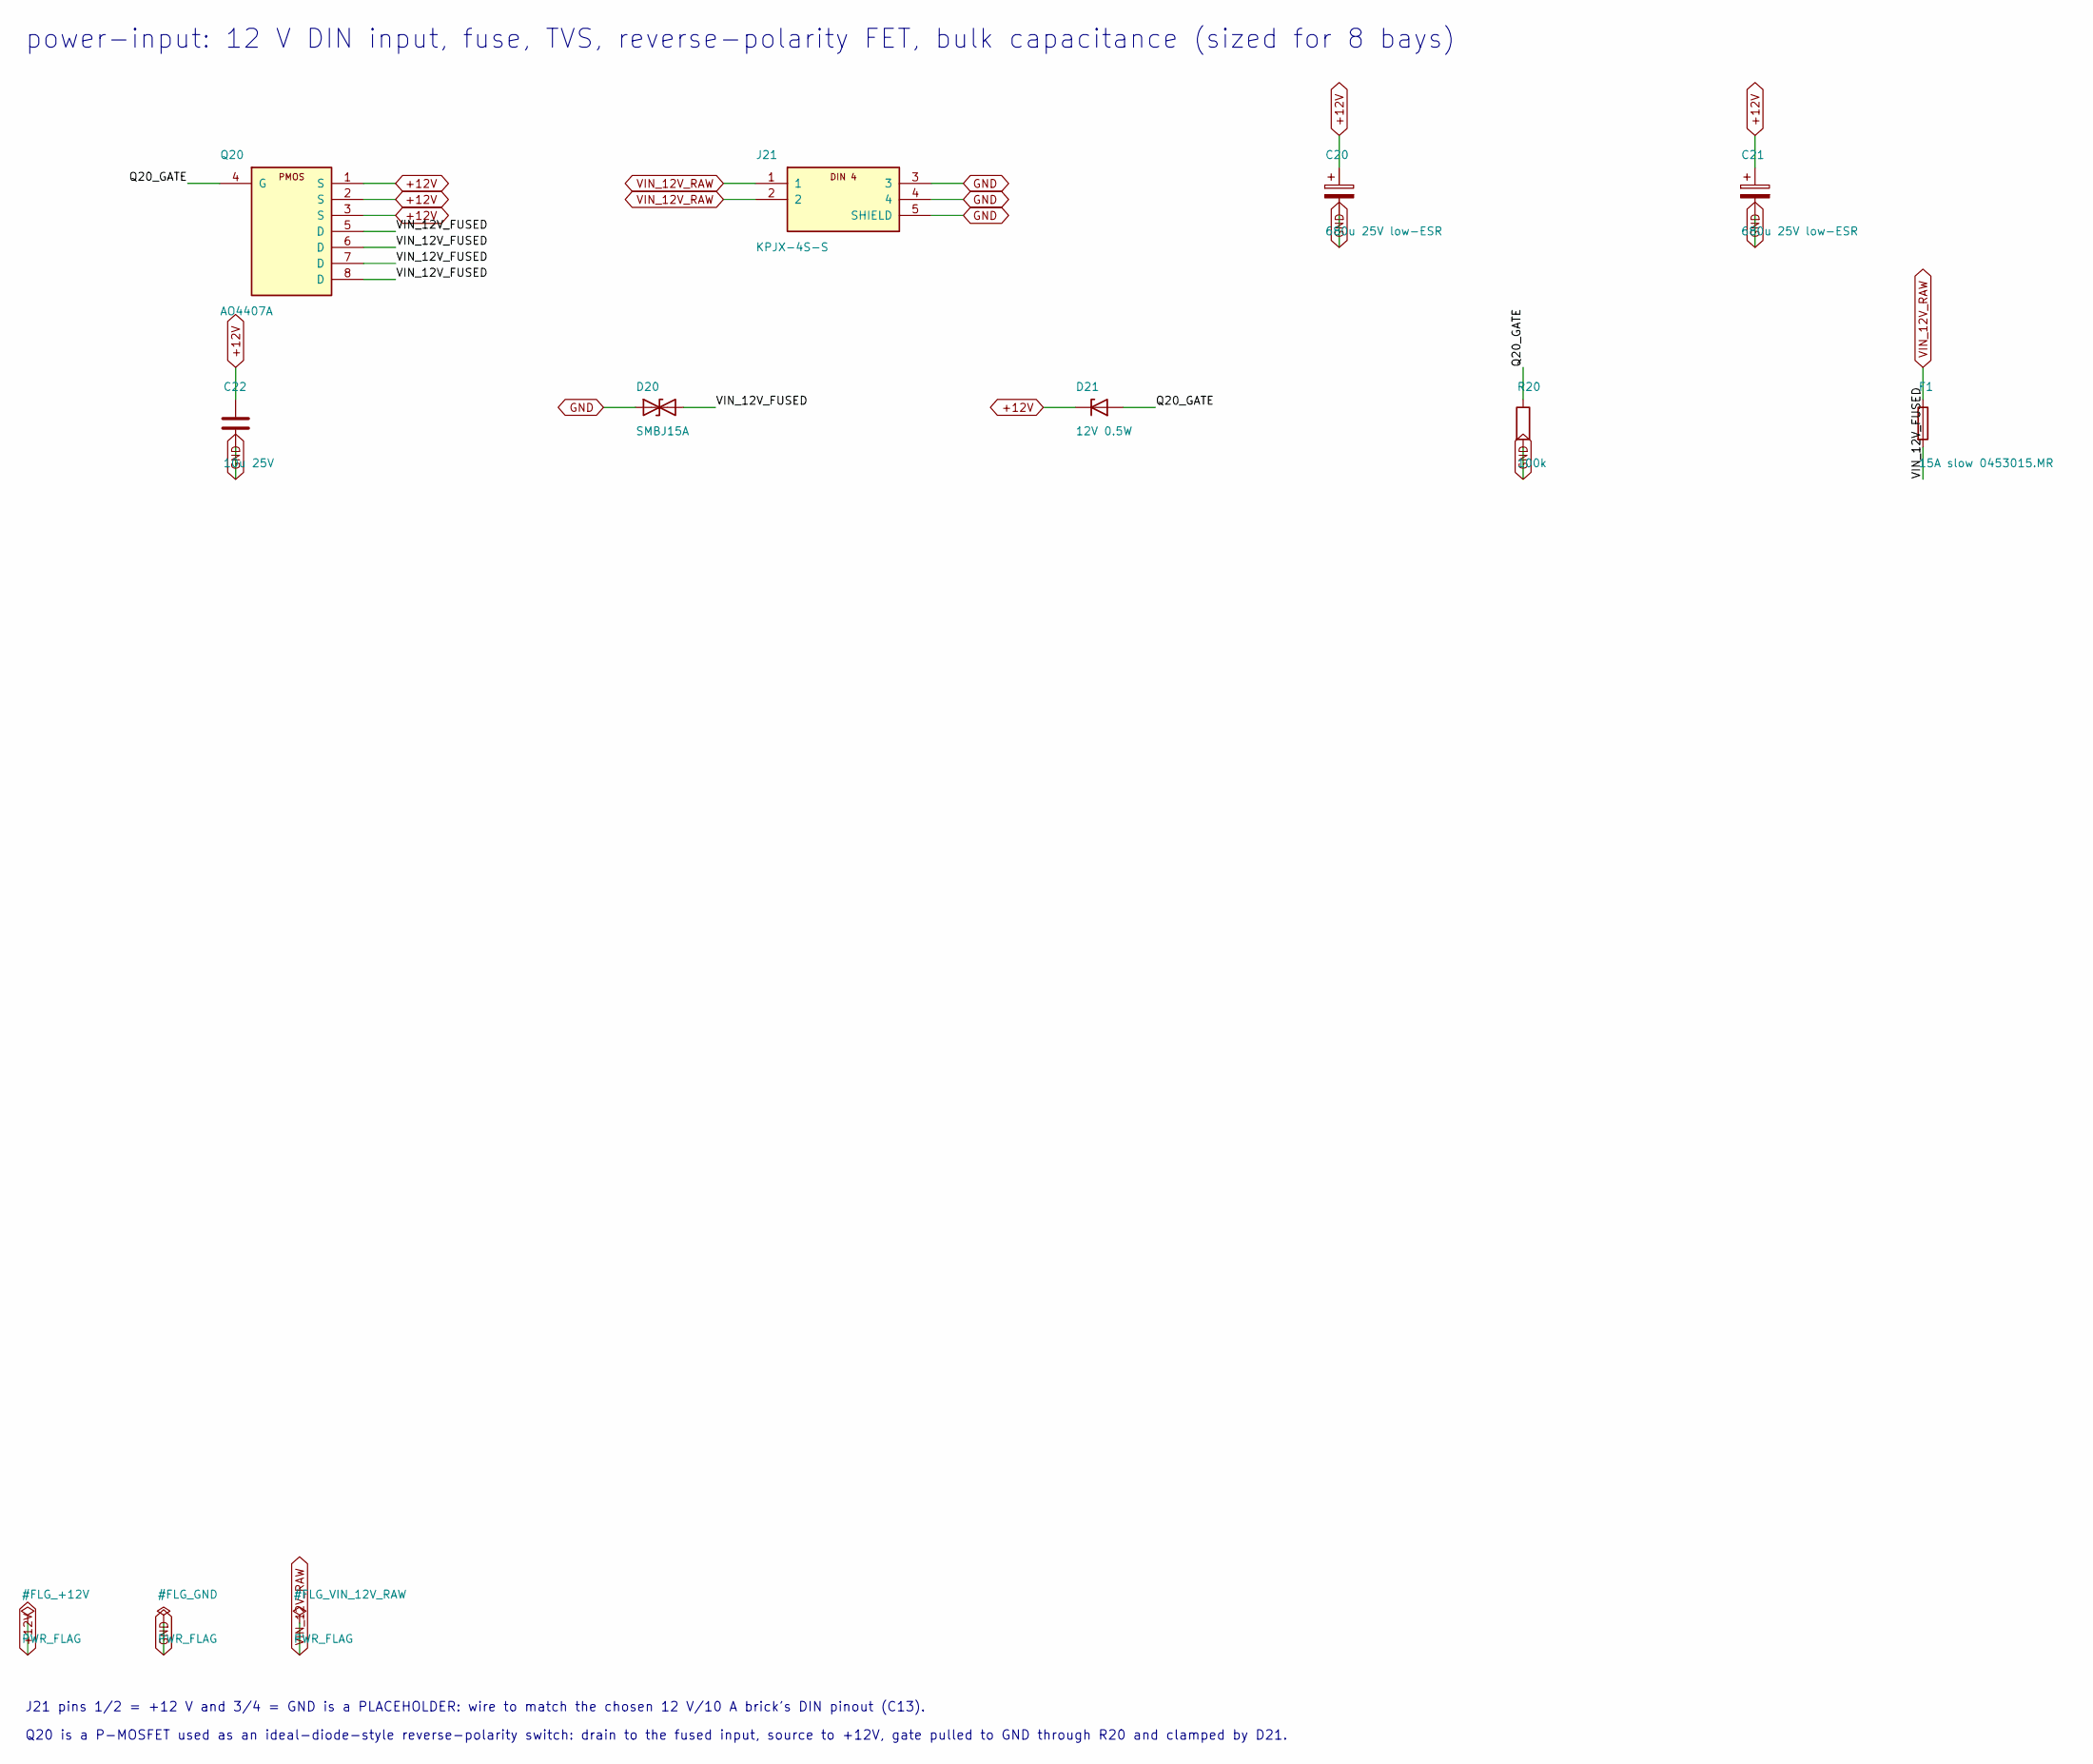
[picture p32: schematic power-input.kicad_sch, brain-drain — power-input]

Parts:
C20, C21: 680u 25V low-ESR; CP_Elec_10x10.5
C22: 10u 25V; C_1210_3225Metric
D20: SMBJ15A; D_SMB
D21: 12V 0.5W; D_SOD-123
F1: 15A slow 0453015.MR; Fuse_Littelfuse-NANO2-451_453
J21: KPJX-4S-S; Kycon_KPJX-4S-S
Q20: AO4407A; SOIC-8_3.9x4.9mm_P1.27mm
R20: 100k; R_0603_1608Metric

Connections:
+12V: C20.1, C21.1, C22.1, D21.1 (K), Q20.1 (S), Q20.2 (S), Q20.3 (S); also elsewhere on the board
GND: C20.2, C21.2, C22.2, D20.1 (A1), J21.3, J21.4, J21.5 (SHIELD), R20.2; also elsewhere on the board
Q20_GATE: D21.2 (A), Q20.4 (G), R20.1
VIN_12V_FUSED: D20.2 (A2), F1.2, Q20.5 (D), Q20.6 (D), Q20.7 (D), Q20.8 (D)
VIN_12V_RAW: F1.1, J21.1, J21.2

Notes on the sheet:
power-input: 12 V DIN input, fuse, TVS, reverse-polarity FET, bulk capacitance (sized for 8 bays)
J21 pins 1/2 = +12 V and 3/4 = GND is a PLACEHOLDER: wire to match the chosen 12 V/10 A brick's DIN pinout (C13).
Q20 is a P-MOSFET used as an ideal-diode-style reverse-polarity switch: drain to the fused input, source to +12V, gate pulled to GND through R20 and clamped by D21.

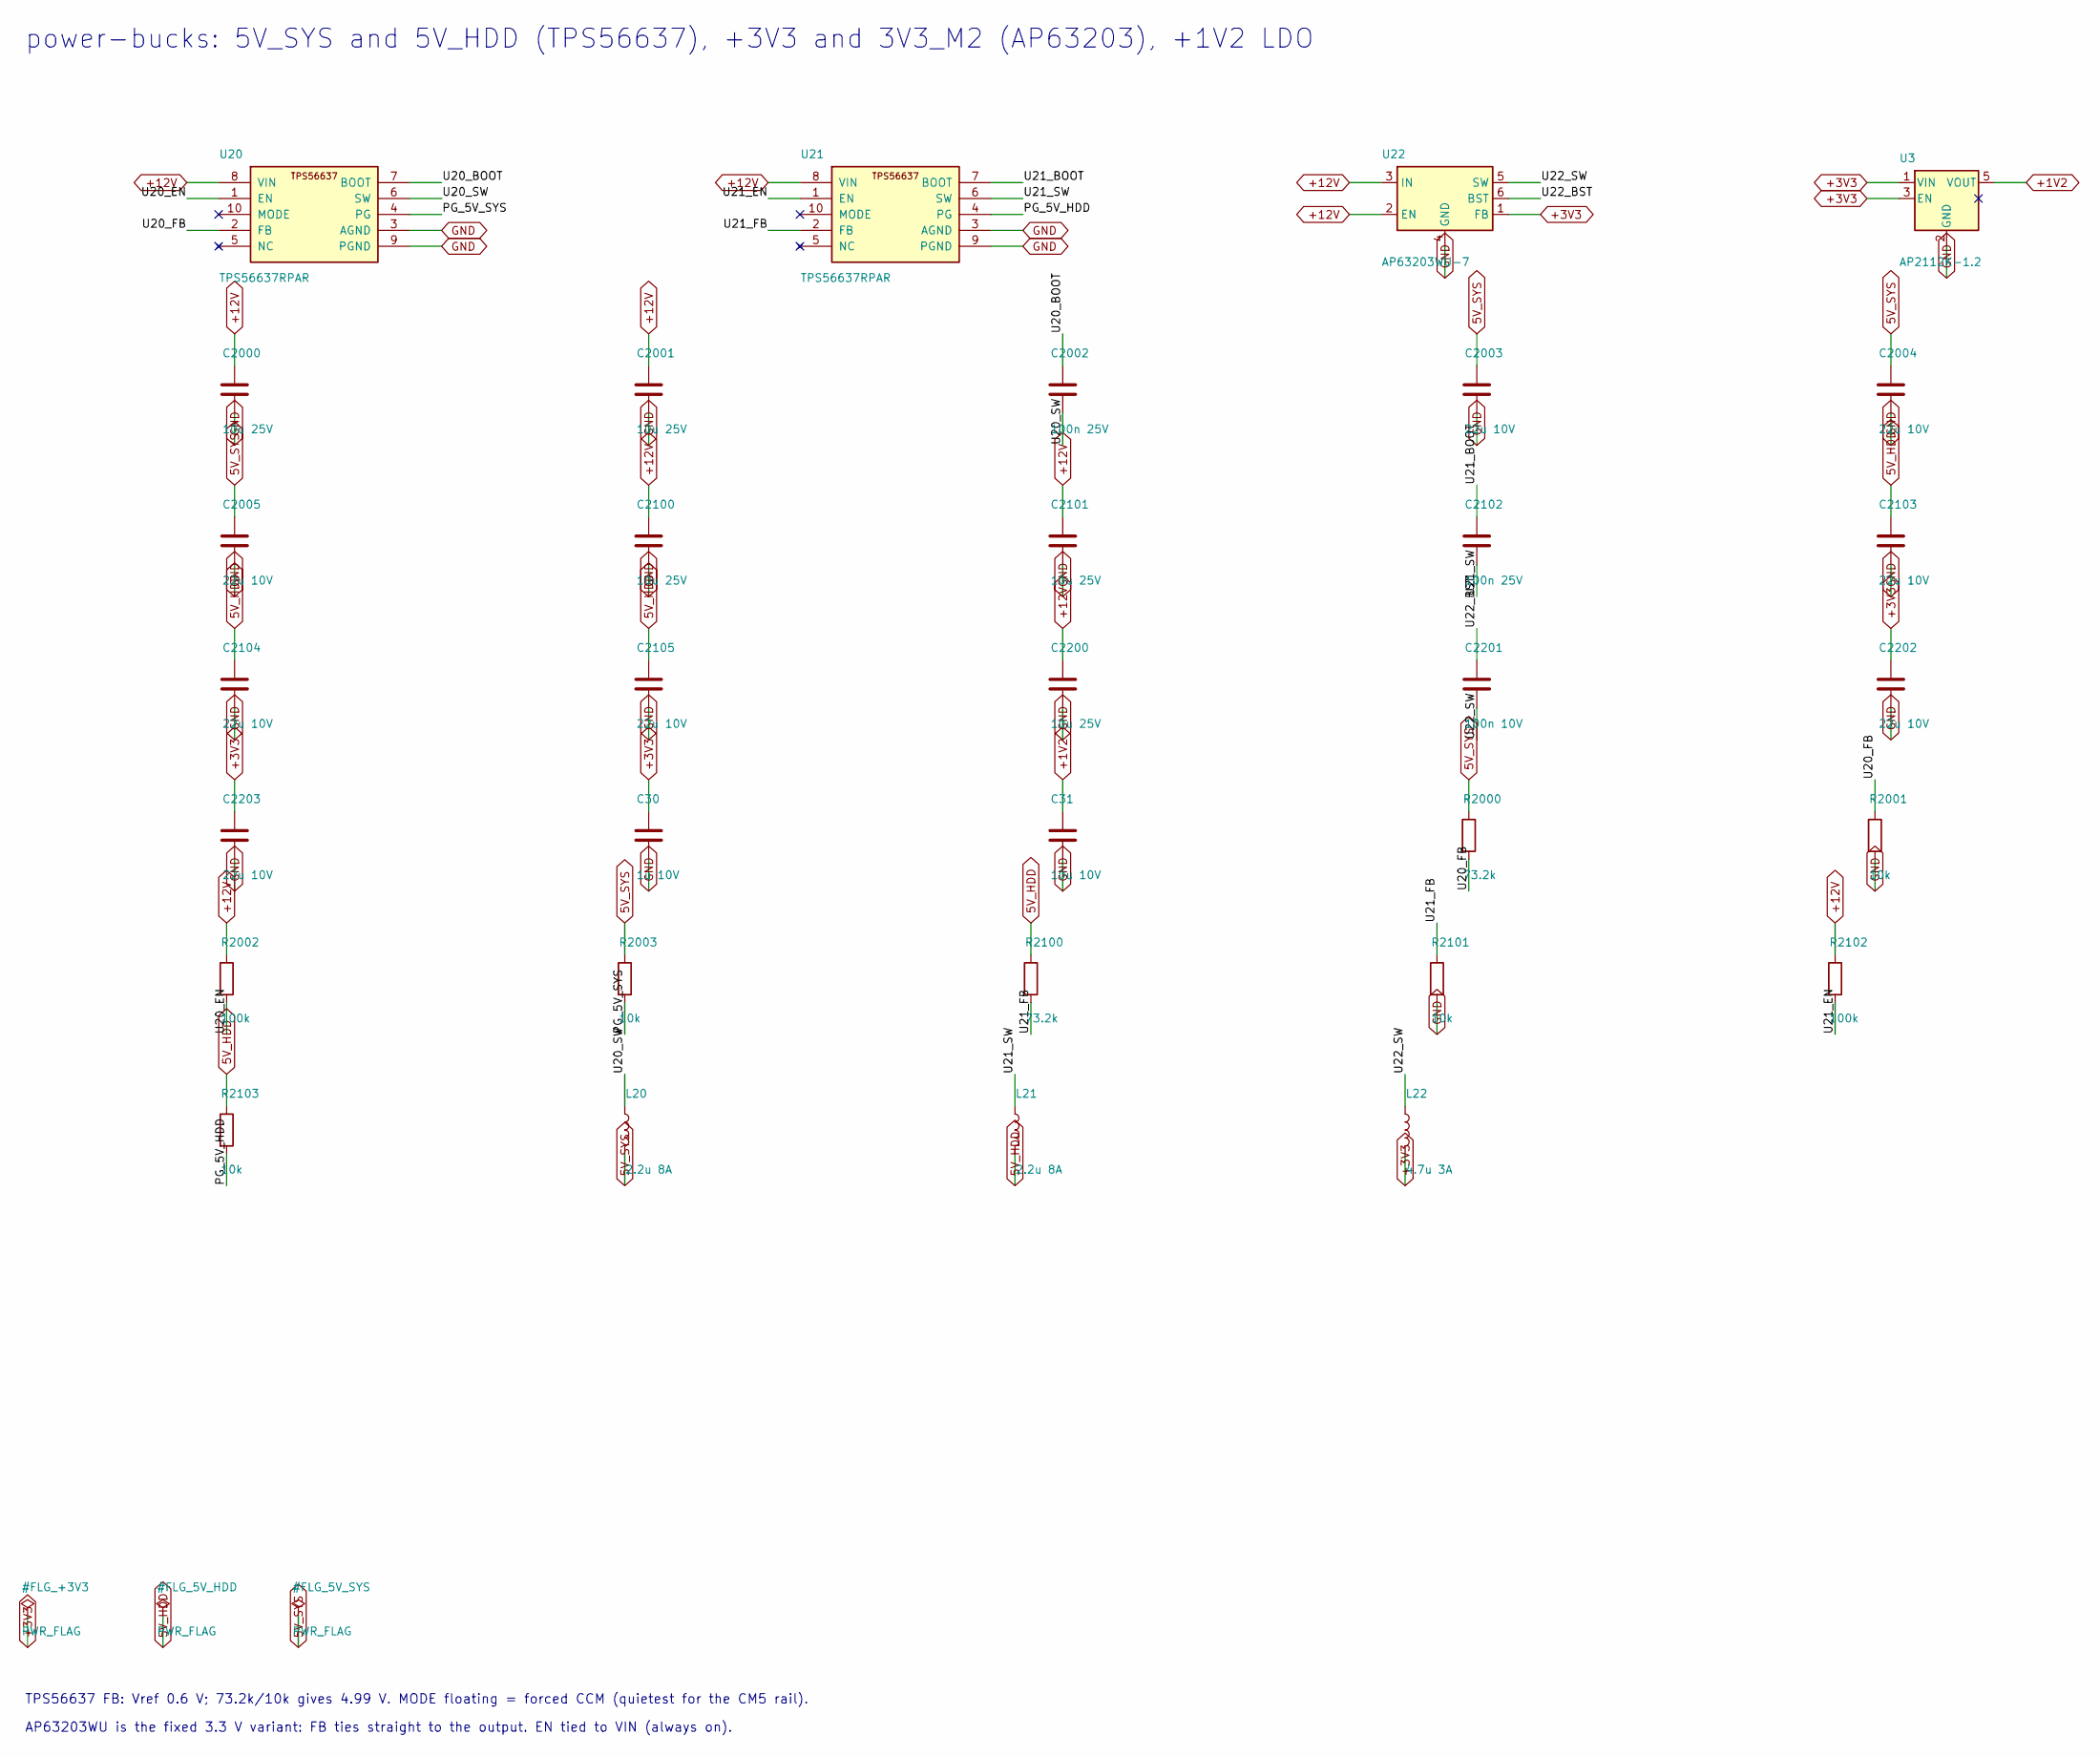
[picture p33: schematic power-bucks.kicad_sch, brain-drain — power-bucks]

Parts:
C30: 1u 10V; C_0402_1005Metric
C31: 10u 10V; C_0805_2012Metric
C2000, C2001, C2100, C2101, C2200: 10u 25V; C_1210_3225Metric
C2002, C2102: 100n 25V; C_0402_1005Metric
C2003, C2004, C2005, C2103, C2104, C2105, C2202, C2203: 22u 10V; C_0805_2012Metric
C2201: 100n 10V; C_0402_1005Metric
L20, L21: 2.2u 8A; L_Taiyo-Yuden_NR-60xx
L22: 4.7u 3A; L_Taiyo-Yuden_NR-40xx
R2000, R2100: 73.2k; R_0402_1005Metric
R2001, R2003, R2101, R2103: 10k; R_0402_1005Metric
R2002, R2102: 100k; R_0402_1005Metric
U3: AP2112K-1.2; SOT-23-5
U20, U21: TPS56637RPAR; Texas_RPA0010A_VQFN-HR-10_3x3mm
U22: AP63203WU-7; TSOT-23-6

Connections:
5V_HDD: C2103.1, C2104.1, C2105.1, L21.2, R2100.1, R2103.1; also elsewhere on the board
5V_SYS: C2003.1, C2004.1, C2005.1, L20.2, R2000.1, R2003.1; also elsewhere on the board
+1V2: C31.1, U3.5 (VOUT); also elsewhere on the board
+3V3: C30.1, C2202.1, C2203.1, L22.2, U3.1 (VIN), U3.3 (EN), U22.1 (FB); also elsewhere on the board
+12V: C2000.1, C2001.1, C2100.1, C2101.1, C2200.1, R2002.1, R2102.1, U20.8 (VIN), U21.8 (VIN), U22.2 (EN), U22.3 (IN); also elsewhere on the board
GND: C30.2, C31.2, C2000.2, C2001.2, C2003.2, C2004.2, C2005.2, C2100.2, C2101.2, C2103.2, C2104.2, C2105.2, C2200.2, C2202.2, C2203.2, R2001.2, R2101.2, U3.2 (GND), U20.3 (AGND), U20.9 (PGND), U21.3 (AGND), U21.9 (PGND), U22.4 (GND); also elsewhere on the board
PG_5V_HDD: R2103.2, U21.4 (PG)
PG_5V_SYS: R2003.2, U20.4 (PG)
U20_BOOT: C2002.1, U20.7 (BOOT)
U20_EN: R2002.2, U20.1 (EN)
U20_FB: R2000.2, R2001.1, U20.2 (FB)
U20_SW: C2002.2, L20.1, U20.6 (SW)
U21_BOOT: C2102.1, U21.7 (BOOT)
U21_EN: R2102.2, U21.1 (EN)
U21_FB: R2100.2, R2101.1, U21.2 (FB)
U21_SW: C2102.2, L21.1, U21.6 (SW)
U22_BST: C2201.1, U22.6 (BST)
U22_SW: C2201.2, L22.1, U22.5 (SW)

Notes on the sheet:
power-bucks: 5V_SYS and 5V_HDD (TPS56637), +3V3 and 3V3_M2 (AP63203), +1V2 LDO
TPS56637 FB: Vref 0.6 V; 73.2k/10k gives 4.99 V. MODE floating = forced CCM (quietest for the CM5 rail).
AP63203WU is the fixed 3.3 V variant: FB ties straight to the output. EN tied to VIN (always on).

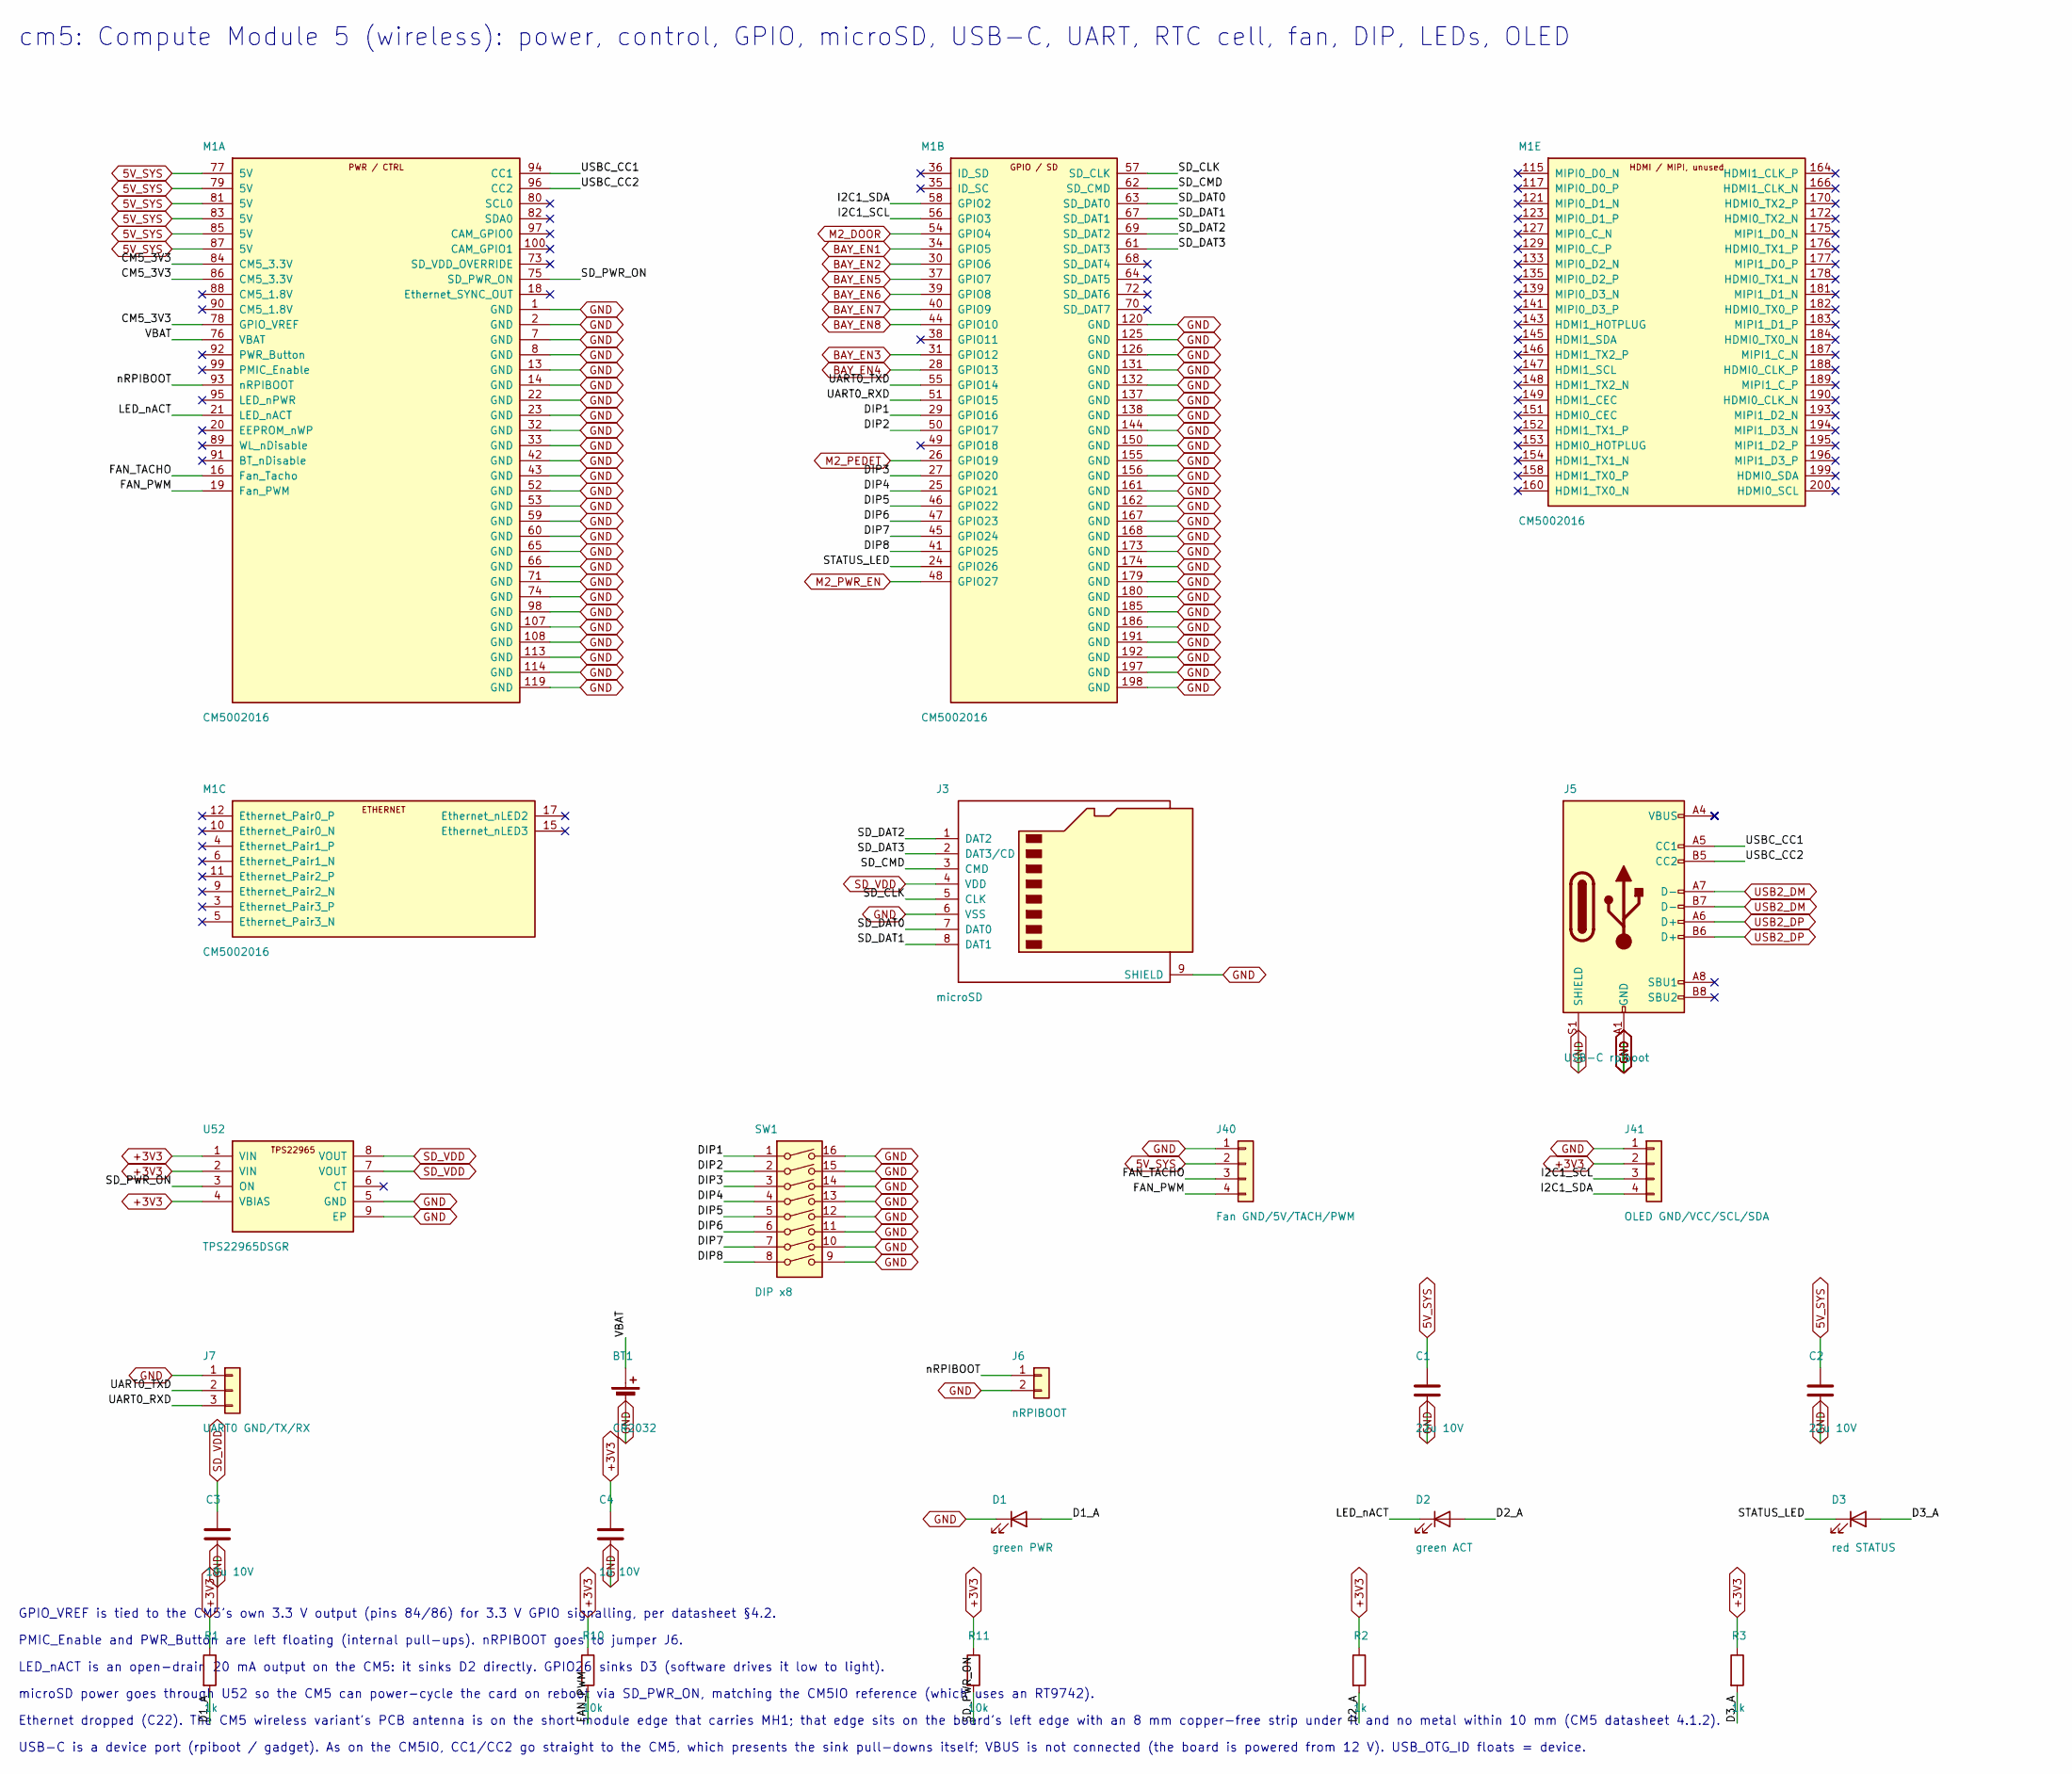
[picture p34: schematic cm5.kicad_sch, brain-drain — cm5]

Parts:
BT1: CR2032; BatteryHolder_Keystone_1060_1x2032
C1, C2: 22u 10V; C_0805_2012Metric
C3: 10u 10V; C_0805_2012Metric
C4: 1u 10V; C_0402_1005Metric
D1: green PWR; LED_D3.0mm
D2: green ACT; LED_D3.0mm
D3: red STATUS; LED_D3.0mm
J3: microSD; microSD_HC_Hirose_DM3AT-SF-PEJM5
J5: USB-C rpiboot; USB_C_Receptacle_GCT_USB4085
J6: nRPIBOOT; PinHeader_1x02_P2.54mm_Vertical
J7: UART0 GND/TX/RX; PinHeader_1x03_P2.54mm_Vertical
J40: Fan GND/5V/TACH/PWM; FanPinHeader_1x04_P2.54mm_Vertical
J41: OLED GND/VCC/SCL/SDA; PinHeader_1x04_P2.54mm_Vertical
M1: CM5002016; Raspberry-Pi-5-Compute-Module
R1, R2, R3: 1k; R_0603_1608Metric
R10, R11: 10k; R_0402_1005Metric
SW1: DIP x8; SW_DIP_SPSTx08_Piano_10.8x21.88mm_W7.62mm_P2.54mm
U52: TPS22965DSGR; Texas_DSG0008A_WSON-8-1EP_2x2mm_P0.5mm_EP0.9x1.6mm

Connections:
5V_SYS: C1.1, C2.1, J40.2, M1.77 (5V), M1.79 (5V), M1.81 (5V), M1.83 (5V), M1.85 (5V), M1.87 (5V); also elsewhere on the board
+3V3: C4.1, J41.2, R1.1, R2.1, R3.1, R10.1, R11.1, U52.1 (VIN), U52.2 (VIN), U52.4 (VBIAS); also elsewhere on the board
BAY_EN1: M1.34 (GPIO5); also elsewhere on the board
BAY_EN2: M1.30 (GPIO6); also elsewhere on the board
BAY_EN3: M1.31 (GPIO12); also elsewhere on the board
BAY_EN4: M1.28 (GPIO13); also elsewhere on the board
BAY_EN5: M1.37 (GPIO7); also elsewhere on the board
BAY_EN6: M1.39 (GPIO8); also elsewhere on the board
BAY_EN7: M1.40 (GPIO9); also elsewhere on the board
BAY_EN8: M1.44 (GPIO10); also elsewhere on the board
CM5_3V3: M1.78 (GPIO_VREF), M1.84 (CM5_3.3V), M1.86 (CM5_3.3V)
D1_A: D1.2 (A), R1.2
D2_A: D2.2 (A), R2.2
D3_A: D3.2 (A), R3.2
DIP1: M1.29 (GPIO16), SW1.1
DIP2: M1.50 (GPIO17), SW1.2
DIP3: M1.27 (GPIO20), SW1.3
DIP4: M1.25 (GPIO21), SW1.4
DIP5: M1.46 (GPIO22), SW1.5
DIP6: M1.47 (GPIO23), SW1.6
DIP7: M1.45 (GPIO24), SW1.7
DIP8: M1.41 (GPIO25), SW1.8
FAN_PWM: J40.4, M1.19 (Fan_PWM), R10.2
FAN_TACHO: J40.3, M1.16 (Fan_Tacho)
GND: BT1.2 (-), C1.2, C2.2, C3.2, C4.2, D1.1 (K), J3.6 (VSS), J3.9 (SHIELD), J5.A1 (GND), J5.A12 (GND), J5.B1 (GND), J5.B12 (GND), J5.S1 (SHIELD), J6.2, J7.1, J40.1, J41.1, M1.1 (GND), M1.2 (GND), M1.7 (GND), M1.8 (GND), M1.13 (GND), M1.14 (GND), M1.22 (GND), M1.23 (GND), M1.32 (GND), M1.33 (GND), M1.42 (GND), M1.43 (GND), M1.52 (GND), M1.53 (GND), M1.59 (GND), M1.60 (GND), M1.65 (GND), M1.66 (GND), M1.71 (GND), M1.74 (GND), M1.98 (GND), M1.107 (GND), M1.108 (GND), M1.113 (GND), M1.114 (GND), M1.119 (GND), M1.120 (GND), M1.125 (GND), M1.126 (GND), M1.131 (GND), M1.132 (GND), M1.137 (GND), M1.138 (GND), M1.144 (GND), M1.150 (GND), M1.155 (GND), M1.156 (GND), M1.161 (GND), M1.162 (GND), M1.167 (GND), M1.168 (GND), M1.173 (GND), M1.174 (GND), M1.179 (GND), M1.180 (GND), M1.185 (GND), M1.186 (GND), M1.191 (GND), M1.192 (GND), M1.197 (GND), M1.198 (GND), SW1.9, SW1.10, SW1.11, SW1.12, SW1.13, SW1.14, SW1.15, SW1.16, U52.5 (GND), U52.9 (EP); also elsewhere on the board
I2C1_SCL: J41.3, M1.56 (GPIO3)
I2C1_SDA: J41.4, M1.58 (GPIO2)
LED_nACT: D2.1 (K), M1.21 (LED_nACT)
M2_DOOR: M1.54 (GPIO4); also elsewhere on the board
M2_PEDET: M1.26 (GPIO19); also elsewhere on the board
M2_PWR_EN: M1.48 (GPIO27); also elsewhere on the board
SD_CLK: J3.5 (CLK), M1.57 (SD_CLK)
SD_CMD: J3.3 (CMD), M1.62 (SD_CMD)
SD_DAT0: J3.7 (DAT0), M1.63 (SD_DAT0)
SD_DAT1: J3.8 (DAT1), M1.67 (SD_DAT1)
SD_DAT2: J3.1 (DAT2), M1.69 (SD_DAT2)
SD_DAT3: J3.2 (DAT3/CD), M1.61 (SD_DAT3)
SD_PWR_ON: M1.75 (SD_PWR_ON), R11.2, U52.3 (ON)
SD_VDD: C3.1, J3.4 (VDD), U52.7 (VOUT), U52.8 (VOUT)
STATUS_LED: D3.1 (K), M1.24 (GPIO26)
UART0_RXD: J7.3, M1.51 (GPIO15)
UART0_TXD: J7.2, M1.55 (GPIO14)
USB2_DM: J5.A7 (D-), J5.B7 (D-); also elsewhere on the board
USB2_DP: J5.A6 (D+), J5.B6 (D+); also elsewhere on the board
USBC_CC1: J5.A5 (CC1), M1.94 (CC1)
USBC_CC2: J5.B5 (CC2), M1.96 (CC2)
VBAT: BT1.1 (+), M1.76 (VBAT)
nRPIBOOT: J6.1, M1.93 (nRPIBOOT)

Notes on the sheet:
cm5: Compute Module 5 (wireless): power, control, GPIO, microSD, USB-C, UART, RTC cell, fan, DIP, LEDs, OLED
GPIO_VREF is tied to the CM5's own 3.3 V output (pins 84/86) for 3.3 V GPIO signalling, per datasheet §4.2.
PMIC_Enable and PWR_Button are left floating (internal pull-ups). nRPIBOOT goes to jumper J6.
LED_nACT is an open-drain 20 mA output on the CM5: it sinks D2 directly. GPIO26 sinks D3 (software drives it low to light).
microSD power goes through U52 so the CM5 can power-cycle the card on reboot via SD_PWR_ON, matching the CM5IO reference (which uses an RT9742).
Ethernet dropped (C22). The CM5 wireless variant's PCB antenna is on the short module edge that carries MH1; that edge sits on the board's left edge with an 8 mm copper-free strip under it and no metal within 10 mm (CM5 datasheet 4.1.2).
USB-C is a device port (rpiboot / gadget). As on the CM5IO, CC1/CC2 go straight to the CM5, which presents the sink pull-downs itself; VBUS is not connected (the board is powered from 12 V). USB_OTG_ID floats = device.

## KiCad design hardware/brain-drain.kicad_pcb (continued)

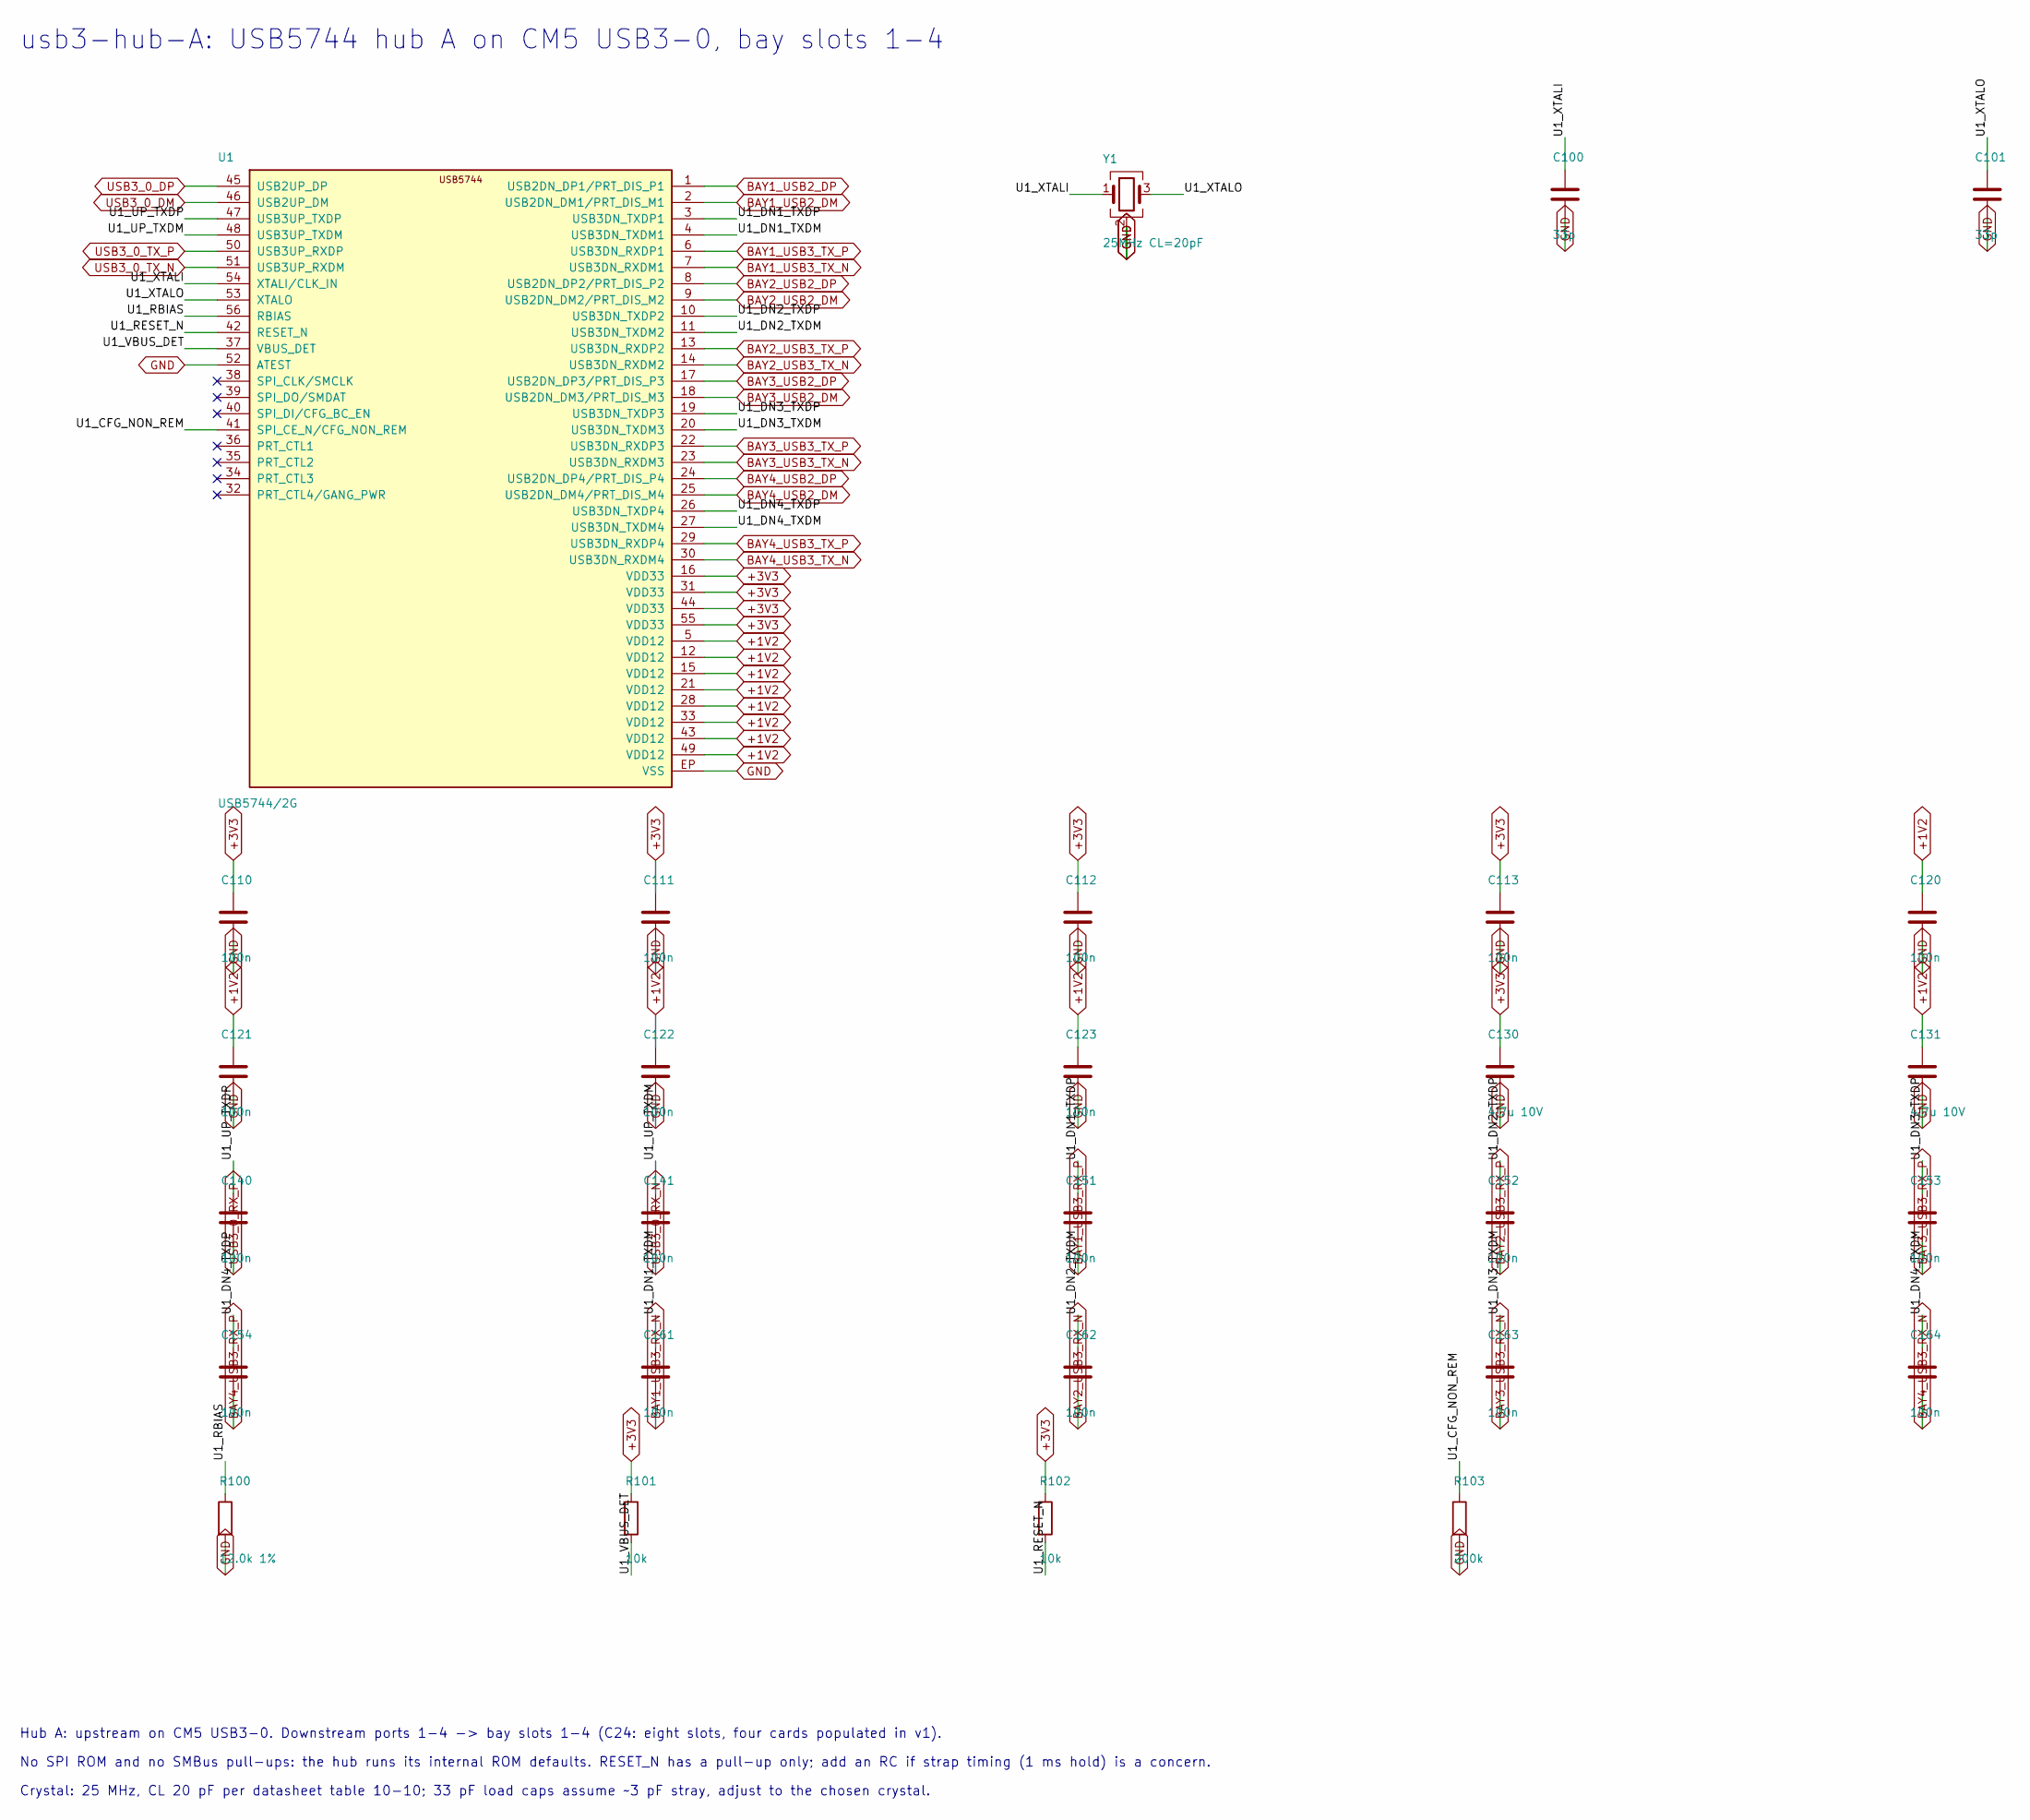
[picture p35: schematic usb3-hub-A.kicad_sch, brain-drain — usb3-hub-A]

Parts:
C100, C101: 33p; C_0402_1005Metric
C110, C111, C112, C113, C120, C121, C122, C123, C140, C141, C151, C152, C153, C154, C161, C162, C163, C164: 100n; C_0402_1005Metric
C130, C131: 4.7u 10V; C_0603_1608Metric
R100: 12.0k 1%; R_0402_1005Metric
R101, R102: 10k; R_0402_1005Metric
R103: 200k; R_0402_1005Metric
U1: USB5744/2G; QFN-56-1EP_7x7mm_P0.4mm_EP3.2x3.2mm
Y1: 25MHz CL=20pF; Crystal_SMD_3225-4Pin_3.2x2.5mm

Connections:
+1V2: C120.1, C121.1, C122.1, C123.1, C131.1, U1.5 (VDD12), U1.12 (VDD12), U1.15 (VDD12), U1.21 (VDD12), U1.28 (VDD12), U1.33 (VDD12), U1.43 (VDD12), U1.49 (VDD12); also elsewhere on the board
+3V3: C110.1, C111.1, C112.1, C113.1, C130.1, R101.1, R102.1, U1.16 (VDD33), U1.31 (VDD33), U1.44 (VDD33), U1.55 (VDD33); also elsewhere on the board
BAY1_USB2_DM: U1.2 (USB2DN_DM1/PRT_DIS_M1); also elsewhere on the board
BAY1_USB2_DP: U1.1 (USB2DN_DP1/PRT_DIS_P1); also elsewhere on the board
BAY1_USB3_RX_N: C161.2; also elsewhere on the board
BAY1_USB3_RX_P: C151.2; also elsewhere on the board
BAY1_USB3_TX_N: U1.7 (USB3DN_RXDM1); also elsewhere on the board
BAY1_USB3_TX_P: U1.6 (USB3DN_RXDP1); also elsewhere on the board
BAY2_USB2_DM: U1.9 (USB2DN_DM2/PRT_DIS_M2); also elsewhere on the board
BAY2_USB2_DP: U1.8 (USB2DN_DP2/PRT_DIS_P2); also elsewhere on the board
BAY2_USB3_RX_N: C162.2; also elsewhere on the board
BAY2_USB3_RX_P: C152.2; also elsewhere on the board
BAY2_USB3_TX_N: U1.14 (USB3DN_RXDM2); also elsewhere on the board
BAY2_USB3_TX_P: U1.13 (USB3DN_RXDP2); also elsewhere on the board
BAY3_USB2_DM: U1.18 (USB2DN_DM3/PRT_DIS_M3); also elsewhere on the board
BAY3_USB2_DP: U1.17 (USB2DN_DP3/PRT_DIS_P3); also elsewhere on the board
BAY3_USB3_RX_N: C163.2; also elsewhere on the board
BAY3_USB3_RX_P: C153.2; also elsewhere on the board
BAY3_USB3_TX_N: U1.23 (USB3DN_RXDM3); also elsewhere on the board
BAY3_USB3_TX_P: U1.22 (USB3DN_RXDP3); also elsewhere on the board
BAY4_USB2_DM: U1.25 (USB2DN_DM4/PRT_DIS_M4); also elsewhere on the board
BAY4_USB2_DP: U1.24 (USB2DN_DP4/PRT_DIS_P4); also elsewhere on the board
BAY4_USB3_RX_N: C164.2; also elsewhere on the board
BAY4_USB3_RX_P: C154.2; also elsewhere on the board
BAY4_USB3_TX_N: U1.30 (USB3DN_RXDM4); also elsewhere on the board
BAY4_USB3_TX_P: U1.29 (USB3DN_RXDP4); also elsewhere on the board
GND: C100.2, C101.2, C110.2, C111.2, C112.2, C113.2, C120.2, C121.2, C122.2, C123.2, C130.2, C131.2, R100.2, R103.2, U1.52 (ATEST), U1.EP (VSS), Y1.2 (G), Y1.4 (G); also elsewhere on the board
U1_CFG_NON_REM: R103.1, U1.41 (SPI_CE_N/CFG_NON_REM)
U1_DN1_TXDM: C161.1, U1.4 (USB3DN_TXDM1)
U1_DN1_TXDP: C151.1, U1.3 (USB3DN_TXDP1)
U1_DN2_TXDM: C162.1, U1.11 (USB3DN_TXDM2)
U1_DN2_TXDP: C152.1, U1.10 (USB3DN_TXDP2)
U1_DN3_TXDM: C163.1, U1.20 (USB3DN_TXDM3)
U1_DN3_TXDP: C153.1, U1.19 (USB3DN_TXDP3)
U1_DN4_TXDM: C164.1, U1.27 (USB3DN_TXDM4)
U1_DN4_TXDP: C154.1, U1.26 (USB3DN_TXDP4)
U1_RBIAS: R100.1, U1.56 (RBIAS)
U1_RESET_N: R102.2, U1.42 (RESET_N)
U1_UP_TXDM: C141.1, U1.48 (USB3UP_TXDM)
U1_UP_TXDP: C140.1, U1.47 (USB3UP_TXDP)
U1_VBUS_DET: R101.2, U1.37 (VBUS_DET)
U1_XTALI: C100.1, U1.54 (XTALI/CLK_IN), Y1.1
U1_XTALO: C101.1, U1.53 (XTALO), Y1.3
USB3_0_DM: U1.46 (USB2UP_DM); also elsewhere on the board
USB3_0_DP: U1.45 (USB2UP_DP); also elsewhere on the board
USB3_0_RX_N: C141.2; also elsewhere on the board
USB3_0_RX_P: C140.2; also elsewhere on the board
USB3_0_TX_N: U1.51 (USB3UP_RXDM); also elsewhere on the board
USB3_0_TX_P: U1.50 (USB3UP_RXDP); also elsewhere on the board

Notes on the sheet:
usb3-hub-A: USB5744 hub A on CM5 USB3-0, bay slots 1-4
Hub A: upstream on CM5 USB3-0. Downstream ports 1-4 -> bay slots 1-4 (C24: eight slots, four cards populated in v1).
No SPI ROM and no SMBus pull-ups: the hub runs its internal ROM defaults. RESET_N has a pull-up only; add an RC if strap timing (1 ms hold) is a concern.
Crystal: 25 MHz, CL 20 pF per datasheet table 10-10; 33 pF load caps assume ~3 pF stray, adjust to the chosen crystal.

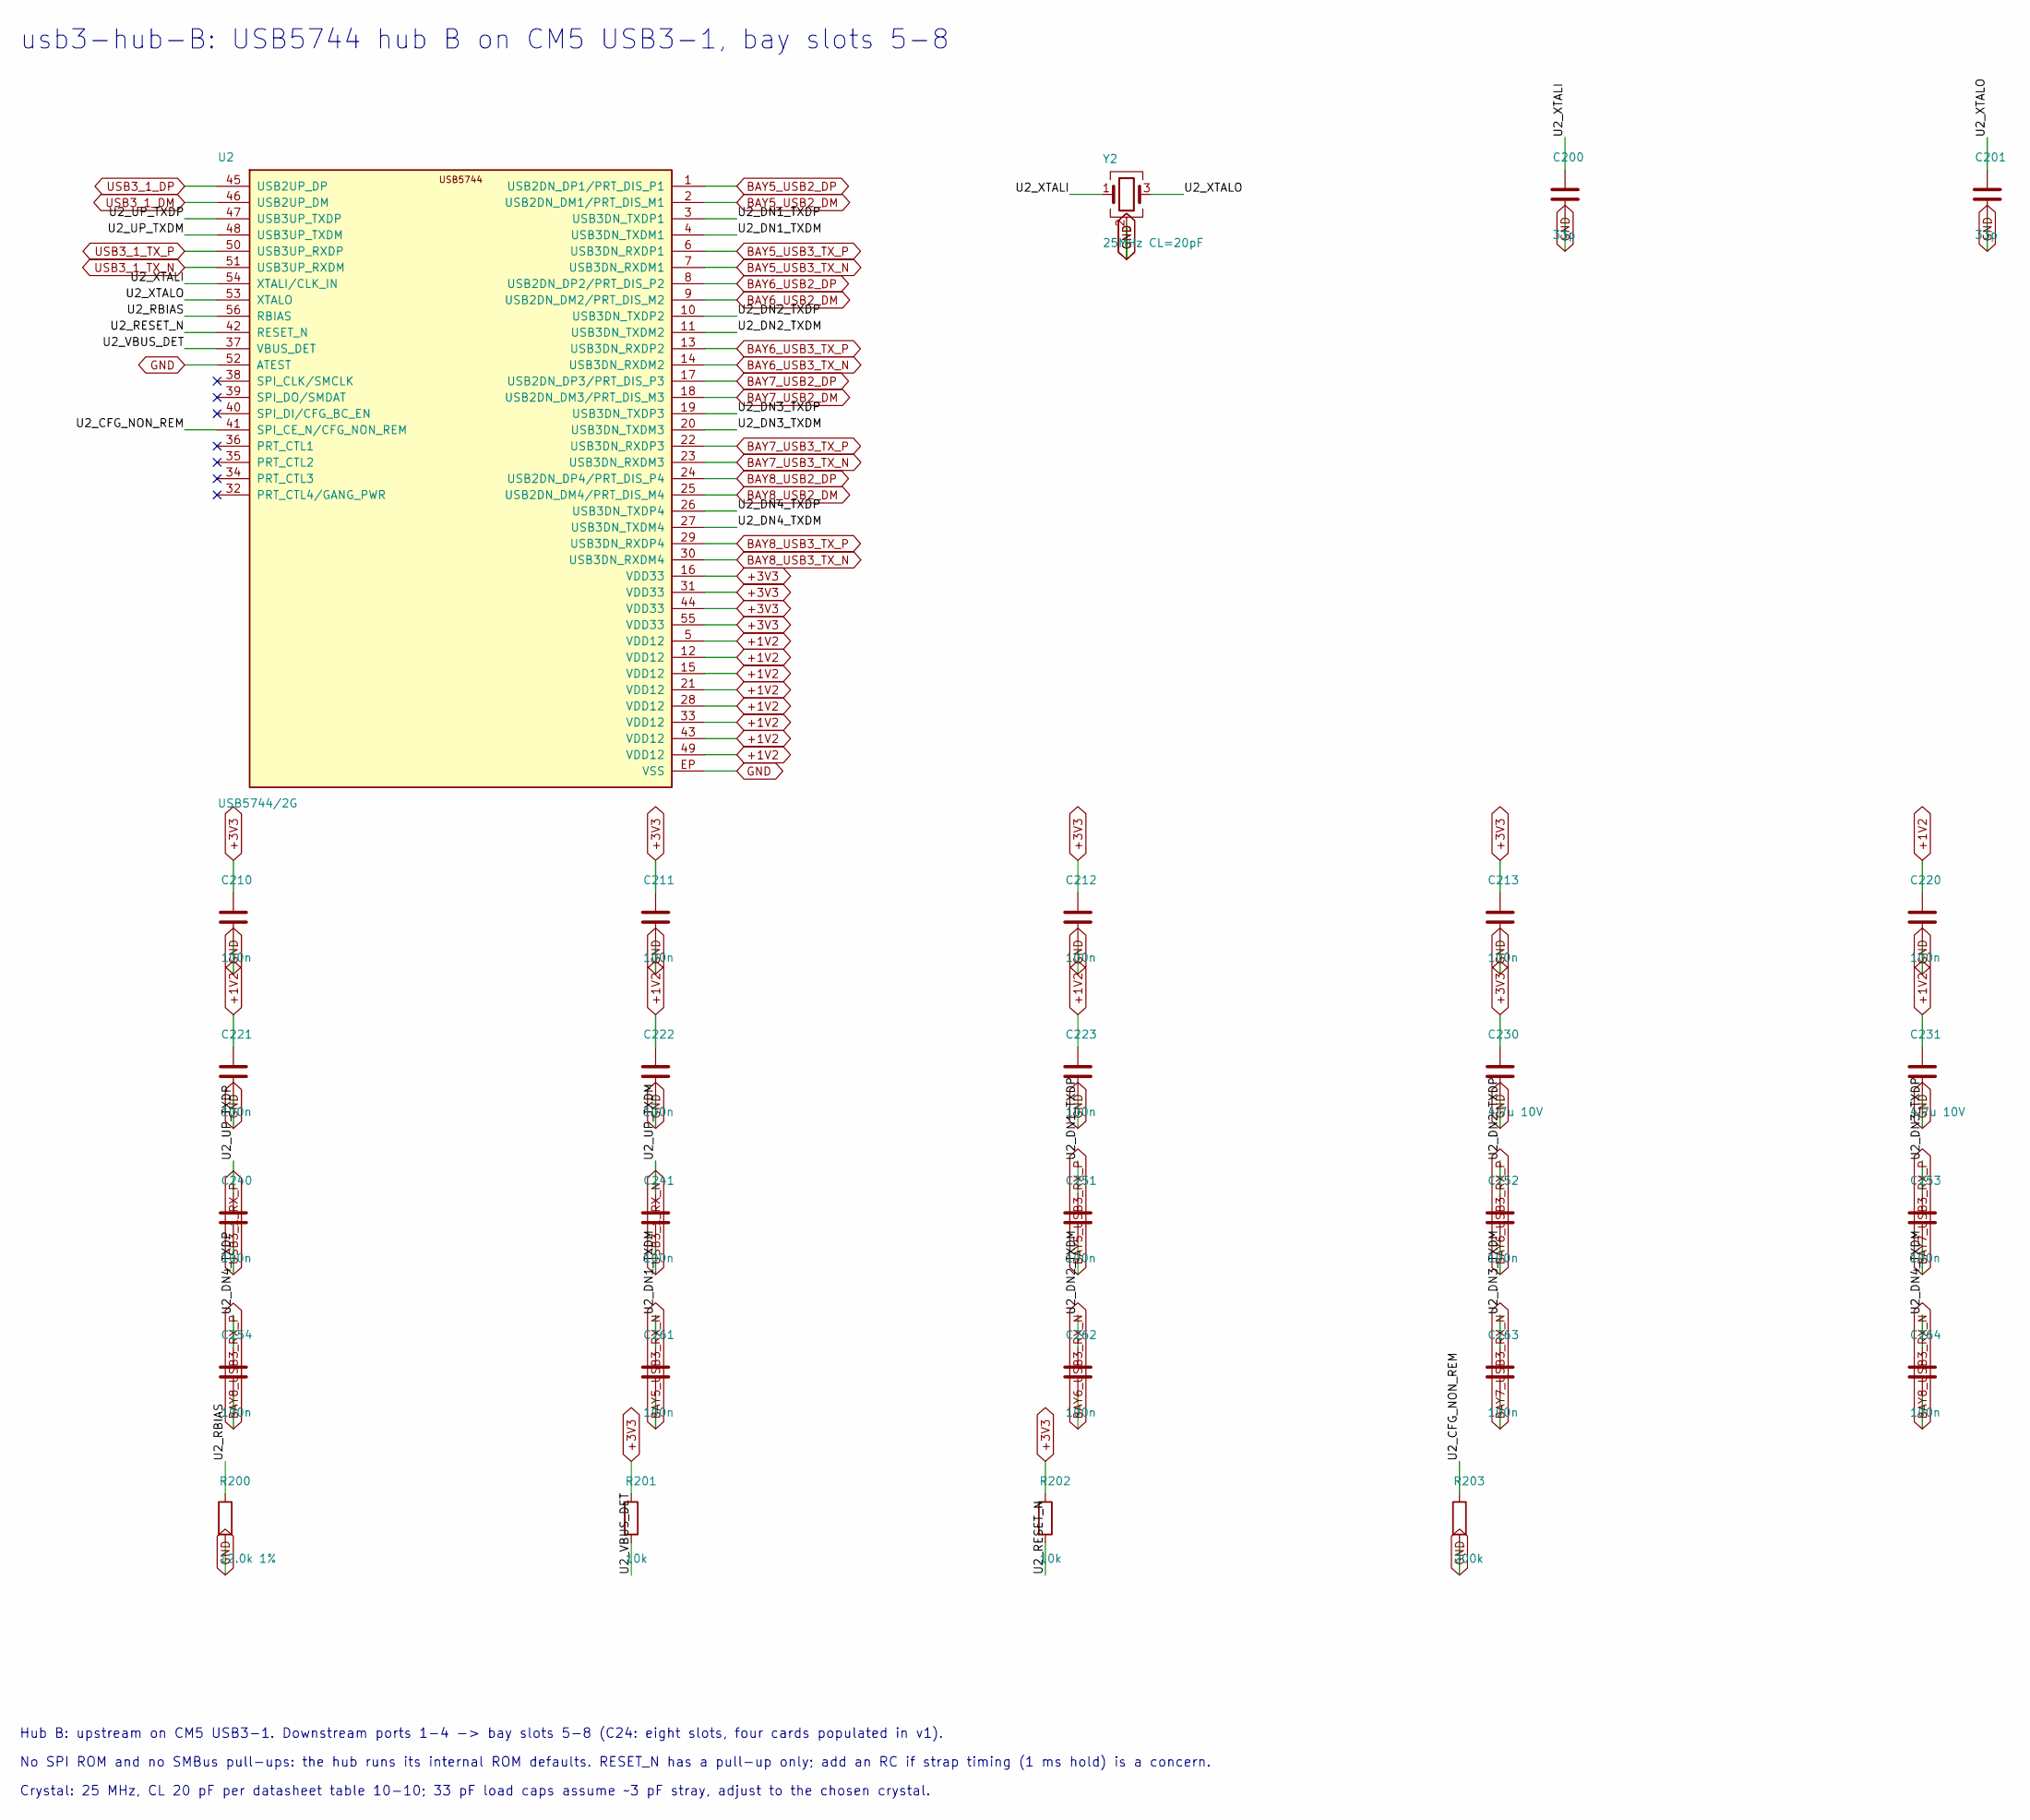
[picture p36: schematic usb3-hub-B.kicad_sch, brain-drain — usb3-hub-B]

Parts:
C200, C201: 33p; C_0402_1005Metric
C210, C211, C212, C213, C220, C221, C222, C223, C240, C241, C251, C252, C253, C254, C261, C262, C263, C264: 100n; C_0402_1005Metric
C230, C231: 4.7u 10V; C_0603_1608Metric
R200: 12.0k 1%; R_0402_1005Metric
R201, R202: 10k; R_0402_1005Metric
R203: 200k; R_0402_1005Metric
U2: USB5744/2G; QFN-56-1EP_7x7mm_P0.4mm_EP3.2x3.2mm
Y2: 25MHz CL=20pF; Crystal_SMD_3225-4Pin_3.2x2.5mm

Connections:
+1V2: C220.1, C221.1, C222.1, C223.1, C231.1, U2.5 (VDD12), U2.12 (VDD12), U2.15 (VDD12), U2.21 (VDD12), U2.28 (VDD12), U2.33 (VDD12), U2.43 (VDD12), U2.49 (VDD12); also elsewhere on the board
+3V3: C210.1, C211.1, C212.1, C213.1, C230.1, R201.1, R202.1, U2.16 (VDD33), U2.31 (VDD33), U2.44 (VDD33), U2.55 (VDD33); also elsewhere on the board
BAY5_USB2_DM: U2.2 (USB2DN_DM1/PRT_DIS_M1); also elsewhere on the board
BAY5_USB2_DP: U2.1 (USB2DN_DP1/PRT_DIS_P1); also elsewhere on the board
BAY5_USB3_RX_N: C261.2; also elsewhere on the board
BAY5_USB3_RX_P: C251.2; also elsewhere on the board
BAY5_USB3_TX_N: U2.7 (USB3DN_RXDM1); also elsewhere on the board
BAY5_USB3_TX_P: U2.6 (USB3DN_RXDP1); also elsewhere on the board
BAY6_USB2_DM: U2.9 (USB2DN_DM2/PRT_DIS_M2); also elsewhere on the board
BAY6_USB2_DP: U2.8 (USB2DN_DP2/PRT_DIS_P2); also elsewhere on the board
BAY6_USB3_RX_N: C262.2; also elsewhere on the board
BAY6_USB3_RX_P: C252.2; also elsewhere on the board
BAY6_USB3_TX_N: U2.14 (USB3DN_RXDM2); also elsewhere on the board
BAY6_USB3_TX_P: U2.13 (USB3DN_RXDP2); also elsewhere on the board
BAY7_USB2_DM: U2.18 (USB2DN_DM3/PRT_DIS_M3); also elsewhere on the board
BAY7_USB2_DP: U2.17 (USB2DN_DP3/PRT_DIS_P3); also elsewhere on the board
BAY7_USB3_RX_N: C263.2; also elsewhere on the board
BAY7_USB3_RX_P: C253.2; also elsewhere on the board
BAY7_USB3_TX_N: U2.23 (USB3DN_RXDM3); also elsewhere on the board
BAY7_USB3_TX_P: U2.22 (USB3DN_RXDP3); also elsewhere on the board
BAY8_USB2_DM: U2.25 (USB2DN_DM4/PRT_DIS_M4); also elsewhere on the board
BAY8_USB2_DP: U2.24 (USB2DN_DP4/PRT_DIS_P4); also elsewhere on the board
BAY8_USB3_RX_N: C264.2; also elsewhere on the board
BAY8_USB3_RX_P: C254.2; also elsewhere on the board
BAY8_USB3_TX_N: U2.30 (USB3DN_RXDM4); also elsewhere on the board
BAY8_USB3_TX_P: U2.29 (USB3DN_RXDP4); also elsewhere on the board
GND: C200.2, C201.2, C210.2, C211.2, C212.2, C213.2, C220.2, C221.2, C222.2, C223.2, C230.2, C231.2, R200.2, R203.2, U2.52 (ATEST), U2.EP (VSS), Y2.2 (G), Y2.4 (G); also elsewhere on the board
U2_CFG_NON_REM: R203.1, U2.41 (SPI_CE_N/CFG_NON_REM)
U2_DN1_TXDM: C261.1, U2.4 (USB3DN_TXDM1)
U2_DN1_TXDP: C251.1, U2.3 (USB3DN_TXDP1)
U2_DN2_TXDM: C262.1, U2.11 (USB3DN_TXDM2)
U2_DN2_TXDP: C252.1, U2.10 (USB3DN_TXDP2)
U2_DN3_TXDM: C263.1, U2.20 (USB3DN_TXDM3)
U2_DN3_TXDP: C253.1, U2.19 (USB3DN_TXDP3)
U2_DN4_TXDM: C264.1, U2.27 (USB3DN_TXDM4)
U2_DN4_TXDP: C254.1, U2.26 (USB3DN_TXDP4)
U2_RBIAS: R200.1, U2.56 (RBIAS)
U2_RESET_N: R202.2, U2.42 (RESET_N)
U2_UP_TXDM: C241.1, U2.48 (USB3UP_TXDM)
U2_UP_TXDP: C240.1, U2.47 (USB3UP_TXDP)
U2_VBUS_DET: R201.2, U2.37 (VBUS_DET)
U2_XTALI: C200.1, U2.54 (XTALI/CLK_IN), Y2.1
U2_XTALO: C201.1, U2.53 (XTALO), Y2.3
USB3_1_DM: U2.46 (USB2UP_DM); also elsewhere on the board
USB3_1_DP: U2.45 (USB2UP_DP); also elsewhere on the board
USB3_1_RX_N: C241.2; also elsewhere on the board
USB3_1_RX_P: C240.2; also elsewhere on the board
USB3_1_TX_N: U2.51 (USB3UP_RXDM); also elsewhere on the board
USB3_1_TX_P: U2.50 (USB3UP_RXDP); also elsewhere on the board

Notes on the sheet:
usb3-hub-B: USB5744 hub B on CM5 USB3-1, bay slots 5-8
Hub B: upstream on CM5 USB3-1. Downstream ports 1-4 -> bay slots 5-8 (C24: eight slots, four cards populated in v1).
No SPI ROM and no SMBus pull-ups: the hub runs its internal ROM defaults. RESET_N has a pull-up only; add an RC if strap timing (1 ms hold) is a concern.
Crystal: 25 MHz, CL 20 pF per datasheet table 10-10; 33 pF load caps assume ~3 pF stray, adjust to the chosen crystal.

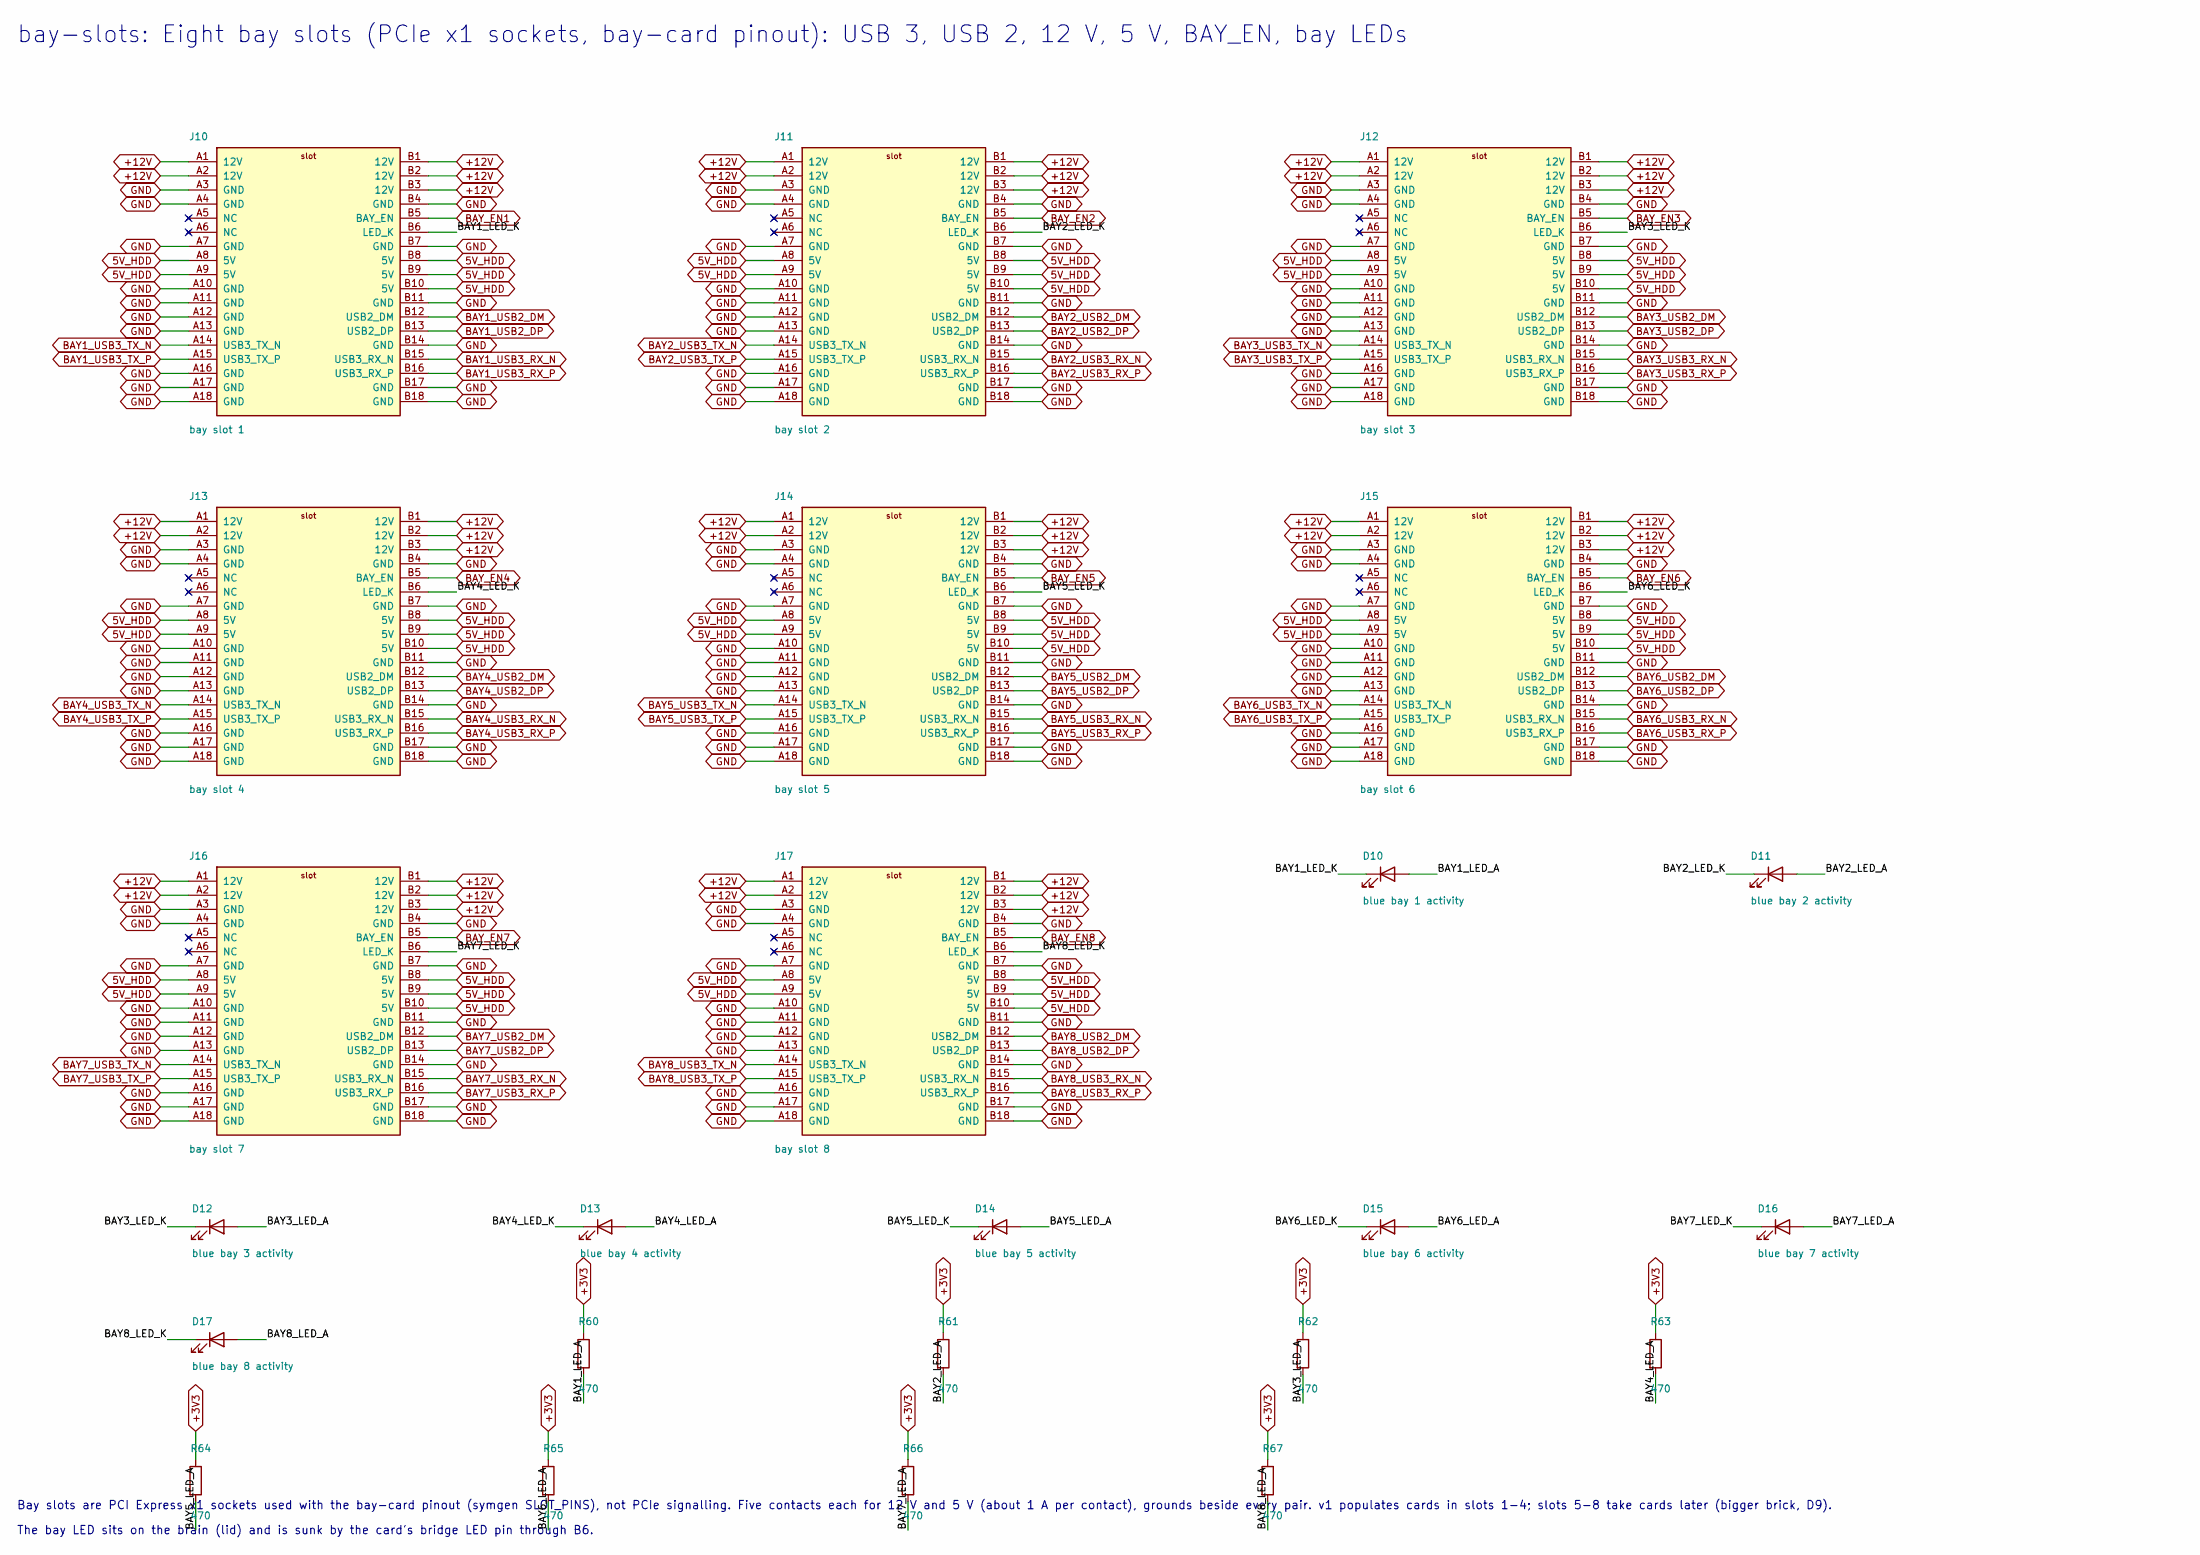
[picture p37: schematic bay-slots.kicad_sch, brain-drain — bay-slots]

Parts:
D10: blue bay 1 activity; LED_D3.0mm
D11: blue bay 2 activity; LED_D3.0mm
D12: blue bay 3 activity; LED_D3.0mm
D13: blue bay 4 activity; LED_D3.0mm
D14: blue bay 5 activity; LED_D3.0mm
D15: blue bay 6 activity; LED_D3.0mm
D16: blue bay 7 activity; LED_D3.0mm
D17: blue bay 8 activity; LED_D3.0mm
J10: bay slot 1; PCIe_x1_Socket_THT
J11: bay slot 2; PCIe_x1_Socket_THT
J12: bay slot 3; PCIe_x1_Socket_THT
J13: bay slot 4; PCIe_x1_Socket_THT
J14: bay slot 5; PCIe_x1_Socket_THT
J15: bay slot 6; PCIe_x1_Socket_THT
J16: bay slot 7; PCIe_x1_Socket_THT
J17: bay slot 8; PCIe_x1_Socket_THT
R60, R61, R62, R63, R64, R65, R66, R67: 470; R_0402_1005Metric

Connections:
5V_HDD: J10.A8 (5V), J10.A9 (5V), J10.B8 (5V), J10.B9 (5V), J10.B10 (5V), J11.A8 (5V), J11.A9 (5V), J11.B8 (5V), J11.B9 (5V), J11.B10 (5V), J12.A8 (5V), J12.A9 (5V), J12.B8 (5V), J12.B9 (5V), J12.B10 (5V), J13.A8 (5V), J13.A9 (5V), J13.B8 (5V), J13.B9 (5V), J13.B10 (5V), J14.A8 (5V), J14.A9 (5V), J14.B8 (5V), J14.B9 (5V), J14.B10 (5V), J15.A8 (5V), J15.A9 (5V), J15.B8 (5V), J15.B9 (5V), J15.B10 (5V), J16.A8 (5V), J16.A9 (5V), J16.B8 (5V), J16.B9 (5V), J16.B10 (5V), J17.A8 (5V), J17.A9 (5V), J17.B8 (5V), J17.B9 (5V), J17.B10 (5V); also elsewhere on the board
+3V3: R60.1, R61.1, R62.1, R63.1, R64.1, R65.1, R66.1, R67.1; also elsewhere on the board
+12V: J10.A1 (12V), J10.A2 (12V), J10.B1 (12V), J10.B2 (12V), J10.B3 (12V), J11.A1 (12V), J11.A2 (12V), J11.B1 (12V), J11.B2 (12V), J11.B3 (12V), J12.A1 (12V), J12.A2 (12V), J12.B1 (12V), J12.B2 (12V), J12.B3 (12V), J13.A1 (12V), J13.A2 (12V), J13.B1 (12V), J13.B2 (12V), J13.B3 (12V), J14.A1 (12V), J14.A2 (12V), J14.B1 (12V), J14.B2 (12V), J14.B3 (12V), J15.A1 (12V), J15.A2 (12V), J15.B1 (12V), J15.B2 (12V), J15.B3 (12V), J16.A1 (12V), J16.A2 (12V), J16.B1 (12V), J16.B2 (12V), J16.B3 (12V), J17.A1 (12V), J17.A2 (12V), J17.B1 (12V), J17.B2 (12V), J17.B3 (12V); also elsewhere on the board
BAY1_LED_A: D10.2 (A), R60.2
BAY1_LED_K: D10.1 (K), J10.B6 (LED_K)
BAY1_USB2_DM: J10.B12 (USB2_DM); also elsewhere on the board
BAY1_USB2_DP: J10.B13 (USB2_DP); also elsewhere on the board
BAY1_USB3_RX_N: J10.B15 (USB3_RX_N); also elsewhere on the board
BAY1_USB3_RX_P: J10.B16 (USB3_RX_P); also elsewhere on the board
BAY1_USB3_TX_N: J10.A14 (USB3_TX_N); also elsewhere on the board
BAY1_USB3_TX_P: J10.A15 (USB3_TX_P); also elsewhere on the board
BAY2_LED_A: D11.2 (A), R61.2
BAY2_LED_K: D11.1 (K), J11.B6 (LED_K)
BAY2_USB2_DM: J11.B12 (USB2_DM); also elsewhere on the board
BAY2_USB2_DP: J11.B13 (USB2_DP); also elsewhere on the board
BAY2_USB3_RX_N: J11.B15 (USB3_RX_N); also elsewhere on the board
BAY2_USB3_RX_P: J11.B16 (USB3_RX_P); also elsewhere on the board
BAY2_USB3_TX_N: J11.A14 (USB3_TX_N); also elsewhere on the board
BAY2_USB3_TX_P: J11.A15 (USB3_TX_P); also elsewhere on the board
BAY3_LED_A: D12.2 (A), R62.2
BAY3_LED_K: D12.1 (K), J12.B6 (LED_K)
BAY3_USB2_DM: J12.B12 (USB2_DM); also elsewhere on the board
BAY3_USB2_DP: J12.B13 (USB2_DP); also elsewhere on the board
BAY3_USB3_RX_N: J12.B15 (USB3_RX_N); also elsewhere on the board
BAY3_USB3_RX_P: J12.B16 (USB3_RX_P); also elsewhere on the board
BAY3_USB3_TX_N: J12.A14 (USB3_TX_N); also elsewhere on the board
BAY3_USB3_TX_P: J12.A15 (USB3_TX_P); also elsewhere on the board
BAY4_LED_A: D13.2 (A), R63.2
BAY4_LED_K: D13.1 (K), J13.B6 (LED_K)
BAY4_USB2_DM: J13.B12 (USB2_DM); also elsewhere on the board
BAY4_USB2_DP: J13.B13 (USB2_DP); also elsewhere on the board
BAY4_USB3_RX_N: J13.B15 (USB3_RX_N); also elsewhere on the board
BAY4_USB3_RX_P: J13.B16 (USB3_RX_P); also elsewhere on the board
BAY4_USB3_TX_N: J13.A14 (USB3_TX_N); also elsewhere on the board
BAY4_USB3_TX_P: J13.A15 (USB3_TX_P); also elsewhere on the board
BAY5_LED_A: D14.2 (A), R64.2
BAY5_LED_K: D14.1 (K), J14.B6 (LED_K)
BAY5_USB2_DM: J14.B12 (USB2_DM); also elsewhere on the board
BAY5_USB2_DP: J14.B13 (USB2_DP); also elsewhere on the board
BAY5_USB3_RX_N: J14.B15 (USB3_RX_N); also elsewhere on the board
BAY5_USB3_RX_P: J14.B16 (USB3_RX_P); also elsewhere on the board
BAY5_USB3_TX_N: J14.A14 (USB3_TX_N); also elsewhere on the board
BAY5_USB3_TX_P: J14.A15 (USB3_TX_P); also elsewhere on the board
BAY6_LED_A: D15.2 (A), R65.2
BAY6_LED_K: D15.1 (K), J15.B6 (LED_K)
BAY6_USB2_DM: J15.B12 (USB2_DM); also elsewhere on the board
BAY6_USB2_DP: J15.B13 (USB2_DP); also elsewhere on the board
BAY6_USB3_RX_N: J15.B15 (USB3_RX_N); also elsewhere on the board
BAY6_USB3_RX_P: J15.B16 (USB3_RX_P); also elsewhere on the board
BAY6_USB3_TX_N: J15.A14 (USB3_TX_N); also elsewhere on the board
BAY6_USB3_TX_P: J15.A15 (USB3_TX_P); also elsewhere on the board
BAY7_LED_A: D16.2 (A), R66.2
BAY7_LED_K: D16.1 (K), J16.B6 (LED_K)
BAY7_USB2_DM: J16.B12 (USB2_DM); also elsewhere on the board
BAY7_USB2_DP: J16.B13 (USB2_DP); also elsewhere on the board
BAY7_USB3_RX_N: J16.B15 (USB3_RX_N); also elsewhere on the board
BAY7_USB3_RX_P: J16.B16 (USB3_RX_P); also elsewhere on the board
BAY7_USB3_TX_N: J16.A14 (USB3_TX_N); also elsewhere on the board
BAY7_USB3_TX_P: J16.A15 (USB3_TX_P); also elsewhere on the board
BAY8_LED_A: D17.2 (A), R67.2
BAY8_LED_K: D17.1 (K), J17.B6 (LED_K)
BAY8_USB2_DM: J17.B12 (USB2_DM); also elsewhere on the board
BAY8_USB2_DP: J17.B13 (USB2_DP); also elsewhere on the board
BAY8_USB3_RX_N: J17.B15 (USB3_RX_N); also elsewhere on the board
BAY8_USB3_RX_P: J17.B16 (USB3_RX_P); also elsewhere on the board
BAY8_USB3_TX_N: J17.A14 (USB3_TX_N); also elsewhere on the board
BAY8_USB3_TX_P: J17.A15 (USB3_TX_P); also elsewhere on the board
BAY_EN1: J10.B5 (BAY_EN); also elsewhere on the board
BAY_EN2: J11.B5 (BAY_EN); also elsewhere on the board
BAY_EN3: J12.B5 (BAY_EN); also elsewhere on the board
BAY_EN4: J13.B5 (BAY_EN); also elsewhere on the board
BAY_EN5: J14.B5 (BAY_EN); also elsewhere on the board
BAY_EN6: J15.B5 (BAY_EN); also elsewhere on the board
BAY_EN7: J16.B5 (BAY_EN); also elsewhere on the board
BAY_EN8: J17.B5 (BAY_EN); also elsewhere on the board
GND: J10.A3 (GND), J10.A4 (GND), J10.A7 (GND), J10.A10 (GND), J10.A11 (GND), J10.A12 (GND), J10.A13 (GND), J10.A16 (GND), J10.A17 (GND), J10.A18 (GND), J10.B4 (GND), J10.B7 (GND), J10.B11 (GND), J10.B14 (GND), J10.B17 (GND), J10.B18 (GND), J11.A3 (GND), J11.A4 (GND), J11.A7 (GND), J11.A10 (GND), J11.A11 (GND), J11.A12 (GND), J11.A13 (GND), J11.A16 (GND), J11.A17 (GND), J11.A18 (GND), J11.B4 (GND), J11.B7 (GND), J11.B11 (GND), J11.B14 (GND), J11.B17 (GND), J11.B18 (GND), J12.A3 (GND), J12.A4 (GND), J12.A7 (GND), J12.A10 (GND), J12.A11 (GND), J12.A12 (GND), J12.A13 (GND), J12.A16 (GND), J12.A17 (GND), J12.A18 (GND), J12.B4 (GND), J12.B7 (GND), J12.B11 (GND), J12.B14 (GND), J12.B17 (GND), J12.B18 (GND), J13.A3 (GND), J13.A4 (GND), J13.A7 (GND), J13.A10 (GND), J13.A11 (GND), J13.A12 (GND), J13.A13 (GND), J13.A16 (GND), J13.A17 (GND), J13.A18 (GND), J13.B4 (GND), J13.B7 (GND), J13.B11 (GND), J13.B14 (GND), J13.B17 (GND), J13.B18 (GND), J14.A3 (GND), J14.A4 (GND), J14.A7 (GND), J14.A10 (GND), J14.A11 (GND), J14.A12 (GND), J14.A13 (GND), J14.A16 (GND), J14.A17 (GND), J14.A18 (GND), J14.B4 (GND), J14.B7 (GND), J14.B11 (GND), J14.B14 (GND), J14.B17 (GND), J14.B18 (GND), J15.A3 (GND), J15.A4 (GND), J15.A7 (GND), J15.A10 (GND), J15.A11 (GND), J15.A12 (GND), J15.A13 (GND), J15.A16 (GND), J15.A17 (GND), J15.A18 (GND), J15.B4 (GND), J15.B7 (GND), J15.B11 (GND), J15.B14 (GND), J15.B17 (GND), J15.B18 (GND), J16.A3 (GND), J16.A4 (GND), J16.A7 (GND), J16.A10 (GND), J16.A11 (GND), J16.A12 (GND), J16.A13 (GND), J16.A16 (GND), J16.A17 (GND), J16.A18 (GND), J16.B4 (GND), J16.B7 (GND), J16.B11 (GND), J16.B14 (GND), J16.B17 (GND), J16.B18 (GND), J17.A3 (GND), J17.A4 (GND), J17.A7 (GND), J17.A10 (GND), J17.A11 (GND), J17.A12 (GND), J17.A13 (GND), J17.A16 (GND), J17.A17 (GND), J17.A18 (GND), J17.B4 (GND), J17.B7 (GND), J17.B11 (GND), J17.B14 (GND), J17.B17 (GND), J17.B18 (GND); also elsewhere on the board

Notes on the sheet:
bay-slots: Eight bay slots (PCIe x1 sockets, bay-card pinout): USB 3, USB 2, 12 V, 5 V, BAY_EN, bay LEDs
Bay slots are PCI Express x1 sockets used with the bay-card pinout (symgen SLOT_PINS), not PCIe signalling. Five contacts each for 12 V and 5 V (about 1 A per contact), grounds beside every pair. v1 populates cards in slots 1-4; slots 5-8 take cards later (bigger brick, D9).
The bay LED sits on the brain (lid) and is sunk by the card's bridge LED pin through B6.

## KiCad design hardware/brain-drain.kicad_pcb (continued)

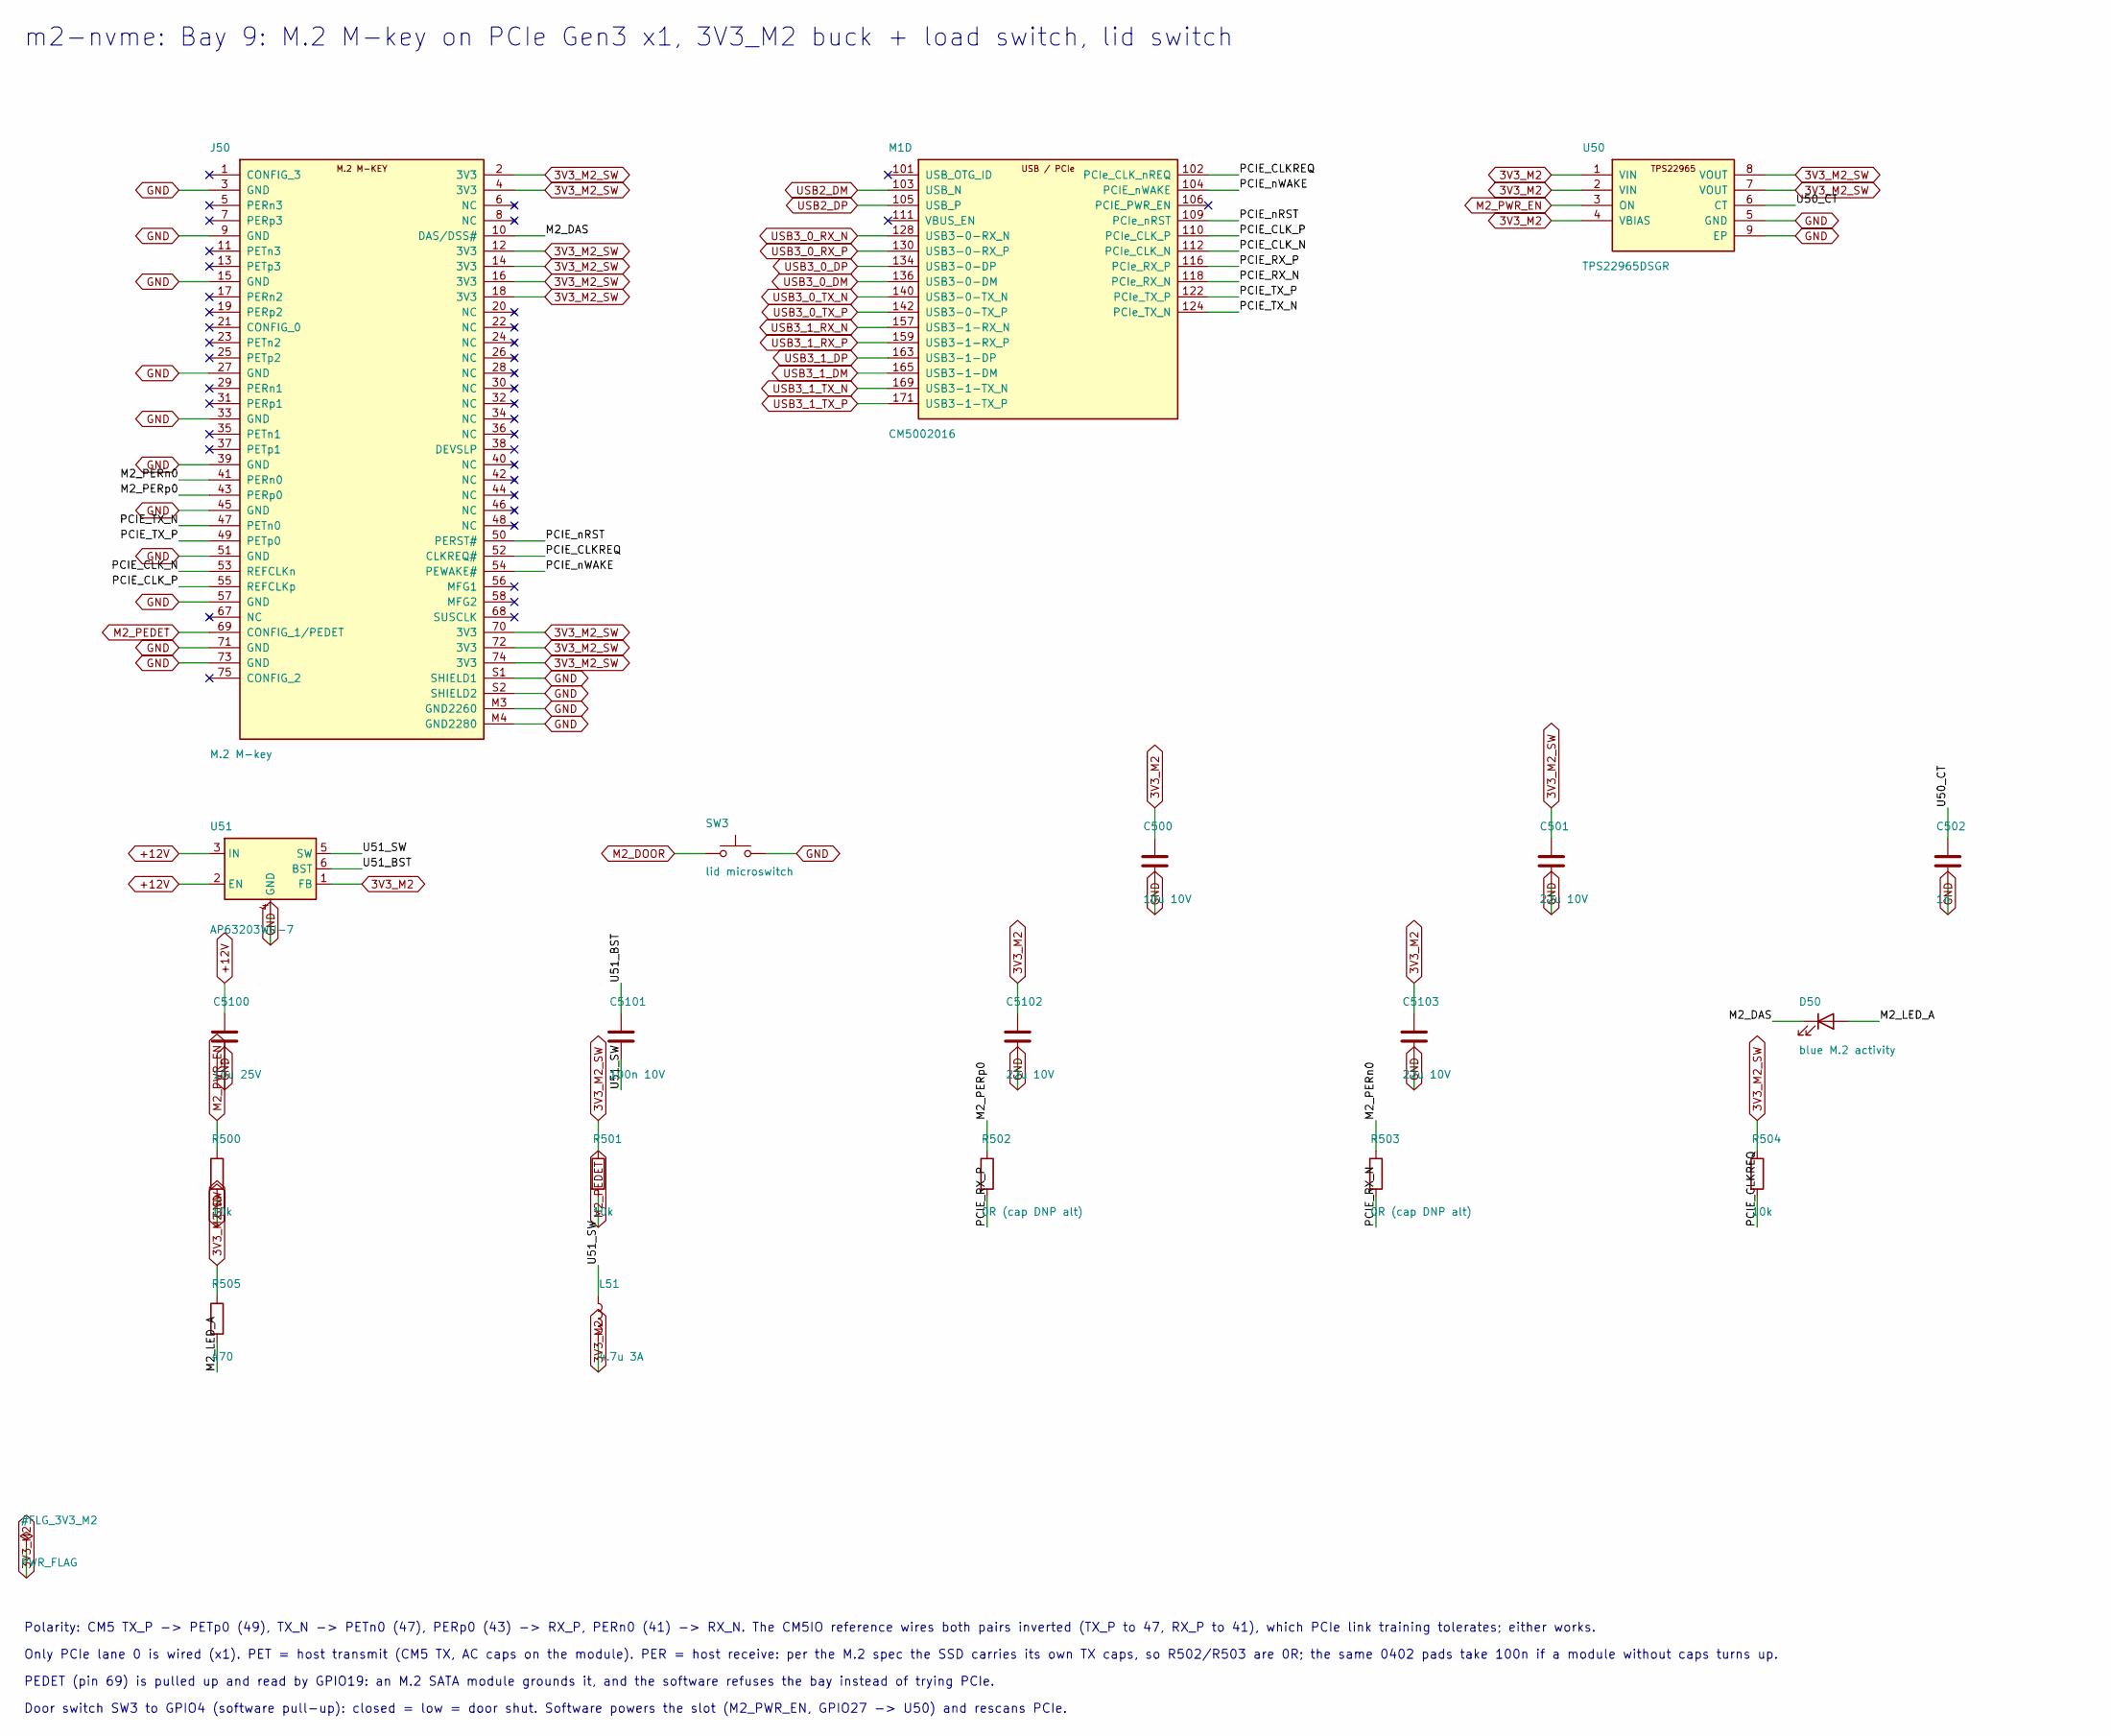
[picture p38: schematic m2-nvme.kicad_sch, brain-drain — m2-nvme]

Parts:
C500: 10u 10V; C_0805_2012Metric
C501, C5102, C5103: 22u 10V; C_0805_2012Metric
C502: 1n; C_0402_1005Metric
C5100: 10u 25V; C_1210_3225Metric
C5101: 100n 10V; C_0402_1005Metric
D50: blue M.2 activity; LED_D3.0mm
J50: M.2 M-key; M2_Socket3_MKey_CM5IO
L51: 4.7u 3A; L_Taiyo-Yuden_NR-40xx
M1: CM5002016; Raspberry-Pi-5-Compute-Module
R500, R501, R504: 10k; R_0402_1005Metric
R502, R503: 0R (cap DNP alt); C_0402_1005Metric
R505: 470; R_0402_1005Metric
SW3: lid microswitch; SW_PUSH_6mm
U50: TPS22965DSGR; Texas_DSG0008A_WSON-8-1EP_2x2mm_P0.5mm_EP0.9x1.6mm
U51: AP63203WU-7; TSOT-23-6

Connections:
3V3_M2: C500.1, C5102.1, C5103.1, L51.2, U50.1 (VIN), U50.2 (VIN), U50.4 (VBIAS), U51.1 (FB)
3V3_M2_SW: C501.1, J50.2 (3V3), J50.4 (3V3), J50.12 (3V3), J50.14 (3V3), J50.16 (3V3), J50.18 (3V3), J50.70 (3V3), J50.72 (3V3), J50.74 (3V3), R501.1, R504.1, R505.1, U50.7 (VOUT), U50.8 (VOUT)
+12V: C5100.1, U51.2 (EN), U51.3 (IN); also elsewhere on the board
GND: C500.2, C501.2, C502.2, C5100.2, C5102.2, C5103.2, J50.3 (GND), J50.9 (GND), J50.15 (GND), J50.27 (GND), J50.33 (GND), J50.39 (GND), J50.45 (GND), J50.51 (GND), J50.57 (GND), J50.71 (GND), J50.73 (GND), J50.M3 (GND2260), J50.M4 (GND2280), J50.S1 (SHIELD1), J50.S2 (SHIELD2), R500.2, SW3.2, U50.5 (GND), U50.9 (EP), U51.4 (GND); also elsewhere on the board
M2_DAS: D50.1 (K), J50.10 (DAS/DSS#)
M2_DOOR: SW3.1; also elsewhere on the board
M2_LED_A: D50.2 (A), R505.2
M2_PEDET: J50.69 (CONFIG_1/PEDET), R501.2; also elsewhere on the board
M2_PERn0: J50.41 (PERn0), R503.1
M2_PERp0: J50.43 (PERp0), R502.1
M2_PWR_EN: R500.1, U50.3 (ON); also elsewhere on the board
PCIE_CLKREQ: J50.52 (CLKREQ#), M1.102 (PCIe_CLK_nREQ), R504.2
PCIE_CLK_N: J50.53 (REFCLKn), M1.112 (PCIe_CLK_N)
PCIE_CLK_P: J50.55 (REFCLKp), M1.110 (PCIe_CLK_P)
PCIE_RX_N: M1.118 (PCIe_RX_N), R503.2
PCIE_RX_P: M1.116 (PCIe_RX_P), R502.2
PCIE_TX_N: J50.47 (PETn0), M1.124 (PCIe_TX_N)
PCIE_TX_P: J50.49 (PETp0), M1.122 (PCIe_TX_P)
PCIE_nRST: J50.50 (PERST#), M1.109 (PCIe_nRST)
PCIE_nWAKE: J50.54 (PEWAKE#), M1.104 (PCIE_nWAKE)
U50_CT: C502.1, U50.6 (CT)
U51_BST: C5101.1, U51.6 (BST)
U51_SW: C5101.2, L51.1, U51.5 (SW)
USB2_DM: M1.103 (USB_N); also elsewhere on the board
USB2_DP: M1.105 (USB_P); also elsewhere on the board
USB3_0_DM: M1.136 (USB3-0-DM); also elsewhere on the board
USB3_0_DP: M1.134 (USB3-0-DP); also elsewhere on the board
USB3_0_RX_N: M1.128 (USB3-0-RX_N); also elsewhere on the board
USB3_0_RX_P: M1.130 (USB3-0-RX_P); also elsewhere on the board
USB3_0_TX_N: M1.140 (USB3-0-TX_N); also elsewhere on the board
USB3_0_TX_P: M1.142 (USB3-0-TX_P); also elsewhere on the board
USB3_1_DM: M1.165 (USB3-1-DM); also elsewhere on the board
USB3_1_DP: M1.163 (USB3-1-DP); also elsewhere on the board
USB3_1_RX_N: M1.157 (USB3-1-RX_N); also elsewhere on the board
USB3_1_RX_P: M1.159 (USB3-1-RX_P); also elsewhere on the board
USB3_1_TX_N: M1.169 (USB3-1-TX_N); also elsewhere on the board
USB3_1_TX_P: M1.171 (USB3-1-TX_P); also elsewhere on the board

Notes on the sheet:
m2-nvme: Bay 9: M.2 M-key on PCIe Gen3 x1, 3V3_M2 buck + load switch, lid switch
Polarity: CM5 TX_P -> PETp0 (49), TX_N -> PETn0 (47), PERp0 (43) -> RX_P, PERn0 (41) -> RX_N. The CM5IO reference wires both pairs inverted (TX_P to 47, RX_P to 41), which PCIe link training tolerates; either works.
Only PCIe lane 0 is wired (x1). PET = host transmit (CM5 TX, AC caps on the module). PER = host receive: per the M.2 spec the SSD carries its own TX caps, so R502/R503 are 0R; the same 0402 pads take 100n if a module without caps turns up.
PEDET (pin 69) is pulled up and read by GPIO19: an M.2 SATA module grounds it, and the software refuses the bay instead of trying PCIe.
Door switch SW3 to GPIO4 (software pull-up): closed = low = door shut. Software powers the slot (M2_PWR_EN, GPIO27 -> U50) and rescans PCIe.

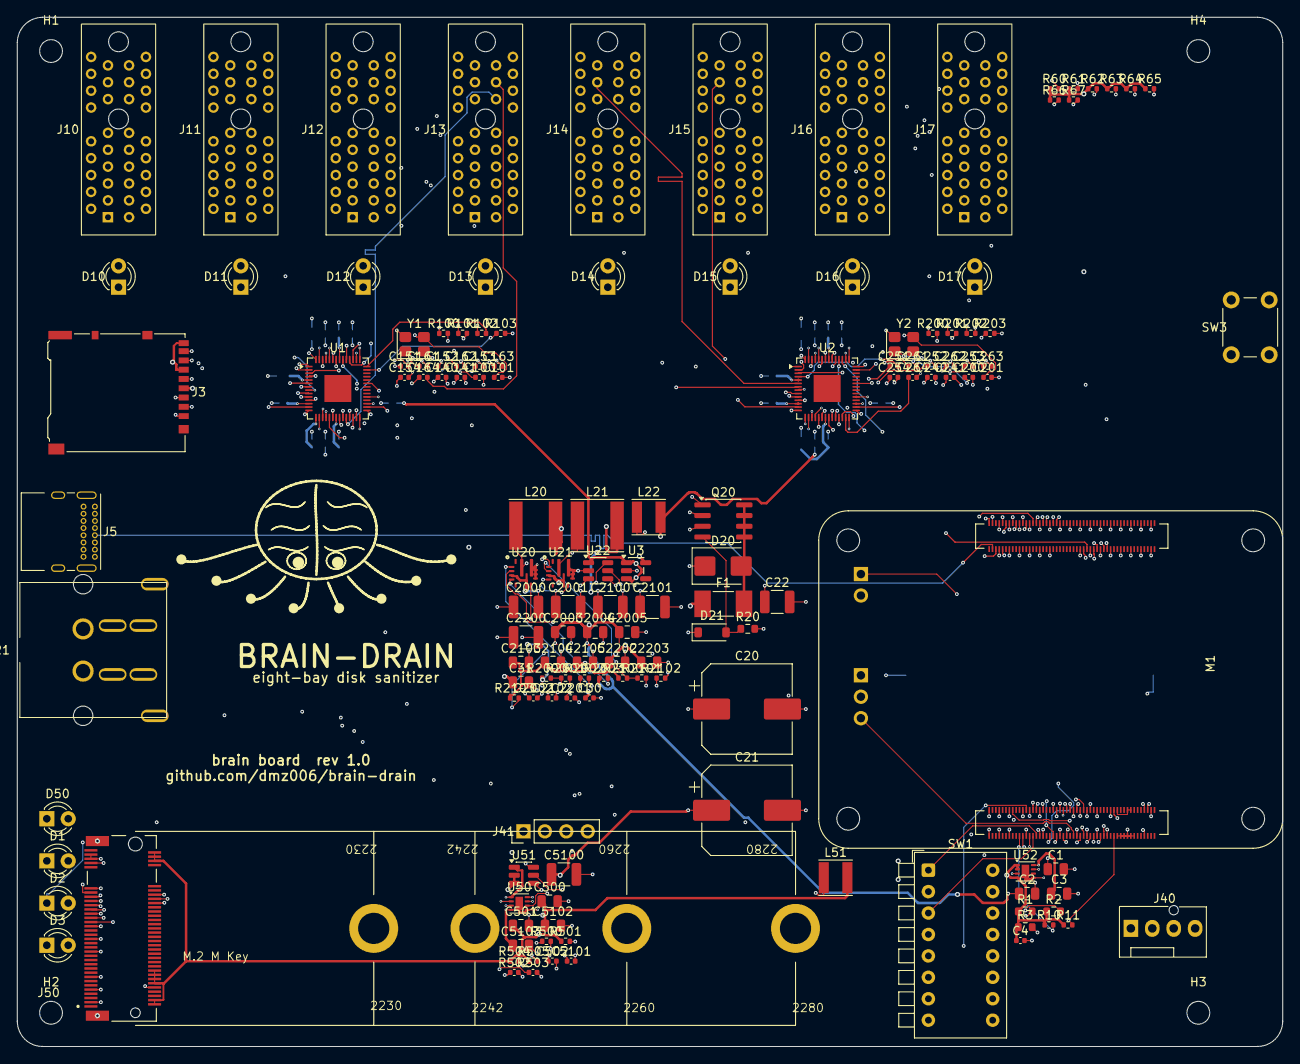
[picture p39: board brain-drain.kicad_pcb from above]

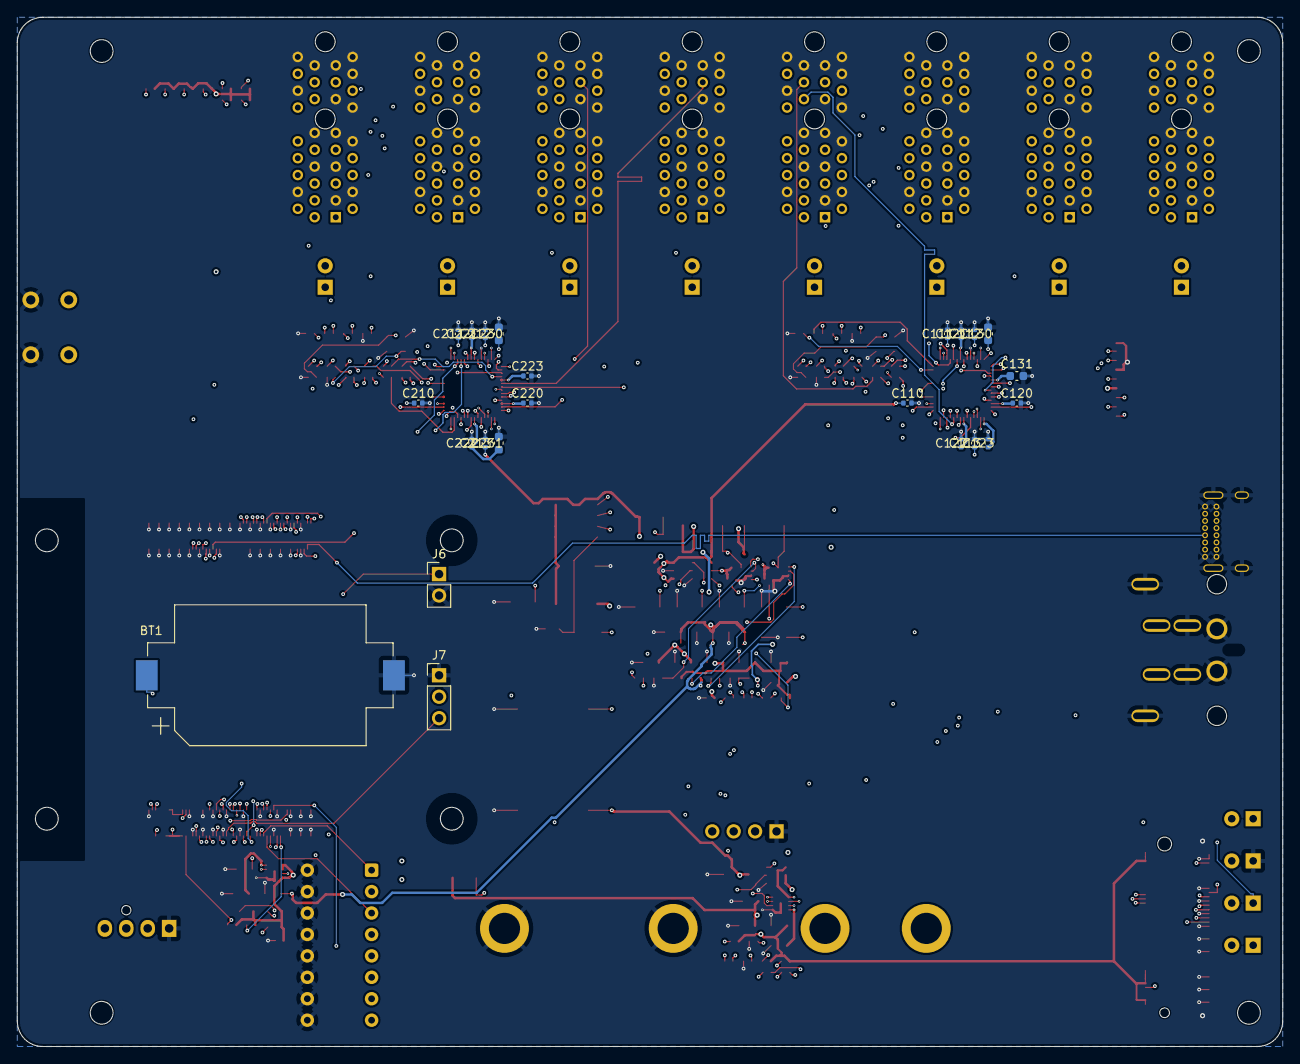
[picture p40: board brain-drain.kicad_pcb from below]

Board: 6 copper layers, 150.0 x 122.0 mm, 167 parts (23 on the bottom side), 192 nets.

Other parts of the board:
H1, H2, H3, H4: M2.5; MountingHole_2.7mm_M2.5

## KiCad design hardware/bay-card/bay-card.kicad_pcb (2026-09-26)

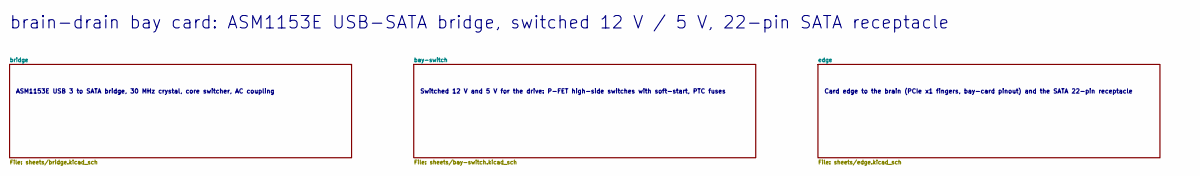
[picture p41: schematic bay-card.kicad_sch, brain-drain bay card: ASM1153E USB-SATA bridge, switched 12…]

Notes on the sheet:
brain-drain bay card: ASM1153E USB-SATA bridge, switched 12 V / 5 V, 22-pin SATA receptacle
ASM1153E USB 3 to SATA bridge, 30 MHz crystal, core switcher, AC coupling
Switched 12 V and 5 V for the drive: P-FET high-side switches with soft-start, PTC fuses
Card edge to the brain (PCIe x1 fingers, bay-card pinout) and the SATA 22-pin receptacle

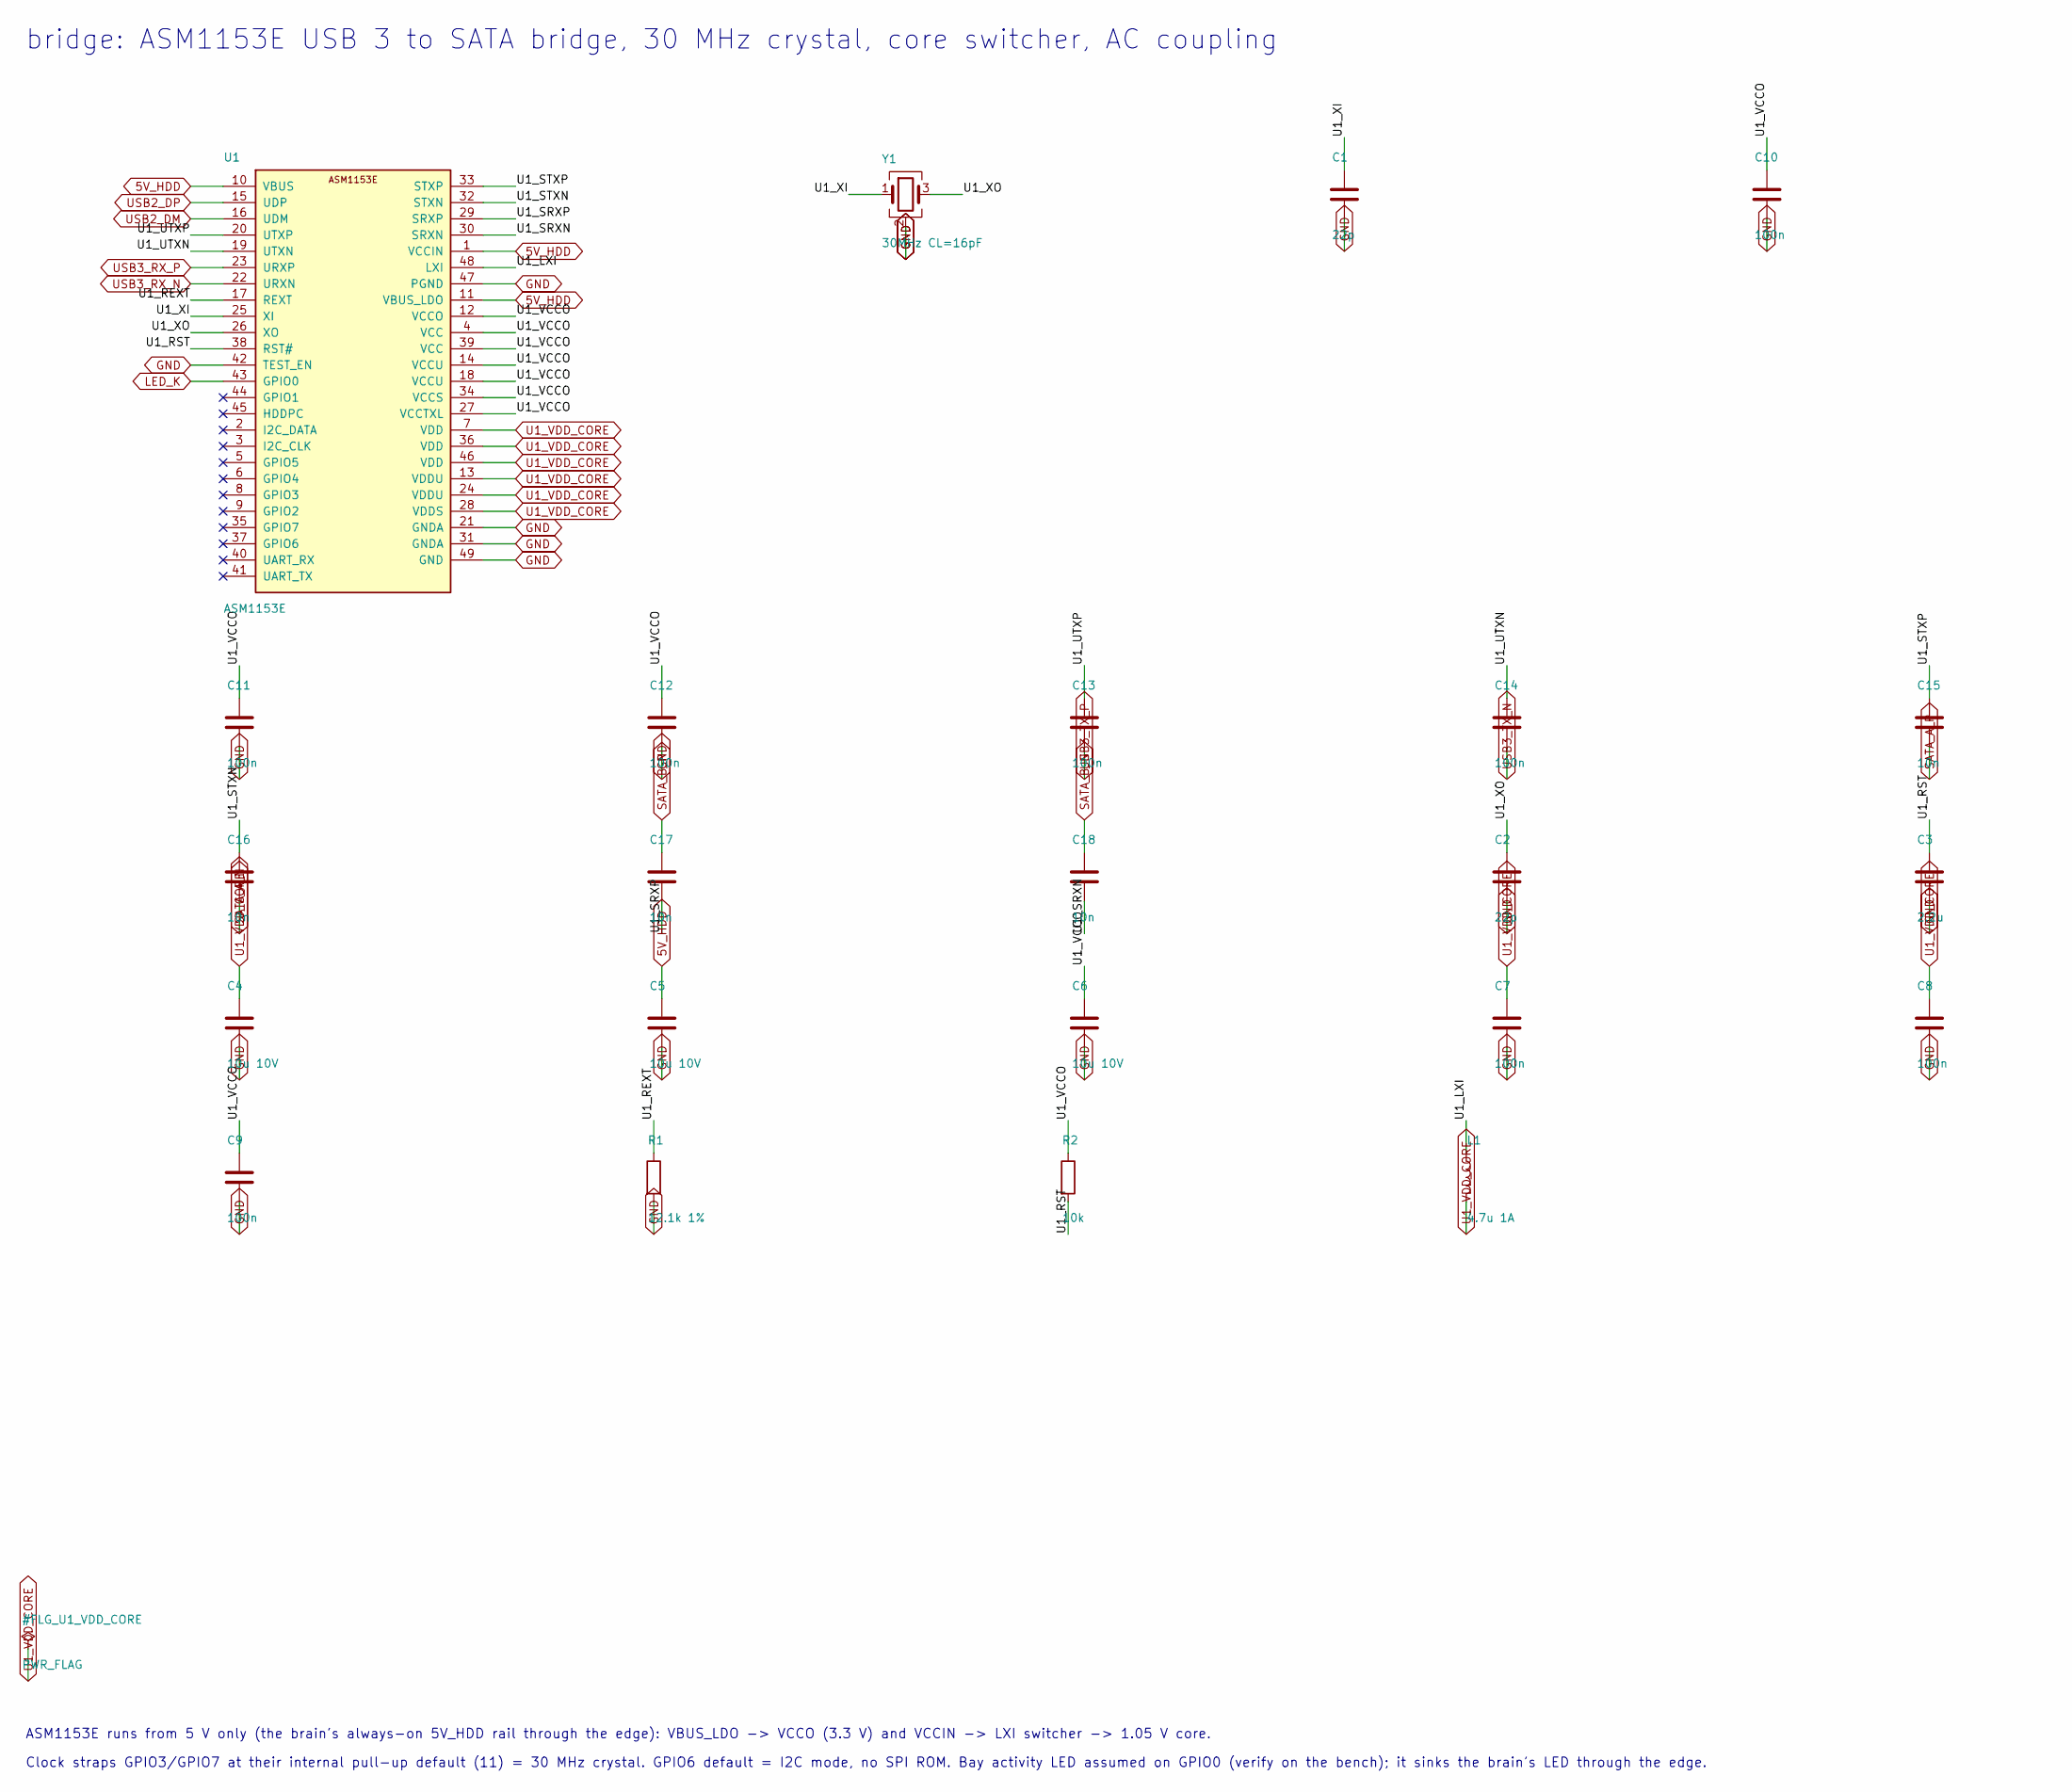
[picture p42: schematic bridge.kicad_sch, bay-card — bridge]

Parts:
C1, C2: 22p; C_0402_1005Metric
C3: 2.2u; C_0603_1608Metric
C4, C5, C6: 10u 10V; C_0805_2012Metric
C7, C8, C9, C10, C11, C12, C13, C14: 100n; C_0402_1005Metric
C15, C16, C17, C18: 10n; C_0402_1005Metric
L1: 4.7u 1A; L_Taiyo-Yuden_NR-40xx
R1: 12.1k 1%; R_0402_1005Metric
R2: 10k; R_0402_1005Metric
U1: ASM1153E; QFN-48-1EP_6x6mm_P0.4mm_EP4.6x4.6mm
Y1: 30MHz CL=16pF; Crystal_SMD_3225-4Pin_3.2x2.5mm

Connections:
5V_HDD: C5.1, U1.1 (VCCIN), U1.10 (VBUS), U1.11 (VBUS_LDO); also elsewhere on the board
GND: C1.2, C2.2, C3.2, C4.2, C5.2, C6.2, C7.2, C8.2, C9.2, C10.2, C11.2, C12.2, R1.2, U1.21 (GNDA), U1.31 (GNDA), U1.42 (TEST_EN), U1.47 (PGND), U1.49 (GND), Y1.2 (G), Y1.4 (G); also elsewhere on the board
LED_K: U1.43 (GPIO0); also elsewhere on the board
SATA_A_N: C16.2; also elsewhere on the board
SATA_A_P: C15.2; also elsewhere on the board
SATA_B_N: C18.1; also elsewhere on the board
SATA_B_P: C17.1; also elsewhere on the board
U1_LXI: L1.1, U1.48 (LXI)
U1_REXT: R1.1, U1.17 (REXT)
U1_RST: C3.1, R2.2, U1.38 (RST#)
U1_SRXN: C18.2, U1.30 (SRXN)
U1_SRXP: C17.2, U1.29 (SRXP)
U1_STXN: C16.1, U1.32 (STXN)
U1_STXP: C15.1, U1.33 (STXP)
U1_UTXN: C14.1, U1.19 (UTXN)
U1_UTXP: C13.1, U1.20 (UTXP)
U1_VCCO: C6.1, C9.1, C10.1, C11.1, C12.1, R2.1, U1.4 (VCC), U1.12 (VCCO), U1.14 (VCCU), U1.18 (VCCU), U1.27 (VCCTXL), U1.34 (VCCS), U1.39 (VCC)
U1_VDD_CORE: C4.1, C7.1, C8.1, L1.2, U1.7 (VDD), U1.13 (VDDU), U1.24 (VDDU), U1.28 (VDDS), U1.36 (VDD), U1.46 (VDD)
U1_XI: C1.1, U1.25 (XI), Y1.1
U1_XO: C2.1, U1.26 (XO), Y1.3
USB2_DM: U1.16 (UDM); also elsewhere on the board
USB2_DP: U1.15 (UDP); also elsewhere on the board
USB3_RX_N: U1.22 (URXN); also elsewhere on the board
USB3_RX_P: U1.23 (URXP); also elsewhere on the board
USB3_TX_N: C14.2; also elsewhere on the board
USB3_TX_P: C13.2; also elsewhere on the board

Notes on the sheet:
bridge: ASM1153E USB 3 to SATA bridge, 30 MHz crystal, core switcher, AC coupling
ASM1153E runs from 5 V only (the brain's always-on 5V_HDD rail through the edge): VBUS_LDO -> VCCO (3.3 V) and VCCIN -> LXI switcher -> 1.05 V core.
Clock straps GPIO3/GPIO7 at their internal pull-up default (11) = 30 MHz crystal. GPIO6 default = I2C mode, no SPI ROM. Bay activity LED assumed on GPIO0 (verify on the bench); it sinks the brain's LED through the edge.


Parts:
C19, C20: 100n; C_0402_1005Metric
F1: 3A hold 1812; Fuse_1812_4532Metric
F2: 2A hold 1812; Fuse_1812_4532Metric
Q1, Q2: AON7403; DFN-8-1EP_3x3mm_P0.65mm_EP1.5x2.25mm
Q3, Q4: 2N7002; SOT-23
R3, R5: 100k; R_0402_1005Metric
R4, R6, R7: 10k; R_0402_1005Metric
R8: 1k; R_0402_1005Metric

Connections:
5V_BAY: F2.2; also elsewhere on the board
5V_BAY_SW: F2.1, Q2.5 (D), Q2.6 (D), Q2.7 (D), Q2.8 (D), Q2.9 (D)
5V_HDD: C20.1, Q2.1 (S), Q2.2 (S), Q2.3 (S), R5.1; also elsewhere on the board
12V_BAY: F1.2; also elsewhere on the board
12V_BAY_SW: F1.1, Q1.5 (D), Q1.6 (D), Q1.7 (D), Q1.8 (D), Q1.9 (D)
+12V: C19.1, Q1.1 (S), Q1.2 (S), Q1.3 (S), R3.1; also elsewhere on the board
BAY_EN: R7.1, R8.1; also elsewhere on the board
EN_G: Q3.1 (G), Q4.1 (G), R8.2
GND: Q3.2 (S), Q4.2 (S), R7.2; also elsewhere on the board
Q1_G: C19.2, Q1.4 (G), R3.2, R4.1
Q2_G: C20.2, Q2.4 (G), R5.2, R6.1
Q3_D: Q3.3 (D), R4.2
Q4_D: Q4.3 (D), R6.2

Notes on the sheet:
bay-switch: Switched 12 V and 5 V for the drive: P-FET high-side switches with soft-start, PTC fuses
P-FET high-side switch: 100k gate pull-up holds it off; the 2N7002 pulls the gate down through 10k with 100n gate-source, ~1 ms ramp so the drive's bulk caps do not trip the fuse. BAY_EN pull-down keeps the bay off through boot.

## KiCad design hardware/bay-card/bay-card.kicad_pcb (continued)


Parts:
J1: bay card edge; BUS_PCIexpress_x1
J2: SATA 22-pin; SATA_22pin_Receptacle_RA

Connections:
5V_BAY: J2.P7 (5V), J2.P8 (5V), J2.P9 (5V); also elsewhere on the board
5V_HDD: J1.A8 (5V), J1.A9 (5V), J1.B8 (5V), J1.B9 (5V), J1.B10 (5V); also elsewhere on the board
12V_BAY: J2.P13 (12V), J2.P14 (12V), J2.P15 (12V); also elsewhere on the board
+12V: J1.A1 (12V), J1.A2 (12V), J1.B1 (12V), J1.B2 (12V), J1.B3 (12V); also elsewhere on the board
BAY_EN: J1.B5 (BAY_EN); also elsewhere on the board
GND: J1.A3 (GND), J1.A4 (GND), J1.A7 (GND), J1.A10 (GND), J1.A11 (GND), J1.A12 (GND), J1.A13 (GND), J1.A16 (GND), J1.A17 (GND), J1.A18 (GND), J1.B4 (GND), J1.B7 (GND), J1.B11 (GND), J1.B14 (GND), J1.B17 (GND), J1.B18 (GND), J2.P4 (GND), J2.P5 (GND), J2.P6 (GND), J2.P10 (GND), J2.P12 (GND), J2.S1 (GND), J2.S4 (GND), J2.S7 (GND); also elsewhere on the board
LED_K: J1.B6 (LED_K); also elsewhere on the board
SATA_A_N: J2.S3 (A-); also elsewhere on the board
SATA_A_P: J2.S2 (A+); also elsewhere on the board
SATA_B_N: J2.S5 (B-); also elsewhere on the board
SATA_B_P: J2.S6 (B+); also elsewhere on the board
USB2_DM: J1.B12 (USB2_DM); also elsewhere on the board
USB2_DP: J1.B13 (USB2_DP); also elsewhere on the board
USB3_RX_N: J1.B15 (USB3_RX_N); also elsewhere on the board
USB3_RX_P: J1.B16 (USB3_RX_P); also elsewhere on the board
USB3_TX_N: J1.A14 (USB3_TX_N); also elsewhere on the board
USB3_TX_P: J1.A15 (USB3_TX_P); also elsewhere on the board

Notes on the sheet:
edge: Card edge to the brain (PCIe x1 fingers, bay-card pinout) and the SATA 22-pin receptacle
Fingers: Connector_PCBEdge:BUS_PCIexpress_x1 on the card's bottom edge (chamfer the edge, ENIG is fine for a few insertions). Pinout in symgen.SLOT_PINS.
SATA P1-P3 (3.3 V) are not connected on purpose: P3 is PWDIS on SATA 3.3 drives and a 3.3 V supply there keeps them from spinning up.


Board: 4 copper layers, 45.0 x 46.0 mm, 39 parts (0 on the bottom side), 37 nets.

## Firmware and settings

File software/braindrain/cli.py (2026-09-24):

"""braindrain command line.

  braindrain simulate [--sim-dir D] [--grace S] [--display term|log|none]
  braindrain sim-plug BAY --size 256M [--media hdd|ssd|nvme] [--fw crypto,block] [--throttle 20M]
  braindrain sim-unplug BAY
  braindrain sim-door open|closed  M.2 bay lid (the slot powers only while it is shut)
  braindrain sim-pedet pcie|sata   M.2 PEDET pin; a SATA module is refused
  braindrain dip 00000000          decode a DIP setting
  braindrain list                  real enumeration + safety-fence verdicts (needs pyudev)
  braindrain run [--config F]      the appliance service (real or headless HAL per the config)
  braindrain status [--config F]   last display frame and bay states
  braindrain config-init [--headless] [--config F]   write a starting config file
  braindrain setup-bay BAY /dev/sdX [--config F]     map the dock behind /dev/sdX to a bay
  braindrain bench /dev/sdX        USB-SATA bridge passthrough tests (see bench.py)
"""

from __future__ import annotations

import argparse
import logging
import signal
import sys
from pathlib import Path

from . import __version__
from .config import DEFAULT_CONFIG_PATH, Config
from .policy import Dip, Policy

DEFAULT_SIM_DIR = Path.home() / ".brain-drain-sim"


def _unit_line(cfg):
    import socket
    import time

    def f():
        return f"{cfg.unit_id[:10]} {time.strftime('%H:%M')} {socket.gethostname()[:20]}"

    return f


def cmd_simulate(a) -> int:
    from .engine import Engine
    from .hal import make_hal
    from .hal.sim import SimDisplay
    from .sim.bays import SimWatcher

    sim_dir = Path(a.sim_dir)
    sim_dir.mkdir(parents=True, exist_ok=True)
    dip = sim_dir / "dip"
    if not dip.exists():
        dip.write_text("00000000\n")
    for name, default in (("door", "closed"), ("pedet", "pcie")):
        if not (sim_dir / name).exists():
            (sim_dir / name).write_text(default + "\n")
    cfg = Config.for_simulation(sim_dir, grace_seconds=a.grace, block_size=a.block_size, web_port=a.web)
    panel, power, _ = make_hal(cfg)
    disp = SimDisplay(a.display, sim_dir)
    watcher = SimWatcher(cfg)
    wifi = _wifi(cfg)
    eng = Engine(cfg, watcher, panel, power, disp, _unit_line(cfg), wifi)
    watcher.visible = eng.m2_visible
    web = _web(cfg, eng, wifi)
    signal.signal(signal.SIGINT, lambda *_: eng.stop.set())
    signal.signal(signal.SIGTERM, lambda *_: eng.stop.set())
    logging.getLogger().info("simulating in %s; plug drives with `braindrain sim-plug`", sim_dir)
    try:
        eng.run_forever()
    finally:
        if web:
            web.stop()
    return 0


def _wifi(cfg):
    """WifiManager for this config: simulated when sim_dir is set, nmcli on the Pi, None when headless
    or when nmcli is missing."""
    from .wifi import NmcliBackend, SimBackend, WifiManager

    if cfg.sim_dir is not None:
        return WifiManager(cfg, SimBackend(cfg.sim_dir))
    if cfg.hal == "headless":
        return None
    try:
        return WifiManager(cfg, NmcliBackend())
    except RuntimeError as e:
        logging.getLogger().warning("wireless disabled: %s", e)
        return None


def _web(cfg, eng, wifi):
    if not cfg.web_enabled:
        return None
    from .webui import WebUI

    try:
        web = WebUI(cfg, eng, wifi)
    except OSError as e:
        logging.getLogger().error("phone page not started: %s", e)
        return None
    web.start()
    return web


def cmd_wifi_reset(a) -> int:
    cfg = Config.load(a.config)
    wifi = _wifi(cfg)
    if wifi is None:
        print("no wireless on this unit", file=sys.stderr)
        return 2
    if a.factory:
        r = wifi.factory_reset(wait=True)
        print(f"factory reset: {r['certificates_deleted']} certificate(s) deleted; access point {wifi.state.ssid} key {wifi.state.key}")
    else:
        wifi.reset_wifi(wait=True)
        print(f"network forgotten; access point {wifi.state.ssid} key {wifi.state.key}")
    return 0


def cmd_sim_plug(a) -> int:
    from .sim.bays import parse_size, plug

    fw = None
    if a.fw:
        fw = {k.strip(): True for k in a.fw.split(",") if k.strip()}
        fw["seconds"] = a.fw_seconds
    thr = parse_size(a.throttle) if a.throttle else None
    img = plug(Path(a.sim_dir), a.bay, parse_size(a.size), media=a.media, model=a.model,
               serial=a.serial, firmware=fw, throttle_bps=thr, prefill=a.prefill)
    print(f"plugged {a.media} {a.size} into bay {a.bay}: {img}")
    return 0


def cmd_sim_unplug(a) -> int:
    from .sim.bays import unplug

    unplug(Path(a.sim_dir), a.bay)
    print(f"unplugged bay {a.bay}")
    return 0


def cmd_sim_door(a) -> int:
    (Path(a.sim_dir) / "door").write_text(a.state + "\n")
    print(f"M.2 bay lid {a.state}")
    return 0


def cmd_sim_pedet(a) -> int:
    (Path(a.sim_dir) / "pedet").write_text(a.kind + "\n")
    print(f"M.2 PEDET = {a.kind}")
    return 0


def cmd_dip(a) -> int:
    p = Policy.from_dip(Dip.from_string(a.bits))
    print(f"mode={p.mode.name} pattern={'random' if p.random_pattern else 'zeros'} "
          f"verify={'sampled' if p.sampled_verify else 'full'} maintenance={p.maintenance}")
    return 0


def cmd_list(a) -> int:
    from .devices import collect_real

    cfg = Config.load(a.config)
    rows = collect_real(cfg)
    for info, bay, reason in rows:
        tag = f"BAY {bay}" if bay else "skip "
        print(f"{tag:6} {info.dev_path:14} {info.size_bytes / 1e9:8.1f} GB  usb={info.usb_port or '-':8} "
              f"bridge={info.bridge_vid or '-'}:{info.bridge_pid or '-'}  {reason}")
    if not rows:
        print("no block disks found")
    return 0


def cmd_bench(a) -> int:
    from .bench import Bench, confirm_destructive

    b = Bench(a.device, destructive=a.destructive, sanitize=a.sanitize, io_bytes=a.io_mib << 20)
    if a.destructive:
        b.bridge()
        b.identify()
        if not b.ident:
            return 1
        if not a.yes and not confirm_destructive(b.ident["serial"], b.ident["model"]):
            print("aborted")
            return 1
        b.report.checks.clear()
    rep = b.run_all()
    path = b.save(Path(a.out_dir))
    fails = [c.name for c in rep.checks if c.ok is False]
    passes = len([c for c in rep.checks if c.ok])
    print(f"\n{rep.bridge_name} ({rep.bridge_id}) with {rep.drive.get('model')}: "
          f"{passes} pass, {len(fails)} fail -> {path}")
    return 1 if fails else 0


def cmd_config_init(a) -> int:
    cfg = Config()
    cfg.display_file = Path("/var/lib/brain-drain/display.txt")
    if a.headless:
        cfg.hal = "headless"
        cfg.m2_bay = None
        cfg.bay_ports = {}
    path = cfg.save(a.config)
    print(f"wrote {path} (hal={cfg.hal}); edit bay_ports / allowed_bridges or use `braindrain setup-bay`")
    return 0


def cmd_setup_bay(a) -> int:
    from .devices import describe_device

    cfg = Config.load(a.config)
    info = describe_device(a.device)
    if info is None:
        print(f"{a.device}: not found")
        return 1
    if info.usb_port is None:
        print(f"{a.device}: not behind a USB port (internal disk?) - refusing")
        return 1
    if info.is_system:
        print(f"{a.device}: holds a mounted filesystem, root or swap - refusing")
        return 1
    cfg.bay_ports[a.bay] = info.usb_port
    bridge = (info.bridge_vid, info.bridge_pid)
    if bridge not in cfg.allowed_bridges:
        cfg.allowed_bridges = frozenset(cfg.allowed_bridges | {bridge})
        print(f"added bridge {info.bridge_vid}:{info.bridge_pid} to the allow-list")
    cfg.save(a.config)
    print(f"bay {a.bay} = USB port {info.usb_port} ({info.bridge_vid}:{info.bridge_pid}) -> {a.config}")
    print("note: the mapping is by USB *port*; any drive plugged into that dock is now a wipe target")
    return 0


def cmd_status(a) -> int:
    cfg = Config.load(a.config)
    if cfg.display_file and Path(cfg.display_file).exists():
        print(Path(cfg.display_file).read_text(), end="")
    else:
        print("no display file yet (is the service running?)")
    st = Path(cfg.state_file)
    if st.exists():
        print("state:", st.read_text().strip()[:400])
    return 0


def cmd_run(a) -> int:
    from .engine import Engine
    from .hal import make_hal
    from .sim.udev import UdevWatcher

    cfg = Config.load(a.config)
    if cfg.hal == "real" and not cfg.bay_ports:
        print("config has no bay_ports; run `braindrain setup-bay` first", file=sys.stderr)
        return 2
    panel, power, disp = make_hal(cfg)
    wifi = _wifi(cfg)
    eng = Engine(cfg, UdevWatcher(cfg), panel, power, disp, _unit_line(cfg), wifi)
    web = _web(cfg, eng, wifi)
    signal.signal(signal.SIGTERM, lambda *_: eng.stop.set())
    signal.signal(signal.SIGINT, lambda *_: eng.stop.set())
    try:
        eng.run_forever()
    finally:
        if web:
            web.stop()
    return 0


def main(argv=None) -> int:
    ap = argparse.ArgumentParser(prog="braindrain", description=__doc__,
                                 formatter_class=argparse.RawDescriptionHelpFormatter)
    ap.add_argument("--version", action="version", version=__version__)
    ap.add_argument("-v", "--verbose", action="store_true")
    sub = ap.add_subparsers(dest="cmd", required=True)

    s = sub.add_parser("simulate", help="run the engine against simulated bays")
    s.add_argument("--sim-dir", default=str(DEFAULT_SIM_DIR))
    s.add_argument("--grace", type=float, default=5.0)
    s.add_argument("--block-size", type=int, default=8 * 1024 * 1024)
    s.add_argument("--display", choices=["term", "log", "none"], default="term")
    s.set_defaults(fn=cmd_simulate)

    s.add_argument("--web", type=int, default=8080, help="phone page port (default 8080; 0 = pick a free port)")
    s = sub.add_parser("sim-plug", help="plug a simulated drive into a bay")
    s.add_argument("bay", type=int)
    s.add_argument("--sim-dir", default=str(DEFAULT_SIM_DIR))
    s.add_argument("--size", default="256M")
    s.add_argument("--media", choices=["hdd", "ssd", "nvme"], default="hdd")
    s.add_argument("--model")
    s.add_argument("--serial")
    s.add_argument("--fw", help="simulated firmware sanitize kinds, e.g. crypto,block")
    s.add_argument("--fw-seconds", type=float, default=3.0)
    s.add_argument("--throttle", help="cap overwrite rate, e.g. 20M (bytes/s)")
    s.add_argument("--prefill", action="store_true", help="fill with random data first")
    s.set_defaults(fn=cmd_sim_plug)

    s = sub.add_parser("sim-unplug", help="unplug a simulated drive")
    s.add_argument("bay", type=int)
    s.add_argument("--sim-dir", default=str(DEFAULT_SIM_DIR))
    s.set_defaults(fn=cmd_sim_unplug)

    s = sub.add_parser("sim-door", help="open or close the simulated M.2 bay lid")
    s.add_argument("state", choices=["open", "closed"])
    s.add_argument("--sim-dir", default=str(DEFAULT_SIM_DIR))
    s.set_defaults(fn=cmd_sim_door)

    s = sub.add_parser("sim-pedet", help="simulate the M.2 PEDET pin: pcie (normal) or sata (refused)")
    s.add_argument("kind", choices=["pcie", "sata"])
    s.add_argument("--sim-dir", default=str(DEFAULT_SIM_DIR))
    s.set_defaults(fn=cmd_sim_pedet)

    s = sub.add_parser("dip", help="decode a DIP switch setting")
    s.add_argument("bits")
    s.set_defaults(fn=cmd_dip)

    s = sub.add_parser("list", help="enumerate real disks and show fence verdicts")
    s.add_argument("--config", default=str(DEFAULT_CONFIG_PATH))
    s.set_defaults(fn=cmd_list)

    s = sub.add_parser("status", help="show the last display frame and state")
    s.add_argument("--config", default=str(DEFAULT_CONFIG_PATH))
    s.set_defaults(fn=cmd_status)

    s = sub.add_parser("config-init", help="write a starting config file")
    s.add_argument("--config", default=str(DEFAULT_CONFIG_PATH))
    s.add_argument("--headless", action="store_true", help="Pi + USB docks, no carrier board")
    s.set_defaults(fn=cmd_config_init)

    s = sub.add_parser("setup-bay", help="map the USB dock behind a block device to a bay number")
    s.add_argument("bay", type=int)
    s.add_argument("device", help="/dev/sdX currently attached through the dock")
    s.add_argument("--config", default=str(DEFAULT_CONFIG_PATH))
    s.set_defaults(fn=cmd_setup_bay)

    s = sub.add_parser("bench", help="test ATA passthrough through a USB-SATA bridge")
    s.add_argument("device", help="/dev/sdX of the drive behind the bridge")
    s.add_argument("--destructive", action="store_true", help="also run write test and SECURITY ERASE")
    s.add_argument("--sanitize", action="store_true", help="also run SANITIZE (hours on an HDD)")
    s.add_argument("--yes", action="store_true", help="skip the serial-number confirmation")
    s.add_argument("--io-mib", type=int, default=1024, help="MiB for read/write speed tests")
    s.add_argument("--out-dir", default=".", help="where to write bench-*.json")
    s.set_defaults(fn=cmd_bench)

    s = sub.add_parser("wifi-reset", help="forget the saved network and go back to the access point")
    s.add_argument("--factory", action="store_true", help="also delete all certificates and state")
    s.add_argument("--config", default=None)
    s.set_defaults(fn=cmd_wifi_reset)
    s = sub.add_parser("run", help="run the appliance service on real hardware")
    s.add_argument("--config", default=str(DEFAULT_CONFIG_PATH))
    s.set_defaults(fn=cmd_run)

    a = ap.parse_args(argv)
    logging.basicConfig(
        level=logging.DEBUG if a.verbose else logging.INFO,
        format="%(asctime)s %(levelname)-7s %(name)s: %(message)s",
        stream=sys.stderr,
    )
    return a.fn(a)


if __name__ == "__main__":
    raise SystemExit(main())

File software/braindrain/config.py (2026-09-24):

"""Runtime configuration.

Everything hardware-specific (GPIO numbers, bay to USB port-path mapping, bridge
USB IDs) lives here as data so the same engine runs on the appliance, on a
workstation with a USB dock, or fully simulated.
"""

from __future__ import annotations

import json
import os
import socket
from dataclasses import dataclass, field, fields
from pathlib import Path

DEFAULT_CONFIG_PATH = Path("/etc/brain-drain/config.json")

# USB port paths, as they appear in sysfs (the leaf of the device path, e.g. "1-1.2"),
# for each bay. PLACEHOLDERS: fill in from the real board once it exists
# (`braindrain list` prints every candidate with its port path).
# Eight bay slots (C24): hub A's four downstream ports are bays 1-4, hub B's are bays 5-8. Only the
# slots that hold a card enumerate; an empty slot is simply never seen.
DEFAULT_BAY_PORTS: dict[int, str] = {1: "1-1.1", 2: "1-1.2", 3: "1-1.3", 4: "1-1.4", 5: "2-1.1", 6: "2-1.2", 7: "2-1.3", 8: "2-1.4"}

# USB bridge VID:PID allow-list. Only drives behind one of these bridges, on a bay
# port path, are ever candidates for wiping.
DEFAULT_ALLOWED_BRIDGES: frozenset[tuple[str, str]] = frozenset(
    {
        ("174c", "55aa"),  # ASMedia ASM1153E / ASM1051E / ASM1351 family (verify on bench)
        ("174c", "1153"),  # ASMedia ASM1153 (verify on bench)
    }
)

# BCM GPIO numbers, ARCHITECTURE.md §3.7.
DEFAULT_DIP_GPIOS: tuple[int, ...] = (16, 17, 20, 21, 22, 23, 24, 25)
DEFAULT_BAY_EN_GPIOS: dict[int, int] = {1: 5, 2: 6, 3: 12, 4: 13, 5: 7, 6: 8, 7: 9, 8: 10}
DEFAULT_STATUS_LED_GPIO = 26

MiB = 1024 * 1024
GiB = 1024 * MiB


@dataclass
class Config:
    bay_ports: dict[int, str] = field(default_factory=lambda: dict(DEFAULT_BAY_PORTS))
    allowed_bridges: frozenset[tuple[str, str]] = DEFAULT_ALLOWED_BRIDGES
    report_dir: Path = Path("/var/lib/brain-drain/reports")
    state_file: Path = Path("/var/lib/brain-drain/state.json")
    unit_id: str = field(default_factory=socket.gethostname)

    # Timing
    grace_seconds: float = 5.0  # countdown between detection and first write
    stagger_seconds: float = 4.0  # between bay power-ups at boot
    reinsert_guard_seconds: float = 30.0  # same serial reappearing in a DONE bay
    poll_interval: float = 0.5  # simulated watcher / firmware status polling
    display_hz: float = 1.0
    firmware_poll_seconds: float = 5.0

    # I/O
    block_size: int = 8 * MiB
    direct_io: bool = True  # O_DIRECT when the target supports it; falls back otherwise

    # Verification
    verify_sample_windows: int = 64
    verify_sample_window_bytes: int = 16 * MiB
    verify_edge_bytes: int = 1 * GiB  # clamped to size/8 for small targets
    canary_count: int = 8

    # GPIO (real HAL only)
    gpiochip: str = "/dev/gpiochip0"
    dip_gpios: tuple[int, ...] = DEFAULT_DIP_GPIOS
    bay_en_gpios: dict[int, int] = field(default_factory=lambda: dict(DEFAULT_BAY_EN_GPIOS))
    status_led_gpio: int = DEFAULT_STATUS_LED_GPIO
    oled_driver: str = "ssd1306"  # or "sh1106"
    i2c_port: int = 1
    oled_address: int = 0x3C

    # Bay 9: M.2 NVMe slot on the CM5 PCIe lane (ARCHITECTURE.md §3.3, decision C15; bays 1-8 are the slots, C24)
    m2_bay: int | None = 9
    m2_door_gpio: int = 4       # microswitch, closed = low
    m2_pedet_gpio: int = 19     # M.2 pin 69, pulled up; a SATA module grounds it
    m2_power_gpio: int = 27     # TPS22965 enable for 3V3_M2
    m2_settle_seconds: float = 1.0   # power-on to PCIe rescan
    m2_appear_seconds: float = 10.0  # rescan to block device, else power off and retry on next door cycle
    pci_rescan_path: Path = Path("/sys/bus/pci/rescan")

    # HAL selection: "real" (carrier board), "headless" (Pi + USB docks, no panel/OLED/bay power),
    # or simulation when sim_dir is set.
    hal: str = "real"
    headless_dip: str = "00000000"   # policy used by the headless HAL, which has no switches
    display_file: Path | None = None  # last OLED frame as text, for `braindrain status`

    # Wireless and the phone page (C22). The AP key is ephemeral (per boot) and lives only in memory.
    wifi_iface: str = "wlan0"
    wifi_file: Path = Path("/var/lib/brain-drain/wifi.json")   # saved station network, if any
    wifi_join_timeout: float = 45.0
    ap_ip: str = "10.42.0.1"
    web_enabled: bool = True
    web_port: int = 80

    # Simulation
    sim_dir: Path | None = None

    @property
    def bays(self) -> list[int]:
        bays = sorted(self.bay_ports)
        if self.m2_bay is not None:
            bays.append(self.m2_bay)
        return bays

    @property
    def usb_bays(self) -> list[int]:
        return sorted(self.bay_ports)

    @classmethod
    def for_simulation(cls, sim_dir: Path, **overrides) -> Config:
        sim_dir = Path(sim_dir)
        cfg = cls(
            report_dir=sim_dir / "reports",
            state_file=sim_dir / "state.json",
            sim_dir=sim_dir,
            unit_id=overrides.pop("unit_id", "sim-" + socket.gethostname()),
            stagger_seconds=0.0,
        )
        for k, v in overrides.items():
            if not hasattr(cfg, k):
                raise AttributeError(k)
            setattr(cfg, k, v)
        return cfg


    # ------------------------------------------------------------------ file I/O
    _PATH_FIELDS = ("report_dir", "state_file", "pci_rescan_path", "sim_dir", "display_file", "wifi_file")

    @classmethod
    def load(cls, path: Path | str | None = None) -> Config:
        """Config from a JSON file; keys are field names. Missing file -> defaults."""
        path = Path(path or DEFAULT_CONFIG_PATH)
        cfg = cls()
        if not path.exists():
            return cfg
        data = json.loads(path.read_text())
        cfg.apply(data)
        return cfg

    def apply(self, data: dict) -> Config:
        names = {f.name for f in fields(self)}
        for k, v in data.items():
            if k not in names:
                raise KeyError(f"unknown config key {k!r}")
            if k == "bay_ports":
                v = {int(b): str(p) for b, p in v.items()}
            elif k == "bay_en_gpios":
                v = {int(b): int(g) for b, g in v.items()}
            elif k == "allowed_bridges":
                v = frozenset((str(a).lower(), str(b).lower()) for a, b in v)
            elif k == "dip_gpios":
                v = tuple(int(x) for x in v)
            elif k in self._PATH_FIELDS and v is not None:
                v = Path(v)
            setattr(self, k, v)
        return self

    def to_dict(self) -> dict:
        out = {}
        for f in fields(self):
            v = getattr(self, f.name)
            if isinstance(v, Path):
                v = str(v)
            elif isinstance(v, frozenset):
                v = sorted(list(x) for x in v)
            elif isinstance(v, tuple):
                v = list(v)
            elif isinstance(v, dict):
                v = {str(k): val for k, val in v.items()}
            out[f.name] = v
        return out
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

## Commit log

2026-09-22 Scaffold brain-drain: architecture, BOM, decisions, workstream stubs
    Three workstreams: CM4 carrier board (KiCad), braindrain Python sanitizer
    service, OpenSCAD enclosure. Architecture doc flags that the CM4 has no
    native USB 3 and recommends a VL805 xHCI on PCIe feeding the four ASM1153E
    bridges directly, with the requested VL817 kept as an alternate topology.
    [brain-drain-bom.csv, params.scad]
2026-09-22 BOM: correct compute module prices to 2026 list, add CM4/CM5 table and D9
    [brain-drain-bom.csv]
2026-09-22 Switch design to Compute Module 5: 2x VL817 on native USB 3, drop PCIe xHCI
    Closes D1/D4/D6/D9 (now C7-C9), adds D10 optional M.2 NVMe bay on the free
    PCIe Gen3 x1 lane. Four HDD bays now run at native drive speed.
    [brain-drain-bom.csv]
2026-09-22 Fix two leftover CM4 references
    [brain-drain-bom.csv]
2026-09-22 UX: no Start button; wipe starts on drive insertion, unplug aborts (C10)
    [brain-drain-bom.csv, params.scad]
2026-09-22 software: braindrain service, simulation mode, 45 tests
    Engine with per-bay state machine (insert -> grace -> wipe -> verify -> done,
    unplug aborts), DIP policy decoding, NIST 800-88 method chains, safety fence,
    O_DIRECT overwrite with full/sampled verify, canary verification for firmware
    wipes, hdparm/nvme-cli wrappers (untested on hardware), JSON certificates,
    crash-state recovery, 21x8 OLED renderer, simulated bays/panel/display, CLI.
    [base.py, blockio.py, cli.py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]
2026-09-22 software: finish lint fixes and DONE line
    [display.py]
2026-09-22 hardware: CM5 pinout reference extracted from the official datasheet
    [cm5-pinout.csv]
2026-09-22 hardware: complete CM5 pinout CSV (all 200 pins)
    [cm5-pinout.csv]
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2026-09-22 Close decisions C11-C15: USB5744 hubs, ASM1153E, DIN input, 3 mm LEDs, M.2 bay populated
    [brain-drain-bom.csv]
2026-09-22 hardware: USB5744 and ASM1153E pin tables as CSV
    [asm1153e-pinout.csv, usb5744-pinout.csv]
2026-09-22 hardware: symbol generator and project library from datasheet pin tables
    CM5 as two DF40 connector symbols with functional units, USB5744, ASM1153E,
    TPS56637, TPS22965, SATA 22-pin, M.2 M-key, 4-pin DIN. Validated with
    kicad-cli sym export.
    [m2-mkey-pinout.csv]
2026-09-22 hardware: generated KiCad 9 schematic (14 sheets) and connection list from one netlist
    tools/design.py is the single source of truth; gen_sch.py emits label-based
    sheets, project file and library tables and runs ERC (0 errors, 17 warnings:
    8 custom footprints not yet drawn, 9 symbol cache notes); gen_connections.py
    emits CONNECTIONS.md for drawing by hand.
    [bay-switch-1.kicad_sch, bay-switch-2.kicad_sch, bay-switch-3.kicad_sch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]
2026-09-22 BOM: sync with the generated schematic
    [brain-drain-bom.csv]
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2026-09-22 decisions C17-C19: Molex 47018-4001, TE 2199230-4, 180x110 outline A
    [bay-switch-1.kicad_sch, bay-switch-2.kicad_sch, bay-switch-3.kicad_sch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]
2026-09-22 hardware: gen_pcb.py builds the 180x110 board with all footprints placed and netted; deterministic UUIDs
    [bay-switch-1.kicad_sch, bay-switch-2.kicad_sch, bay-switch-3.kicad_sch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]
2026-09-22 hardware: CM5 on the official 204-pad footprint, CM5IO M.2 footprint, reference-design fixes
    From the Raspberry Pi CM5IO rev 2 KiCad files: single CM5 footprint with both
    connectors and mounting holes; M.2 socket footprint; USB-C CC pins to the CM5;
    fan PWM pull-up; microSD through a load switch on SD_PWR_ON; M.2 shield and
    standoff pads to GND; PCIe polarity note. Board regenerated with the module
    and M.2 at their real sizes; centre mounting hole dropped.
    [brain-drain.kicad_pcb, brain-drain.kicad_sch, cm5.kicad_sch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]
2026-09-22 hardware: board placement pass (M.2 inserts from the right wall, UI front-left, bridge regions resized)
    [brain-drain.kicad_pcb]
2026-09-22 hardware: front-strip placement nudge
    [brain-drain.kicad_pcb]
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2026-09-22 enclosure: OpenSCAD tray/lid/door from the board file (kicad_to_scad.py, params, shell, Makefile)
    [board.scad, params.scad, shell.scad]
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2026-09-22 docs: README with logo and renders, docs index, STATUS, USAGE, HISTORY, testing tracker, AGENT.md, changelog; enclosure refinements and renders; routing pipeline
    [brain-drain.dsn, brain-drain.kicad_pcb, params.scad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]
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2026-09-22 hw(board): DRC-clean placement (pad rotation fix, packer with capacity checks, USB-C on the left wall, DIN pad fix)
    [board.scad, brain-drain.dsn, brain-drain.kicad_pcb]
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2026-09-22 hw(routing): autorouted signal nets imported (freerouting), CM5 hole keep-outs, hand-routing list; renders and status updated
    [brain-drain.kicad_pcb]
2026-09-22 design: portable brain box (C21) — board re-laid out at 150x98, cabled bays, enclosure v1, renders
    - gen_pcb.py: new outline, walls (SATA rear; DIN/RJ45/USB-C left; microSD + M.2 slot front),
    CM5 landscape, M.2 vertical along the right edge, CR2032/buzzer on the bottom side
    (pcbnew flip post-process); check_place.py courtyard/outline checker; render_board.sh
    - route.py: zones follow the new layout (polygon zones), origin/size from gen_pcb
    - enclosure: closed box, drive rack removed, front-wall M.2 slot door, right-wall vents,
    buzzer floor holes, OLED window over the M.2 column; scene with four loose drives on cables;
    stl_preview camera fixed and triangles subdivided
    - docs: C21 + D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
    [board.scad, brain-drain.dsn, brain-drain.kicad_pcb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]
2026-09-22 design v2: wireless brain box (C22-C23) — no Ethernet, no buzzer, passive cooler, hinged lid, Wi-Fi AP + QR + phone page, fabrication guide
    hardware: 136x100 outline, CM5 wireless antenna edge on the left board edge with a copper-free
    strip (rule area), DIN/USB-C/microSD on the right wall, M.2 along the front under the lid, lid
    microswitch, CR2032 + service headers on the bottom; magjack and buzzer removed from the
    netlist; check_place clean, DRC 0 errors; schematic + connections regenerated, render script
    also exports the schematic
    software: wifi.py (nmcli / simulated backends, ephemeral key, join, resets), webui.py (stdlib
    HTTP phone page: status, certificates, log, join, reset), qr.py,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
    [board.scad, brain-drain-bom.csv, brain-drain.kicad_pcb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]
2026-09-22 hw(routing): v2 board autorouted — 75/75 signal nets, fanout and net-class fixes
    - route.py: net classes written to brain-drain.kicad_pro (gen_sch.py preserves them); prepare keeps
    existing zones (deleting filled zones with fanout vias corrupts the pcbnew bindings); fanout checks
    the plane polygon instead of its bbox; import strips keep-out crossings; run_freerouting uses the
    lite DSN with -oit 2
    - routed board: 930 segments / 4.4 m, 214 vias; DRC 1 known starved-thermal note, 0 clearance errors;
    499 open connections are planes, rails, bays and pairs for the hand pass
    - render_board.sh: board PNGs cropped to the outline, schematic PDF + sheet PNGs
    - docs: STATUS R16 closed, R4 deta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
    [brain-drain.dsn, brain-drain.kicad_pcb]
2026-09-22 hw(routing): CM5IO design rules, exposed-pad vias, staged router runs, fab export and open-connection report
    - route.py: net classes now 0.13/0.125 mm with 0.45/0.2 vias (Power 0.5 mm, 0.6/0.3) and the
    project's minimum rules set to match; stage2/stage3 commands lock existing routes ((type fix))
    and route the remaining single-ended nets, then the pairs; fanout_big puts vias inside QFN
    exposed pads (dog-bones kept behind a flag: too many collisions at 0.4 mm pitch); pair_report
    - tools/export_fab.sh: gerbers + drill zip, placement, BOM, assembly PDFs into fab/<date>/
    - tools/open_report.py: open connections by group/net/part -> routing/open.md
    - docs: rules in ARCHITECTURE, hardware REA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
    [brain-drain.dsn, brain-drain.kicad_pcb]
2026-09-23 hw(routing): re-placed bay rows, CM5IO rules, three-pass fanout, stage 1 routed on the new layout
    - gen_pcb.py: per bay the switch block sits behind the receptacle's power pads and the bridge QFN
    behind its data pads (bay power no longer crosses the bridge); check_place clean
    - route.py: fanout_conn (row-fitted vias for CM5/M.2/SATA plane pins, adjacent same-net pins bridged),
    prepare no longer re-applies classes through the API when the project has them (zone filler
    bad_alloc), Power class 0.3 mm / all clearances 0.125, stage1 command
    - stage 1 imported: 1044 segments, 339 vias, 0 clearance errors; stage 2 running
    - docs: STATUS R16/R21, placement text; freerouting 2.2.4/2.3.0 jars fe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
    [brain-drain.dsn, brain-drain.kicad_pcb]
2026-09-23 hw(routing): staged autoroute complete as far as the tools go — 81 % of connections, DRC copper-clean
    - board: 3175 segments (9.0 m), 658 vias; all signal nets, most plane pins; 165 connections open
    (75 plane pins in dense spots, 25 bay/rail links, 65 pair ends); 9 of 48 pairs routed, none matched
    - route.py: staged runs with locked routes, -inc class ignoring (dropping nets with wiring breaks the
    DSN), BD_ROUTER/BD_PASSES for freerouting 2.4.1 on Java 25 (bounded), drc-clean, Occupancy
    geometry checks, orientation-correct pad sizes, exposed-pad ties, DRC-driven open pads, pair_report
    - reports: routing/open.md, routing/pairs.md; docs: STATUS R4/R16/R21/R22, D7 (how to finish),
    USA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
    [brain-drain.dsn, brain-drain.kicad_pcb]
2026-09-23 hw(v3): 150x112 placement for the router (D7 option B) — hubs under the CM5 USB 3 pins, M.2 front-right, 2.5 mm around every QFN; enclosure regenerated; stage 1 routed
    - gen_pcb.py: v3 regions and anchors; route.py: v3 zones; three fanout passes place 353 vias with no
    connector plane pin left; stage 1: all signal nets, DRC 1 thermal note
    - enclosure: board.scad, STLs and renders for the larger box (about 157 x 119 x 32 mm)
    - docs: sizes and placement text, D7 recorded as chosen
    [board-after-stage1.kicad_pcb, board.scad, brain-drain.dsn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]
2026-09-23 hw(v3): staged autoroute on the 150x112 board — 83 % of connections, 21 of 48 pairs, DRC copper-clean
    - stage 2 rerun after stripping the QFN via rings (the connector fanout now skips QFNs), stage 3 on
    freerouting 2.4.1, drc-clean, final fanouts: 3300 segments, 738 vias, 151 connections open
    - docs: STATUS board row / R4 / R22, D7 outcome and D8 (0.3/0.15 mm vias for the QFN supply pins),
    CHANGELOG, tracker, README, FABRICATION gate 1; board renders
    [board-after-stage1.kicad_pcb, brain-drain.dsn, brain-drain.kicad_pcb]
2026-09-23 hw(routing): D8 applied — 0.3/0.15 mm dog-bone vias on the QFN pins (fanout_qfn), unattended routing chain; D9 brief on bay cards / 8 ports
    - route.py: fanout_qfn (two staggered via lines, all multi-pin non-pair nets), min via 0.3/0.15 and hole
    clearance 0.2 in the project rules; tools/route_chain.sh runs stage 2, stage 3, cleanup, fanouts,
    reports and renders unattended
    - fresh v3 board with all four fanouts: 441 vias before routing, DRC clean; stage 1 routed in 2 minutes
    - docs: decisions/2026-09-23-bay-cards.md (D9), DECISIONS D8/D9
    [board-v3-83pct.kicad_pcb, brain-drain.dsn, brain-drain.kicad_pcb]
2026-09-24 docs: C24 brain + bay cards — decisions, architecture, BOM card table, fabrication, README, USAGE, STATUS, changelog, history; diagrams: 8 slots, lid plan, left wall
    [bay-card-lite.dsn, bay-card.dsn, bay-card.kicad_pcb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]
2026-09-24 hw(routing): card-edge finger fanout (in-line vias shared by the A/B fingers, edge-aware collision check), DFN pins in fanout_qfn with rip-up of simple blocking nets, project-aware render script; car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
    [bay-card-lite.dsn, bay-card.dsn, bay-card.kicad_pcb]
2026-09-24 hw: 8-pin P-FET symbols (S 1-3, G 4, D 5-8 + EP) for Q20 / Q1 / Q2 — the generic 3-pin symbol had put G/S/D on three source pads; route.py update-nets re-syncs pad nets on a routed board; gen_sch kee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
    [bay-card-lite.dsn, bay-card.dsn, bay-card.kicad_pcb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]
2026-09-24 hw(card): routed to 6 open connections, DRC 0 errors — pre-routing fanout with rip-up in the chain, fanout-qfn-rip command, STATUS, P-FET docs
    [bay-card-lite.dsn, bay-card.dsn, bay-card.kicad_pcb]
2026-09-24 design: bay-card FET is the AOS AON7403 (C25); BOM, STATUS, downloads, decisions
    [bay-switch.kicad_sch]
2026-09-24 hw(brain): first full chain — 49 open (31 plane pins, 18 pair ends) before the Q20 pin fix; Q20 re-netted, chain relaunched
    [brain-drain.dsn, brain-drain.kicad_pcb]
2026-09-24 hw(brain): full chain after the Q20 fix — 43 open (25 plane pins, 18 pair ends), DRC 0 copper errors; STATUS
    [brain-drain.dsn, brain-drain.kicad_pcb]
2026-09-24 hw(routing): pair length tuner (route.py tune) — meanders on the shorter side, layer-aware checks; card 5/8 and brain 34/44 pairs matched, DRC unchanged; in the chain
    [bay-card.kicad_pcb, brain-drain.kicad_pcb]
2026-09-24 hw(card): pairs rerouted by rip + stage 3, tuner; reroute_pairs.sh; 7 open, 6 of 8 pairs routed and matched
    [bay-card-lite.dsn, bay-card.dsn, bay-card.kicad_pcb]
2026-09-24 hw(card): pairs-first routing (stage0) — all 8 pairs routed and matched, 3 open; route_full.sh, BD_PAIRS_FIRST
    [bay-card-lite.dsn, bay-card.dsn, bay-card.kicad_pcb]
2026-09-24 hw(routing): close-gaps — grid A* router for the open connections the autorouter leaves; card down to 1 open (QFN pin 17 escape), DRC 0 errors
    [bay-card.kicad_pcb]
2026-09-24 hw(routing): brain 9 open (was 43), DRC 0 copper errors, 41/44 pairs matched — pairs-first flow, close-gaps with per-route DRC check, pcbfix (duplicate pad UUIDs), sliver widening; renders, docs
    [brain-drain.dsn, brain-drain.kicad_pcb]
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2026-09-24 hw(brain): bottom-side hub bypass caps (20), 10 open (plane pins 25 -> 1; pair ends now the leftovers); gap closer with rip-up (BD_RIPUP), weighted A*
    [brain-drain.dsn, brain-drain.kicad_pcb]
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2026-09-25 hw(brain): six-layer routing — 2 open (U21 FB pin, one In4 island note), DRC 0 errors, 44/44 pairs routed, 43 matched; STATUS, CHANGELOG
    [brain-drain.dsn, brain-drain.kicad_pcb]
2026-09-25 hw(tools): close-gaps split into single-ended and pair passes (separate processes), BD_ONLY filter; U21_FB rip-up trial rejected and reverted
    [gapclose.py, route.py]
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2026-09-25 hw: real Amphenol slot and Molex receptacle footprints, 45 mm bay card (C27, option A), enclosure rear extension and new lid windows; card 0 open, brain 5 open, DRC 0 errors
    [bay-card-lite.dsn, bay-card.dsn, bay-card.kicad_pcb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]
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2026-09-25 hw(brain): pairs-adjacent placement run — 3 open (PCIE_CLK_N gap, two zone notes), DRC 0 errors, 43/44 pairs matched
    [brain-drain.dsn, brain-drain.kicad_pcb]
2026-09-25 hw(brain): no open signal connections, 44/44 pairs matched, DRC 0 errors; gap router precision options; STATUS/CHANGELOG
    [brain-drain.dsn, brain-drain.kicad_pcb]
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2026-09-25 hw(tools): end-to-end pair matching across the series caps, pair fixer that tries several strategies and keeps the best, +12V channel zone
    [route.py]
2026-09-25 hw: brain 0 open, 0 DRC errors, 44/44 pairs end-to-end matched; card 0 open; +12V strip and channel on In4; renders, STATUS, CHANGELOG
    [bay-card.kicad_pcb, brain-drain.dsn, brain-drain.kicad_pcb]
2026-09-25 docs+hw: re-render all boards, electronics, case and full unit; engineer hand-off guide, review pack, generated BOM, renders doc; lint cleanup
    [bay-card-bom.csv, bay-card.kicad_pcb, bay-switch-1.kicad_sch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]
2026-09-26 enclosure+hw: bay-card comb and overhang supports, lid and board branding, fix lid features mirrored front to back
    Comb ribs under the lid between receptacle housings, grooved blocks under the card overhang (check_fit.py),
    logo and name engraved in the lid, logo/name/URL silkscreen on the brain board, name on the card (branding.py).
    Lid windows, OLED, DIP, LEDs and grille were modelled at the wrong end of the lid; corrected and all renders regenerated.
    [bay-card.kicad_pcb, brain-drain.kicad_pcb, logo.scad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]
2026-09-26 hw: board revision on the silkscreen and title block; silkscreen renders; lid-plan label fixes
    [bay-card.kicad_pcb, brain-drain.kicad_pcb]
2026-09-26 hw: simplified, larger silkscreen logo; eight-bay wording; card label
    [bay-card.kicad_pcb, brain-drain.kicad_pcb]
2026-09-26 hw: input fuse F1 15 A slow-blow (C31); BOM, netlist and docs updated
    [brain-drain-bom.csv, brain-drain.kicad_pcb, power-input.kicad_sch]
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
